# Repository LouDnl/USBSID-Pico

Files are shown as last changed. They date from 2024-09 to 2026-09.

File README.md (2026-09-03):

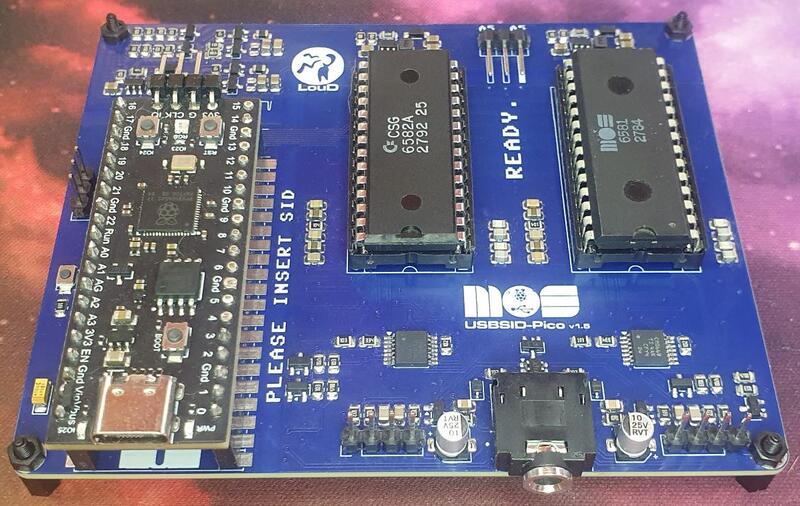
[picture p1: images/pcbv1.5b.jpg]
<br>
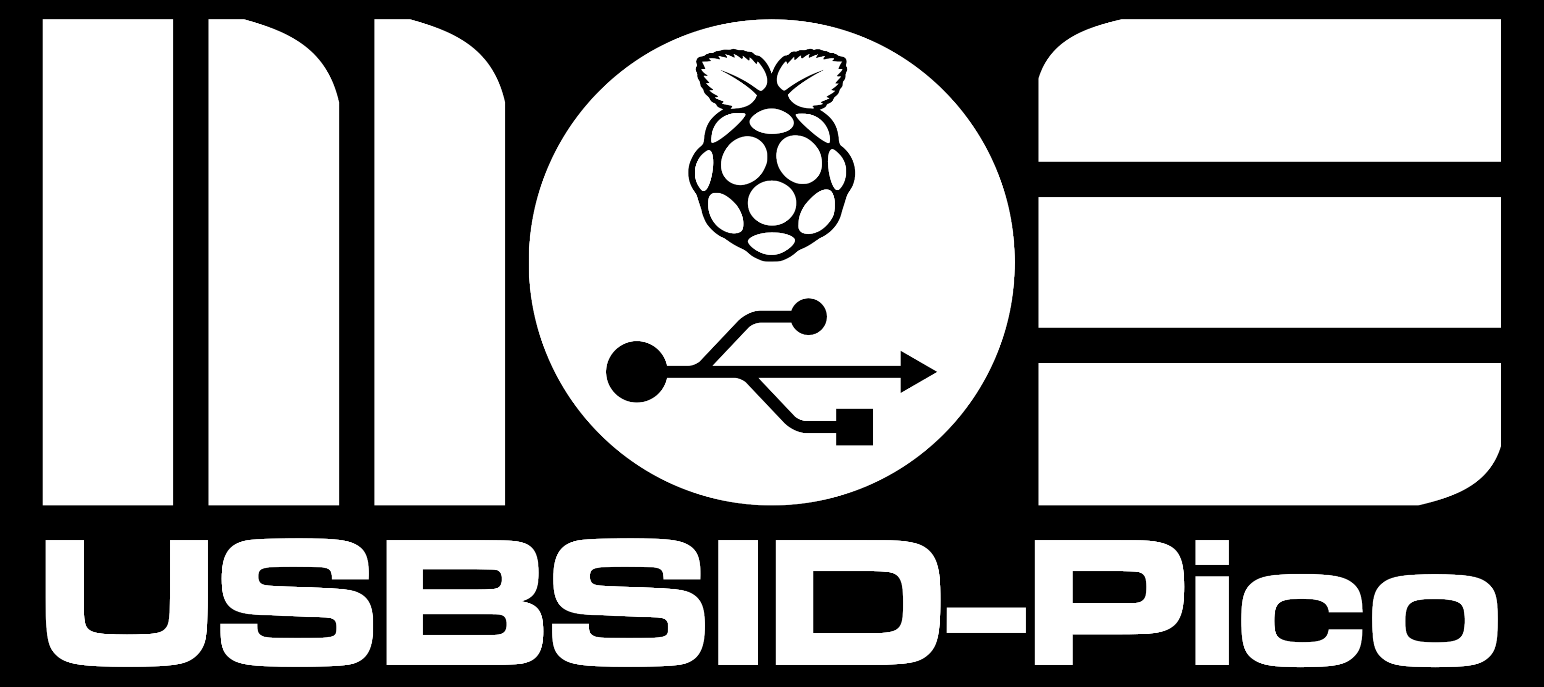
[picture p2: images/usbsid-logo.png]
# [](images/usbsid-logo.png)LouD
USBSID-Pico is a RaspberryPi Pico/PicoW (RP2040) & Pico2/Pico2W (RP2350) based board for interfacing one or two MOS SID chips and/or hardware SID emulators over (WEB)USB with your computer, phone, ASID supporting player or USB midi controller.  

# This is USBSID-Pico! :)
| **“Raster Bar” (8-bit)** | **Van Halen's Jump<br>dual SID in Stereo!** | **Next Level** | **Outerversal<br>dual SID in Stereo!** |
|:-:|:-:|:-:|:-:|
| [](https://www.youtube.com/watch?v=nh0SxO1y6I0)<br><small><sub>by LukHash</sub></small> | [](https://www.youtube.com/watch?v=lzvkWlDq2TM)<br><small><sub>by Nordischsound</sub></small> | [](https://www.youtube.com/watch?v=ER8v2g7TlwA)<br><small><sub>by Performers</sub> | [](https://www.youtube.com/watch?v=h2ThT3TWZEw)<br><small><sub>by Abyxus</sub></small> |

| **Wonderland XI** | **Wonderland XII** | **Wonderland XIII** | **Wonderland XIV** |
|:-:|:-:|:-:|:-:|
| [](https://www.youtube.com/watch?v=7hiAkLAqsiI)<br><small><sub>by Censor Design</sub></small> | [](https://www.youtube.com/watch?v=4gckiwzOW9U)<br><small><sub>by Censor Design</sub></small> | [](https://www.youtube.com/watch?v=q4Fg7V2DYCI)<br><small><sub>by Censor Design</sub> | [](https://www.youtube.com/watch?v=RTtmsbH4jC0)<br><small><sub>by Censor Design</sub></small> |

# USBSID-Pro (Soon™)
In development is a modular USBSID-Pro featuring 4 SID sockets with 4 mono out ports, switchable audio channels into a single stereo out jack , Midi port, an onboard rp2350b and more. No release date has been planned yet!

# Index
* [This is USBSID-Pico! :)](#this-is-usbsid-pico-)
* [Swag!](#swag)
* [Software support & Features](#software-support-and-features)
  * [USBSID-Configtool](#usbsid-configtool)
  * [Software manual](doc/USBSID-Pico-software-manual.adoc) [PDF](doc/USBSID-Pico-software-manual.pdf)
  * [SID files](#sid-files)
    - [Webbased SID players](#webbased-sid-players)
    - [SID players](#sid-players)
    - [Amiga SID players](#amiga-sid-players)
  * [Commodore 64 emulators](#commodore-64-emulators)
  * [Chiptune trackers using SID's](#chiptune-trackers-using-sids)
  * [Driver code](#driver-code)
  * [Midi](#midi)
  * [Cynthcart VST](#cynthcart-vst)
* [Questions & Support](#questions-and-support)
* [Known issues](#known-issues)
* [Project status](#project-status)
  * [Code status](#code-status)
  * [Supported platforms](#supported-platforms)
  * [Linux Udev rules](#linux-udev-rules)
  * [Windows driver](#windows-driver)
* [Firmware](#firmware)
  * [Configuring your board's firmware](#configuring-your-boards-firmware)
    * [Testing your board](#testing-your-board)
  * [Firmware features](#firmware-features)
    * [Embedded Cynthcart](doc/USBSID-Pico-Cynthcart-manual.adoc) [(PDF)](doc/USBSID-Pico-Cynthcart-manual.pdf)
    * [Embedded USBSID-Player](doc/USBSID-Player-manual.adoc) [(PDF)](doc/USBSID-Player-manual.pdf)
  * [Firmware types and naming](doc/USBSID-Pico-firmware-manual.adoc) [(PDF)](doc/USBSID-Pico-firmware-manual.pdf)
  * [How to flash new firmware](doc/USBSID-Pico-firmware-manual.adoc) [(PDF)](doc/USBSID-Pico-firmware-manual.pdf)
  * [How to configure your board](doc/USBSID-Pico-firmware-manual.adoc) [(PDF)](doc/USBSID-Pico-firmware-manual.pdf)
  * [Building](#building)
* [Hardware](#hardware)
  * [Volume board](#volume-board)
  * [Where to buy](#where-to-buy)
  * [PCB usage information](#pcb-usage-information)
    * [PCB revision v1.0 manual](#pcb-revision-v10-manual)
    * [PCB revision v1.3 manual](#pcb-revision-v13-manual)
  * [Cases](#cases)
  * [PCB Features](#pcb-features)
  * [Open source design files, schematic and BOM](#open-source-design-files-schematic-and-bom)
  * [PCB Development](#pcb-development)
* [Examples](#examples)
* [Acknowledgements](#acknowledgements)
* [Disclaimer](#disclaimer)
* [License](#license)
* [Certification](#certification)

# Swag!
Do you like swag!? I sure do!! [greyandslate](https://bsky.app/profile/greyandslate.bsky.social) created these great t-shirt designs which are available for purchase in his [Smallrun shop](https://smallrun.net/shop/grey-and-slate-haberdashers), link below.  
**Use coupon code USBSID15 for a 15% discount!**  
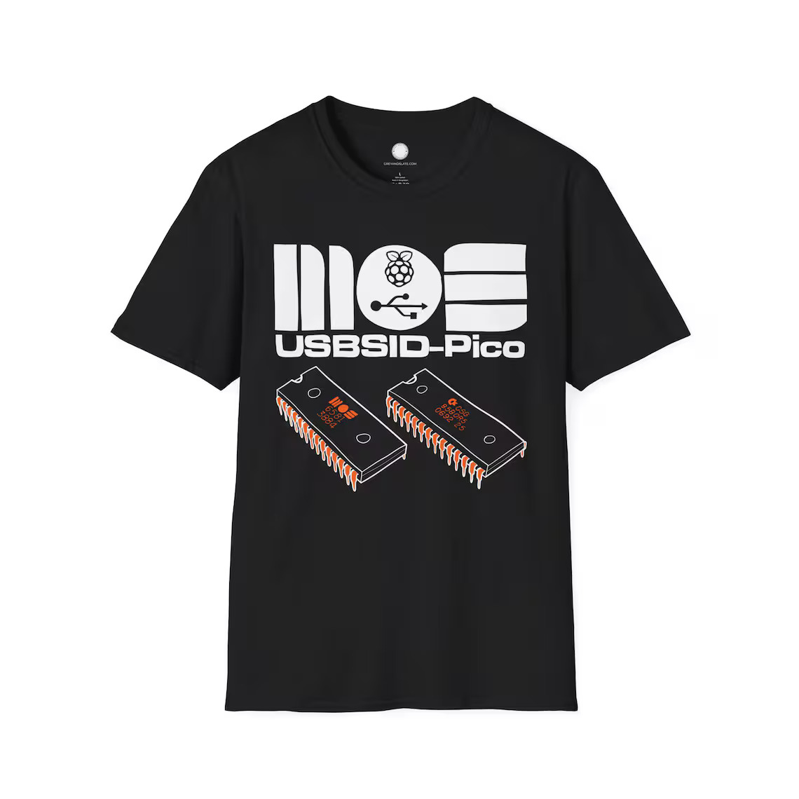
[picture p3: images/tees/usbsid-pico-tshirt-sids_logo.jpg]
  
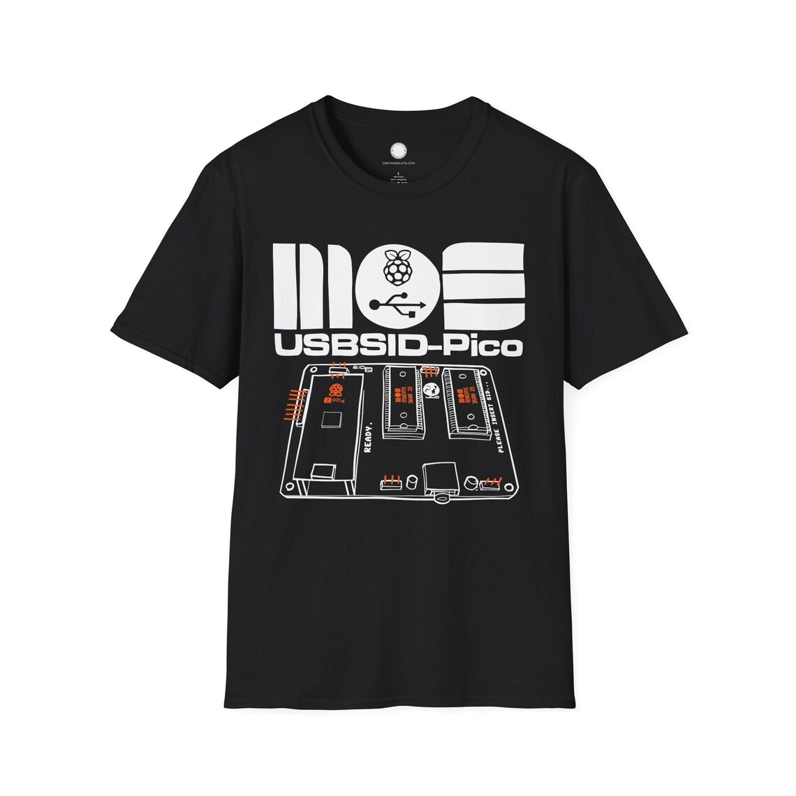
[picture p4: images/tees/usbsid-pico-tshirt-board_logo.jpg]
  
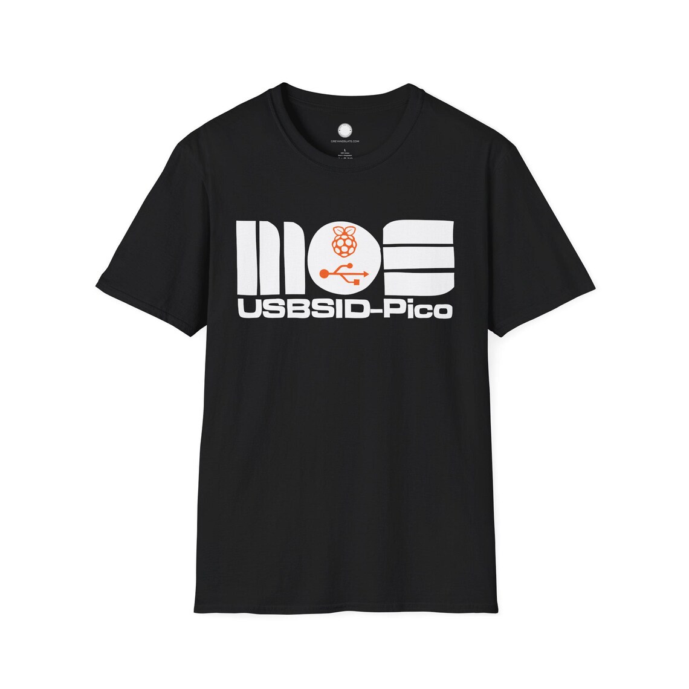
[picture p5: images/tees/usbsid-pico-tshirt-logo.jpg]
  
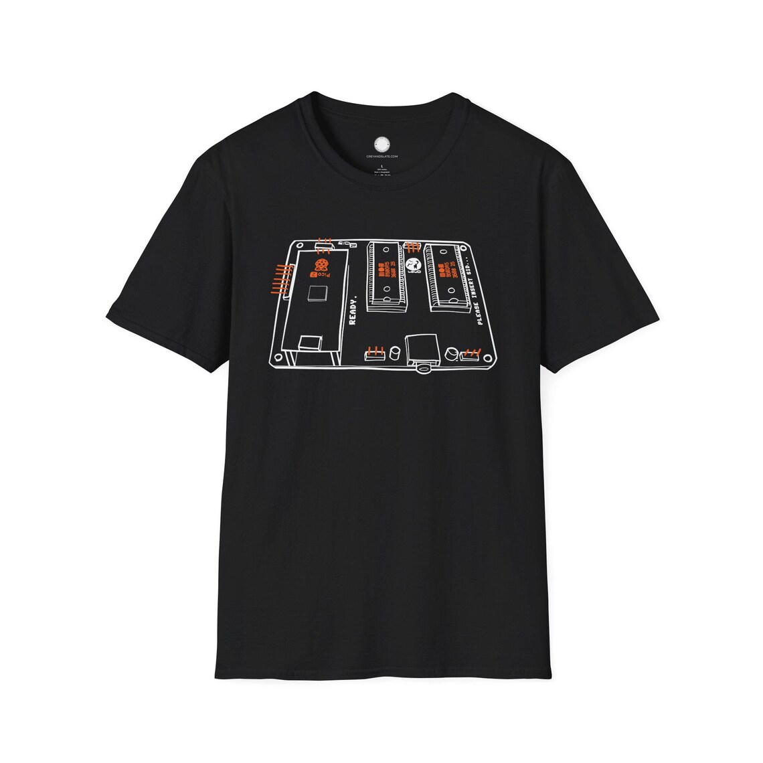
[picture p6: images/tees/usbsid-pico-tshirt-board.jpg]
  

# Software support and features
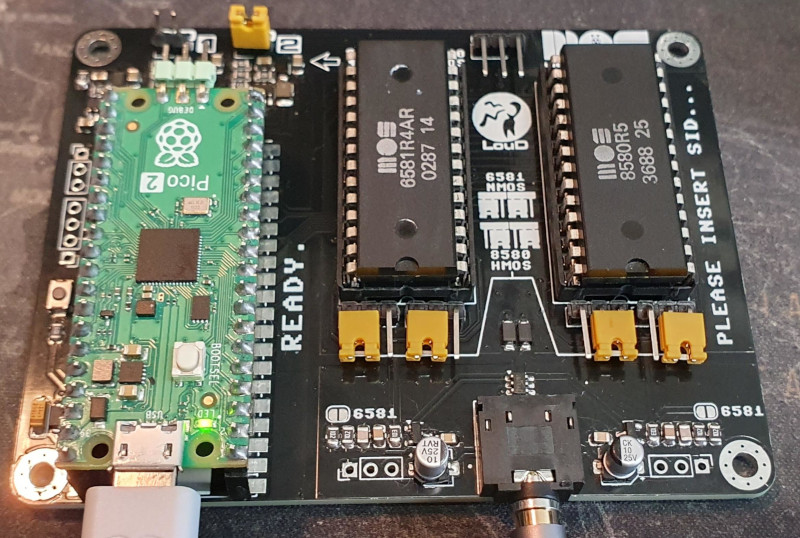
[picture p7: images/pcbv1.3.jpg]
  
See the [Software manual](doc/USBSID-Pico-software-manual.adoc) for more information on how to use supported software!  

## USBSID-Configtool
The [USBSID-Configtool](https://github.com/LouDnl/USBSID-Configtool) is a _must have_ tool to configure your board!  
Checkout the [Configtool manual](doc/USBSID-Configtool-manual.adoc) or [PDF](doc/USBSID-Configtool-manual.pdf)  
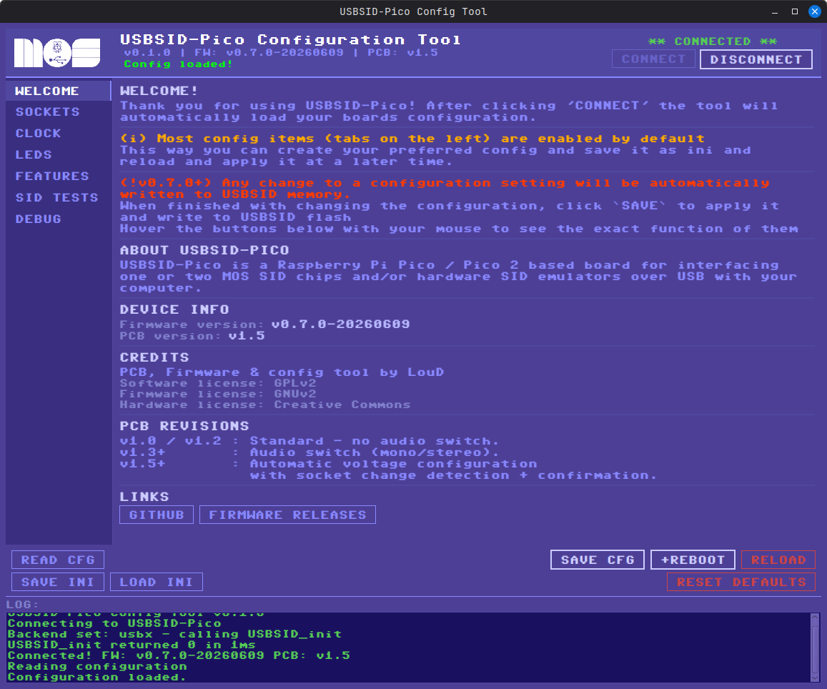
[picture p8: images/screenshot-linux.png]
[](https://github.com/LouDnl/USBSID-Configtool)  

## SID files
USBSID-Pico supports various ways of playing SID files.

#### Webbased SID players 
_Chrome webbrowser only_  
- Out-of-the box playing is supported by using [Deepsid by Chordian](https://deepsid.chordian.net)  
  by selecting `WebUSB (Hermit)` as player in the pulldown menu or  
  by selecting `ASID (MIDI)` as player in the pulldown menu.
- Out-of-the box playing is also supported by using [C64jukebox by Kenchis](https://haendel.ddns.net:8443/static/c64jukebox.vue), note that this is still in BETA.  

#### SID players
| Acid64 Pro | VSID(Vice) | (lib)sidplayfp | Phosphor |  
|:-:|:-:|:-:|:-:|
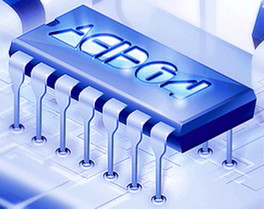
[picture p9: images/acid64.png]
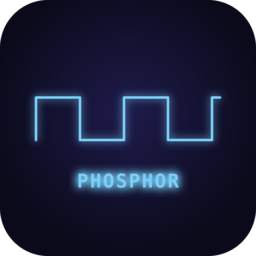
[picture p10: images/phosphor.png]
| [](https://acid64.com/) | [](https://sourceforge.net/projects/vice-emu/) | [](https://github.com/libsidplayfp/) | [](https://github.com/sandlbn/Phosphor) |  
| version [4.4.0](https://acid64.com/download)<br>(Windows only) | version [3.10.0](https://github.com/VICE-Team/svn-mirror/releases/tag/3.10.0) | player [2.16](https://github.com/libsidplayfp/libsidplayfp/releases/tag/v2.16.0rc)<br>lib [2.16](https://github.com/libsidplayfp/sidplayfp/releases/tag/v2.16.0rc) | [any version](https://github.com/sandlbn/Phosphor/releases) |  
| up to 3 SIDs | up to 3 SIDs | up to 3 SIDs | up to 4 SIDs |  

Other:
- [SidBerry](https://github.com/LouDnl/SidBerry) is a command line SID file player for Linux & Windows with up to 4 SIDs supported (Windows version is buggy).
- [TrueSID](https://csdb.dk/release/?id=259243) TrueSID is a Python based graphical SID player which utilizes JSIDPlay2 and / or SidplayFp to play SID tunes  

#### Amiga SID players
Real SID's on the Amiga? Why yes!
- [erique](https://github.com/erique) and [koobo](https://github.com/koobo) have added support to [playsid](https://github.com/erique/playsid.library)  

## Commodore 64 emulators
Official support has been added to:  
| Vice | JSIDPlay2 | Denise |
|:-:|:-:|:-:|
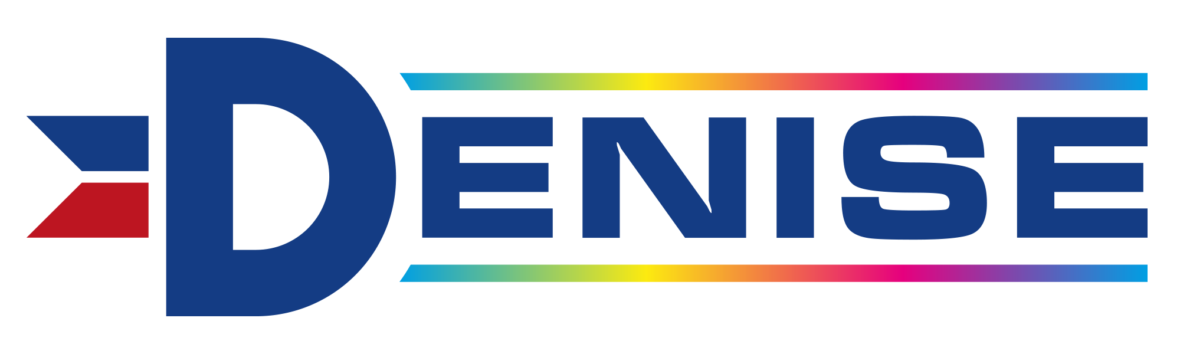
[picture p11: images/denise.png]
| [](https://sourceforge.net/projects/vice-emu/) | [](https://haendel.ddns.net/~ken/#_latest_beta_versions) | [](https://sourceforge.net/projects/deniseemu/) |  
| version [3.10.0](https://github.com/VICE-Team/svn-mirror/releases/tag/3.10.0) | version [4.13](https://sourceforge.net/projects/jsidplay2/files/jsidplay2/4.13/) | version [2.7](https://sourceforge.net/projects/deniseemu/) |  
| up to 4 SIDs in x64sc | up to 4 SIDs | up to 4 SIDs |  

Others:
- Unofficial support is added to a fork of [RetroDebugger](https://github.com/LouDnl/RetroDebugger), up to 4 SIDs are supported.

## Chiptune trackers using SID's
Into creating chiptunes? USBSID-Pico is your board!
- You should be able to use the ASID fork of [sidfactory2](https://github.com/Chordian/sidfactory2/tree/asid-support) without issues.  
- When using Vice or RetroDebugger you can freely use applications like [SID-Wizard](https://sourceforge.net/projects/sid-wizard/) for music creation.  
- There is also work being done in my forks of [GTUltra](https://github.com/LouDnl/GTUltra-USBSID) and [Goattracker2](https://github.com/LouDnl/goattracker2).  
  Ask on Discord for latest binaries :)

## Driver code
Want to create your own implementation? You can by using the driver code examples below
- [USBSID-Pico driver](https://github.com/LouDnl/USBSID-Pico-driver) repo is available @ https://github.com/LouDnl/USBSID-Pico-driver and contains `C++`, `Java` and `Javascript` implementation examples
  - [@sandlbn](https://github.com/sandlbn) has created a driver in `Rust` which is available here [USBSID-Pico-Rust-driver](https://github.com/sandlbn/USBSID-Pico-Rust-driver)
- [HardSID USB / SidBlaster USB](examples/hardsid-sidblaster) emulation driver example

## Midi
USBSID-Pico acts as Midi device and supports basic Midi in ~ note that Midi is still in development and in Beta phase.  
This means that no support is available here at this time, please visit the Discord for more information.

## Cynthcart VST
Raros has made a custom VST (Windows only) to use with the Cynthcart embedded firmware version.  
Checkout the [README.md](examples/Cynthcart-Ninja_VST/README.md) he made for more information!

# Questions and Support
Any questions about or support with USBSID-Pico can be asked 
* [Discord](https://discord.gg/zG2rxXuT2g)
* [Github discussions](https://github.com/LouDnl/USBSID-Pico/discussions)
* [USBSID manuals](doc/)

# Known issues
**PCB/Audio/etc**
* Possible audible low/high alternating hum when using a Pico1 or Pico2 board that has an RGB LED onboard.  
  - __Cause:__ Ground loop, when two or more interconnected pieces of audio equipment are plugged into different power outlets (with or without ground pins), creating multiple paths to the electrical ground.  
  - __Example:__ When powering the board from your computer and routing the audio out back into your computer.  
  - __Example:__ When powering the board from your computer and routing the audio out into speakers but both connected to different outlets.  
  - __Fix:__ Route the audio out through a ground loop isolator.  
  - __Fix:__ Connect audio out to headphones.  
  - __Note:__ Its more present on v1.0 and v1.3 board, but still there on v1.5 boards. To fix this on the board would require significant layout and pcb changes.  

**Firmware/Software**
* Switching on readmode and then switching it off again without restarting the PCB and Vice _will_ result in distorted audio  
* Highly demanding, cycle-exact SID tunes (dense per-cycle register writes, e.g. some digi/sample tunes) may not play at full speed on Pico1 or Pico1_w (RP2040) boards, due to the board's hardware limitations. Pico2 or Pico2_w (RP2350) is recommended for these tunes.  

# Project status
Visit the [Project Page](https://github.com/users/LouDnl/projects/1) for an up-to-date list of things being worked on.
While in development any mentioned features, options, etc. are subject to change.  

### Code status
| | Master | Dev |
| ---  | :----- | :----- |
| Release  | [][A] | [][B] |
| Build | [][C] | [][C] |
| Commit | [][D]  | [][E] |
| | **Other** |
| Latest | [][F] | [][G] |
| Open | [][H]  | [][I] |
| Info | [][J] | [][K] |

[1]: https://img.shields.io/github/v/release/LouDnl/USBSID-Pico
[2]: https://img.shields.io/github/v/tag/LouDnl/USBSID-Pico
[3]: https://img.shields.io/github/actions/workflow/status/LouDnl/USBSID-Pico/build.yml?branch=master
[4]: https://img.shields.io/github/actions/workflow/status/LouDnl/USBSID-Pico/build.yml?branch=dev
[5]: https://shields.io/github/last-commit/LouDnl/USBSID-Pico/master
[6]: https://shields.io/github/last-commit/LouDnl/USBSID-Pico/dev
[7]: https://shields.io/github/v/tag/LouDnl/USBSID-Pico?sort=semver
[8]: https://shields.io/github/v/release/LouDnl/USBSID-Pico
[9]: https://shields.io/github/issues/LouDnl/USBSID-Pico
[10]: https://shields.io/github/discussions/LouDnl/USBSID-Pico
[11]: https://shields.io/github/license/LouDnl/USBSID-Pico
[12]: https://shields.io/github/languages/top/LouDnl/USBSID-Pico
[A]: https://github.com/LouDnl/USBSID-Pico/actions/workflows/release.yml
[B]: https://github.com/LouDnl/USBSID-Pico/actions/workflows/tagged_build.yml
[C]: https://github.com/LouDnl/USBSID-Pico/actions/workflows/build.yml
[D]: https://github.com/LouDnl/USBSID-Pico/commits/master/
[E]: https://github.com/LouDnl/USBSID-Pico/commits/dev/
[F]: https://github.com/LouDnl/USBSID-Pico/tags
[G]: https://github.com/LouDnl/USBSID-Pico/releases
[H]: https://github.com/LouDnl/USBSID-Pico/issues
[I]: https://github.com/LouDnl/USBSID-Pico/discussions
[J]: https://github.com/LouDnl/USBSID-Pico/blob/master/LICENSE
[K]: https://github.com/LouDnl/USBSID-Pico

### Supported platforms
See the [Software manual](doc/USBSID-Pico-software-manual.adoc) for driver installation and supported software information!  
_In development_  
Linux: Vice, JSidplay2, Denise, SidplayFp, RetroDebugger, SidBerry, USB Midi, WebUSB & ASID (in webbrowser) SID Play  
Windows: Vice, JSidplay2, Denise, SidBerry, USB Midi, WebUSB & ASID (in webbrowser) SID Play  
Android: USB Midi, WebUSB & ASID (in webbrowser) SID Play
Amiga: PlaySID library

#### Linux Udev rules
See the [Software manual](doc/USBSID-Pico-software-manual.adoc) for udev rule installation information!  
An example rule file can be found [here](examples/udev-rules/69-usbsid-permissions.rules).

#### Windows driver
See the [Software manual](doc/USBSID-Pico-software-manual.adoc) for driver installation information!

# Firmware
See the [releases page](https://github.com/LouDnl/USBSID-Pico/releases) for more information on what's changed and previous releases.  

**WARNING!** Whenever the embedded USBSID-Player or Cynthcart is used, the Pico MCU is overclocked to 250MHz, regardless of Pico type (rp2040 or rp2350). Passive cooling _might/could_ be needed.  

### Configuring your board's firmware
Use the new official [USBSID-Configtool](https://github.com/LouDnl/USBSID-Configtool) to configure your board.  
Downloads are available in the [releases](https://github.com/LouDnl/USBSID-Configtool/releases) section of the tools githubpage.  
Make sure you read the [Firmware manual](doc/USBSID-Pico-firmware-manual.adoc) for more information on how to set up your board!  

#### Testing your board
You can test your board with WebUSB and ASID here on the same site as the web configuration tool here: [USBSID web configuration tool](https://usbsid.loudai.nl/?player=webusb) (requires a Chrome based browser).  

### Firmware features
The firmware is still in development so features might change, be added or removed.
- By default both sockets are enabled and the configuration is set to 2 SID's.
- Custom CDC protocol for playing SID files or usage with emulators
- WebUSB support using the same CDC protocol for WebUSB supporting players
  - Play SID files in your browser via [Deepsid](https://deepsid.chordian.net/) by Chordian
  - Play SID files in your browser via [C64jukebox](https://haendel.ddns.net:8443/static/c64jukebox.vue) by Kenchis
- Midi (in) ASID support (heavily inspired by multiple sources)
  - Play SID files in your (midi supporting) browser via [Deepsid](https://deepsid.chordian.net/) by Chordian
  - Play SID files in your (midi supporting) browser via [IneSID](https://inesid.fazibear.me/) by Fazibear
- Midi device support over USB
  - Use your USBSID-Pico as Synth with your Midi controller
- Cynthcart embedded (special firmwares only)
  - Starting with firmware version v0.6.0-BETA and up some firmwares have Cynthcart as midi input  
    See the [USBSID-Pico Cynthcart manual](doc/USBSID-Pico-Cynthcart-manual.pdf) for more information!
- Embedded USBSID-Player for playing PSID, RSID, PRG or P00 files without a computer operated emulator!
  - Starting with firmware version v0.6.0-BETA and up some firmwares have USBSID-Player embedded  
    See the [USBSID-Player manual](doc/USBSID-Player-manual.pdf) for more information!
- Two SID sockets with up to 4 SID's (e.g. SKPico) supported
  - Socket one address range $00 ~ $7F (default $00 ~ $1F) auto based on configuration settings
  - Socket two address range $00 ~ $7F (default $40 ~ $7F) auto based on configuration settings
  - Configurable via [config-tool](examples/config-tool) for Linux and Windows
- Onboard LED acts as VU meter calculated by the voices of SID1 (Pico & Pico2 only)
- Onboard RGB LED acts as second VU meter calculated by the voices of SID1 (default)
  - Requires Black Pico clone board with RGB LED onboard!
  - SID voices to use for calculation can be changed in config
- Uses the [TinyUSB](https://github.com/hathach/tinyusb) stack
#### v1.3+ PCB
- Audio switch Stereo/Mono control
#### v1.5+ PCB
- Socket voltage control

### Building
You can build the firmware using the Pico SDK 2.1.1 and the included TinyUSB. Be sure to clone the SDK with `--recurse-submodules`.  
After download run `cd pico-sdk/lib/tinyusb` and then `python3 tools/get_deps.py PICO_PLATFORM` where PICO_PLATFORM is either rp2040 or rp2350 depending on the board you are using.

# Hardware

## Where to buy
#### My SmallRun store
You can purchase/pre-order (semi) assembled boards with or without Pico via my [SmallRun store](https://smallrun.net/shop/loud)!  
[](https://smallrun.net/shop/loud)  
<!-- Sponsored by [<img src="images/pcbway.png" width="150em">](images/pcbway.png) -->
#### PCBWay
At a minimum of 5 bare or assembled boards it is also possible to purchase PCB's at PCBWay  
No account yet at [PCBWay](https://pcbway.com/g/2458i7)? Please use [my referral link](https://pcbway.com/g/2458i7) to register, thanks!  
[Volume daughterboard](https://www.pcbway.com/project/shareproject/USBSID_Pico_Volume_daughterboard_5b782004.html)  
[PCB revision v1.5 (soon!)](#)  
[PCB revision v1.3](https://www.pcbway.com/project/shareproject/USBSID_Pico_v1_3_05f2b88e.html)  
[PCB revision v1.0](https://www.pcbway.com/project/shareproject/USBSID_Pico_c99c9748.html)  
#### Known and approved resellers
[Run Stop Re-Store](https://www.runstoprestore.nl) at [Retro8BITshop](https://www.retro8bitshop.com) is the first reseller to sell licensed USBSID-Pico boards.  
PCB revision v1.3 [product page](https://www.retro8bitshop.com/product/usbsid-pico-by-loud/)

## PCB usage information
Your USBSID-Pico PCB has several hardware features like jumpers and pins that require your attention. Click on the viewing method
### PCB revision v1.5 manual
- [Open online PCB v1.5 manual](doc/USBSID-Pico-PCBv1.5-manual.adoc)
- [Download PCB v1.5 PDF manual](doc/USBSID-Pico-PCBv1.5-manual.pdf)
### PCB revision v1.3 manual
- [Open online PCB v1.3 manual](doc/USBSID-Pico-PCBv1.3-manual.adoc)
- [Download PCB v1.3 PDF manual](doc/USBSID-Pico-PCBv1.3-manual.pdf)
### PCB revision v1.0 manual
- [Open online PCB v1.0 manual](doc/USBSID-Pico-PCBv1.0-manual.adoc)
- [Download PCB v1.0 PDF manual](doc/USBSID-Pico-PCBv1.0-manual.pdf)
### Volume board
An optional volume board to control left and right audio independently.  
- Plug and play compatible with v1.5+ boards.  
- Compatibale with v1.3 boards with a small modification to provide voltage.  
Checkout the [manual](doc/USBSID-Volume-daughterboard.adoc) or [PDF](doc/USBSID-Volume-daughterboard.pdf)  
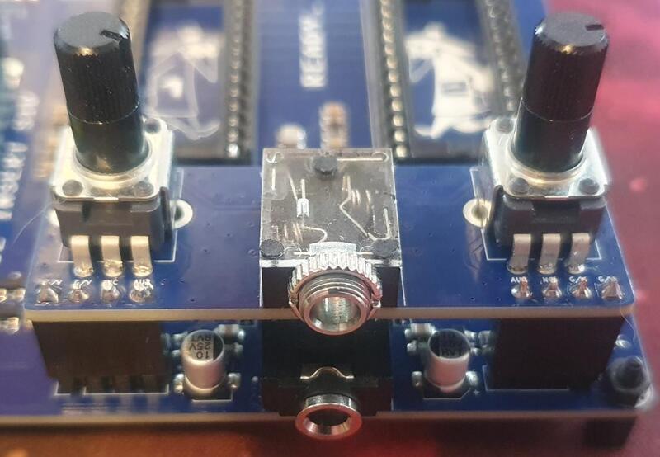
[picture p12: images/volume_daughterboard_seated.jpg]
  
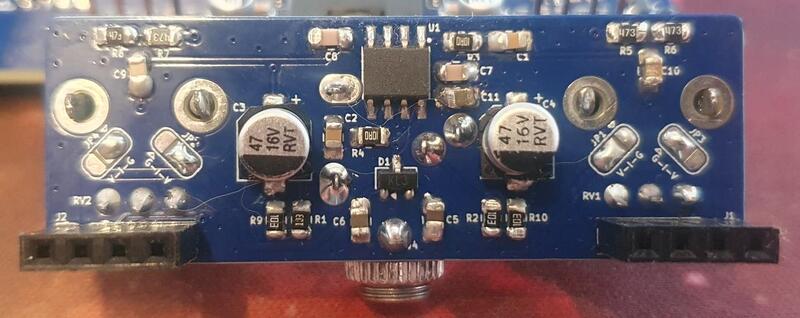
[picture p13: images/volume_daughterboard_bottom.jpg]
  
_Yes! I have cats ;-)_  

## Cases
All USBSID-Pico community created cases are available in the [cases](cases/) directory, direct links below.  
_Cases for PCB revision v1.0:_
* [Cartridge case](cases/v1.0/spotUP) by [@spotUP](https://github.com/spotUP/)
* [boxy case](cases/v1.0/schorsch3000) by [@schorsch3000](https://github.com/schorsch3000/)

_Cases for PCB revision v1.3:_
* [spotUP Cartridge case revisited](cases/v1.3/spotUP-revisited) by [@LouD](https://github.com/LouDnl/)
* [Dual USBSID-Pico Commodore 64 Case](cases/v1.3/Dual_USBSID-Pico_Commodore_64_Case) by [@OlefinMakes](https://github.com/OlefinMakes/)

_Cases for PCB revision v1.5:_  
* [spotUp Cartridge case, LouD v1.5 remix](cases/v1.5/spotUp-LouD_remix) by [@LouD](https://github.com/LouDnl/)

## PCB Features
### volume board
- Control the volume of the left and right audio channel independently
### revision v1.5
- Improved voltage and audio filtering
  - Input voltage filtering with π LC filter
  - ESD protection diode on audio port for (minimal) backwards/reverse voltage protection
  - Extra filter capacitors on SID 5v and hv (9v/12v) voltage input
  - Softpull to gnd when headphone jack is empty (should help against clicks on jack insert)
- Jumperless design
  - Automatic 9v/12v selection based on detected Chip/SID
    - sockets are independently configuratble for 9v or 12
    - 5v and hv (9v/12v) on/off is for both sockets (sorry not enough gpios!)
  - Automatic per socket SID filter capacitor selection based on detected Chip/SID
  - Automatic per socket 6581 shunt resistor on/off based on detected Chip/SID
  - Automatic per socket 8580 digiboost based on detected Chip/SID
- Updated audio expansion pins
  - Plug and play ready for the new "Volume daughterboard"
  - Ext IN always connected 
    - Be carefull when connecting anything to this pin!
  - Now includes SID voltage pin
- Includes all other features from v1.3
### revision v1.3
- Supports all MOS SID chips e.g. MOS6581, MOS6582 & MOS8580
- Supports SID chip replacements e.g. [SIDKick-Pico](https://github.com/frntc/SIDKick-pico), [ARMSID](https://www.nobomi.cz/8bit/armsid/index_en.php) & [FPGASID](https://www.fpgasid.de), [SwinSID](https://github.com/dmantione/swinsid).
- USBSID-Pico will by default generate a 1 MHz square wave using pio
  - other clock speeds are configurable
- IO controlled Stereo/Mono switch, can be set in config or toggled during play with supported players
  - SID1 audio left
  - SID2 audio right
- Powered via USB
  - Three separate voltage regulators for filtered voltages to the SIDS
  - 1x fixed 5 volts and 2x 9 volts or 12 volts
  - 5v stepup for clean 5v VCC to both SID chips
  - Supports mixed voltage! e.g. you can use one MOS6581 (12v) together with one MOS6582 (9v) or MOS8580 (9v)
  - 12v/9v jumper for each SID socket, defautls to 12v ~ inspired by SIDBlaster-Nano design
- Audio out filter as in the C64 schematics
  - With optional 6581 resistor, solder the 6581 jumper pad in each audio circuit for this.
- Optional EXT-IN pulldown resistor as filter bypass to reduce filter noise for Digiplay on 8580 SID's
- SID socket placement is more spread out for:
  - easier filter capacitor access
  - optional ZIF sockets
- Better IO port layout
  - Unused GPIO pins for optional future expansion boards
  - IO5 pins for quad SID configuration
  - Uart pins
  - SID Ext in pins (requires closing the solder jumper on the bottom)
  - Ground pin
- New soldermask art ;)
### revision v1.0
- Supports all MOS SID chips e.g. MOS6581, MOS6582 & MOS8580
- Supports SID chip replacements e.g. [SIDKick-Pico](https://github.com/frntc/SIDKick-pico), [SwinSID](https://github.com/dmantione/swinsid), ARMSID (untested), FPGASID (untested)
- 1 MHz oscillator (external optional, enabled via jumper pad)
  - if no external clock is detected USBSID-Pico will generate a 1 MHz square wave using pio
    - clock speed is configurable
  - if an external clock is detected will read the external clock signal
- Power via USB
  - 5v stepup for clean 5v VCC to both SID chips
  - 12v or 9v stepup for clean VDD to both SID chips
    - 12v/9v jumper, defautls to 12v ~ inspired by [SIDBlaster-Nano](https://codeberg.org/CBMretro/SIDBlaster-USB_Nano) design
- Audio out filter as in the [C64 schematics](https://www.zimmers.net/anonftp/pub/cbm/schematics/computers/c64/250469-rev.A-right.gif)
  - With optional 6581 resistor, solder the 6581 (mislabeled 8580!) jumper pad in each audio circuit for this.
- Audio jumper
  - SID1 audio left & right
  - SID1 audio left & SID2 audio right
- Optional EXT-IN pulldown resistor as filter bypass to reduce filter noise for Digiplay on 8580 SID's

## Open source design files, schematic and BOM
If you want and are up to it you can solder your own PCB or create your own development board using  
the open source KiCad design files and gerbers documents below.
#### revision v1.0
- [USBSID-Pico v1.0 schematic](hardware/v1.0-schematic.pdf)
- [USBSID-Pico v1.0 interactive BOM](https://htmlpreview.github.io/?https://github.com/LouDnl/USBSID-Pico/blob/master/hardware/v1.0-ibom.html)
- [USBSID-Pico v1.0 KiCad project & gerber files](hardware/USBSID-Pico-v1.0/README.md)
#### revision v1.3
- [USBSID-Pico v1.3 schematic](hardware/v1.3-schematic.pdf)
- [USBSID-Pico v1.3 interactive BOM](https://htmlpreview.github.io/?https://github.com/LouDnl/USBSID-Pico/blob/master/hardware/v1.3-ibom.html)
- [USBSID-Pico v1.3 KiCad project & gerber files](hardware/USBSID-Pico-v1.3/README.md) 
#### revision v1.5c
- [USBSID-Pico v1.5 schematic](hardware/v1.5c-schematic.pdf)
- [USBSID-Pico v1.5 interactive BOM](https://htmlpreview.github.io/?https://github.com/LouDnl/USBSID-Pico/blob/master/hardware/v1.5c-ibom.html)
#### volume-daughterboard v1.0
- [USBSID-Volume-daughterboard schematic](hardware/volume-daughterboard-schematic.pdf)
- [USBSID-Volume-daughterboard interactive BOM](https://htmlpreview.github.io/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)
- [USBSID-Volume-daughterboard KiCad project & gerber files](hardware/Volume-daughterboard/README.md) 
#### Datasheets of parts used
[Datasheets](resources/)

## PCB Development
* v1.5c **release** board<br>
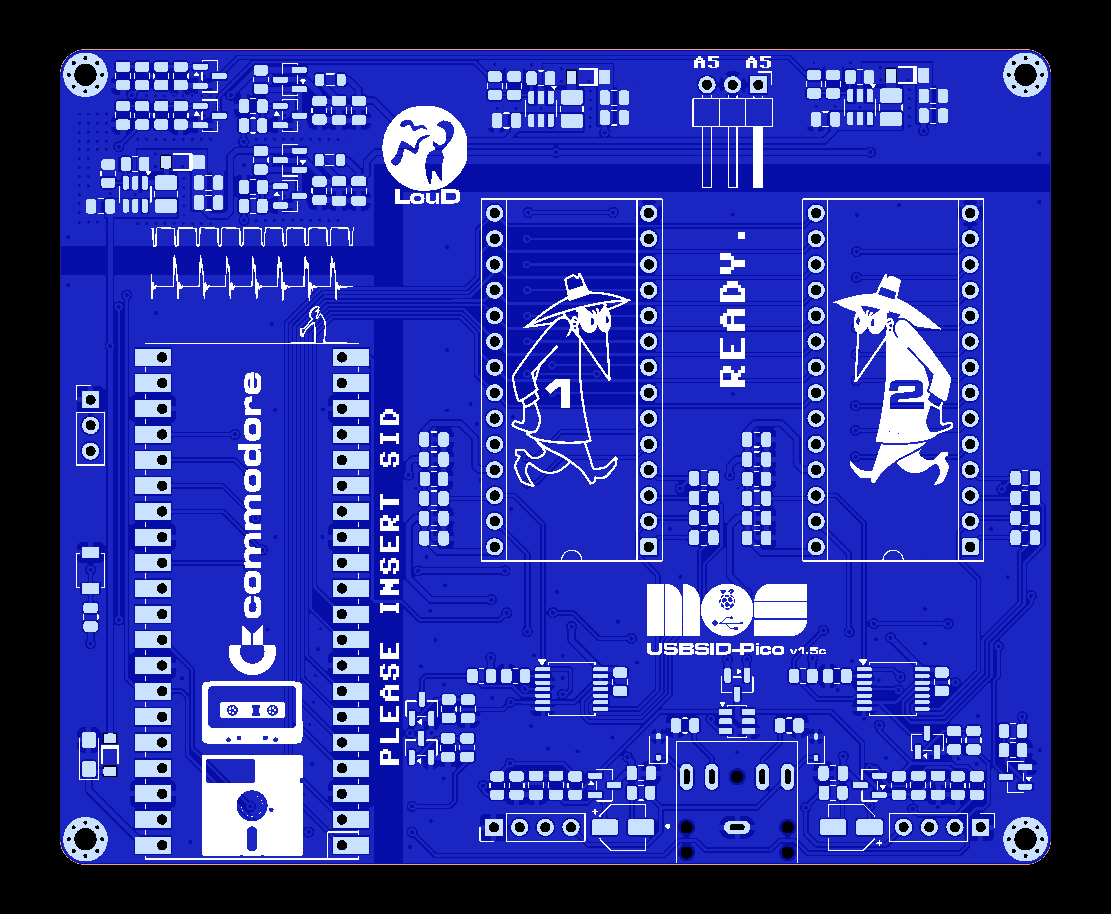
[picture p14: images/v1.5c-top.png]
  [](images/v1.5c-top.png)  
* v1.5b _unreleased_ board<br>
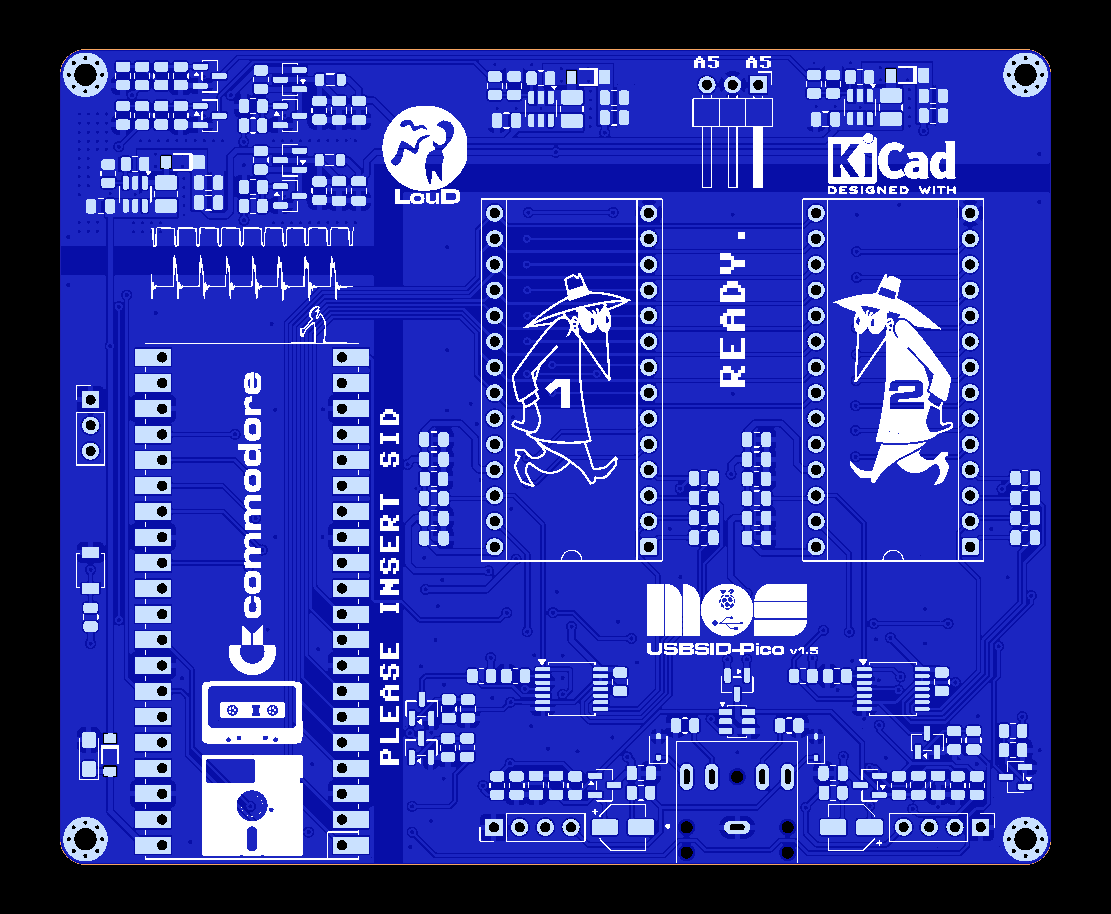
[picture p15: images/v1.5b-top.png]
  [](images/v1.5b-top.png)  
* v1.5 _unreleased_ board<br>
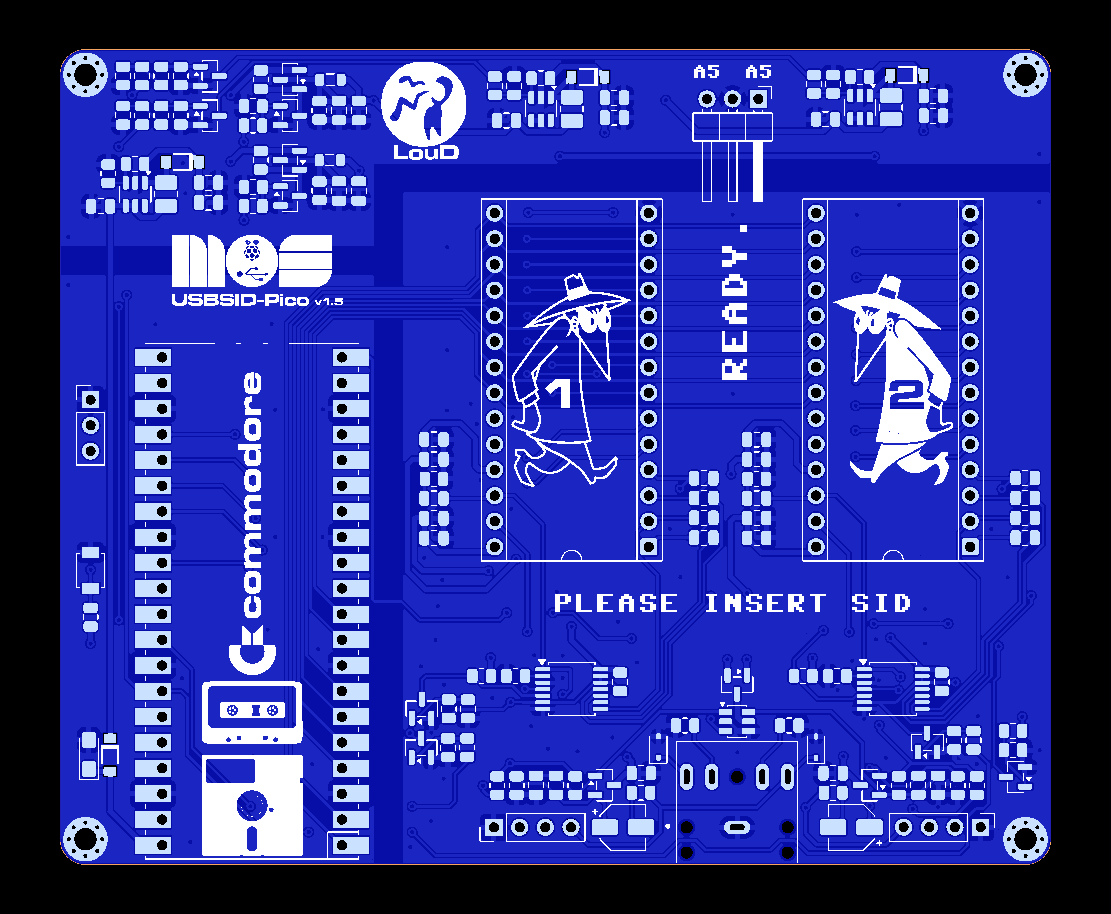
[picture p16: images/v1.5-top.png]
  [](images/v1.5-top.png)  
* v1.4d _unreleased_ board<br>
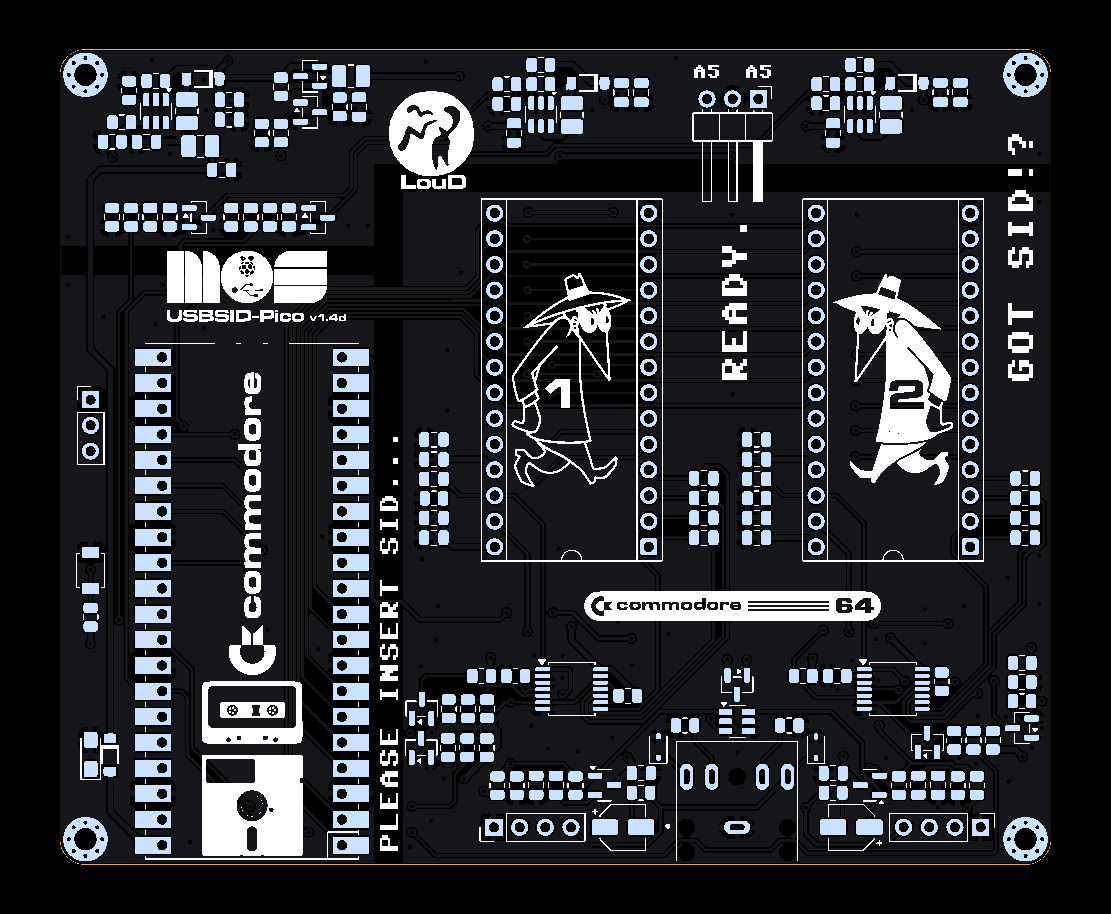
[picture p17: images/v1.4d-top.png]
  [](images/v1.4d-top.png)  
* v1.4 _unreleased_ board<br>
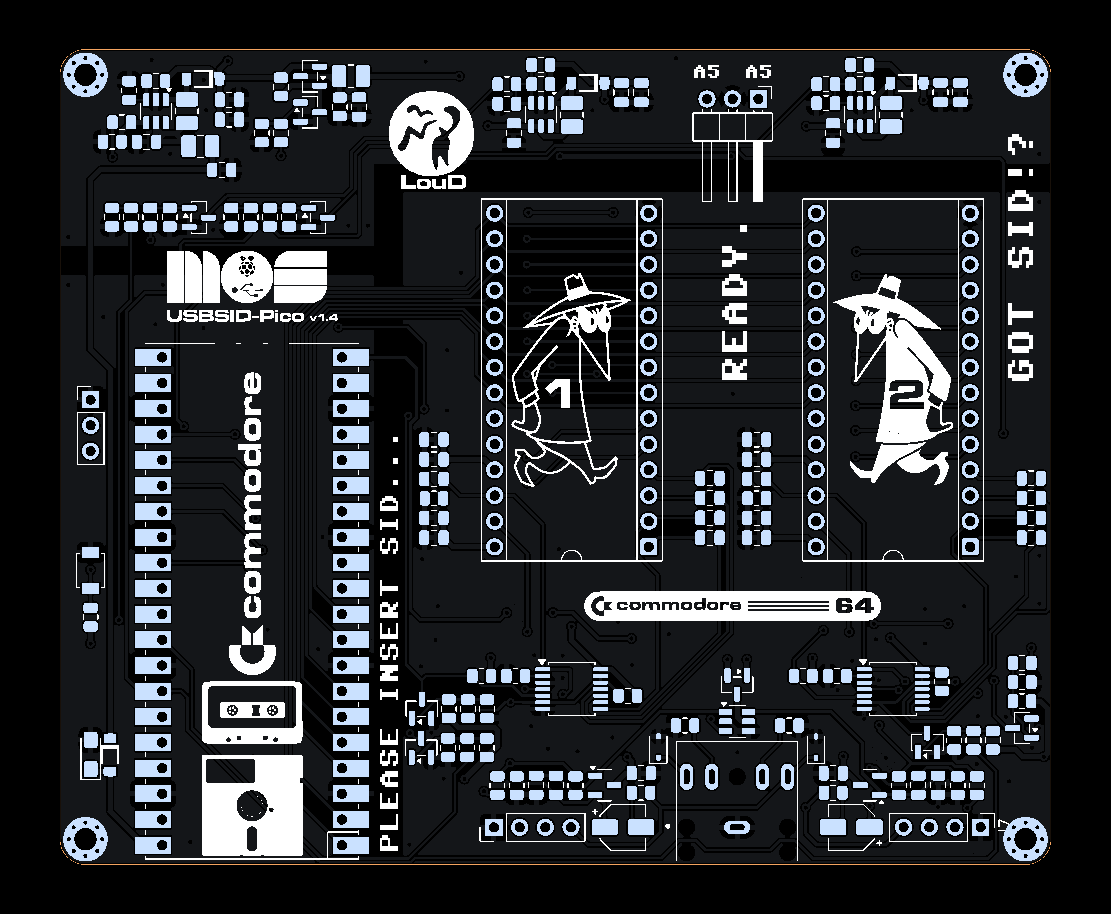
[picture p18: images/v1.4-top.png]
  [](images/v1.4-top.png)  
* v1.3c _unreleased_ board<br>
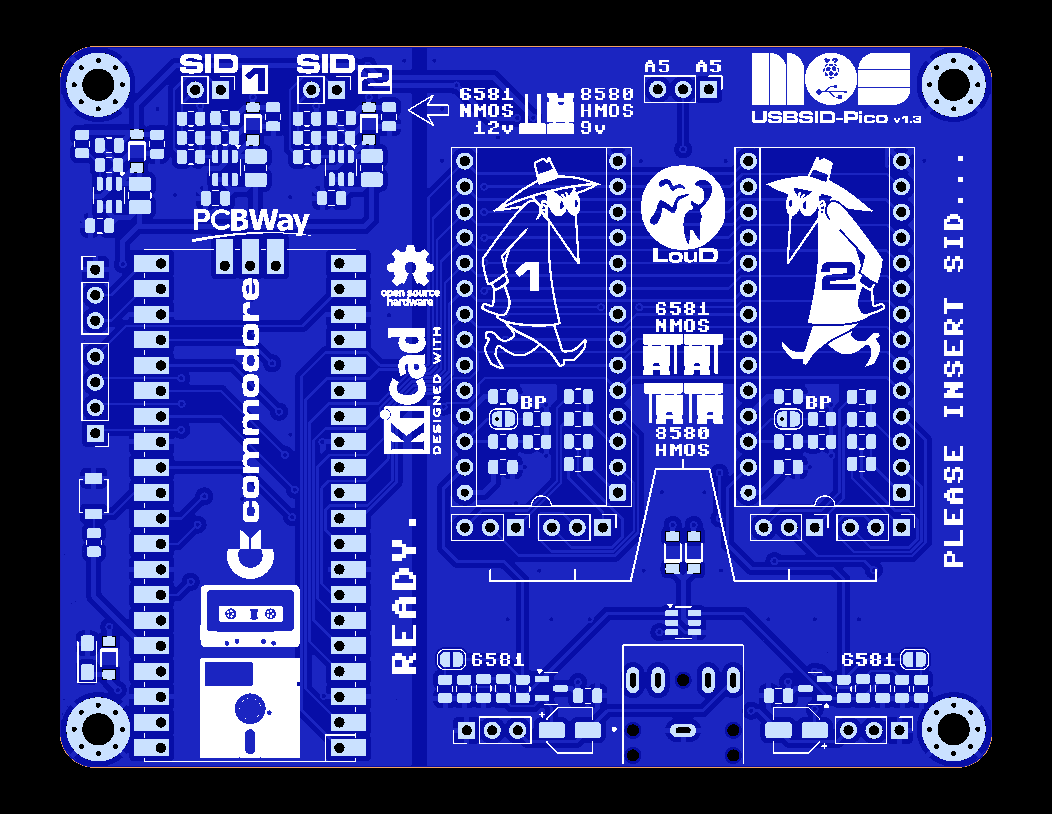
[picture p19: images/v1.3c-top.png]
  [](images/v1.3c-top.png)  
* v1.3b **release** board<br>
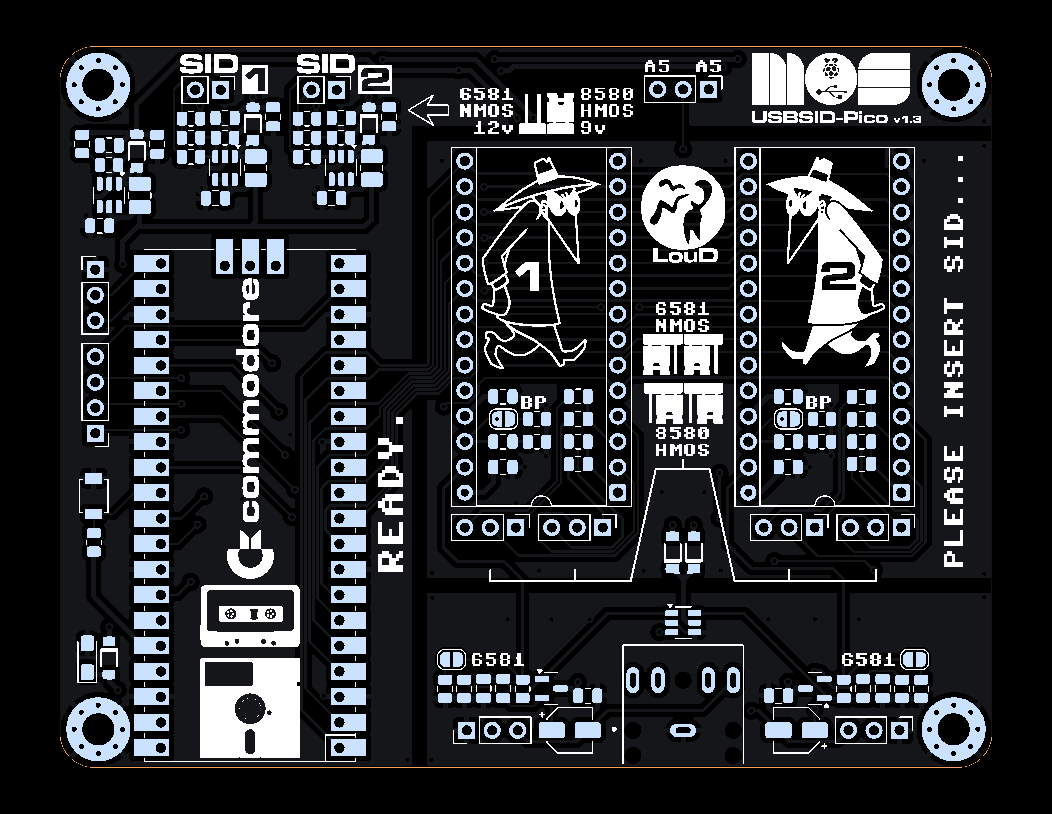
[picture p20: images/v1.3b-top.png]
  [](images/v1.3b-top.png)  
* v1.2 _unreleased_ board<br>
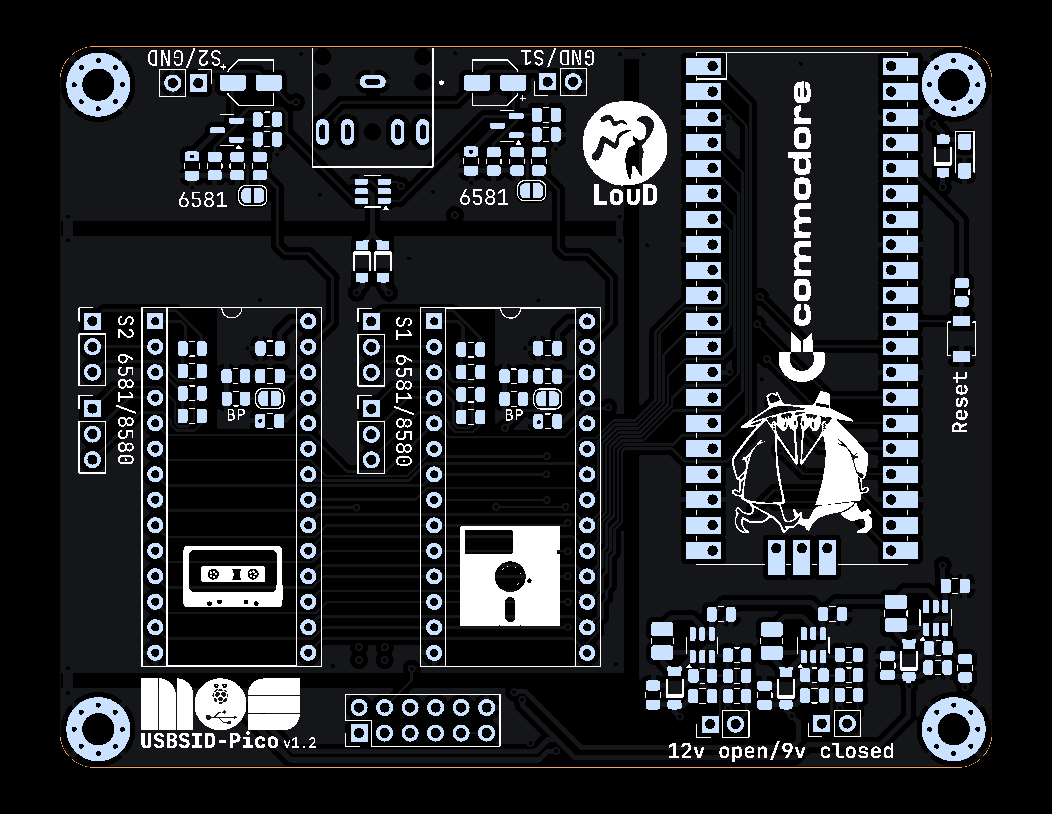
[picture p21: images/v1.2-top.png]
  [](images/v1.2-top.png)  
* v1.1 _unreleased_, unfinished and skipped
* v1.0 **release** board<br>
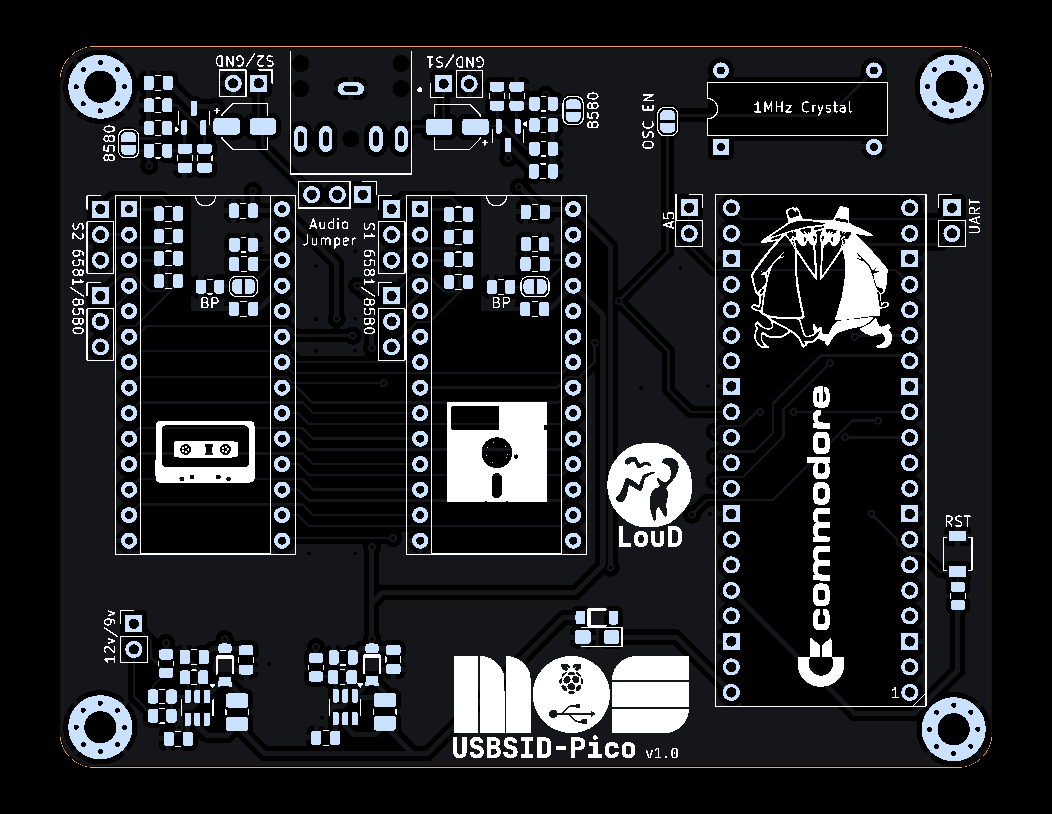
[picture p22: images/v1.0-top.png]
  [](images/v1.0-top.png)  
* v0.2 _unreleased_ testboard<br>
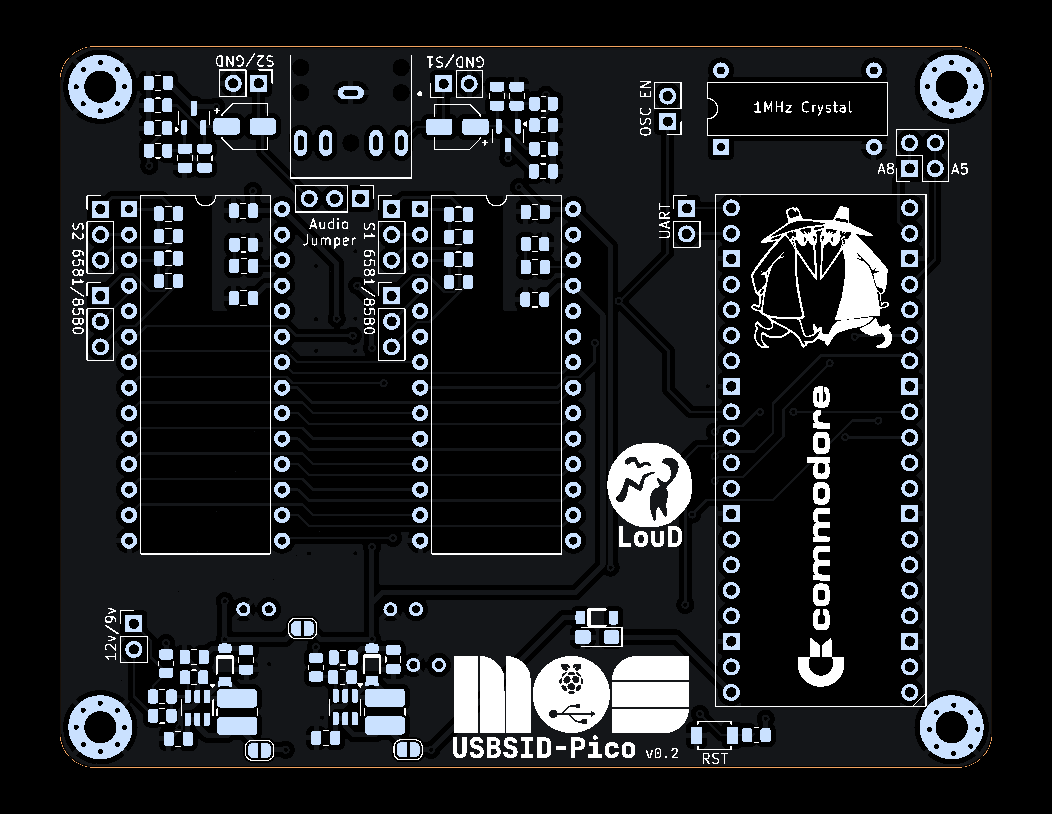
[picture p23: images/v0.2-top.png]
  [](images/v0.2-top.png)  
* v0.1 _unreleased_ testboard<br>
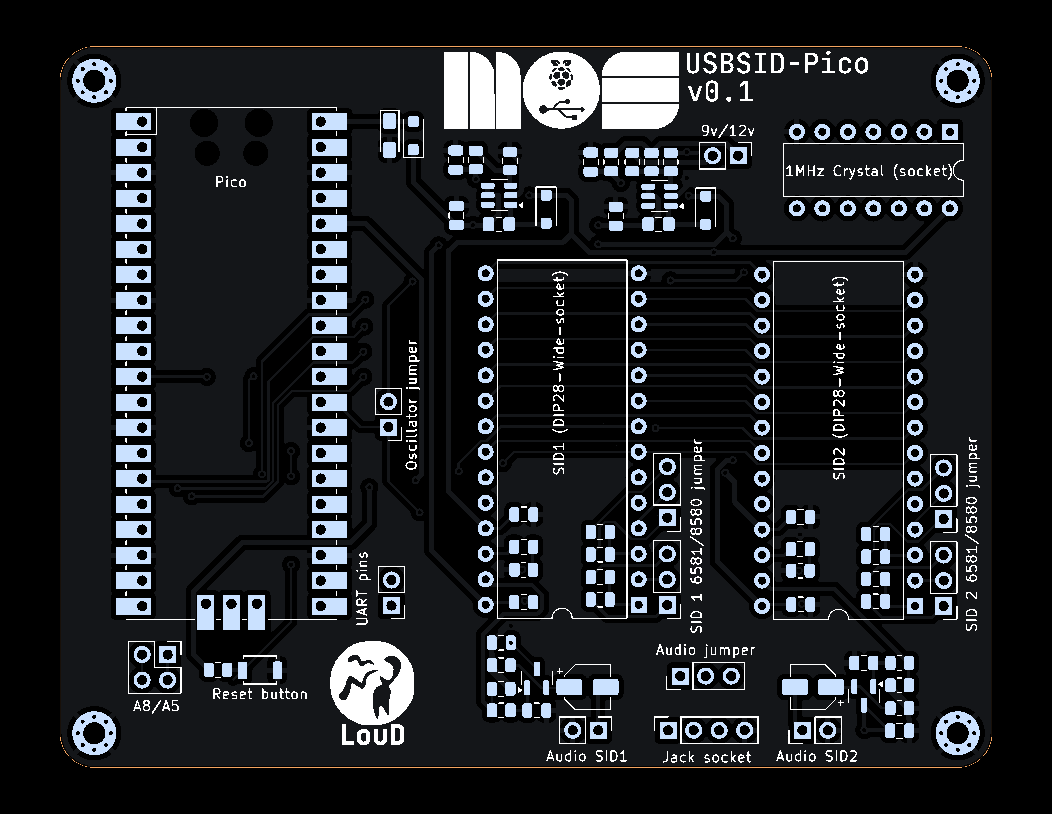
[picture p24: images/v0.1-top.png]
  [](images/v0.1-top.png)  

# Examples
Visit my [Youtube channel](https://www.youtube.com/channel/UCOu1hPBTsEbG7ZFnk9-29KQ), [other socials](https://github.com/LouDnl) or the [SHOWCASE](SHOWCASE.md) page to see more examples of the board in action.

# Acknowledgements
Special thanks goes out to [@tobozo](https://github.com/tobozo/) for making the USBSID-Pico logo and for his (mental🤣) support since starting this project.  
Thanks to [@erique](https://github.com/erique) and [@koobo](https://github.com/koobo) for creating and implementing Amiga support!  
Thanks to [@Chordian](https://github.com/Chordian) for implementing my crappy webusb solution into deepsid.  
Thanks to [@kenchis](https://sourceforge.net/u/kenchis/profile/) for adding webusb support to jsidplay2's c64jukebox.  
Thanks to [PiCiJi](https://bitbucket.org/piciji/workspace/overview) for adding support to Denise.  

Some portions of this code and board are heavily inspired on projects by other great people.
Some of those projects are - in no particular order:
* [SIDKICK-pico by Frenetic](https://github.com/frntc/SIDKick-pico)
* [SIDBlaster USB Nano by CBMretro](https://codeberg.org/CBMretro/SIDBlaster-USB_Nano)
* [TherapSID by Twisted Electrons](https://github.com/twistedelectrons/TherapSID)
* [TeensyROM by Sensorium Embedded](https://github.com/SensoriumEmbedded/TeensyROM)
* [SID Factory II by Chordian](https://github.com/Chordian/sidfactory2)
* [Cynthcart by PaulSlocum](https://github.com/PaulSlocum/cynthcart)

# Disclaimer
I do this stuff in my free time for my enjoyment. Since I like to share my joy in creating this with everyone I try my best to provide a working PCB and Firmware. I am in no way an electronics engineer and can give __no guarantees__ that this stuff does not break or damage your hardware, computer, phone, or whatever you try to hook it up to. Be sure to take great care when inserting any real MOS SID chips into the board. While everything has been tested with real chips, this is in no way a guarantee that nothing could go wrong. Use of this board and firmware at your own risk! I am in no way responsible for your damaged hardware. That being said, have fun!

# License
### Software License ~ GNUv2
All code written by me in this repository is licensed under the terms of the GNU General Public License as published by the Free Software Foundation, version 2.
Any code in this repository that is not written by me automatically falls under the licensing conditions by the authors of said code as mentioned in the source code header.
For for more information about this license please read the LICENSE document in the root of the USBSID-Pico repository.

### USBSID-Pico v1.5 PCB Hardware License ~ CC BY-NC-ND 4.0
USBSID-Pico v1.5 PCB © 2026 by <a href="https://github.com/LouDnl">LouD</a> is licensed under <a href="https://creativecommons.org/licenses/by-nc-nd/4.0/">Creative Commons Attribution-NonCommercial-NoDerivatives 4.0 International</a>

### USBSID-Pico v1.3 PCB Hardware License ~ CC BY-SA 4.0
<a href="https://github.com/LouDnl/USBSID-Pico/tree/master/hardware/USBSID-Pico-v1.3">USBSID-Pico v1.3 PCB</a> © 2025-2026 by <a href="https://github.com/LouDnl">LouD</a> is licensed under <a href="https://creativecommons.org/licenses/by-sa/4.0/">Creative Commons Attribution-ShareAlike 4.0 International</a>  

### USBSID-Pico v1.0 PCB Hardware License ~ CC BY-SA 4.0
<a href="https://github.com/LouDnl/USBSID-Pico/tree/master/hardware/USBSID-Pico-v1.0">USBSID-Pico v1.0 PCB</a> © 2024-2026 by <a href="https://github.com/LouDnl">LouD</a> is licensed under <a href="https://creativecommons.org/licenses/by-sa/4.0/">Creative Commons Attribution-ShareAlike 4.0 International</a>  

### USBSID-Volume-daughterboard PCB Hardware License ~ CC BY-SA 4.0
Volume-daughterboard v1.0 PCB © 2026 by <a href="https://github.com/LouDnl">LouD</a> is licensed under <a href="https://creativecommons.org/licenses/by-sa/4.0/">Creative Commons Attribution-ShareAlike 4.0 International</a>  

# Certification
### USBSID-Pico v1.3 PCB OSHWA certification
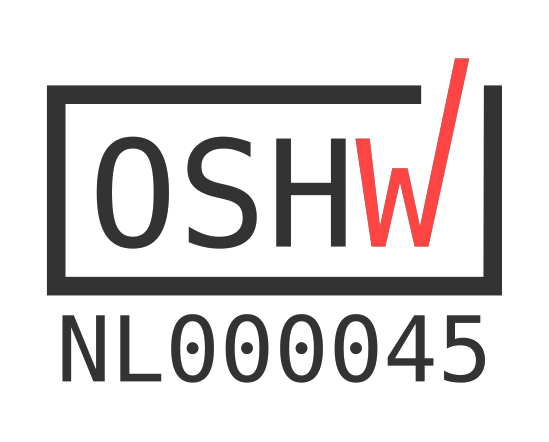
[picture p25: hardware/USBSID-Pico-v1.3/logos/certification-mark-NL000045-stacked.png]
[](https://certification.oshwa.org/nl000045.html)  
[OSHW] NL000045 | Certified open source hardware | [oshwa.org/cert](https://certification.oshwa.org/nl000045.html)

### USBSID-Pico v1.0 PCB OSHWA certification
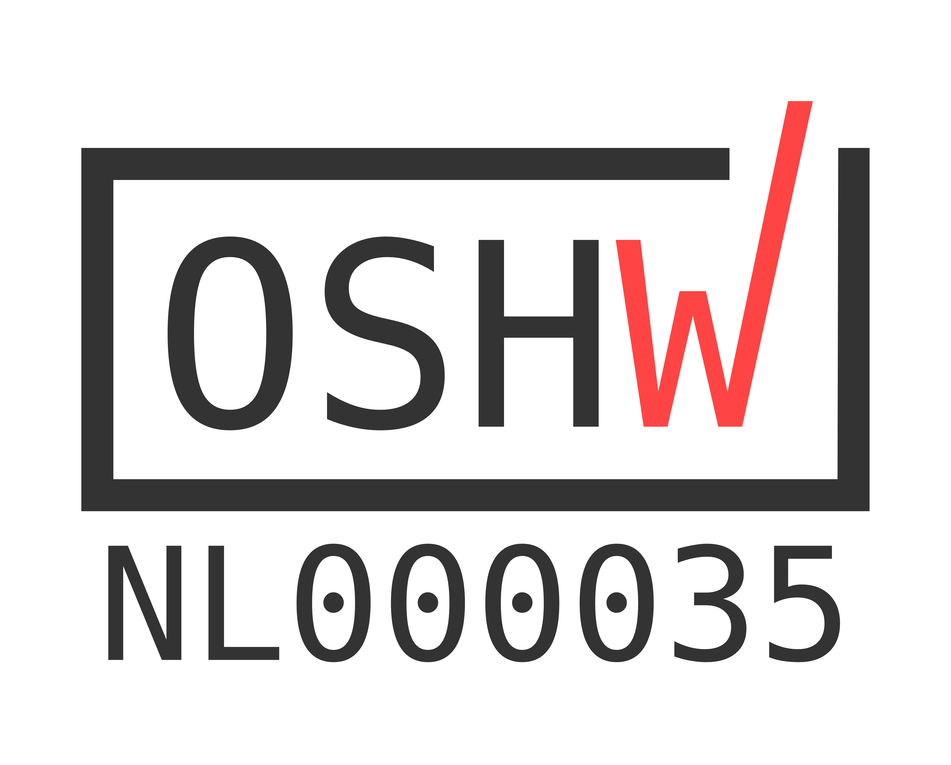
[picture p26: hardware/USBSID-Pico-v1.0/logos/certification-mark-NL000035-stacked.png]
[](https://certification.oshwa.org/nl000035.html)  
[OSHW] NL000035 | Certified open source hardware | [oshwa.org/cert](https://certification.oshwa.org/nl000035.html)

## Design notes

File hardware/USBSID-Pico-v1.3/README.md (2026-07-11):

# USBSID-Pico v1.3 PCB design files
This directory contains the open source KiCad design files for v1.3 of the USBSID-Pico pcb.  

# Gerbers
The gerber files are in the [gerbers](gerbers/) directory.

# OSHWA certification
[](https://certification.oshwa.org/nl000045.html)  
[OSHW] NL000045 | Certified open source hardware | [oshwa.org/cert](https://certification.oshwa.org/nl000045.html)

# Disclaimer
I do this stuff in my free time for my enjoyment. Since I like to share my joy in creating this with everyone I try my best to provide a working PCB and Firmware. I am in no way an electronics engineer and can give __no guarantees__ that this stuff does not break or damage your hardware, computer, phone, or whatever you try to hook it up to. Be sure to take great care when inserting any real MOS SID chips into the board. While everything has been tested with real chips, this is in no way a guarantee that nothing could go wrong. Use of this board and firmware at your own risk! I am in no way responsible for your damaged hardware. That being said, have fun!

# License
### Software License ~ GNUv2
All code written by me in this repository is licensed under the terms of the GNU General Public License as published by the Free Software Foundation, version 2.
Any code in this repository that is not written by me automatically falls under the licensing conditions by the authors of said code as mentioned in the source code header.
For for more information about this license please read the LICENSE document in the root of the USBSID-Pico repository.
### USBSID-Pico v1.3 PCB Hardware License ~ CC BY-SA 4.0
<a href="https://github.com/LouDnl/USBSID-Pico/tree/master/hardware/USBSID-Pico-v1.3">USBSID-Pico v1.3 PCB</a> © 2025-2026 by <a href="https://github.com/LouDnl">LouD</a> is licensed under <a href="https://creativecommons.org/licenses/by-sa/4.0/">Creative Commons Attribution-ShareAlike 4.0 International</a>

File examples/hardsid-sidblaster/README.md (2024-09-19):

# HardSID USB / SidBlaster USB
This folder contains a Linux driver example for software that support HardSID USB / Sidblaster USB.

# Software link
Tested with [JSIDPlay2 v4.2](https://sourceforge.net/projects/jsidplay2/files/jsidplay2/4.2/) by Ken Händel

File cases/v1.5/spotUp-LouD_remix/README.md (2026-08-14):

# Cartridge Case by spotUp, LouD v1.5 remix
- Updated to be v1.5 PCB compatible
- Open top lid  
  The top lid is slightly larger to fit the notches  
  The notch holes in the top lid are also slightly wider
- Wider Pico USB opening to support clone Pico2 RGB capable boards
- Design is opensource  
  Change the case to your liking on [Tinkercad](https://www.tinkercad.com/things/7AoTmtHnQvM-usbsid-pico-v15-case)
- Also included is my PrusaSlicer project file as example

# Examples
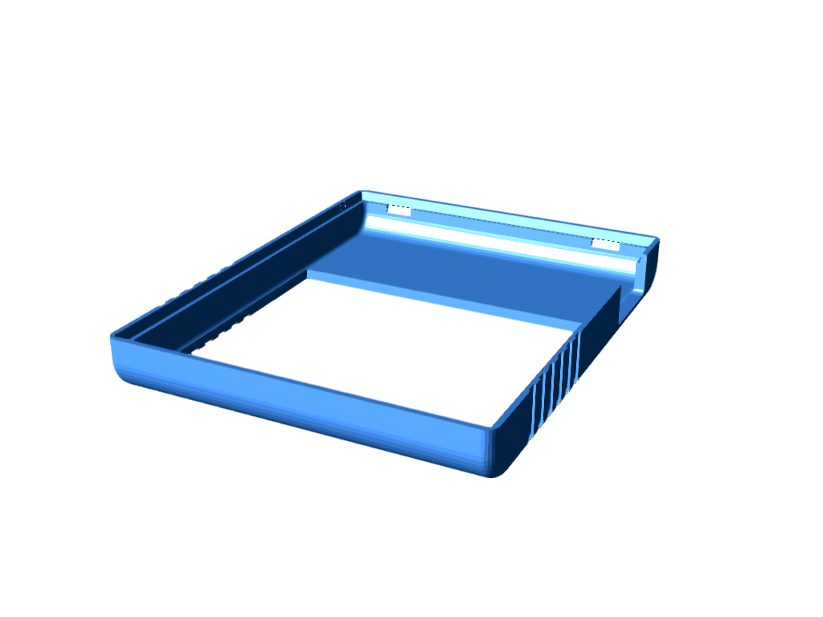
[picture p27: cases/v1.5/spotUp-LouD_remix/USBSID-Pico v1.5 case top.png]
Cartridge Case Open Top
  
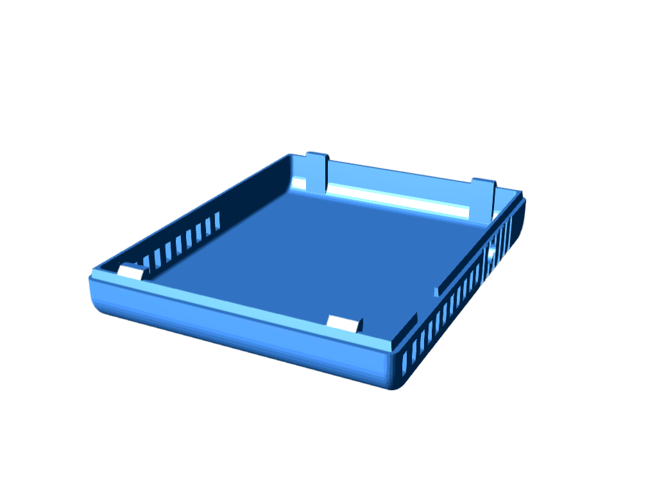
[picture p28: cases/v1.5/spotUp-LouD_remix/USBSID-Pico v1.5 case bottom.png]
bottom case


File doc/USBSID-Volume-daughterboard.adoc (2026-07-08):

= *USBSID-Volume daughterboard*
:author: LouD
:description: This document contains information about the USBSID-Volume daughterboard and how to use it
:url-repo: https://www.github.com/LouDnl/USBSID-Pico
:revdate: {localdate}
:hide-uri-scheme:
:toc:
:toclevels: 4
:toc-placement!:

Author: {author} - generated on {revdate}

toc::[]
[%always]
<<<

== Disclaimer
include::disclaimer.adoc[]

== About
The volume daughterboard is intended as optional addon for USBSID-Pico. +
With This board seated you can independently control the volume of the left and right audio channels. +
The board is Plug and play compatible with v1.5+ boards. +
Compatibility with v1.3 boards is possible with a small modification to provide voltage.

== Usage v1.5
Below is an example of the board seated. +
Follow the instructions under `Solder jumpers` to configure the board for your pcb. +
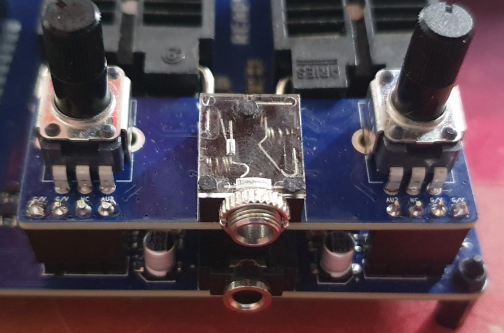
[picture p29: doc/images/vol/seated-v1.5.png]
 +

== Usage v1.3
Take great care when using the board with versions v1.3. +
Below is an example of the board seated and as you can see the right most pins are unconnected. +
Follow the instructions under `Solder jumpers` and `Voltage tap` to configure the board for your pcb. +
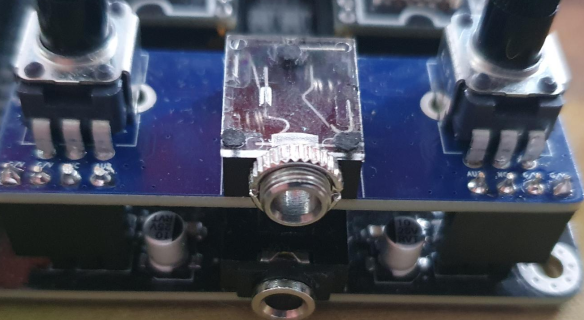
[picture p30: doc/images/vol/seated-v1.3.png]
 +

== Usage v1.0
Same as with v1.3, please take great care when using the board. +
The v1.0 pcb only has 2 pins where the outer pin on each side is Ground. This requires you to make another mod to the board to provide ground to the board. Do this at your own risk, the board is _not_ tested with v1.0 pcb's. +

== Solder jumpers
The board has 4 solder jumpers on the bottom that set the pin functions of 2 two outer most pins for each pinsocket. +
These jumpers are marked with `V-I-G` or `G-I-V`, G for Ground, I for Input and V for Vdd. +
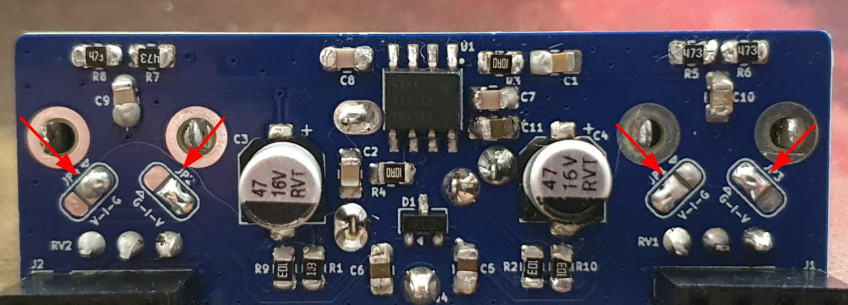
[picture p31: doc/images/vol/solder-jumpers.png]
 +
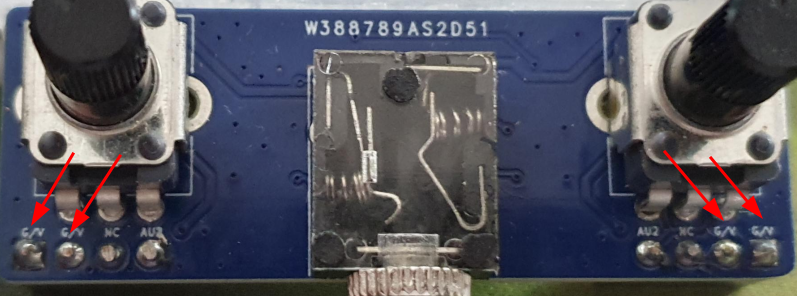
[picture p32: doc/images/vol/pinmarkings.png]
 +
For v1.5 boards you can solder the jumpers exactly as the picture above, from left to right:  +
V-*_I-G_*, G-*_I-V_*, *_V-I_*-G, *_G-I_*-V meaning *_Input+Ground_*, *_Input+VDD_*, *_VDD+Input_*, *_Ground+Input_* +
For v1.3 boards you can solder the jumpers as described below, from left to right:  +
*_V-I_*-G, *_G-I_*-V, V-*_I-G_*, G-*_I-V_* meaning *_VDD+Input_*, *_Ground+Input_*, *_Input+Ground_*, *_Input+VDD_* +

The socket pins _must_ match the order of the markings on the bottom of the USBSID-Pico PCB. +
*v1.5:* +
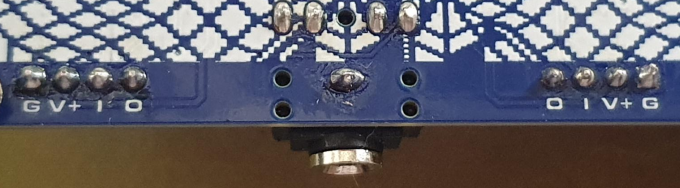
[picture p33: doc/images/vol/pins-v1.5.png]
 +
*v1.3:* +
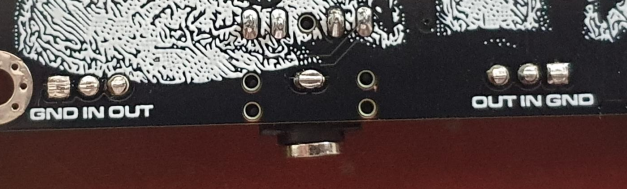
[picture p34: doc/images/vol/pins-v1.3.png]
 +
As you can see the v1.3 boards do not have a voltage pin, this requires you to make a voltage tap wire to any of the fixed points described under `Voltage tap`. +

== Voltage tap
*v1.3* pcbs have multiple points to where you can solder a wire to provide voltage to the volume board. +
These tap points are described below the picture. +
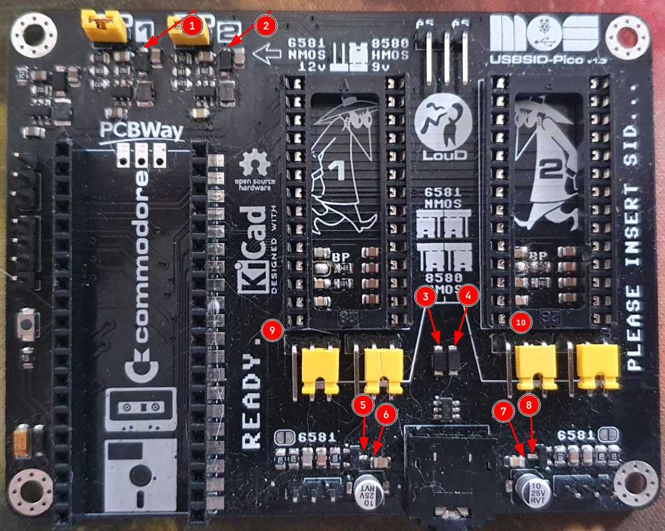
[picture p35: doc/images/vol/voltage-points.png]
 +
*1.* Diode output of SID1 voltage regulator +
*2.* Diode output of SID2 voltage regulator +
*3.* SID1 diode input voltage to audio switch +
*4.* SID2 diode input voltage to audio switch +
*5.* Voltage input to SID1 voltage follower +
*6.* Voltage filter capacitor of SID1 voltage follower +
*7.* Voltage input to SID2 voltage follower +
*8.* Voltage filter capacitor of SID2 voltage follower +
*9.* SID1 VDD in on the bottom of the PCB +
*10.* SID2 VDD in on the bottom of the PCB +

== License
include::license-software.adoc[]

include::license-hardware.adoc[]

Author: {author} - generated on {revdate}

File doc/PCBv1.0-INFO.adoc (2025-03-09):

= *PCB v1.0 Important information*

.Click image for larger view
[#img-v1explained,link=images/v1.0-explained.png]


1. 12 volt or 9 volt selection jumper +
  
  - open = for 6581 SID only!! (12 volts)
  - closed = for 8580 SID (9 volts)
2. Socket 2 6581 / 8580 SID type selection jumpers +
  
  - both closed left = 6581
  - both closed right = 8580
3. Socket 1 6581 / 8580 SID type selection jumpers +
  
  - both closed left = 6581
  - both closed right = 8580
4. Audio channel selection jumper +
  
  - closed on Socket 1 side = left & right channel for socket 1
  - closed on Socket 2 side = left channel for socket 2 & right channel for socket 1
5. Address line A5 for adressess above $1F (SKPico 2nd SID for example) +
  
  - both pins are routed to the same GPIO for using adresses higher then $20
6. Uart debugging output port +
  
  - TX on the right
  - RX on the left
7. Optional 330k pulldown resistor hooked up to EXT-IN for 8580 filter bypass in socket 2 +
    
  - solder closed = enabled
8. Optional 330k pulldown resistor hooked up to EXT-IN for 8580 filter bypass in socket 1 +
  
  - solder pad closed = enabled
9. Optional 1MHz crystal socket (not included in BOM) +
  
  - solder pad closed = enabled (when a crystal is socketed)
  - this disables the internal clock generation on the Pico
10. Optional 1k resistor for 6581 SID in socket 2 +
  - **ATTENTION!**: _This solder pad label is incorrect, it should read 6581!_
  
  - solder pad closed = enabled
11. Optional 1k resistor for 6581 SID in socket 2 +
  - **ATTENTION!**: _This solder pad label is incorrect, it should read 6581!_
  
  - solder pad closed = enabled
12. Socket 2 audio out via dupont connector +
  
  - Ground and S2 as labeled
13. Socket 1 audio out via dupont connector +
  
  - Ground and S1 as labeled
14. Reset button +


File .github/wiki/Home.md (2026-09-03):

# Welcome
Welcome to the USBSID-Pico wiki!  
Dee the sidebar menu for information.

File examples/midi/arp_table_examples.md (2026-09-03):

# ARP Table example presets
To hear one play: "Select on channel" button (sets CC_ARPT + CC_ARPM=Table), then enable CC_ARPE on the LFO/Arpeggiator tab and hold a note.
Slot 2 and 5 are the ones that actually matter for closing out the round-trip test — table 0/1 never exercised a negative offset.

Slot 1 — major triad up (basic, matches slot 0's shape shifted): offsets 0,4,7,4, step_count 4, loop_start 0
f0 50 27 01 00 00 00 04 00 07 00 04 00 00 00 00 00 00 00 00 00 00 00 00 00 00 00 00 00 00 00 00 00 00 00 00 00 00 00 04 f7

Slot 2 — octave bounce (tests a negative offset for the first time): offsets 0,12,0,-12, step_count 4, loop_start 0
f0 50 27 02 00 00 00 0c 00 00 0f 04 00 00 00 00 00 00 00 00 00 00 00 00 00 00 00 00 00 00 00 00 00 00 00 00 00 00 00 04 f7

Slot 3 — intro then loop (tests loop_start > 0): offsets 0,7,12,19,0,3,7,10, step_count 8, loop_start 4 (plays 0,7,12,19 once, then repeats 0,3,7,10 forever)
f0 50 27 03 00 00 00 07 00 0c 01 03 00 00 00 03 00 07 00 0a 00 00 00 00 00 00 00 00 00 00 00 00 00 00 00 00 00 04 00 08 f7

Slot 4 — full 16-step chromatic run (boundary: max step_count = 16): offsets 0..15, step_count 16, loop_start 0
f0 50 27 04 00 00 00 01 00 02 00 03 00 04 00 05 00 06 00 07 00 08 00 09 00 0a 00 0b 00 0c 00 0d 00 0e 00 0f 00 00 01 00 f7

Slot 5 — negative-heavy (stresses the signed-nibble decode path harder than slot 2 alone): offsets -12,-7,-3,0,3,7,12,0, step_count 8, loop_start 0
f0 50 27 05 0f 04 0f 09 0f 0d 00 00 00 03 00 07 00 0c 00 00 00 00 00 00 00 00 00 00 00 00 00 00 00 00 00 00 00 00 00 08 f7

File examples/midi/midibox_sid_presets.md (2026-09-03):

# MIDIbox SID V2 preset conversion (v2: LFO2 + Unison)

Every Lead- and Bassline-engine patch from the four [MIDIbox SID V2](https://github.com/midibox/mios8/tree/master/apps/synthesizers/midibox_sid_v2) preset banks, converted into this firmware's current `midi_patch_t` format (`repo/src/midi_patch.h`/`.c`) with a ready-to-send SysEx line for each one. This is the v2 conversion: same 499 patches as [`midibox_sid_presets.md`](midibox_sid_presets.md), rebuilt against the firmware state that added a second LFO and 3-voice unison to `midi_patch_t` (`sysex.c`'s `PATCH_SYSEX_NIBBLES` went from 36 to 48 nibbles per patch). Every field this firmware already had in v1 (waveform/ADSR/PWM, filter, LFO1, arp, bend range) is carried over byte-for-byte unchanged from that first conversion; only the two new fields below are freshly parsed from the source `.syx` dumps. Parsed directly from the real `.syx` dump files (`bank1__v2_vintage_bank.syx`, `bank2__tk2_soundbank.syx`, `bank3__127_arps.syx`, `bank4__Midibox_SammichSiD_Patches-chiptraxxx.syx`, all four in [`midibox_sid_v2/presets`](https://github.com/midibox/mios8/tree/master/apps/synthesizers/midibox_sid_v2/presets)), not retyped by hand, using the field layout in [`mbsidv2_sysex_implementation.txt`](https://github.com/midibox/mios8/blob/master/apps/synthesizers/midibox_sid_v2/doc/mbsidv2_sysex_implementation.txt).

**Why this can only ever be an approximation.** MIDIbox SID V2 is a far bigger synth engine than this firmware's `midi_patch_t`: 3 detunable oscillators per voice (this firmware doubles OSC1 across up to 3 SIDs for unison instead of true additive multi-osc), 2 envelopes plus an 8-slot modulation matrix that can route any of 6 LFOs to almost any target (this firmware has 2 fixed-destination LFOs as of this v2 conversion, still a long way from MBSID's matrix), a wavetable sequencer, and separate Bassline/Drum/Multi engines with their own structures. What follows is each patch's *closest reachable equivalent* on real SID hardware through this firmware's simpler model, not a byte-exact recreation - MIDIbox's own patch dump is not directly compatible with this firmware's SysEx protocol (different manufacturer ID, different command set, different patch layout) and was never meant to be loaded as-is.

Per-patch conversion choices, applied uniformly across every entry below:

- **Waveform/ADSR/PWM** come straight from the patch's Voice #1 (OSC1) - MIDIbox's own SID register bytes for these are already nibble-packed exactly the way this firmware's `tmpl_attdec`/`tmpl_susrel` are, so no scaling happens here. If OSC2/OSC3 were also active in the source (common on "3OSC detuned" patches), it's noted per patch - only OSC1's timbre survives the conversion; the detuned unison thickness does not (see the new **Unison** bullet below for what does carry over from OSC2/OSC3).
- **Filter cutoff** is rescaled from MIDIbox's 12-bit range to this firmware's 11-bit `CUTOFF_MAX` (divide by 2); **resonance** from 0-255 to 0-15 (its top 4 bits, which is all the real SID resonance register ever reads anyway); **routing** and **filter mode** bits map 1:1, both firmwares mirror the real RESFLT/MODVOL hardware bit layout.
- **LFO1** is the hard part: MIDIbox routes any of 6 LFOs to any target through its modulation matrix, so "LFO1" is frequently not the one doing anything audible. Each patch below was scanned for whichever LFO actually has a live modulation path into OSC1's pitch, PWM or the filter cutoff (matching the largest routed depth, via either the mod matrix's direct-assignment bits or its indexed target fields), and that LFO's own wave/rate was used; if none of the 6 are actually routed anywhere, LFO is reported off even if stale leftover values sit in the source's LFO1 slot. Sine and Positive-Sine waveforms become Triangle - the real SID has no sine oscillator, and neither does this firmware's LFO.
- **LFO2 (new in v2).** This firmware's second LFO is filled from whichever *other* MBSID LFO also has a live routed path into OSC1's pitch, PWM or cutoff, distinct from whatever was picked for LFO1 above - same liveness rule (the source LFO must be enabled and have a nonzero rate; a routed-but-frozen LFO produces no audible modulation and is skipped) and same largest-routed-depth tiebreak. For the Bassline engine, which has its own always-present LFO1/LFO2 pair rather than a 6-LFO matrix, this firmware's LFO2 is simply MBSID's own native LFO2, whichever of its three fixed depths (pitch/PW/cutoff) is largest. Rate is MIDIbox's own 0-255 LFO Rate halved to fit this firmware's range (matching how LFO1's rate is already carried over); depth is the absolute value of the routed depth, capped at 127. If no second live route exists, LFO2 is off. A small handful of Bank 4's more elaborately-patched entries route their modulation through velocity/key-tracking/knob-fed operator chains this scan doesn't unwind - those are left with LFO2 off rather than guessing.
- **Unison (new in v2).** This firmware's 3-voice unison (one detuned copy of the same patch per claimed SID, in `midi_config.h`) is filled straight from MIDIbox's own per-patch Oscillators Detune byte (`mbsidv2_sysex_implementation.txt` addr `0x051`, 0-255) - the same 0-255 range this firmware's `unison_detune` uses (`ch->unison_detune * 256 / 255` in `midi_handler.c` for the actual semitone spread), so no rescale is needed. Unison is reported on whenever the source patch has OSC2 and/or OSC3 actually enabled (not the disabled-oscillator bit), off otherwise, regardless of whether the detune byte happens to be 0 - MIDIbox's own multi-oscillator thickness is still lost in the conversion (this firmware doubles one oscillator's timbre across extra SIDs, not three independently-configured ones), but the *spread amount* the source patch used for it now carries over instead of being discarded.
- **Arpeggiator** mode/rate/octave-range come from the source patch's own arp settings regardless of whether the source patch had its arp switched on - this firmware's patch format has no "arp enabled" bit of its own (that's channel CC_ARPE, sent separately), so an arp pattern is always carried over as data even when it was dormant in the original; each entry notes whether the source had it enabled.
- **Bend range** is copied from the source's own pitch-range field. On percussive/one-shot patches (drum-ish Lead patches, e.g. "Bassdrum") this field is often just leftover/unused data in the source and not a deliberate bend range - don't read anything into a large or odd bend value on those.
- **Drum engine and Multi engine** patches are listed by name only, with no converted values: Drum is a 16-instrument kit triggered by note number, and Multi is up to 6 simultaneous layered instruments - neither has a meaningful single-voice equivalent in this firmware's one-`midi_patch_t`-per-Program-Change model. Worth revisiting by hand if one of those names is wanted.

**FMOPL.** None of the four MIDIbox SID V2 banks reference FM/OPL synthesis anywhere in the SysEx implementation - MBSID is SID-only, it has no OPL/FM chip concept at all (the closest thing, cross-oscillator FM, isn't present here either). So nothing below carries an FMOPL mark. The convention, if a future preset source does need it: mark that entry with **`[FMOPL]`** right after its name, meaning "needs FM/OPL synthesis this firmware doesn't implement yet", and skip generating values/SysEx for it, same as the Drum/Multi entries below.

**SysEx format.** Each line is `SYSEX_MIDI_PATCH_LOAD` (`repo/src/sysex.c`): `F0 50 20 <slot> <48 nibble bytes> F7` - 48 nibbles (24 raw bytes, 2 nibbles per 8-bit field, 4 for the 16-bit `filter_cutoff`), not 36; every field is sent as a value 0x00-0x0F to stay 7-bit MIDI safe, see `pack_patch()`/`unpack_patch()` in `sysex.c`. The first 36 nibbles are exactly [`midibox_sid_presets.md`](midibox_sid_presets.md)'s own line for the same patch, unchanged; the 12 new nibbles appended at the tail are `lfo2_wave`, `lfo2_rate`, `lfo2_depth`, `lfo2_dest`, `unison_enabled`, `unison_detune`, in that order, matching `midi_patch_t`'s own field order. Every line below targets slot **0x10 (16)**, the first user slot - edit that byte (4th, right after `f0 50 20`) to target a different slot, 0x10-0x1f (16-31) for your own patches or 0x00-0x0f (0-15) to overwrite a factory one (`tools/patch_editor.py` will ask for confirmation if you send there). Loading only updates RAM - send `f0 50 10 f7` (`SYSEX_MIDI_SAVE`) afterwards to persist it to flash, or use `tools/patch_editor.py`'s "Save to flash" button. **These 48-nibble lines only work against firmware that already has the LFO2/unison fields in `midi_patch_t`** - sending one to older firmware will be rejected by the `PATCH_SYSEX_MIN_SIZE` check as a malformed (too-long) message; use [`midibox_sid_presets.md`](midibox_sid_presets.md)'s 36-nibble lines against that firmware instead. You can send any of these lines directly with `amidi -p <port> -S "..."`, or by pasting the 48 nibble values into `tools/patch_editor.py`'s fields by hand.

## Contents

- [Bank 1 - Vintage Bank](#bank-1-vintage-bank)
- [Bank 2 - TK2 Soundbank](#bank-2-tk2-soundbank)
- [Bank 3 - 127 Arps](#bank-3-127-arps)
- [Bank 4 - SammichSiD Chiptraxxx](#bank-4-sammichsid-chiptraxxx)

## Bank 1 - Vintage Bank

128 patches converted from MBSID V1's 8580 preset bank, refined by Thorsten Klose for V2. The oldest and broadest bank: leads, basses, pads, drum hits, arps and sequences.

### 001 Lead Patch (Lead engine)

Pulse &middot; A0 D0 S15 R0 &middot; PWM 2048/4095 &middot; Filter off &middot; LFO off &middot; LFO2 off &middot; Arp Up rate=62 range=1oct (needs CC_ARPE on to hear) &middot; Bend range 2 &middot; Unison off

Notes: Arp defined but disabled in the source patch; CC_ARPE off by default; source uses OSC2/OSC3 too (multi-osc); only OSC1's timbre captured here. New in v2: LFO2 off (no second live-routed LFO found in the source); Unison off (source uses only OSC1).

```
f0 50 20 10 04 00 00 00 0f 00 00 00 00 08 00 01 00 00 00 00 00 00 01 00 00 00 00 00 00 00 00 00 00 00 03 0e 00 00 00 02 00 00 00 00 00 00 00 00 00 00 00 00 f7
```

### 002 Techno PWM (Lead engine)

Pulse &middot; A0 D0 S15 R0 &middot; PWM 1312/4095 &middot; Filter off &middot; LFO Triangle -> PWM rate=18 depth=64 &middot; LFO2 off &middot; Arp Up rate=62 range=1oct (needs CC_ARPE on to hear) &middot; Bend range 2 &middot; Unison on detune=7/255

Notes: LFO1 Sine -> Triangle (no sine on real SID); Arp defined but disabled in the source patch; CC_ARPE off by default; source uses OSC2/OSC3 too (multi-osc); only OSC1's timbre captured here. New in v2: LFO2 off (no second live-routed LFO found in the source); Unison on, detune=7/255 (from the source's OSC2/OSC3 detune spread, now usable as 3-voice unison instead of being discarded).

```
f0 50 20 10 04 00 00 00 0f 00 02 00 00 05 00 00 07 00 00 0f 00 00 01 00 00 00 01 02 04 00 00 01 00 00 03 0e 00 00 00 02 00 00 00 00 00 00 00 00 00 01 00 07 f7
```

### 003 Techno Saw (Lead engine)

Sawtooth &middot; A0 D0 S11 R5 &middot; Filter off &middot; LFO Triangle -> Pitch rate=75 depth=64 &middot; LFO2 off &middot; Arp Up rate=62 range=1oct (needs CC_ARPE on to hear) &middot; Bend range 2 &middot; Unison on detune=24/255

Notes: LFO1 Sine -> Triangle (no sine on real SID); Arp defined but disabled in the source patch; CC_ARPE off by default; source uses OSC2/OSC3 too (multi-osc); only OSC1's timbre captured here. New in v2: LFO2 off (no second live-routed LFO found in the source); Unison on, detune=24/255 (from the source's OSC2/OSC3 detune spread, now usable as 3-voice unison instead of being discarded).

```
f0 50 20 10 02 00 00 00 0b 05 00 00 00 08 00 04 00 00 00 00 00 00 01 00 00 00 04 0b 04 00 00 00 00 00 03 0e 00 00 00 02 00 00 00 00 00 00 00 00 00 01 01 08 f7
```

### 004 Techno 5th (Lead engine)

Pulse &middot; A0 D8 S6 R0 &middot; PWM 2048/4095 &middot; Filter off &middot; LFO Triangle -> PWM rate=38 depth=64 &middot; LFO2 off &middot; Arp Up rate=62 range=1oct (needs CC_ARPE on to hear) &middot; Bend range 2 &middot; Unison on detune=4/255

Notes: LFO1 Sine -> Triangle (no sine on real SID); Arp defined but disabled in the source patch; CC_ARPE off by default; source uses OSC2/OSC3 too (multi-osc); only OSC1's timbre captured here. New in v2: LFO2 off (no second live-routed LFO found in the source); Unison on, detune=4/255 (from the source's OSC2/OSC3 detune spread, now usable as 3-voice unison instead of being discarded).

```
f0 50 20 10 04 00 00 08 06 00 00 00 00 08 00 04 00 00 00 00 00 00 01 00 00 00 02 06 04 00 00 01 00 00 03 0e 00 00 00 02 00 00 00 00 00 00 00 00 00 01 00 04 f7
```

### 005 Cool Brass (Lead engine)

Sawtooth &middot; A0 D14 S3 R0 &middot; Filter off &middot; LFO Triangle -> Pitch rate=73 depth=64 &middot; LFO2 off &middot; Arp Up rate=62 range=1oct (needs CC_ARPE on to hear) &middot; Bend range 2 &middot; Unison on detune=16/255

Notes: LFO2 Sine -> Triangle (no sine on real SID); source modulation actually comes from LFO2, not LFO1 (this firmware has only one LFO per channel); Arp defined but disabled in the source patch; CC_ARPE off by default; source uses OSC2/OSC3 too (multi-osc); only OSC1's timbre captured here. New in v2: LFO2 off (no second live-routed LFO found in the source); Unison on, detune=16/255 (from the source's OSC2/OSC3 detune spread, now usable as 3-voice unison instead of being discarded).

```
f0 50 20 10 02 00 00 0e 03 00 00 00 00 0a 00 07 0f 00 00 00 00 00 01 00 00 00 04 09 04 00 00 00 00 00 03 0e 00 00 00 02 00 00 00 00 00 00 00 00 00 01 01 00 f7
```

### 006 Simple Saw (Lead engine)

Sawtooth &middot; A2 D0 S15 R0 &middot; Filter off &middot; LFO off &middot; LFO2 off &middot; Arp Up rate=62 range=1oct (needs CC_ARPE on to hear) &middot; Bend range 2 &middot; Unison off

Notes: Arp defined but disabled in the source patch; CC_ARPE off by default. New in v2: LFO2 off (no second live-routed LFO found in the source); Unison off (source uses only OSC1).

```
f0 50 20 10 02 00 02 00 0f 00 00 00 00 08 00 07 0f 00 00 00 00 00 00 00 00 00 00 00 00 00 00 00 00 00 03 0e 00 00 00 02 00 00 00 00 00 00 00 00 00 00 00 00 f7
```

### 007 Simple Pulse (Lead engine)

Pulse &middot; A0 D0 S15 R0 &middot; PWM 2048/4095 &middot; Filter off &middot; LFO Triangle -> PWM rate=2 depth=43 &middot; LFO2 off &middot; Arp Up rate=62 range=1oct (needs CC_ARPE on to hear) &middot; Bend range 2 &middot; Unison off

Notes: LFO2 Sine -> Triangle (no sine on real SID); source modulation actually comes from LFO2, not LFO1 (this firmware has only one LFO per channel); Arp defined but disabled in the source patch; CC_ARPE off by default; source uses OSC2/OSC3 too (multi-osc); only OSC1's timbre captured here. New in v2: LFO2 off (no second live-routed LFO found in the source); Unison off (source uses only OSC1).

```
f0 50 20 10 04 00 00 00 0f 00 00 00 00 08 00 06 0b 00 00 00 00 00 00 00 00 00 00 02 02 0b 00 01 00 00 03 0e 00 00 00 02 00 00 00 00 00 00 00 00 00 00 00 00 f7
```

### 008 Pulse w/o Body (Lead engine)

Pulse &middot; A0 D4 S7 R8 &middot; PWM 32/4095 &middot; Filter off &middot; LFO off &middot; LFO2 off &middot; Arp Up rate=62 range=1oct (needs CC_ARPE on to hear) &middot; Bend range 2 &middot; Unison on detune=0/255

Notes: Arp defined but disabled in the source patch; CC_ARPE off by default; source uses OSC2/OSC3 too (multi-osc); only OSC1's timbre captured here. New in v2: LFO2 off (no second live-routed LFO found in the source); Unison on, detune=0/255 (from the source's OSC2/OSC3 detune spread, now usable as 3-voice unison instead of being discarded).

```
f0 50 20 10 04 00 00 04 07 08 02 00 00 00 00 02 09 00 00 00 00 00 00 00 00 00 00 00 00 00 00 00 00 00 03 0e 00 00 00 02 00 00 00 00 00 00 00 00 00 01 00 00 f7
```

### 009 Popcorn (Lead engine)

Triangle &middot; A0 D6 S0 R0 &middot; Filter off &middot; LFO off &middot; LFO2 off &middot; Arp Up rate=62 range=1oct (needs CC_ARPE on to hear) &middot; Bend range 2 &middot; Unison off

Notes: Arp defined but disabled in the source patch; CC_ARPE off by default. New in v2: LFO2 off (no second live-routed LFO found in the source); Unison off (source uses only OSC1).

```
f0 50 20 10 01 00 00 06 00 00 00 00 00 08 00 04 00 00 00 00 00 00 01 00 00 00 00 00 00 00 00 00 00 00 03 0e 00 00 00 02 00 00 00 00 00 00 00 00 00 00 00 00 f7
```

### 010 WT Flute (Lead engine)

Triangle &middot; A7 D0 S13 R0 &middot; Filter off &middot; LFO Triangle -> Pitch rate=61 depth=120 &middot; LFO2 off &middot; Arp Up rate=62 range=1oct (needs CC_ARPE on to hear) &middot; Bend range 2 &middot; Unison off

Notes: LFO1 Sine -> Triangle (no sine on real SID); Arp defined but disabled in the source patch; CC_ARPE off by default; source uses OSC2/OSC3 too (multi-osc); only OSC1's timbre captured here. New in v2: LFO2 off (no second live-routed LFO found in the source); Unison off (source uses only OSC1).

```
f0 50 20 10 01 00 07 00 0d 00 00 00 00 08 00 04 00 00 00 00 00 00 01 00 00 00 03 0d 07 08 00 00 00 00 03 0e 00 00 00 02 00 00 00 00 00 00 00 00 00 00 00 00 f7
```

### 011 Synth Plug (Lead engine)

Pulse &middot; A0 D6 S0 R8 &middot; PWM 2048/4095 &middot; Filter LP cutoff=1168/2047 res=7/15 route=v1+v2+v3 &middot; LFO Triangle -> Pitch rate=86 depth=64 &middot; LFO2 Triangle -> PWM rate=58 depth=64 &middot; Arp Up rate=62 range=1oct (needs CC_ARPE on to hear) &middot; Bend range 2 &middot; Unison on detune=28/255

Notes: LFO1 Sine -> Triangle (no sine on real SID); Arp defined but disabled in the source patch; CC_ARPE off by default; source uses OSC2/OSC3 too (multi-osc); only OSC1's timbre captured here. New in v2: LFO2 sourced from a second live-routed MBSID LFO (Triangle, rate=58, depth=64, -> PWM); Unison on, detune=28/255 (from the source's OSC2/OSC3 detune spread, now usable as 3-voice unison instead of being discarded).

```
f0 50 20 10 04 00 00 06 00 08 00 00 00 08 00 04 09 00 00 07 00 07 01 00 00 00 05 06 04 00 00 00 00 00 03 0e 00 00 00 02 00 00 03 0a 04 00 00 01 00 01 01 0c f7
```

### 012 WT Synth (Lead engine)

Pulse &middot; A0 D3 S13 R0 &middot; PWM 2048/4095 &middot; Filter off &middot; LFO off &middot; LFO2 off &middot; Arp Up rate=62 range=1oct (needs CC_ARPE on to hear) &middot; Bend range 2 &middot; Unison on detune=3/255

Notes: Arp defined but disabled in the source patch; CC_ARPE off by default; source uses OSC2/OSC3 too (multi-osc); only OSC1's timbre captured here. New in v2: LFO2 off (no second live-routed LFO found in the source); Unison on, detune=3/255 (from the source's OSC2/OSC3 detune spread, now usable as 3-voice unison instead of being discarded).

```
f0 50 20 10 04 00 00 03 0d 00 00 00 00 08 00 04 01 00 00 0f 00 00 01 00 00 00 00 00 00 00 00 00 00 00 03 0e 00 00 00 02 00 00 00 00 00 00 00 00 00 01 00 03 f7
```

### 013 WT HardcoreSynth (Lead engine)

Pulse [ring] &middot; A0 D0 S11 R5 &middot; PWM 1856/4095 &middot; Filter off &middot; LFO Square -> Pitch rate=108 depth=64 &middot; LFO2 off &middot; Arp Up rate=62 range=1oct (needs CC_ARPE on to hear) &middot; Bend range 2 &middot; Unison on detune=0/255

Notes: Arp defined but disabled in the source patch; CC_ARPE off by default; source uses OSC2/OSC3 too (multi-osc); only OSC1's timbre captured here. New in v2: LFO2 off (no second live-routed LFO found in the source); Unison on, detune=0/255 (from the source's OSC2/OSC3 detune spread, now usable as 3-voice unison instead of being discarded).

```
f0 50 20 10 04 04 00 00 0b 05 04 00 00 07 00 01 00 00 00 0f 00 00 01 00 00 02 06 0c 04 00 00 00 00 00 03 0e 00 00 00 02 00 00 00 00 00 00 00 00 00 01 00 00 f7
```

### 014 Sync Sound (Lead engine)

Triangle [sync] &middot; A0 D0 S15 R0 &middot; Filter off &middot; LFO Triangle -> Pitch rate=9 depth=64 &middot; LFO2 off &middot; Arp Up rate=62 range=1oct (needs CC_ARPE on to hear) &middot; Bend range 106 &middot; Unison on detune=0/255

Notes: LFO1 Sine -> Triangle (no sine on real SID); Arp defined but disabled in the source patch; CC_ARPE off by default; source uses OSC2/OSC3 too (multi-osc); only OSC1's timbre captured here. New in v2: LFO2 off (no second live-routed LFO found in the source); Unison on, detune=0/255 (from the source's OSC2/OSC3 detune spread, now usable as 3-voice unison instead of being discarded).

```
f0 50 20 10 01 02 00 00 0f 00 04 00 00 03 00 07 0f 00 00 00 00 00 00 00 00 00 00 09 04 00 00 00 00 00 03 0e 00 00 06 0a 00 00 00 00 00 00 00 00 00 01 00 00 f7
```

### 015 Sync Pad (Lead engine)

Pulse [sync,ring] &middot; A15 D4 S13 R0 &middot; PWM 1600/4095 &middot; Filter off &middot; LFO Triangle -> Pitch rate=6 depth=64 &middot; LFO2 Triangle -> PWM rate=49 depth=64 &middot; Arp Up rate=62 range=1oct (needs CC_ARPE on to hear) &middot; Bend range 2 &middot; Unison on detune=49/255

Notes: LFO1 Sine -> Triangle (no sine on real SID); Arp defined but disabled in the source patch; CC_ARPE off by default; source uses OSC2/OSC3 too (multi-osc); only OSC1's timbre captured here. New in v2: LFO2 sourced from a second live-routed MBSID LFO (Triangle, rate=49, depth=64, -> PWM); Unison on, detune=49/255 (from the source's OSC2/OSC3 detune spread, now usable as 3-voice unison instead of being discarded).

```
f0 50 20 10 04 06 0f 04 0d 00 04 00 00 06 00 04 00 00 00 00 00 00 01 00 00 00 00 06 04 00 00 00 00 00 03 0e 00 00 00 02 00 00 03 01 04 00 00 01 00 01 03 01 f7
```

### 016 Filtered Poly (Multi engine) - not converted

### 017 Filt. Mono Pad (Lead engine)

Pulse [ring] &middot; A0 D0 S10 R11 &middot; PWM 2048/4095 &middot; Filter BP cutoff=112/2047 res=15/15 route=v1+v2+v3 &middot; LFO Triangle -> PWM rate=53 depth=64 &middot; LFO2 Triangle -> Cutoff rate=17 depth=64 &middot; Arp Up rate=62 range=1oct (needs CC_ARPE on to hear) &middot; Bend range 2 &middot; Unison on detune=24/255

Notes: LFO1 Sine -> Triangle (no sine on real SID); Arp defined but disabled in the source patch; CC_ARPE off by default; source uses OSC2/OSC3 too (multi-osc); only OSC1's timbre captured here. New in v2: LFO2 sourced from a second live-routed MBSID LFO (Triangle, rate=17, depth=64, -> Cutoff); Unison on, detune=24/255 (from the source's OSC2/OSC3 detune spread, now usable as 3-voice unison instead of being discarded).

```
f0 50 20 10 04 04 00 00 0a 0b 00 00 00 08 00 00 07 00 00 0f 00 07 02 00 00 00 03 05 04 00 00 01 00 00 03 0e 00 00 00 02 00 00 01 01 04 00 00 02 00 01 01 08 f7
```

### 018 Arpeggio (Lead engine)

Pulse &middot; A0 D0 S15 R5 &middot; PWM 2048/4095 &middot; Filter off &middot; LFO Triangle -> PWM rate=5 depth=64 &middot; LFO2 off &middot; Arp Up rate=30 range=1oct (needs CC_ARPE on to hear) &middot; Bend range 2 &middot; Unison off

Notes: LFO2 Sine -> Triangle (no sine on real SID); source modulation actually comes from LFO2, not LFO1 (this firmware has only one LFO per channel); source uses OSC2/OSC3 too (multi-osc); only OSC1's timbre captured here. New in v2: LFO2 off (no second live-routed LFO found in the source); Unison off (source uses only OSC1).

```
f0 50 20 10 04 00 00 00 0f 05 00 00 00 08 00 06 0b 00 00 00 00 00 00 00 00 00 00 05 04 00 00 01 00 00 01 0e 00 00 00 02 00 00 00 00 00 00 00 00 00 00 00 00 f7
```

### 019 Arpeggio 2 (Lead engine)

Pulse &middot; A5 D6 S7 R0 &middot; PWM 2048/4095 &middot; Filter off &middot; LFO Triangle -> PWM rate=34 depth=64 &middot; LFO2 off &middot; Arp Up rate=62 range=1oct (needs CC_ARPE on to hear) &middot; Bend range 2 &middot; Unison on detune=0/255

Notes: LFO1 Sine -> Triangle (no sine on real SID); Arp defined but disabled in the source patch; CC_ARPE off by default; source uses OSC2/OSC3 too (multi-osc); only OSC1's timbre captured here. New in v2: LFO2 off (no second live-routed LFO found in the source); Unison on, detune=0/255 (from the source's OSC2/OSC3 detune spread, now usable as 3-voice unison instead of being discarded).

```
f0 50 20 10 04 00 05 06 07 00 00 00 00 08 00 03 05 00 00 00 00 00 01 00 00 00 02 02 04 00 00 01 00 00 03 0e 00 00 00 02 00 00 00 00 00 00 00 00 00 01 00 00 f7
```

### 020 WT Arp Fun (Lead engine)

Pulse &middot; A0 D0 S15 R0 &middot; PWM 2048/4095 &middot; Filter off &middot; LFO Triangle -> PWM rate=85 depth=64 &middot; LFO2 off &middot; Arp Up rate=62 range=1oct (needs CC_ARPE on to hear) &middot; Bend range 2 &middot; Unison off

Notes: LFO1 Sine -> Triangle (no sine on real SID); Arp defined but disabled in the source patch; CC_ARPE off by default; source uses OSC2/OSC3 too (multi-osc); only OSC1's timbre captured here. New in v2: LFO2 off (no second live-routed LFO found in the source); Unison off (source uses only OSC1).

```
f0 50 20 10 04 00 00 00 0f 00 00 00 00 08 00 04 00 00 00 00 00 00 01 00 00 00 05 05 04 00 00 01 00 00 03 0e 00 00 00 02 00 00 00 00 00 00 00 00 00 00 00 00 f7
```

### 021 Ringmodulation (Lead engine)

Triangle [ring] &middot; A0 D0 S15 R5 &middot; Filter off &middot; LFO off &middot; LFO2 off &middot; Arp Up rate=62 range=1oct (needs CC_ARPE on to hear) &middot; Bend range 37 &middot; Unison on detune=2/255

Notes: Arp defined but disabled in the source patch; CC_ARPE off by default; source uses OSC2/OSC3 too (multi-osc); only OSC1's timbre captured here. New in v2: LFO2 off (no second live-routed LFO found in the source); Unison on, detune=2/255 (from the source's OSC2/OSC3 detune spread, now usable as 3-voice unison instead of being discarded).

```
f0 50 20 10 01 04 00 00 0f 05 02 00 00 07 00 06 0b 00 00 00 00 00 00 00 00 00 00 00 00 00 00 00 00 00 03 0e 00 00 02 05 00 00 00 00 00 00 00 00 00 01 00 02 f7
```

### 022 Filtered B. 6581 (Lead engine)

Pulse &middot; A0 D0 S11 R0 &middot; PWM 1312/4095 &middot; Filter LP cutoff=176/2047 res=0/15 route=v1+v2+v3 &middot; LFO Triangle -> PWM rate=18 depth=64 &middot; LFO2 off &middot; Arp Up rate=62 range=1oct (needs CC_ARPE on to hear) &middot; Bend range 2 &middot; Unison on detune=0/255

Notes: LFO3 Sine -> Triangle (no sine on real SID); source modulation actually comes from LFO3, not LFO1 (this firmware has only one LFO per channel); Arp defined but disabled in the source patch; CC_ARPE off by default; source uses OSC2/OSC3 too (multi-osc); only OSC1's timbre captured here. New in v2: LFO2 off (no second live-routed LFO found in the source); Unison on, detune=0/255 (from the source's OSC2/OSC3 detune spread, now usable as 3-voice unison instead of being discarded).

```
f0 50 20 10 04 00 00 00 0b 00 02 00 00 05 00 00 0b 00 00 00 00 07 01 00 00 00 01 02 04 00 00 01 00 00 03 0e 00 00 00 02 00 00 00 00 00 00 00 00 00 01 00 00 f7
```

### 023 Filtered B. 8580 (Lead engine)

Pulse &middot; A0 D0 S11 R0 &middot; PWM 1312/4095 &middot; Filter LP cutoff=0/2047 res=15/15 route=v1+v2+v3 &middot; LFO Triangle -> PWM rate=18 depth=64 &middot; LFO2 off &middot; Arp Up rate=62 range=1oct (needs CC_ARPE on to hear) &middot; Bend range 2 &middot; Unison on detune=0/255

Notes: LFO3 Sine -> Triangle (no sine on real SID); source modulation actually comes from LFO3, not LFO1 (this firmware has only one LFO per channel); Arp defined but disabled in the source patch; CC_ARPE off by default; source uses OSC2/OSC3 too (multi-osc); only OSC1's timbre captured here. New in v2: LFO2 off (no second live-routed LFO found in the source); Unison on, detune=0/255 (from the source's OSC2/OSC3 detune spread, now usable as 3-voice unison instead of being discarded).

```
f0 50 20 10 04 00 00 00 0b 00 02 00 00 05 00 00 00 00 00 0f 00 07 01 00 00 00 01 02 04 00 00 01 00 00 03 0e 00 00 00 02 00 00 00 00 00 00 00 00 00 01 00 00 f7
```

### 024 Filtered Bass 2 (Lead engine)

Pulse &middot; A0 D0 S15 R0 &middot; PWM 2048/4095 &middot; Filter LP cutoff=17/2047 res=15/15 route=v1 &middot; LFO off &middot; LFO2 off &middot; Arp Up rate=62 range=1oct (needs CC_ARPE on to hear) &middot; Bend range 2 &middot; Unison on detune=0/255

Notes: Arp defined but disabled in the source patch; CC_ARPE off by default; source uses OSC2/OSC3 too (multi-osc); only OSC1's timbre captured here. New in v2: LFO2 off (no second live-routed LFO found in the source); Unison on, detune=0/255 (from the source's OSC2/OSC3 detune spread, now usable as 3-voice unison instead of being discarded).

```
f0 50 20 10 04 00 00 00 0f 00 00 00 00 08 00 00 01 01 00 0f 00 01 01 00 00 00 00 00 00 00 00 00 00 00 03 0e 00 00 00 02 00 00 00 00 00 00 00 00 00 01 00 00 f7
```

### 025 C64 Bass (Lead engine)

Pulse &middot; A0 D0 S15 R0 &middot; PWM 2112/4095 &middot; Filter LP cutoff=507/2047 res=15/15 route=v1 &middot; LFO Triangle -> PWM rate=26 depth=64 &middot; LFO2 off &middot; Arp Up rate=62 range=1oct (needs CC_ARPE on to hear) &middot; Bend range 2 &middot; Unison off

Notes: LFO1 Sine -> Triangle (no sine on real SID); Arp defined but disabled in the source patch; CC_ARPE off by default; source uses OSC2/OSC3 too (multi-osc); only OSC1's timbre captured here. New in v2: LFO2 off (no second live-routed LFO found in the source); Unison off (source uses only OSC1).

```
f0 50 20 10 04 00 00 00 0f 00 04 00 00 08 00 01 0f 0b 00 0f 00 01 01 00 00 00 01 0a 04 00 00 01 00 00 03 0e 00 00 00 02 00 00 00 00 00 00 00 00 00 00 00 00 f7
```

### 026 Autobahn (Lead engine)

Sawtooth &middot; A0 D0 S11 R7 &middot; Filter LP cutoff=142/2047 res=5/15 route=v1+v2 &middot; LFO off &middot; LFO2 off &middot; Arp Up rate=62 range=1oct (needs CC_ARPE on to hear) &middot; Bend range 2 &middot; Unison off

Notes: Arp defined but disabled in the source patch; CC_ARPE off by default; source uses OSC2/OSC3 too (multi-osc); only OSC1's timbre captured here. New in v2: LFO2 off (no second live-routed LFO found in the source); Unison off (source uses only OSC1).

```
f0 50 20 10 02 00 00 00 0b 07 00 00 00 08 00 00 08 0e 00 05 00 03 01 00 00 00 00 00 00 00 00 00 00 00 03 0e 00 00 00 02 00 00 00 00 00 00 00 00 00 00 00 00 f7
```

### 027 Bassdrum (Lead engine)

Triangle &middot; A0 D10 S0 R5 &middot; Filter LP cutoff=16/2047 res=0/15 route=v2 &middot; LFO off &middot; LFO2 off &middot; Arp Up rate=62 range=1oct (needs CC_ARPE on to hear) &middot; Bend range 55 &middot; Unison on detune=0/255

Notes: Arp defined but disabled in the source patch; CC_ARPE off by default; source uses OSC2/OSC3 too (multi-osc); only OSC1's timbre captured here. New in v2: LFO2 off (no second live-routed LFO found in the source); Unison on, detune=0/255 (from the source's OSC2/OSC3 detune spread, now usable as 3-voice unison instead of being discarded).

```
f0 50 20 10 01 00 00 0a 00 05 02 00 00 07 00 00 01 00 00 00 00 02 01 00 00 00 00 00 00 00 00 00 00 00 03 0e 00 00 03 07 00 00 00 00 00 00 00 00 00 01 00 00 f7
```

### 028 Bassdrum2 (Lead engine)

Triangle &middot; A0 D0 S15 R0 &middot; Filter off &middot; LFO Triangle -> PWM rate=20 depth=64 &middot; LFO2 off &middot; Arp Up rate=62 range=1oct (needs CC_ARPE on to hear) &middot; Bend range 45 &middot; Unison on detune=0/255

Notes: LFO2 Sine -> Triangle (no sine on real SID); source modulation actually comes from LFO2, not LFO1 (this firmware has only one LFO per channel); Arp defined but disabled in the source patch; CC_ARPE off by default; source uses OSC2/OSC3 too (multi-osc); only OSC1's timbre captured here. New in v2: LFO2 off (no second live-routed LFO found in the source); Unison on, detune=0/255 (from the source's OSC2/OSC3 detune spread, now usable as 3-voice unison instead of being discarded).

```
f0 50 20 10 01 00 00 00 0f 00 04 00 00 08 00 07 0f 00 00 00 00 00 01 00 00 00 01 04 04 00 00 01 00 00 03 0e 00 00 02 0d 00 00 00 00 00 00 00 00 00 01 00 00 f7
```

### 029 Cymbal (Lead engine)

Noise &middot; A0 D9 S0 R9 &middot; Filter off &middot; LFO Triangle -> Pitch rate=87 depth=64 &middot; LFO2 off &middot; Arp Up rate=62 range=1oct (needs CC_ARPE on to hear) &middot; Bend range 37 &middot; Unison on detune=0/255

Notes: LFO1 Sine -> Triangle (no sine on real SID); Arp defined but disabled in the source patch; CC_ARPE off by default. New in v2: LFO2 off (no second live-routed LFO found in the source); Unison on, detune=0/255 (from the source's OSC2/OSC3 detune spread, now usable as 3-voice unison instead of being discarded).

```
f0 50 20 10 08 00 00 09 00 09 04 00 00 08 00 07 0f 00 00 00 00 00 01 00 00 00 05 07 04 00 00 00 00 00 03 0e 00 00 02 05 00 00 00 00 00 00 00 00 00 01 00 00 f7
```

### 030 Klick (Lead engine)

Noise &middot; A0 D2 S0 R0 &middot; Filter off &middot; LFO off &middot; LFO2 off &middot; Arp Up rate=62 range=1oct (needs CC_ARPE on to hear) &middot; Bend range 37 &middot; Unison on detune=0/255

Notes: Arp defined but disabled in the source patch; CC_ARPE off by default; source uses OSC2/OSC3 too (multi-osc); only OSC1's timbre captured here. New in v2: LFO2 off (no second live-routed LFO found in the source); Unison on, detune=0/255 (from the source's OSC2/OSC3 detune spread, now usable as 3-voice unison instead of being discarded).

```
f0 50 20 10 08 00 00 02 00 00 04 00 00 08 00 07 0f 00 00 00 00 00 01 00 00 00 00 00 00 00 00 00 00 00 03 0e 00 00 02 05 00 00 00 00 00 00 00 00 00 01 00 00 f7
```

### 031 Metal (Lead engine)

Triangle [ring] &middot; A0 D7 S0 R0 &middot; Filter off &middot; LFO off &middot; LFO2 off &middot; Arp Up rate=62 range=1oct (needs CC_ARPE on to hear) &middot; Bend range 37 &middot; Unison on detune=0/255

Notes: Arp defined but disabled in the source patch; CC_ARPE off by default; source uses OSC2/OSC3 too (multi-osc); only OSC1's timbre captured here. New in v2: LFO2 off (no second live-routed LFO found in the source); Unison on, detune=0/255 (from the source's OSC2/OSC3 detune spread, now usable as 3-voice unison instead of being discarded).

```
f0 50 20 10 01 04 00 07 00 00 04 00 00 08 00 07 0f 00 00 00 00 00 01 00 00 00 00 00 00 00 00 00 00 00 03 0e 00 00 02 05 00 00 00 00 00 00 00 00 00 01 00 00 f7
```

### 032 Deep Bass 9 (Lead engine)

Sawtooth &middot; A0 D0 S15 R10 &middot; Filter LP cutoff=65/2047 res=14/15 route=v1+v2+v3 &middot; LFO Triangle -> Pitch rate=84 depth=111 &middot; LFO2 Triangle -> PWM rate=58 depth=64 &middot; Arp Up rate=30 range=2oct (needs CC_ARPE on to hear) &middot; Bend range 2 &middot; Unison on detune=19/255

Notes: LFO2 Sine -> Triangle (no sine on real SID); source modulation actually comes from LFO2, not LFO1 (this firmware has only one LFO per channel); Arp defined but disabled in the source patch; CC_ARPE off by default; source uses OSC2/OSC3 too (multi-osc); only OSC1's timbre captured here. New in v2: LFO2 sourced from a second live-routed MBSID LFO (Triangle, rate=58, depth=64, -> PWM); Unison on, detune=19/255 (from the source's OSC2/OSC3 detune spread, now usable as 3-voice unison instead of being discarded).

```
f0 50 20 10 02 00 00 00 0f 0a 08 04 00 03 00 00 04 01 00 0e 00 07 01 00 00 00 05 04 06 0f 00 00 00 00 01 0e 00 01 00 02 00 00 03 0a 04 00 00 01 00 01 01 03 f7
```

### 033 Drum Kit 1 (Drum engine) - not converted

### 034 Drum Kit 2 (Drum engine) - not converted

### 035 Drum Kit 3 (Drum engine) - not converted

### 036 Drum Kit 4 (Drum engine) - not converted

### 037 Some Triggs (Lead engine)

Triangle [ring] &middot; A0 D3 S0 R10 &middot; Filter LP cutoff=675/2047 res=15/15 route=v1+v2+v3 &middot; LFO Sawtooth -> Cutoff rate=10 depth=64 &middot; LFO2 off &middot; Arp Up rate=62 range=1oct (needs CC_ARPE on to hear) &middot; Bend range 2 &middot; Unison on detune=0/255

Notes: source modulation actually comes from LFO4, not LFO1 (this firmware has only one LFO per channel); Arp defined but disabled in the source patch; CC_ARPE off by default; source uses OSC2/OSC3 too (multi-osc); only OSC1's timbre captured here. New in v2: LFO2 off (no second live-routed LFO found in the source); Unison on, detune=0/255 (from the source's OSC2/OSC3 detune spread, now usable as 3-voice unison instead of being discarded).

```
f0 50 20 10 01 04 00 03 00 0a 07 0a 00 04 00 02 0a 03 00 0f 00 07 01 00 00 01 00 0a 04 00 00 02 00 00 03 0e 00 00 00 02 00 00 00 00 00 00 00 00 00 01 00 00 f7
```

### 038 More Triggs (Lead engine)

Sawtooth [sync] &middot; A0 D5 S0 R11 &middot; Filter HP cutoff=1151/2047 res=15/15 route=v1+v2+v3 &middot; LFO Triangle -> Cutoff rate=0 depth=64 &middot; LFO2 off &middot; Arp Up rate=62 range=1oct (needs CC_ARPE on to hear) &middot; Bend range 2 &middot; Unison on detune=0/255

Notes: LFO4 Sine -> Triangle (no sine on real SID); source modulation actually comes from LFO4, not LFO1 (this firmware has only one LFO per channel); Arp defined but disabled in the source patch; CC_ARPE off by default; source uses OSC2/OSC3 too (multi-osc); only OSC1's timbre captured here. New in v2: LFO2 off (no second live-routed LFO found in the source); Unison on, detune=0/255 (from the source's OSC2/OSC3 detune spread, now usable as 3-voice unison instead of being discarded).

```
f0 50 20 10 02 02 00 05 00 0b 00 00 00 08 00 04 07 0f 00 0f 00 07 04 00 00 00 00 00 04 00 00 02 00 00 03 0e 00 00 00 02 00 00 00 00 00 00 00 00 00 01 00 00 f7
```

### 039 RingModMod (Lead engine)

Triangle [ring] &middot; A0 D0 S15 R0 &middot; Filter off &middot; LFO Triangle -> PWM rate=12 depth=64 &middot; LFO2 Triangle -> Pitch rate=4 depth=17 &middot; Arp Random rate=62 range=3oct (needs CC_ARPE on to hear) &middot; Bend range 2 &middot; Unison on detune=0/255

Notes: LFO1 Sine -> Triangle (no sine on real SID); source uses OSC2/OSC3 too (multi-osc); only OSC1's timbre captured here. New in v2: LFO2 sourced from a second live-routed MBSID LFO (Triangle, rate=4, depth=17, -> Pitch); Unison on, detune=0/255 (from the source's OSC2/OSC3 detune spread, now usable as 3-voice unison instead of being discarded).

```
f0 50 20 10 01 04 00 00 0f 00 00 00 00 08 00 00 00 00 00 0f 00 00 01 00 00 00 00 0c 04 00 00 01 00 03 03 0e 00 02 00 02 00 00 00 04 01 01 00 00 00 01 00 00 f7
```

### 040 RampUp (Lead engine)

Pulse &middot; A0 D0 S15 R0 &middot; PWM 1433/4095 &middot; Filter off &middot; LFO Triangle -> PWM rate=16 depth=64 &middot; LFO2 Sawtooth -> Pitch rate=19 depth=1 &middot; Arp Up rate=62 range=1oct (needs CC_ARPE on to hear) &middot; Bend range 2 &middot; Unison on detune=12/255

Notes: LFO1 Sine -> Triangle (no sine on real SID); Arp defined but disabled in the source patch; CC_ARPE off by default; source uses OSC2/OSC3 too (multi-osc); only OSC1's timbre captured here. New in v2: LFO2 sourced from a second live-routed MBSID LFO (Sawtooth, rate=19, depth=1, -> Pitch); Unison on, detune=12/255 (from the source's OSC2/OSC3 detune spread, now usable as 3-voice unison instead of being discarded).

```
f0 50 20 10 04 00 00 00 0f 00 09 09 00 05 00 01 00 00 00 00 00 00 01 00 00 00 01 00 04 00 00 01 00 00 03 0e 00 00 00 02 00 01 01 03 00 01 00 00 00 01 00 0c f7
```

### 041 Math Game (Lead engine)

Sawtooth [sync] &middot; A0 D0 S15 R0 &middot; Filter LP cutoff=148/2047 res=15/15 route=v1+v2+v3 &middot; LFO Triangle -> Pitch rate=55 depth=124 &middot; LFO2 Triangle -> Cutoff rate=21 depth=105 &middot; Arp Up rate=62 range=1oct (needs CC_ARPE on to hear) &middot; Bend range 2 &middot; Unison on detune=33/255

Notes: LFO4 Sine -> Triangle (no sine on real SID); source modulation actually comes from LFO4, not LFO1 (this firmware has only one LFO per channel); Arp defined but disabled in the source patch; CC_ARPE off by default; source uses OSC2/OSC3 too (multi-osc); only OSC1's timbre captured here. New in v2: LFO2 sourced from a second live-routed MBSID LFO (Triangle, rate=21, depth=105, -> Cutoff); Unison on, detune=33/255 (from the source's OSC2/OSC3 detune spread, now usable as 3-voice unison instead of being discarded).

```
f0 50 20 10 02 02 00 00 0f 00 00 00 00 08 00 00 09 04 00 0f 00 07 01 00 00 00 03 07 07 0c 00 00 00 00 03 0e 00 00 00 02 00 00 01 05 06 09 00 02 00 01 02 01 f7
```

### 042 WT Runner (Lead engine)

Pulse &middot; A0 D0 S15 R0 &middot; PWM 2048/4095 &middot; Filter LP cutoff=455/2047 res=15/15 route=v1+v2+v3 &middot; LFO Sample&Hold -> PWM rate=126 depth=64 &middot; LFO2 off &middot; Arp Up rate=62 range=1oct (needs CC_ARPE on to hear) &middot; Bend range 2 &middot; Unison on detune=7/255

Notes: Arp defined but disabled in the source patch; CC_ARPE off by default; source uses OSC2/OSC3 too (multi-osc); only OSC1's timbre captured here. New in v2: LFO2 off (no second live-routed LFO found in the source); Unison on, detune=7/255 (from the source's OSC2/OSC3 detune spread, now usable as 3-voice unison instead of being discarded).

```
f0 50 20 10 04 00 00 00 0f 00 00 00 00 08 00 01 0c 07 00 0f 00 07 01 00 00 03 07 0e 04 00 00 01 00 00 03 0e 00 00 00 02 00 00 00 00 00 00 00 00 00 01 00 07 f7
```

### 043 WT Stereo Echo (Lead engine)

Triangle &middot; A0 D7 S15 R6 &middot; Filter off &middot; LFO Sample&Hold -> PWM rate=126 depth=64 &middot; LFO2 off &middot; Arp Up rate=62 range=1oct (needs CC_ARPE on to hear) &middot; Bend range 2 &middot; Unison on detune=7/255

Notes: Arp defined but disabled in the source patch; CC_ARPE off by default; source uses OSC2/OSC3 too (multi-osc); only OSC1's timbre captured here. New in v2: LFO2 off (no second live-routed LFO found in the source); Unison on, detune=7/255 (from the source's OSC2/OSC3 detune spread, now usable as 3-voice unison instead of being discarded).

```
f0 50 20 10 01 00 00 07 0f 06 00 00 00 08 00 01 0c 07 00 0f 00 00 01 00 00 03 07 0e 04 00 00 01 00 00 03 0e 00 00 00 02 00 00 00 00 00 00 00 00 00 01 00 07 f7
```

### 044 Turntable (Lead engine)

Pulse &middot; A0 D0 S15 R0 &middot; PWM 668/4095 &middot; Filter LP cutoff=273/2047 res=15/15 route=v1+v2+v3 &middot; LFO Sawtooth -> PWM rate=73 depth=64 &middot; LFO2 off &middot; Arp Up rate=62 range=1oct (needs CC_ARPE on to hear) &middot; Bend range 2 &middot; Unison on detune=28/255

Notes: Arp defined but disabled in the source patch; CC_ARPE off by default; source uses OSC2/OSC3 too (multi-osc); only OSC1's timbre captured here. New in v2: LFO2 off (no second live-routed LFO found in the source); Unison on, detune=28/255 (from the source's OSC2/OSC3 detune spread, now usable as 3-voice unison instead of being discarded).

```
f0 50 20 10 04 00 00 00 0f 00 09 0c 00 02 00 01 01 01 00 0f 00 07 01 00 00 01 04 09 04 00 00 01 00 00 03 0e 00 00 00 02 00 00 00 00 00 00 00 00 00 01 01 0c f7
```

### 045 Driving a Car (Lead engine)

Triangle+Pulse &middot; A0 D0 S13 R9 &middot; PWM 2048/4095 &middot; Filter off &middot; LFO Triangle -> Pitch rate=4 depth=64 &middot; LFO2 off &middot; Arp Up rate=62 range=1oct (needs CC_ARPE on to hear) &middot; Bend range 40 &middot; Unison on detune=8/255

Notes: LFO1 Sine -> Triangle (no sine on real SID); Arp defined but disabled in the source patch; CC_ARPE off by default; source uses OSC2/OSC3 too (multi-osc); only OSC1's timbre captured here. New in v2: LFO2 off (no second live-routed LFO found in the source); Unison on, detune=8/255 (from the source's OSC2/OSC3 detune spread, now usable as 3-voice unison instead of being discarded).

```
f0 50 20 10 05 00 00 00 0d 09 00 00 00 08 00 04 00 00 00 00 00 00 01 00 00 00 00 04 04 00 00 00 00 00 03 0e 00 00 02 08 00 00 00 00 00 00 00 00 00 01 00 08 f7
```

### 046 Ufo Reverse (Lead engine)

Triangle [ring] &middot; A13 D0 S0 R0 &middot; Filter off &middot; LFO off &middot; LFO2 off &middot; Arp Up rate=62 range=1oct (needs CC_ARPE on to hear) &middot; Bend range 25 &middot; Unison on detune=40/255

Notes: Arp defined but disabled in the source patch; CC_ARPE off by default; source uses OSC2/OSC3 too (multi-osc); only OSC1's timbre captured here. New in v2: LFO2 off (no second live-routed LFO found in the source); Unison on, detune=40/255 (from the source's OSC2/OSC3 detune spread, now usable as 3-voice unison instead of being discarded).

```
f0 50 20 10 01 04 0d 00 00 00 00 00 00 08 00 04 00 00 00 00 00 00 01 00 00 00 00 00 00 00 00 00 00 00 03 0e 00 00 01 09 00 00 00 00 00 00 00 00 00 01 02 08 f7
```

### 047 WT Falling (Lead engine)

Pulse &middot; A0 D0 S13 R11 &middot; PWM 2080/4095 &middot; Filter off &middot; LFO off &middot; LFO2 off &middot; Arp Up rate=62 range=1oct (needs CC_ARPE on to hear) &middot; Bend range 2 &middot; Unison off

Notes: Arp defined but disabled in the source patch; CC_ARPE off by default. New in v2: LFO2 off (no second live-routed LFO found in the source); Unison off (source uses only OSC1).

```
f0 50 20 10 04 00 00 00 0d 0b 02 00 00 08 00 04 00 00 00 00 00 00 01 00 00 00 00 00 00 00 00 00 00 00 03 0e 00 00 00 02 00 00 00 00 00 00 00 00 00 00 00 00 f7
```

### 048 WT Helicopter (Lead engine)

Pulse [sync] &middot; A0 D0 S15 R0 &middot; PWM 1856/4095 &middot; Filter LP cutoff=448/2047 res=15/15 route=v1+v2+v3 &middot; LFO Triangle -> PWM rate=9 depth=64 &middot; LFO2 Triangle -> Cutoff rate=7 depth=64 &middot; Arp Up rate=62 range=1oct (needs CC_ARPE on to hear) &middot; Bend range 2 &middot; Unison off

Notes: LFO1 Sine -> Triangle (no sine on real SID); Arp defined but disabled in the source patch; CC_ARPE off by default. New in v2: LFO2 sourced from a second live-routed MBSID LFO (Triangle, rate=7, depth=64, -> Cutoff); Unison off (source uses only OSC1).

```
f0 50 20 10 04 02 00 00 0f 00 04 00 00 07 00 01 0c 00 00 0f 00 07 01 00 00 00 00 09 04 00 00 01 00 00 03 0e 00 00 00 02 00 00 00 07 04 00 00 02 00 00 00 00 f7
```

### 049 WT Neutron (Lead engine)

Pulse &middot; A0 D2 S0 R10 &middot; PWM 2080/4095 &middot; Filter off &middot; LFO Triangle -> Pitch rate=4 depth=64 &middot; LFO2 Triangle -> Pitch rate=16 depth=64 &middot; Arp Up rate=62 range=1oct (needs CC_ARPE on to hear) &middot; Bend range 8 &middot; Unison off

Notes: LFO1 Sine -> Triangle (no sine on real SID); Arp defined but disabled in the source patch; CC_ARPE off by default; source uses OSC2/OSC3 too (multi-osc); only OSC1's timbre captured here. New in v2: LFO2 sourced from a second live-routed MBSID LFO (Triangle, rate=16, depth=64, -> Pitch); Unison off (source uses only OSC1).

```
f0 50 20 10 04 00 00 02 00 0a 02 00 00 08 00 04 00 00 00 00 00 00 01 00 00 00 00 04 04 00 00 00 00 00 03 0e 00 00 00 08 00 00 01 00 04 00 00 00 00 00 00 00 f7
```

### 050 WT Filtered Seq. (Lead engine)

Pulse &middot; A0 D0 S15 R8 &middot; PWM 2112/4095 &middot; Filter BP cutoff=157/2047 res=15/15 route=v1+v2+v3 &middot; LFO Triangle -> PWM rate=43 depth=64 &middot; LFO2 Triangle -> Cutoff rate=5 depth=64 &middot; Arp Up rate=62 range=1oct (needs CC_ARPE on to hear) &middot; Bend range 2 &middot; Unison on detune=32/255

Notes: LFO1 Sine -> Triangle (no sine on real SID); Arp defined but disabled in the source patch; CC_ARPE off by default; source uses OSC2/OSC3 too (multi-osc); only OSC1's timbre captured here. New in v2: LFO2 sourced from a second live-routed MBSID LFO (Triangle, rate=5, depth=64, -> Cutoff); Unison on, detune=32/255 (from the source's OSC2/OSC3 detune spread, now usable as 3-voice unison instead of being discarded).

```
f0 50 20 10 04 00 00 00 0f 08 04 00 00 08 00 00 09 0d 00 0f 00 07 02 00 00 00 02 0b 04 00 00 01 00 00 03 0e 00 00 00 02 00 00 00 05 04 00 00 02 00 01 02 00 f7
```

### 051 Alien Groove (Lead engine)

Pulse &middot; A0 D0 S12 R10 &middot; PWM 1632/4095 &middot; Filter off &middot; LFO Triangle -> PWM rate=22 depth=64 &middot; LFO2 off &middot; Arp Up rate=62 range=1oct (needs CC_ARPE on to hear) &middot; Bend range 2 &middot; Unison on detune=21/255

Notes: LFO1 Sine -> Triangle (no sine on real SID); Arp defined but disabled in the source patch; CC_ARPE off by default; source uses OSC2/OSC3 too (multi-osc); only OSC1's timbre captured here. New in v2: LFO2 off (no second live-routed LFO found in the source); Unison on, detune=21/255 (from the source's OSC2/OSC3 detune spread, now usable as 3-voice unison instead of being discarded).

```
f0 50 20 10 04 00 00 00 0c 0a 06 00 00 06 00 05 00 00 00 00 00 00 00 00 00 00 01 06 04 00 00 01 00 00 03 0e 00 00 00 02 00 00 00 00 00 00 00 00 00 01 01 05 f7
```

### 052 Nice Lead (Lead engine)

Pulse &middot; A0 D3 S12 R9 &middot; PWM 1037/4095 &middot; Filter LP cutoff=1170/2047 res=0/15 route=v1 &middot; LFO Triangle -> Pitch rate=61 depth=125 &middot; LFO2 Triangle -> Pitch rate=57 depth=125 &middot; Arp Up rate=62 range=1oct (needs CC_ARPE on to hear) &middot; Bend range 2 &middot; Unison on detune=14/255

Notes: LFO2 Sine -> Triangle (no sine on real SID); source modulation actually comes from LFO2, not LFO1 (this firmware has only one LFO per channel); Arp defined but disabled in the source patch; CC_ARPE off by default; source uses OSC2/OSC3 too (multi-osc); only OSC1's timbre captured here. New in v2: LFO2 sourced from a second live-routed MBSID LFO (Triangle, rate=57, depth=125, -> Pitch); Unison on, detune=14/255 (from the source's OSC2/OSC3 detune spread, now usable as 3-voice unison instead of being discarded).

```
f0 50 20 10 04 00 00 03 0c 09 00 0d 00 04 00 04 09 02 00 00 00 01 01 00 00 00 03 0d 07 0d 00 00 00 00 03 0e 00 00 00 02 00 00 03 09 07 0d 00 00 00 01 00 0e f7
```

### 053 NT Bass (Lead engine)

Pulse &middot; A0 D0 S15 R0 &middot; PWM 2848/4095 &middot; Filter LP cutoff=213/2047 res=15/15 route=v1+v2+v3 &middot; LFO off &middot; LFO2 off &middot; Arp Up rate=62 range=1oct (needs CC_ARPE on to hear) &middot; Bend range 2 &middot; Unison on detune=5/255

Notes: Arp defined but disabled in the source patch; CC_ARPE off by default; source uses OSC2/OSC3 too (multi-osc); only OSC1's timbre captured here. New in v2: LFO2 off (no second live-routed LFO found in the source); Unison on, detune=5/255 (from the source's OSC2/OSC3 detune spread, now usable as 3-voice unison instead of being discarded).

```
f0 50 20 10 04 00 00 00 0f 00 02 00 00 0b 00 00 0d 05 00 0f 00 07 01 00 00 00 00 00 00 00 00 00 00 00 03 0e 00 00 00 02 00 00 00 00 00 00 00 00 00 01 00 05 f7
```

### 054 RingKabinett (Lead engine)

Pulse [ring] &middot; A0 D0 S15 R0 &middot; PWM 1344/4095 &middot; Filter off &middot; LFO off &middot; LFO2 off &middot; Arp Up rate=62 range=1oct (needs CC_ARPE on to hear) &middot; Bend range 2 &middot; Unison on detune=33/255

Notes: Arp defined but disabled in the source patch; CC_ARPE off by default; OSC1 'Disable Oscillator' flag was set in source; kept waveform bits anyway; source uses OSC2/OSC3 too (multi-osc); only OSC1's timbre captured here. New in v2: LFO2 off (no second live-routed LFO found in the source); Unison on, detune=33/255 (from the source's OSC2/OSC3 detune spread, now usable as 3-voice unison instead of being discarded).

```
f0 50 20 10 04 04 00 00 0f 00 04 00 00 05 00 04 00 00 00 00 00 00 00 00 00 00 00 00 00 00 00 00 00 00 03 0e 00 00 00 02 00 00 00 00 00 00 00 00 00 01 02 01 f7
```

### 055 Random Fun (Lead engine)

Pulse &middot; A0 D0 S15 R0 &middot; PWM 2048/4095 &middot; Filter off &middot; LFO Sample&Hold -> Pitch rate=15 depth=64 &middot; LFO2 off &middot; Arp Up rate=62 range=1oct (needs CC_ARPE on to hear) &middot; Bend range 2 &middot; Unison on detune=16/255

Notes: Arp defined but disabled in the source patch; CC_ARPE off by default; source uses OSC2/OSC3 too (multi-osc); only OSC1's timbre captured here. New in v2: LFO2 off (no second live-routed LFO found in the source); Unison on, detune=16/255 (from the source's OSC2/OSC3 detune spread, now usable as 3-voice unison instead of being discarded).

```
f0 50 20 10 04 00 00 00 0f 00 00 00 00 08 00 04 00 00 00 00 00 00 01 00 00 03 00 0f 04 00 00 00 00 00 03 0e 00 00 00 02 00 00 00 00 00 00 00 00 00 01 01 00 f7
```

### 056 Don't cry baby! (Lead engine)

Triangle [ring] &middot; A7 D3 S10 R0 &middot; Filter off &middot; LFO Triangle -> Pitch rate=26 depth=99 &middot; LFO2 Triangle -> Pitch rate=13 depth=76 &middot; Arp Up rate=62 range=1oct (needs CC_ARPE on to hear) &middot; Bend range 2 &middot; Unison off

Notes: LFO2 Sine -> Triangle (no sine on real SID); source modulation actually comes from LFO2, not LFO1 (this firmware has only one LFO per channel); Arp defined but disabled in the source patch; CC_ARPE off by default; source uses OSC2/OSC3 too (multi-osc); only OSC1's timbre captured here. New in v2: LFO2 sourced from a second live-routed MBSID LFO (Triangle, rate=13, depth=76, -> Pitch); Unison off (source uses only OSC1).

```
f0 50 20 10 01 04 07 03 0a 00 00 00 00 08 00 00 00 00 00 0f 00 00 02 00 00 00 01 0a 06 03 00 00 00 00 03 0e 00 00 00 02 00 00 00 0d 04 0c 00 00 00 00 00 00 f7
```

### 057 Tweak the LFOs (Lead engine)

Triangle [ring] &middot; A7 D3 S10 R6 &middot; Filter LP cutoff=0/2047 res=15/15 route=v1+v2+v3 &middot; LFO Square -> Pitch rate=24 depth=64 &middot; LFO2 Triangle -> Pitch rate=32 depth=64 &middot; Arp Up rate=62 range=1oct (needs CC_ARPE on to hear) &middot; Bend range 2 &middot; Unison on detune=0/255

Notes: Arp defined but disabled in the source patch; CC_ARPE off by default; source uses OSC2/OSC3 too (multi-osc); only OSC1's timbre captured here. New in v2: LFO2 sourced from a second live-routed MBSID LFO (Triangle, rate=32, depth=64, -> Pitch); Unison on, detune=0/255 (from the source's OSC2/OSC3 detune spread, now usable as 3-voice unison instead of being discarded).

```
f0 50 20 10 01 04 07 03 0a 06 00 00 00 08 00 00 00 00 00 0f 00 07 01 00 00 02 01 08 04 00 00 00 00 00 03 0e 00 00 00 02 00 00 02 00 04 00 00 00 00 01 00 00 f7
```

### 058 Random Sync (Lead engine)

Triangle [ring] &middot; A7 D3 S10 R0 &middot; Filter off &middot; LFO Sample&Hold -> Pitch rate=11 depth=27 &middot; LFO2 off &middot; Arp Up rate=62 range=1oct (needs CC_ARPE on to hear) &middot; Bend range 2 &middot; Unison on detune=0/255

Notes: Arp defined but disabled in the source patch; CC_ARPE off by default; source uses OSC2/OSC3 too (multi-osc); only OSC1's timbre captured here. New in v2: LFO2 off (no second live-routed LFO found in the source); Unison on, detune=0/255 (from the source's OSC2/OSC3 detune spread, now usable as 3-voice unison instead of being discarded).

```
f0 50 20 10 01 04 07 03 0a 00 0f 08 00 07 00 03 05 00 00 0f 00 00 02 00 00 03 00 0b 01 0b 00 00 00 00 03 0e 00 00 00 02 00 00 00 00 00 00 00 00 00 01 00 00 f7
```

### 059 A stormy Day (Lead engine)

Noise [sync] &middot; A0 D0 S15 R10 &middot; Filter LP cutoff=64/2047 res=15/15 route=v1+v2+v3 &middot; LFO Sample&Hold -> Pitch rate=5 depth=64 &middot; LFO2 S&H -> Pitch rate=97 depth=64 &middot; Arp Up rate=62 range=1oct (needs CC_ARPE on to hear) &middot; Bend range 2 &middot; Unison on detune=60/255

Notes: Arp defined but disabled in the source patch; CC_ARPE off by default. New in v2: LFO2 sourced from a second live-routed MBSID LFO (S&H, rate=97, depth=64, -> Pitch); Unison on, detune=60/255 (from the source's OSC2/OSC3 detune spread, now usable as 3-voice unison instead of being discarded).

```
f0 50 20 10 08 02 00 00 0f 0a 00 00 00 08 00 00 04 00 00 0f 00 07 01 00 00 03 00 05 04 00 00 00 00 00 03 0e 00 00 00 02 00 03 06 01 04 00 00 00 00 01 03 0c f7
```

### 060 6 Octave Plug (Lead engine)

Pulse &middot; A0 D10 S0 R8 &middot; PWM 2048/4095 &middot; Filter LP+BP cutoff=0/2047 res=15/15 route=v1+v2+v3 &middot; LFO Triangle -> Pitch rate=70 depth=64 &middot; LFO2 off &middot; Arp Up rate=62 range=1oct (needs CC_ARPE on to hear) &middot; Bend range 2 &middot; Unison on detune=0/255

Notes: LFO1 Sine -> Triangle (no sine on real SID); Arp defined but disabled in the source patch; CC_ARPE off by default; source uses OSC2/OSC3 too (multi-osc); only OSC1's timbre captured here. New in v2: LFO2 off (no second live-routed LFO found in the source); Unison on, detune=0/255 (from the source's OSC2/OSC3 detune spread, now usable as 3-voice unison instead of being discarded).

```
f0 50 20 10 04 00 00 0a 00 08 00 00 00 08 00 00 00 00 00 0f 00 07 03 00 00 00 04 06 04 00 00 00 00 00 03 0e 00 00 00 02 00 00 00 00 00 00 00 00 00 01 00 00 f7
```

### 061 Poly Saw (Multi engine) - not converted

### 062 Step by Step (Lead engine)

Pulse &middot; A7 D7 S10 R4 &middot; PWM 2080/4095 &middot; Filter off &middot; LFO Triangle -> PWM rate=11 depth=64 &middot; LFO2 Triangle -> Pitch rate=70 depth=64 &middot; Arp Up rate=62 range=1oct (needs CC_ARPE on to hear) &middot; Bend range 2 &middot; Unison on detune=0/255

Notes: LFO1 Sine -> Triangle (no sine on real SID); Arp defined but disabled in the source patch; CC_ARPE off by default; source uses OSC2/OSC3 too (multi-osc); only OSC1's timbre captured here. New in v2: LFO2 sourced from a second live-routed MBSID LFO (Triangle, rate=70, depth=64, -> Pitch); Unison on, detune=0/255 (from the source's OSC2/OSC3 detune spread, now usable as 3-voice unison instead of being discarded).

```
f0 50 20 10 04 00 07 07 0a 04 02 00 00 08 00 04 00 00 00 00 00 00 00 00 00 00 00 0b 04 00 00 01 00 00 03 0e 00 00 00 02 00 00 04 06 04 00 00 00 00 01 00 00 f7
```

### 063 Slow Intro (Lead engine)

Pulse &middot; A0 D0 S12 R12 &middot; PWM 0/4095 &middot; Filter off &middot; LFO off &middot; LFO2 off &middot; Arp Up rate=62 range=1oct (needs CC_ARPE on to hear) &middot; Bend range 2 &middot; Unison on detune=14/255

Notes: Arp defined but disabled in the source patch; CC_ARPE off by default; source uses OSC2/OSC3 too (multi-osc); only OSC1's timbre captured here. New in v2: LFO2 off (no second live-routed LFO found in the source); Unison on, detune=14/255 (from the source's OSC2/OSC3 detune spread, now usable as 3-voice unison instead of being discarded).

```
f0 50 20 10 04 00 00 00 0c 0c 00 00 00 00 00 04 00 00 00 00 00 00 01 00 00 00 00 00 00 00 00 00 00 00 03 0e 00 00 00 02 00 00 00 00 00 00 00 00 00 01 00 0e f7
```

### 064 ARPSEQ One A (Lead engine)

Pulse &middot; A0 D0 S15 R0 &middot; PWM 1856/4095 &middot; Filter BP cutoff=514/2047 res=15/15 route=v1 &middot; LFO Triangle -> PWM rate=61 depth=64 &middot; LFO2 Triangle -> Cutoff rate=6 depth=64 &middot; Arp Up rate=62 range=1oct (needs CC_ARPE on to hear) &middot; Bend range 2 &middot; Unison on detune=10/255

Notes: LFO2 Sine -> Triangle (no sine on real SID); source modulation actually comes from LFO2, not LFO1 (this firmware has only one LFO per channel); Arp defined but disabled in the source patch; CC_ARPE off by default; source uses OSC2/OSC3 too (multi-osc); only OSC1's timbre captured here. New in v2: LFO2 sourced from a second live-routed MBSID LFO (Triangle, rate=6, depth=64, -> Cutoff); Unison on, detune=10/255 (from the source's OSC2/OSC3 detune spread, now usable as 3-voice unison instead of being discarded).

```
f0 50 20 10 04 00 00 00 0f 00 04 00 00 07 00 02 00 02 00 0f 00 01 02 00 00 00 03 0d 04 00 00 01 00 00 03 0e 00 00 00 02 00 00 00 06 04 00 00 02 00 01 00 0a f7
```

### 065 ARPSEQ One B (Lead engine)

Pulse &middot; A0 D0 S15 R0 &middot; PWM 1856/4095 &middot; Filter BP cutoff=515/2047 res=15/15 route=v1 &middot; LFO Triangle -> PWM rate=61 depth=64 &middot; LFO2 Triangle -> Cutoff rate=6 depth=64 &middot; Arp Up rate=62 range=1oct (needs CC_ARPE on to hear) &middot; Bend range 2 &middot; Unison on detune=10/255

Notes: LFO2 Sine -> Triangle (no sine on real SID); source modulation actually comes from LFO2, not LFO1 (this firmware has only one LFO per channel); Arp defined but disabled in the source patch; CC_ARPE off by default; source uses OSC2/OSC3 too (multi-osc); only OSC1's timbre captured here. New in v2: LFO2 sourced from a second live-routed MBSID LFO (Triangle, rate=6, depth=64, -> Cutoff); Unison on, detune=10/255 (from the source's OSC2/OSC3 detune spread, now usable as 3-voice unison instead of being discarded).

```
f0 50 20 10 04 00 00 00 0f 00 04 00 00 07 00 02 00 03 00 0f 00 01 02 00 00 00 03 0d 04 00 00 01 00 00 03 0e 00 00 00 02 00 00 00 06 04 00 00 02 00 01 00 0a f7
```

### 066 ARPSEQ One C (Lead engine)

Pulse &middot; A0 D0 S15 R0 &middot; PWM 1856/4095 &middot; Filter BP cutoff=467/2047 res=15/15 route=v1 &middot; LFO Triangle -> PWM rate=61 depth=64 &middot; LFO2 Triangle -> Cutoff rate=6 depth=64 &middot; Arp Up rate=62 range=1oct (needs CC_ARPE on to hear) &middot; Bend range 2 &middot; Unison on detune=10/255

Notes: LFO2 Sine -> Triangle (no sine on real SID); source modulation actually comes from LFO2, not LFO1 (this firmware has only one LFO per channel); Arp defined but disabled in the source patch; CC_ARPE off by default; source uses OSC2/OSC3 too (multi-osc); only OSC1's timbre captured here. New in v2: LFO2 sourced from a second live-routed MBSID LFO (Triangle, rate=6, depth=64, -> Cutoff); Unison on, detune=10/255 (from the source's OSC2/OSC3 detune spread, now usable as 3-voice unison instead of being discarded).

```
f0 50 20 10 04 00 00 00 0f 00 04 00 00 07 00 01 0d 03 00 0f 00 01 02 00 00 00 03 0d 04 00 00 01 00 00 03 0e 00 00 00 02 00 00 00 06 04 00 00 02 00 01 00 0a f7
```

### 067 SEQ TranceBass (Lead engine)

Pulse &middot; A0 D0 S15 R10 &middot; PWM 2080/4095 &middot; Filter LP+BP cutoff=91/2047 res=15/15 route=v1+v2 &middot; LFO off &middot; LFO2 off &middot; Arp Up rate=62 range=1oct (needs CC_ARPE on to hear) &middot; Bend range 2 &middot; Unison off

Notes: Arp defined but disabled in the source patch; CC_ARPE off by default; source uses OSC2/OSC3 too (multi-osc); only OSC1's timbre captured here. New in v2: LFO2 off (no second live-routed LFO found in the source); Unison off (source uses only OSC1).

```
f0 50 20 10 04 00 00 00 0f 0a 02 00 00 08 00 00 05 0b 00 0f 00 03 03 00 00 00 00 00 00 00 00 00 00 00 03 0e 00 00 00 02 00 00 00 00 00 00 00 00 00 00 00 00 f7
```

### 068 SEQ Vintage A (Lead engine)

Sawtooth &middot; A0 D1 S13 R11 &middot; Filter off &middot; LFO off &middot; LFO2 off &middot; Arp Up rate=62 range=1oct (needs CC_ARPE on to hear) &middot; Bend range 2 &middot; Unison off

Notes: Arp defined but disabled in the source patch; CC_ARPE off by default; source uses OSC2/OSC3 too (multi-osc); only OSC1's timbre captured here. New in v2: LFO2 off (no second live-routed LFO found in the source); Unison off (source uses only OSC1).

```
f0 50 20 10 02 00 00 01 0d 0b 00 00 00 08 00 00 07 00 00 0f 00 00 01 00 00 00 00 00 00 00 00 00 00 00 03 0e 00 00 00 02 00 00 00 00 00 00 00 00 00 00 00 00 f7
```

### 069 SEQ Vintage B (Lead engine)

Sawtooth &middot; A0 D2 S13 R11 &middot; Filter off &middot; LFO off &middot; LFO2 off &middot; Arp Up rate=62 range=1oct (needs CC_ARPE on to hear) &middot; Bend range 2 &middot; Unison on detune=10/255

Notes: Arp defined but disabled in the source patch; CC_ARPE off by default; source uses OSC2/OSC3 too (multi-osc); only OSC1's timbre captured here. New in v2: LFO2 off (no second live-routed LFO found in the source); Unison on, detune=10/255 (from the source's OSC2/OSC3 detune spread, now usable as 3-voice unison instead of being discarded).

```
f0 50 20 10 02 00 00 02 0d 0b 00 00 00 08 00 00 07 00 00 0f 00 00 01 00 00 00 00 00 00 00 00 00 00 00 03 0e 00 00 00 02 00 00 00 00 00 00 00 00 00 01 00 0a f7
```

### 070 SEQ Vintage C (Lead engine)

Sawtooth &middot; A0 D2 S12 R11 &middot; Filter BP+HP cutoff=720/2047 res=15/15 route=v2+v3 &middot; LFO Triangle -> Cutoff rate=3 depth=64 &middot; LFO2 off &middot; Arp Up rate=62 range=1oct (needs CC_ARPE on to hear) &middot; Bend range 2 &middot; Unison on detune=10/255

Notes: LFO2 Sine -> Triangle (no sine on real SID); source modulation actually comes from LFO2, not LFO1 (this firmware has only one LFO per channel); Arp defined but disabled in the source patch; CC_ARPE off by default; source uses OSC2/OSC3 too (multi-osc); only OSC1's timbre captured here. New in v2: LFO2 off (no second live-routed LFO found in the source); Unison on, detune=10/255 (from the source's OSC2/OSC3 detune spread, now usable as 3-voice unison instead of being discarded).

```
f0 50 20 10 02 00 00 02 0c 0b 00 00 00 08 00 02 0d 00 00 0f 00 06 06 00 00 00 00 03 04 00 00 02 00 00 03 0e 00 00 00 02 00 00 00 00 00 00 00 00 00 01 00 0a f7
```

### 071 ARPSEQ Two A (Lead engine)

Pulse &middot; A0 D0 S15 R0 &middot; PWM 1344/4095 &middot; Filter LP cutoff=80/2047 res=15/15 route=v1 &middot; LFO Triangle -> PWM rate=38 depth=64 &middot; LFO2 Triangle -> Cutoff rate=39 depth=64 &middot; Arp Up rate=62 range=1oct (needs CC_ARPE on to hear) &middot; Bend range 2 &middot; Unison on detune=0/255

Notes: LFO1 Sine -> Triangle (no sine on real SID); Arp defined but disabled in the source patch; CC_ARPE off by default; source uses OSC2/OSC3 too (multi-osc); only OSC1's timbre captured here. New in v2: LFO2 sourced from a second live-routed MBSID LFO (Triangle, rate=39, depth=64, -> Cutoff); Unison on, detune=0/255 (from the source's OSC2/OSC3 detune spread, now usable as 3-voice unison instead of being discarded).

```
f0 50 20 10 04 00 00 00 0f 00 04 00 00 05 00 00 05 00 00 0f 00 01 01 00 00 00 02 06 04 00 00 01 00 00 03 0e 00 00 00 02 00 00 02 07 04 00 00 02 00 01 00 00 f7
```

### 072 ARPSEQ Two B (Lead engine)

Pulse &middot; A0 D0 S15 R0 &middot; PWM 1344/4095 &middot; Filter LP cutoff=80/2047 res=15/15 route=v1 &middot; LFO Triangle -> PWM rate=38 depth=64 &middot; LFO2 Triangle -> Cutoff rate=39 depth=64 &middot; Arp Up rate=62 range=1oct (needs CC_ARPE on to hear) &middot; Bend range 2 &middot; Unison on detune=0/255

Notes: LFO1 Sine -> Triangle (no sine on real SID); Arp defined but disabled in the source patch; CC_ARPE off by default; source uses OSC2/OSC3 too (multi-osc); only OSC1's timbre captured here. New in v2: LFO2 sourced from a second live-routed MBSID LFO (Triangle, rate=39, depth=64, -> Cutoff); Unison on, detune=0/255 (from the source's OSC2/OSC3 detune spread, now usable as 3-voice unison instead of being discarded).

```
f0 50 20 10 04 00 00 00 0f 00 04 00 00 05 00 00 05 00 00 0f 00 01 01 00 00 00 02 06 04 00 00 01 00 00 03 0e 00 00 00 02 00 00 02 07 04 00 00 02 00 01 00 00 f7
```

### 073 ARPSEQ Two C (Lead engine)

Pulse &middot; A0 D0 S15 R0 &middot; PWM 1344/4095 &middot; Filter LP cutoff=80/2047 res=15/15 route=v1 &middot; LFO Triangle -> PWM rate=38 depth=64 &middot; LFO2 Triangle -> Cutoff rate=39 depth=64 &middot; Arp Up rate=62 range=1oct (needs CC_ARPE on to hear) &middot; Bend range 2 &middot; Unison on detune=0/255

Notes: LFO1 Sine -> Triangle (no sine on real SID); Arp defined but disabled in the source patch; CC_ARPE off by default; source uses OSC2/OSC3 too (multi-osc); only OSC1's timbre captured here. New in v2: LFO2 sourced from a second live-routed MBSID LFO (Triangle, rate=39, depth=64, -> Cutoff); Unison on, detune=0/255 (from the source's OSC2/OSC3 detune spread, now usable as 3-voice unison instead of being discarded).

```
f0 50 20 10 04 00 00 00 0f 00 04 00 00 05 00 00 05 00 00 0f 00 01 01 00 00 00 02 06 04 00 00 01 00 00 03 0e 00 00 00 02 00 00 02 07 04 00 00 02 00 01 00 00 f7
```

### 074 ARPSEQ Three (Lead engine)

Pulse &middot; A0 D0 S15 R2 &middot; PWM 1344/4095 &middot; Filter off &middot; LFO Triangle -> PWM rate=38 depth=64 &middot; LFO2 off &middot; Arp Up rate=62 range=1oct (needs CC_ARPE on to hear) &middot; Bend range 2 &middot; Unison on detune=18/255

Notes: LFO1 Sine -> Triangle (no sine on real SID); Arp defined but disabled in the source patch; CC_ARPE off by default; source uses OSC2/OSC3 too (multi-osc); only OSC1's timbre captured here. New in v2: LFO2 off (no second live-routed LFO found in the source); Unison on, detune=18/255 (from the source's OSC2/OSC3 detune spread, now usable as 3-voice unison instead of being discarded).

```
f0 50 20 10 04 00 00 00 0f 02 04 00 00 05 00 01 06 00 00 0f 00 00 00 00 00 00 02 06 04 00 00 01 00 00 03 0e 00 00 00 02 00 00 00 00 00 00 00 00 00 01 01 02 f7
```

### 075 ARPSEQ Four (Lead engine)

Sawtooth &middot; A0 D8 S9 R4 &middot; Filter LP+BP+HP cutoff=488/2047 res=15/15 route=v1+v2+v3 &middot; LFO Triangle -> Cutoff rate=124 depth=64 &middot; LFO2 off &middot; Arp Up rate=62 range=1oct (needs CC_ARPE on to hear) &middot; Bend range 2 &middot; Unison on detune=2/255

Notes: LFO1 Sine -> Triangle (no sine on real SID); Arp defined but disabled in the source patch; CC_ARPE off by default; source uses OSC2/OSC3 too (multi-osc); only OSC1's timbre captured here. New in v2: LFO2 off (no second live-routed LFO found in the source); Unison on, detune=2/255 (from the source's OSC2/OSC3 detune spread, now usable as 3-voice unison instead of being discarded).

```
f0 50 20 10 02 00 00 08 09 04 00 00 00 08 00 01 0e 08 00 0f 00 07 07 00 00 00 07 0c 04 00 00 02 00 00 03 0e 00 00 00 02 00 00 00 00 00 00 00 00 00 01 00 02 f7
```

### 076 SEQ Mighty Bass (Lead engine)

Sawtooth &middot; A0 D2 S12 R11 &middot; Filter LP+BP cutoff=234/2047 res=15/15 route=v1+v2+v3 &middot; LFO off &middot; LFO2 off &middot; Arp Up rate=62 range=1oct (needs CC_ARPE on to hear) &middot; Bend range 2 &middot; Unison on detune=0/255

Notes: Arp defined but disabled in the source patch; CC_ARPE off by default; source uses OSC2/OSC3 too (multi-osc); only OSC1's timbre captured here. New in v2: LFO2 off (no second live-routed LFO found in the source); Unison on, detune=0/255 (from the source's OSC2/OSC3 detune spread, now usable as 3-voice unison instead of being discarded).

```
f0 50 20 10 02 00 00 02 0c 0b 04 00 00 07 00 00 0e 0a 00 0f 00 07 03 00 00 00 00 00 00 00 00 00 00 00 03 0e 00 00 00 02 00 00 00 00 00 00 00 00 00 01 00 00 f7
```

### 077 Analog Dream1 (Lead engine)

(no waveform) &middot; A1 D0 S15 R0 &middot; Filter off &middot; LFO off &middot; LFO2 off &middot; Arp Up rate=62 range=1oct (needs CC_ARPE on to hear) &middot; Bend range 2 &middot; Unison on detune=5/255

Notes: Arp defined but disabled in the source patch; CC_ARPE off by default; OSC1 'Disable Oscillator' flag was set in source; kept waveform bits anyway; source uses OSC2/OSC3 too (multi-osc); only OSC1's timbre captured here. New in v2: LFO2 off (no second live-routed LFO found in the source); Unison on, detune=5/255 (from the source's OSC2/OSC3 detune spread, now usable as 3-voice unison instead of being discarded).

```
f0 50 20 10 00 00 01 00 0f 00 02 00 00 02 00 00 00 00 00 0f 00 00 01 00 00 00 00 00 00 00 00 00 00 00 03 0e 00 00 00 02 00 00 00 00 00 00 00 00 00 01 00 05 f7
```

### 078 Analog Dream2 (Lead engine)

Pulse &middot; A0 D0 S15 R8 &middot; PWM 1312/4095 &middot; Filter off &middot; LFO off &middot; LFO2 off &middot; Arp Up rate=62 range=1oct (needs CC_ARPE on to hear) &middot; Bend range 2 &middot; Unison on detune=2/255

Notes: Arp defined but disabled in the source patch; CC_ARPE off by default; source uses OSC2/OSC3 too (multi-osc); only OSC1's timbre captured here. New in v2: LFO2 off (no second live-routed LFO found in the source); Unison on, detune=2/255 (from the source's OSC2/OSC3 detune spread, now usable as 3-voice unison instead of being discarded).

```
f0 50 20 10 04 00 00 00 0f 08 02 00 00 05 00 07 0f 00 00 00 00 00 00 00 00 00 00 00 00 00 00 00 00 00 03 0e 00 00 00 02 00 00 00 00 00 00 00 00 00 01 00 02 f7
```

### 079 Analog Dream3 (Lead engine)

Pulse &middot; A2 D15 S4 R6 &middot; PWM 800/4095 &middot; Filter LP cutoff=1184/2047 res=0/15 route=v1+v2+v3 &middot; LFO Triangle -> PWM rate=52 depth=64 &middot; LFO2 off &middot; Arp Up rate=62 range=1oct (needs CC_ARPE on to hear) &middot; Bend range 2 &middot; Unison off

Notes: LFO1 Sine -> Triangle (no sine on real SID); Arp defined but disabled in the source patch; CC_ARPE off by default. New in v2: LFO2 off (no second live-routed LFO found in the source); Unison off (source uses only OSC1).

```
f0 50 20 10 04 00 02 0f 04 06 02 00 00 03 00 04 0a 00 00 00 00 07 01 00 00 00 03 04 04 00 00 01 00 00 03 0e 00 00 00 02 00 00 00 00 00 00 00 00 00 00 00 00 f7
```

### 080 Analog Dream4 (Lead engine)

Pulse [ring] &middot; A0 D0 S15 R9 &middot; PWM 32/4095 &middot; Filter LP cutoff=992/2047 res=7/15 route=v1+v2+v3 &middot; LFO Triangle -> Cutoff rate=5 depth=64 &middot; LFO2 Triangle -> Cutoff rate=11 depth=64 &middot; Arp Up rate=30 range=1oct (needs CC_ARPE on to hear) &middot; Bend range 2 &middot; Unison on detune=0/255

Notes: LFO1 Sine -> Triangle (no sine on real SID); source uses OSC2/OSC3 too (multi-osc); only OSC1's timbre captured here. New in v2: LFO2 sourced from a second live-routed MBSID LFO (Triangle, rate=11, depth=64, -> Cutoff); Unison on, detune=0/255 (from the source's OSC2/OSC3 detune spread, now usable as 3-voice unison instead of being discarded).

```
f0 50 20 10 04 04 00 00 0f 09 02 00 00 00 00 03 0e 00 00 07 00 07 01 00 00 00 00 05 04 00 00 02 00 00 01 0e 00 00 00 02 00 00 00 0b 04 00 00 02 00 01 00 00 f7
```

### 081 Analog Dream5 (Lead engine)

Pulse &middot; A2 D15 S7 R6 &middot; PWM 800/4095 &middot; Filter LP cutoff=1421/2047 res=6/15 route=v1+v2+v3 &middot; LFO Triangle -> PWM rate=52 depth=64 &middot; LFO2 off &middot; Arp Up rate=62 range=1oct (needs CC_ARPE on to hear) &middot; Bend range 2 &middot; Unison off

Notes: LFO1 Sine -> Triangle (no sine on real SID); Arp defined but disabled in the source patch; CC_ARPE off by default. New in v2: LFO2 off (no second live-routed LFO found in the source); Unison off (source uses only OSC1).

```
f0 50 20 10 04 00 02 0f 07 06 02 00 00 03 00 05 08 0d 00 06 00 07 01 00 00 00 03 04 04 00 00 01 00 00 03 0e 00 00 00 02 00 00 00 00 00 00 00 00 00 00 00 00 f7
```

### 082 PWM Bass1 (Lead engine)

Pulse &middot; A0 D0 S15 R0 &middot; PWM 2048/4095 &middot; Filter off &middot; LFO Triangle -> PWM rate=36 depth=64 &middot; LFO2 Triangle -> PWM rate=22 depth=64 &middot; Arp Up rate=62 range=1oct (needs CC_ARPE on to hear) &middot; Bend range 2 &middot; Unison on detune=16/255

Notes: LFO1 Sine -> Triangle (no sine on real SID); Arp defined but disabled in the source patch; CC_ARPE off by default; source uses OSC2/OSC3 too (multi-osc); only OSC1's timbre captured here. New in v2: LFO2 sourced from a second live-routed MBSID LFO (Triangle, rate=22, depth=64, -> PWM); Unison on, detune=16/255 (from the source's OSC2/OSC3 detune spread, now usable as 3-voice unison instead of being discarded).

```
f0 50 20 10 04 00 00 00 0f 00 00 00 00 08 00 00 01 00 00 0f 00 00 00 00 00 00 02 04 04 00 00 01 00 00 03 0e 00 00 00 02 00 00 01 06 04 00 00 01 00 01 01 00 f7
```

### 083 PWM Bass2 (Lead engine)

Sawtooth &middot; A0 D11 S4 R11 &middot; Filter off &middot; LFO off &middot; LFO2 off &middot; Arp Up rate=62 range=1oct (needs CC_ARPE on to hear) &middot; Bend range 2 &middot; Unison on detune=11/255

Notes: Arp defined but disabled in the source patch; CC_ARPE off by default; source uses OSC2/OSC3 too (multi-osc); only OSC1's timbre captured here. New in v2: LFO2 off (no second live-routed LFO found in the source); Unison on, detune=11/255 (from the source's OSC2/OSC3 detune spread, now usable as 3-voice unison instead of being discarded).

```
f0 50 20 10 02 00 00 0b 04 0b 02 00 00 05 00 00 00 00 00 00 00 00 04 00 00 00 00 00 00 00 00 00 00 00 03 0e 00 00 00 02 00 00 00 00 00 00 00 00 00 01 00 0b f7
```

### 084 PWM Bass3 (Lead engine)

Pulse &middot; A0 D11 S5 R0 &middot; PWM 2048/4095 &middot; Filter LP cutoff=176/2047 res=2/15 route=v1+v2+v3 &middot; LFO Triangle -> PWM rate=35 depth=64 &middot; LFO2 off &middot; Arp Up rate=62 range=1oct (needs CC_ARPE on to hear) &middot; Bend range 2 &middot; Unison off

Notes: LFO1 Sine -> Triangle (no sine on real SID); Arp defined but disabled in the source patch; CC_ARPE off by default. New in v2: LFO2 off (no second live-routed LFO found in the source); Unison off (source uses only OSC1).

```
f0 50 20 10 04 00 00 0b 05 00 00 00 00 08 00 00 0b 00 00 02 00 07 01 00 00 00 02 03 04 00 00 01 00 00 03 0e 00 00 00 02 00 00 00 00 00 00 00 00 00 00 00 00 f7
```

### 085 PWM Bass4 (Lead engine)

Pulse &middot; A0 D0 S15 R0 &middot; PWM 1312/4095 &middot; Filter LP cutoff=1331/2047 res=15/15 route=v1+v2+v3 &middot; LFO Triangle -> Cutoff rate=4 depth=64 &middot; LFO2 off &middot; Arp Up rate=62 range=1oct (needs CC_ARPE on to hear) &middot; Bend range 2 &middot; Unison on detune=15/255

Notes: LFO1 Sine -> Triangle (no sine on real SID); Arp defined but disabled in the source patch; CC_ARPE off by default; source uses OSC2/OSC3 too (multi-osc); only OSC1's timbre captured here. New in v2: LFO2 off (no second live-routed LFO found in the source); Unison on, detune=15/255 (from the source's OSC2/OSC3 detune spread, now usable as 3-voice unison instead of being discarded).

```
f0 50 20 10 04 00 00 00 0f 00 02 00 00 05 00 05 03 03 00 0f 00 07 01 00 00 00 00 04 04 00 00 02 00 00 03 0e 00 00 00 02 00 00 00 00 00 00 00 00 00 01 00 0f f7
```

### 086 Seq Bass1 (Lead engine)

Sawtooth &middot; A1 D0 S15 R0 &middot; Filter LP cutoff=124/2047 res=6/15 route=v1+v2+v3 &middot; LFO Triangle -> Pitch rate=71 depth=64 &middot; LFO2 off &middot; Arp Up rate=62 range=1oct (needs CC_ARPE on to hear) &middot; Bend range 2 &middot; Unison on detune=0/255

Notes: LFO2 Sine -> Triangle (no sine on real SID); source modulation actually comes from LFO2, not LFO1 (this firmware has only one LFO per channel); Arp defined but disabled in the source patch; CC_ARPE off by default; source uses OSC2/OSC3 too (multi-osc); only OSC1's timbre captured here. New in v2: LFO2 off (no second live-routed LFO found in the source); Unison on, detune=0/255 (from the source's OSC2/OSC3 detune spread, now usable as 3-voice unison instead of being discarded).

```
f0 50 20 10 02 00 01 00 0f 00 02 00 00 02 00 00 07 0c 00 06 00 07 01 00 00 00 04 07 04 00 00 00 00 00 03 0e 00 00 00 02 00 00 00 00 00 00 00 00 00 01 00 00 f7
```

### 087 Seq Bass2 (Lead engine)

Pulse &middot; A0 D11 S5 R0 &middot; PWM 2048/4095 &middot; Filter LP cutoff=0/2047 res=2/15 route=v1+v2+v3 &middot; LFO Triangle -> PWM rate=20 depth=127 &middot; LFO2 off &middot; Arp Up rate=62 range=1oct (needs CC_ARPE on to hear) &middot; Bend range 2 &middot; Unison on detune=0/255

Notes: LFO1 Sine -> Triangle (no sine on real SID); Arp defined but disabled in the source patch; CC_ARPE off by default; source uses OSC2/OSC3 too (multi-osc); only OSC1's timbre captured here. New in v2: LFO2 off (no second live-routed LFO found in the source); Unison on, detune=0/255 (from the source's OSC2/OSC3 detune spread, now usable as 3-voice unison instead of being discarded).

```
f0 50 20 10 04 00 00 0b 05 00 00 00 00 08 00 00 00 00 00 02 00 07 01 00 00 00 01 04 07 0f 00 01 00 00 03 0e 00 00 00 02 00 00 00 00 00 00 00 00 00 01 00 00 f7
```

### 088 Seq Bass3 (Lead engine)

Sawtooth &middot; A0 D12 S4 R11 &middot; Filter LP cutoff=992/2047 res=15/15 route=v1 &middot; LFO off &middot; LFO2 off &middot; Arp Up rate=62 range=1oct (needs CC_ARPE on to hear) &middot; Bend range 2 &middot; Unison off

Notes: Arp defined but disabled in the source patch; CC_ARPE off by default. New in v2: LFO2 off (no second live-routed LFO found in the source); Unison off (source uses only OSC1).

```
f0 50 20 10 02 00 00 0c 04 0b 06 00 00 05 00 03 0e 00 00 0f 00 01 01 00 00 00 00 00 00 00 00 00 00 00 03 0e 00 00 00 02 00 00 00 00 00 00 00 00 00 00 00 00 f7
```

### 089 Seq Bass4 (Lead engine)

Triangle+Pulse &middot; A0 D0 S10 R0 &middot; PWM 2048/4095 &middot; Filter LP+BP cutoff=0/2047 res=15/15 route=v1+v2+v3 &middot; LFO off &middot; LFO2 off &middot; Arp Up rate=62 range=1oct (needs CC_ARPE on to hear) &middot; Bend range 2 &middot; Unison on detune=0/255

Notes: Arp defined but disabled in the source patch; CC_ARPE off by default; source uses OSC2/OSC3 too (multi-osc); only OSC1's timbre captured here. New in v2: LFO2 off (no second live-routed LFO found in the source); Unison on, detune=0/255 (from the source's OSC2/OSC3 detune spread, now usable as 3-voice unison instead of being discarded).

```
f0 50 20 10 05 00 00 00 0a 00 00 00 00 08 00 00 00 00 00 0f 00 07 03 00 00 00 00 00 00 00 00 00 00 00 03 0e 00 00 00 02 00 00 00 00 00 00 00 00 00 01 00 00 f7
```

### 090 Seq Bass5 (Lead engine)

Triangle+Pulse &middot; A0 D0 S10 R0 &middot; PWM 2048/4095 &middot; Filter LP+BP cutoff=0/2047 res=15/15 route=v1+v2+v3 &middot; LFO off &middot; LFO2 off &middot; Arp Up rate=62 range=1oct (needs CC_ARPE on to hear) &middot; Bend range 2 &middot; Unison on detune=9/255

Notes: Arp defined but disabled in the source patch; CC_ARPE off by default; source uses OSC2/OSC3 too (multi-osc); only OSC1's timbre captured here. New in v2: LFO2 off (no second live-routed LFO found in the source); Unison on, detune=9/255 (from the source's OSC2/OSC3 detune spread, now usable as 3-voice unison instead of being discarded).

```
f0 50 20 10 05 00 00 00 0a 00 00 00 00 08 00 00 00 00 00 0f 00 07 03 00 00 00 00 00 00 00 00 00 00 00 03 0e 00 00 00 02 00 00 00 00 00 00 00 00 00 01 00 09 f7
```

### 091 Seq Bass6 (Lead engine)

Triangle+Pulse &middot; A0 D0 S10 R0 &middot; PWM 2048/4095 &middot; Filter LP+BP cutoff=0/2047 res=15/15 route=v1+v2+v3 &middot; LFO off &middot; LFO2 off &middot; Arp Up rate=62 range=1oct (needs CC_ARPE on to hear) &middot; Bend range 2 &middot; Unison on detune=0/255

Notes: Arp defined but disabled in the source patch; CC_ARPE off by default; source uses OSC2/OSC3 too (multi-osc); only OSC1's timbre captured here. New in v2: LFO2 off (no second live-routed LFO found in the source); Unison on, detune=0/255 (from the source's OSC2/OSC3 detune spread, now usable as 3-voice unison instead of being discarded).

```
f0 50 20 10 05 00 00 00 0a 00 00 00 00 08 00 00 00 00 00 0f 00 07 03 00 00 00 00 00 00 00 00 00 00 00 03 0e 00 00 00 02 00 00 00 00 00 00 00 00 00 01 00 00 f7
```

### 092 Monty Bass1 (Lead engine)

Sawtooth &middot; A0 D0 S15 R0 &middot; Filter off &middot; LFO off &middot; LFO2 off &middot; Arp Up rate=62 range=1oct (needs CC_ARPE on to hear) &middot; Bend range 2 &middot; Unison off

Notes: Arp defined but disabled in the source patch; CC_ARPE off by default; source uses OSC2/OSC3 too (multi-osc); only OSC1's timbre captured here. New in v2: LFO2 off (no second live-routed LFO found in the source); Unison off (source uses only OSC1).

```
f0 50 20 10 02 00 00 00 0f 00 00 00 00 08 00 04 00 00 00 00 00 00 01 00 00 00 00 00 00 00 00 00 00 00 03 0e 00 00 00 02 00 00 00 00 00 00 00 00 00 00 00 00 f7
```

### 093 Monty Bass2 (Lead engine)

Pulse &middot; A0 D0 S15 R0 &middot; PWM 2400/4095 &middot; Filter LP cutoff=400/2047 res=10/15 route=v1+v2+v3 &middot; LFO Triangle -> PWM rate=33 depth=64 &middot; LFO2 off &middot; Arp Up rate=62 range=1oct (needs CC_ARPE on to hear) &middot; Bend range 2 &middot; Unison on detune=5/255

Notes: LFO1 Sine -> Triangle (no sine on real SID); Arp defined but disabled in the source patch; CC_ARPE off by default; source uses OSC2/OSC3 too (multi-osc); only OSC1's timbre captured here. New in v2: LFO2 off (no second live-routed LFO found in the source); Unison on, detune=5/255 (from the source's OSC2/OSC3 detune spread, now usable as 3-voice unison instead of being discarded).

```
f0 50 20 10 04 00 00 00 0f 00 06 00 00 09 00 01 09 00 00 0a 00 07 01 00 00 00 02 01 04 00 00 01 00 00 03 0e 00 00 00 02 00 00 00 00 00 00 00 00 00 01 00 05 f7
```

### 094 Monty Bass3 (Lead engine)

Pulse &middot; A0 D0 S15 R0 &middot; PWM 1344/4095 &middot; Filter LP cutoff=336/2047 res=15/15 route=v1+v2+v3 &middot; LFO Triangle -> PWM rate=68 depth=64 &middot; LFO2 Triangle -> Cutoff rate=2 depth=64 &middot; Arp Up rate=62 range=1oct (needs CC_ARPE on to hear) &middot; Bend range 2 &middot; Unison on detune=3/255

Notes: LFO1 Sine -> Triangle (no sine on real SID); Arp defined but disabled in the source patch; CC_ARPE off by default; source uses OSC2/OSC3 too (multi-osc); only OSC1's timbre captured here. New in v2: LFO2 sourced from a second live-routed MBSID LFO (Triangle, rate=2, depth=64, -> Cutoff); Unison on, detune=3/255 (from the source's OSC2/OSC3 detune spread, now usable as 3-voice unison instead of being discarded).

```
f0 50 20 10 04 00 00 00 0f 00 04 00 00 05 00 01 05 00 00 0f 00 07 01 00 00 00 04 04 04 00 00 01 00 00 03 0e 00 00 00 02 00 00 00 02 04 00 00 02 00 01 00 03 f7
```

### 095 Monty Lead1 (Lead engine)

Pulse &middot; A2 D15 S4 R6 &middot; PWM 256/4095 &middot; Filter off &middot; LFO Triangle -> PWM rate=52 depth=64 &middot; LFO2 off &middot; Arp Up rate=62 range=1oct (needs CC_ARPE on to hear) &middot; Bend range 2 &middot; Unison off

Notes: LFO1 Sine -> Triangle (no sine on real SID); Arp defined but disabled in the source patch; CC_ARPE off by default. New in v2: LFO2 off (no second live-routed LFO found in the source); Unison off (source uses only OSC1).

```
f0 50 20 10 04 00 02 0f 04 06 00 00 00 01 00 01 0a 00 00 0f 00 00 00 00 00 00 03 04 04 00 00 01 00 00 03 0e 00 00 00 02 00 00 00 00 00 00 00 00 00 00 00 00 f7
```

### 096 Monty Lead2 (Lead engine)

Pulse &middot; A2 D15 S4 R6 &middot; PWM 256/4095 &middot; Filter off &middot; LFO Triangle -> PWM rate=74 depth=64 &middot; LFO2 Triangle -> Pitch rate=78 depth=64 &middot; Arp Up rate=62 range=1oct (needs CC_ARPE on to hear) &middot; Bend range 2 &middot; Unison on detune=3/255

Notes: LFO1 Sine -> Triangle (no sine on real SID); Arp defined but disabled in the source patch; CC_ARPE off by default; source uses OSC2/OSC3 too (multi-osc); only OSC1's timbre captured here. New in v2: LFO2 sourced from a second live-routed MBSID LFO (Triangle, rate=78, depth=64, -> Pitch); Unison on, detune=3/255 (from the source's OSC2/OSC3 detune spread, now usable as 3-voice unison instead of being discarded).

```
f0 50 20 10 04 00 02 0f 04 06 00 00 00 01 00 01 0a 00 00 0f 00 00 00 00 00 00 04 0a 04 00 00 01 00 00 03 0e 00 00 00 02 00 00 04 0e 04 00 00 00 00 01 00 03 f7
```

### 097 Monty Lead3 (Lead engine)

Pulse [sync] &middot; A2 D15 S4 R6 &middot; PWM 512/4095 &middot; Filter off &middot; LFO Triangle -> Pitch rate=47 depth=100 &middot; LFO2 off &middot; Arp Up rate=62 range=1oct (needs CC_ARPE on to hear) &middot; Bend range 2 &middot; Unison on detune=0/255

Notes: LFO1 Sine -> Triangle (no sine on real SID); Arp defined but disabled in the source patch; CC_ARPE off by default; source uses OSC2/OSC3 too (multi-osc); only OSC1's timbre captured here. New in v2: LFO2 off (no second live-routed LFO found in the source); Unison on, detune=0/255 (from the source's OSC2/OSC3 detune spread, now usable as 3-voice unison instead of being discarded).

```
f0 50 20 10 04 02 02 0f 04 06 00 00 00 02 00 01 0a 00 00 0f 00 00 00 00 00 00 02 0f 06 04 00 00 00 00 03 0e 00 00 00 02 00 00 00 00 00 00 00 00 00 01 00 00 f7
```

### 098 Monty Lead4 (Lead engine)

Pulse &middot; A2 D15 S4 R6 &middot; PWM 1568/4095 &middot; Filter off &middot; LFO Triangle -> Pitch rate=78 depth=97 &middot; LFO2 Triangle -> PWM rate=74 depth=64 &middot; Arp Up rate=62 range=1oct (needs CC_ARPE on to hear) &middot; Bend range 2 &middot; Unison on detune=9/255

Notes: LFO2 Sine -> Triangle (no sine on real SID); source modulation actually comes from LFO2, not LFO1 (this firmware has only one LFO per channel); Arp defined but disabled in the source patch; CC_ARPE off by default; source uses OSC2/OSC3 too (multi-osc); only OSC1's timbre captured here. New in v2: LFO2 sourced from a second live-routed MBSID LFO (Triangle, rate=74, depth=64, -> PWM); Unison on, detune=9/255 (from the source's OSC2/OSC3 detune spread, now usable as 3-voice unison instead of being discarded).

```
f0 50 20 10 04 00 02 0f 04 06 02 00 00 06 00 01 0a 00 00 0f 00 00 00 00 00 00 04 0e 06 01 00 00 00 00 03 0e 00 00 00 02 00 00 04 0a 04 00 00 01 00 01 00 09 f7
```

### 099 Bassline Demo1 (Bassline engine)

Pulse &middot; A0 D2 S0 R1 &middot; PWM 2304/4095 &middot; Filter LP cutoff=192/2047 res=15/15 route=v1+v2+v3 &middot; LFO Triangle -> Pitch rate=54 depth=127 &middot; LFO2 Triangle -> Pitch rate=26 depth=127 &middot; Arp Up rate=62 range=1oct (needs CC_ARPE on to hear) &middot; Bend range 2 &middot; Unison off

Notes: Sine -> Triangle (no sine on real SID); Arp defined but disabled in the source patch; CC_ARPE off by default; Bassline engine's envelope is separate from OSC1's voice ADSR; using the engine envelope (scaled 8bit->4bit), not v1's own ADSR bytes. New in v2: LFO2 sourced from a second live-routed MBSID LFO (Triangle, rate=26, depth=127, -> Pitch); Unison off (source uses only OSC1).

```
f0 50 20 10 04 00 00 02 00 01 00 00 00 09 00 00 0c 00 00 0f 00 07 01 00 00 00 03 06 07 0f 00 00 00 00 03 0e 00 00 00 02 00 00 01 0a 07 0f 00 00 00 00 00 00 f7
```

### 100 Bassline Demo2 (Bassline engine)

Pulse &middot; A0 D3 S0 R1 &middot; PWM 2546/4095 &middot; Filter LP+BP cutoff=8/2047 res=15/15 route=v1+v2+v3 &middot; LFO Triangle -> Pitch rate=55 depth=127 &middot; LFO2 Triangle -> Pitch rate=11 depth=127 &middot; Arp Up rate=62 range=1oct (needs CC_ARPE on to hear) &middot; Bend range 12 &middot; Unison off

Notes: Sine -> Triangle (no sine on real SID); Arp defined but disabled in the source patch; CC_ARPE off by default; Bassline engine's envelope is separate from OSC1's voice ADSR; using the engine envelope (scaled 8bit->4bit), not v1's own ADSR bytes. New in v2: LFO2 sourced from a second live-routed MBSID LFO (Triangle, rate=11, depth=127, -> Pitch); Unison off (source uses only OSC1).

```
f0 50 20 10 04 00 00 03 00 01 0f 02 00 09 00 00 00 08 00 0f 00 07 03 00 00 00 03 07 07 0f 00 00 00 00 03 0e 00 00 00 0c 00 00 00 0b 07 0f 00 00 00 00 00 00 f7
```

### 101 Vib Synth (Lead engine)

Sawtooth &middot; A0 D0 S15 R8 &middot; Filter LP cutoff=1296/2047 res=15/15 route=v1 &middot; LFO Triangle -> Pitch rate=64 depth=118 &middot; LFO2 off &middot; Arp Up rate=62 range=1oct (needs CC_ARPE on to hear) &middot; Bend range 2 &middot; Unison off

Notes: LFO2 Sine -> Triangle (no sine on real SID); source modulation actually comes from LFO2, not LFO1 (this firmware has only one LFO per channel); Arp defined but disabled in the source patch; CC_ARPE off by default. New in v2: LFO2 off (no second live-routed LFO found in the source); Unison off (source uses only OSC1).

```
f0 50 20 10 02 00 00 00 0f 08 06 00 00 02 00 05 01 00 00 0f 00 01 01 00 00 00 04 00 07 06 00 00 00 00 03 0e 00 00 00 02 00 00 00 00 00 00 00 00 00 00 00 00 f7
```

### 102 Whats That? (Lead engine)

Triangle [ring] &middot; A0 D0 S15 R0 &middot; Filter LP cutoff=736/2047 res=15/15 route=v1+v2+v3 &middot; LFO Triangle -> Cutoff rate=25 depth=64 &middot; LFO2 off &middot; Arp Up rate=62 range=1oct (needs CC_ARPE on to hear) &middot; Bend range 2 &middot; Unison on detune=11/255

Notes: LFO1 Sine -> Triangle (no sine on real SID); Arp defined but disabled in the source patch; CC_ARPE off by default; source uses OSC2/OSC3 too (multi-osc); only OSC1's timbre captured here. New in v2: LFO2 off (no second live-routed LFO found in the source); Unison on, detune=11/255 (from the source's OSC2/OSC3 detune spread, now usable as 3-voice unison instead of being discarded).

```
f0 50 20 10 01 04 00 00 0f 00 00 00 00 08 00 02 0e 00 00 0f 00 07 01 00 00 00 01 09 04 00 00 02 00 00 03 0e 00 00 00 02 00 00 00 00 00 00 00 00 00 01 00 0b f7
```
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

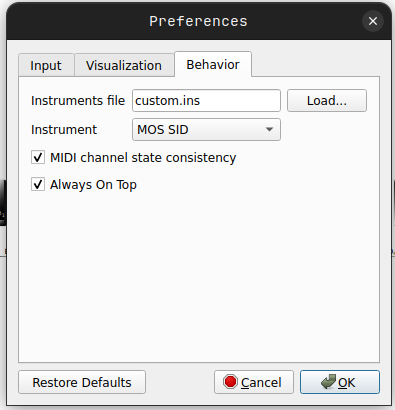
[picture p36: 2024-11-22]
.github/wiki/assets/vmpk-instruments-file.png

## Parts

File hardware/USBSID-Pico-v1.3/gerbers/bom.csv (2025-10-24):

Designator | Quantity | Value | Footprint | Package | MPN | DNP | Mount_Type | Description | Manufacturer | Mfg Part # | Mfg Part Desc | Mfg Qty | Sim.Device | Sim.Pins | Optional Part | Optional datasheet | Optional Part #
C1 | 1 | 10uF | CP_EIA-3216-10_Kemet-I_Pad1.58x1.35mm_HandSolder |  |  |  | smt | T491A106(1)004A(2) | KEMET | T491A106K016AT | 10uF 16V 3Ω@100kHz ±10% CASE-A-3216-18(mm) Tantalum Capacitors | 1
C10, C11 | 2 | 1000pF | C_0805_2012Metric |  |  |  | smt |  | Samsung | CL21B102KBANNNC | 50V 1nF X7R ±10% 0805 Multilayer Ceramic Capacitors MLCC - SMD/SMT ROHS | 1
C12, C13, C2, C4, C6, C8 | 6 | 470pF | C_0805_2012Metric |  |  |  | smt |  | Guangdong Fenghua Advanced Tech | 0805B471K500NT | 50V 470pF X7R ±10% 0805 Multilayer Ceramic Capacitors MLCC - SMD/SMT ROHS | 1
C14, C15, C27, C28, C29, C30, C31, C32 | 8 | 100nF | C_0805_2012Metric |  |  |  | smt |  | Samsung | CL21B104KBCNNNC | 50V 100nF X7R ±10% 0805 Multilayer Ceramic Capacitors MLCC - SMD/SMT ROHS | 1
C16, C17 | 2 | 10uF | CP_Elec_4x5.3 |  |  |  | smt | 10UF 25V 4x5.4mm | Honor Elec | RVT1E100M0405 | 10uF 25V ±20% SMD,D4xL5.4mm Aluminum Electrolytic Capacitors - SMD ROHS | 1
C18, C19, C20, C21, C22, C23, C24, C25, C26 | 9 | 22uF | C_0805_2012Metric |  |  |  | smt |  | Samsung | CL21A226MAQNNNE | 25V 22uF X5R ±20% 0805 Multilayer Ceramic Capacitors MLCC - SMD/SMT ROHS | 1
C3, C5, C7, C9 | 4 | 22nF | C_0805_2012Metric |  |  |  | smt |  | Samsung | CL21B223KBANNNC | 50V 22nF X7R ±10% 0805 Multilayer Ceramic Capacitors MLCC - SMD/SMT ROHS | 1
D1, D2, D3, D4, D5, D6 | 6 | MBR120 | SOD-123FL_diode |  |  |  | smt | Schottky diode, small symbol | onsemi | MBR120VLSFT1G | 20V 300mV@1A 1A SOD-123FL Schottky Diodes ROHS | 1 | D | 1=K 2=A
J1 | 1 | SID1 (DIP28-Wide-socket) | DIP-28_W15.24mm_Socket_enlargedholes |  |  |  | tht | DIP-28_W15.24mm_Socket | CONNFLY Elec | DS1009-28AT1WX-0A2 | 28P DIP Tin 15.24mm 2.54mm DIP-28 IC / Transistor Socket ROHS | 1 |  |  | DIP-28 IC / Transistor Socket ROHS | https://www.lcsc.com/datasheet/lcsc_datasheet_2410121342_HanElectricity-H2541FV-C1524-2x14P_C22387113.pdf | H2541FV-C1524-2x14P
J10 | 1 | S2 6581/8580 J2 | PinHeader_1x03_P2.54mm_Vertical |  |  |  | tht | PinHeader_1x03_P2.54mm_Vertical | XUNPU | PH2.54-01-03PZD | Direct Insert Policy 2.5mm 6mm 3P -40℃~+105℃ 3mm 2.54mm Black Brass Single Row 1x3P Plugin,P=2.54mm Pin Headers ROHS | 1
J17 | 1 | A5 | PinHeader_1x03_P2.54mm_Vertical |  |  | Yes | tht | Generic connector, single row, 01x03, script generated (kicad-library-utils/schlib/autogen/connector/) | XUNPU | PH2.54-01-02PZD | Direct Insert Policy 2.5mm 6mm 2P -40℃~+105℃ 3mm 2.54mm Black Brass Single Row 1x2P Plugin,P=2.54mm Pin Headers ROHS | 1
J18 | 1 | UART | PinHeader_1x03_P2.54mm_Vertical |  |  | Yes | tht | Generic connector, single row, 01x03, script generated (kicad-library-utils/schlib/autogen/connector/) | XUNPU | PH2.54-01-02PZD | Direct Insert Policy 2.5mm 6mm 2P -40℃~+105℃ 3mm 2.54mm Black Brass Single Row 1x2P Plugin,P=2.54mm Pin Headers ROHS | 1
J2 | 1 | SID2 (DIP28-Wide-socket) | DIP-28_W15.24mm_Socket_enlargedholes |  |  |  | tht | DIP-28_W15.24mm_Socket | CONNFLY Elec | DS1009-28AT1WX-0A2 | 28P DIP Tin 15.24mm 2.54mm DIP-28 IC / Transistor Socket ROHS | 1 |  |  | DIP-28 IC / Transistor Socket ROHS | https://www.lcsc.com/datasheet/lcsc_datasheet_2410121342_HanElectricity-H2541FV-C1524-2x14P_C22387113.pdf | H2541FV-C1524-2x14P
J20 | 1 | SID1 12v/9v | PinHeader_1x02_P2.54mm_Vertical |  |  |  | tht | Generic connector, single row, 01x02, script generated (kicad-library-utils/schlib/autogen/connector/) | XUNPU | PH2.54-01-02PZD | Direct Insert Policy 2.5mm 6mm 2P -40℃~+105℃ 3mm 2.54mm Black Brass Single Row 1x2P Plugin,P=2.54mm Pin Headers ROHS | 1
J21 | 1 | SID2 12v/9v | PinHeader_1x02_P2.54mm_Vertical |  |  |  | tht | Generic connector, single row, 01x02, script generated (kicad-library-utils/schlib/autogen/connector/) | XUNPU | PH2.54-01-02PZD | Direct Insert Policy 2.5mm 6mm 2P -40℃~+105℃ 3mm 2.54mm Black Brass Single Row 1x2P Plugin,P=2.54mm Pin Headers ROHS | 1
J24 | 1 | OPT | PinHeader_1x04_P2.54mm_Vertical |  |  | Yes | tht | Generic connector, single row, 01x04, script generated (kicad-library-utils/schlib/autogen/connector/) | XUNPU | PH2.54-01-02PZD | Direct Insert Policy 2.5mm 6mm 2P -40℃~+105℃ 3mm 2.54mm Black Brass Single Row 1x2P Plugin,P=2.54mm Pin Headers ROHS | 1
J3 | 1 | S1 6581/8580 J1 | PinHeader_1x03_P2.54mm_Vertical |  |  |  | tht | PinHeader_1x03_P2.54mm_Vertical | XUNPU | PH2.54-01-03PZD | Direct Insert Policy 2.5mm 6mm 3P -40℃~+105℃ 3mm 2.54mm Black Brass Single Row 1x3P Plugin,P=2.54mm Pin Headers ROHS | 1
J4 | 1 | S2 6581/8580 J1 | PinHeader_1x03_P2.54mm_Vertical |  |  |  | tht | PinHeader_1x03_P2.54mm_Vertical | XUNPU | PH2.54-01-03PZD | Direct Insert Policy 2.5mm 6mm 3P -40℃~+105℃ 3mm 2.54mm Black Brass Single Row 1x3P Plugin,P=2.54mm Pin Headers ROHS | 1
J6 | 1 | GND/S1 | PinHeader_1x03_P2.54mm_Vertical |  |  | Yes | tht | Generic connector, single row, 01x03, script generated (kicad-library-utils/schlib/autogen/connector/) | XUNPU | PH2.54-01-02PZD | Direct Insert Policy 2.5mm 6mm 2P -40℃~+105℃ 3mm 2.54mm Black Brass Single Row 1x2P Plugin,P=2.54mm Pin Headers ROHS | 1
J7 | 1 | S2/GND | PinHeader_1x03_P2.54mm_Vertical |  |  | Yes | tht | Generic connector, single row, 01x03, script generated (kicad-library-utils/schlib/autogen/connector/) | XUNPU | PH2.54-01-02PZD | Direct Insert Policy 2.5mm 6mm 2P -40℃~+105℃ 3mm 2.54mm Black Brass Single Row 1x2P Plugin,P=2.54mm Pin Headers ROHS | 1
J8 | 1 | SJ1-3525N | 3.5MM_SWITCHCRAFT_35RAPC4BHN2 |  |  |  | tht | Audio Jack, 2 Poles (Mono / TS), Grounded Sleeve, Switched Pole (Normalling) | CuiDevices | SJ1-3525N | Audio Jack with tip and ring switch | 1 |  |  |  | https://www.lcsc.com/datasheet/lcsc_datasheet_2409272203_SHOU-HAN-PJ3F07-5P_C668604.pdf | PJ3F07-5P
J9 | 1 | S1 6581/8580 J2 | PinHeader_1x03_P2.54mm_Vertical |  |  |  | tht | PinHeader_1x03_P2.54mm_Vertical | XUNPU | PH2.54-01-03PZD | Direct Insert Policy 2.5mm 6mm 3P -40℃~+105℃ 3mm 2.54mm Black Brass Single Row 1x3P Plugin,P=2.54mm Pin Headers ROHS | 1
L1, L2, L3 | 3 | 4,7uH 1000mA | L_1008_2520Metric_Pad1.43x2.20mm_HandSolder |  |  |  | smt | 4,7uH 1000mA | SunLord | SPH252012H4R7MT | 1.25A 4.7uH ±20% 1.2A 1008 Power Inductors ROHS | 1
Q1, Q2 | 2 | MMBT2222A | SOT-23 |  |  |  | smt | 15A Ic, 60V Vce, Power NPN Transistor, TO-3 | onsemi | MMBT2222ALT1G | 40V 225mW 100@150mA,10V 600mA NPN SOT-23 Bipolar (BJT) ROHS | 1
R1, R2, R4 | 3 | 10k | R_0805_2012Metric |  |  |  | smt | Resistor, small symbol | UNI-ROYAL | 0805W8F1002T5E | 125mW Thick Film Resistors 150V ±100ppm/℃ ±1% 10kΩ 0805 Chip Resistor - Surface Mount ROHS | 1
R10, R16, R17, R3, R5, R6, R7, R8, R9 | 9 | 1k | R_0805_2012Metric |  |  |  | smt |  | [R8,R9]UNI-ROYAL; [R5,R6,R7]UNI-ROYAL | 0805W8F1001T5E | [R8,R9]125mW Thick Film Resistors 150V ±100ppm/℃ ±1% 1kΩ 0805 Chip Resistor - Surface Mount ROHS ; [R3,R5,R6,R7]125mW Thick Film Resistors 150V ±100ppm/℃ ±1% 1kΩ 0805 Chip Resistor - Surface Mount ROHS | 1
R11 | 1 | 7,5k | R_0805_2012Metric |  |  |  | smt |  | UNI-ROYAL | 0805W8F7501T5E | 125mW Thick Film Resistors 150V ±100ppm/℃ ±1% 7.5kΩ 0805 Chip Resistor - Surface Mount ROHS | 1
R12, R14 | 2 | 18k | R_0805_2012Metric |  |  |  | smt |  | UNI-ROYAL | 0805W8F1802T5E | 125mW Thick Film Resistors 150V ±100ppm/℃ ±1% 18kΩ 0805 Chip Resistor - Surface Mount ROHS | 1
R13, R15 | 2 | 47k | R_0805_2012Metric |  |  |  | smt |  | UNI-ROYAL | 0805W8F4702T5E | 125mW Thick Film Resistors 150V ±100ppm/℃ ±1% 47kΩ 0805 Chip Resistor - Surface Mount ROHS | 1
R18, R19 | 2 | 330k | R_0805_2012Metric |  |  |  | smt |  | UNI-ROYAL | 0805W8F3303T5E | 125mW Thick Film Resistors 150V ±100ppm/℃ ±1% 330kΩ 0805 Chip Resistor - Surface Mount ROHS | 1
R20, R21 | 2 | 100k | R_0805_2012Metric |  |  |  | smt |  | UNI-ROYAL | 0805W8F1003T5E | 125mW Thick Film Resistors 150V ±100ppm/℃ ±1% 100kΩ 0805 Chip Resistor - Surface Mount ROHS | 1
SW1 | 1 | RST | SW_SPST_B3U-1000P_larger_pads |  |  |  | smt | Push button switch, generic, two pins | Omron Electronics | B3U-1000P | 2.5mm 1.6mm Round Button 50mA Standing paste 3mm SPST 153gf 12V SMD,2.5x3mm Tactile Switches ROHS | 1
U2, U3, U4 | 3 | MT3608 | SOT-23-6 |  |  |  | smt |  | AeroSemi | MT3608 | High Efficiency 1.2MHz 2A Step Up Converter | 1
U5 | 1 | DG467 | SOT-23-6 |  |  |  | smt | Low Power, High Voltage SPST Analog Switches, 6-Pin TSOP | Vishay | DG467DV-T1-E3 | Low Power, High Voltage SPST Analog Switches | 1

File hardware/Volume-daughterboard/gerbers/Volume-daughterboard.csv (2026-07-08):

Reference | Qty | Value | Footprint | Manufacturer | Mfg Part # | Mfg Part Desc
C1,C2 | 2 | 0.1uF | Capacitor_SMD:C_0805_2012Metric_Pad1.18x1.45mm_HandSolder | FOJAN | FCC0805B104K500DT | CAP CER 100nF 50V X7R 0805
C5,C6,C11 | 3 | 10uF | Capacitor_SMD:C_0805_2012Metric_Pad1.18x1.45mm_HandSolder | FOJAN | FCC0805X106K500FT | CAP CER 10uF 50V X5R 0805
C7,C8 | 2 | 100pF | Capacitor_SMD:C_0805_2012Metric_Pad1.18x1.45mm_HandSolder | FOJAN | FCC0805N101J500BT | CAP CER 100pF 50V C0G 0805
C9,C10 | 2 | 1uF | Capacitor_SMD:C_0805_2012Metric_Pad1.18x1.45mm_HandSolder | FOJAN | FCC0805B105K500FT | CAP CER 1uF 50V X7R 0805
C3,C4 | 2 | 47uF 16v | Capacitor_SMD:CP_Elec_5x5.4 | FOSAN | FVH016ADA470M0554 | CAP ALUM 47uF ±20% 16V SMD
J1 | 1 | GND/S1 | Connector_PinSocket_2.54mm:PinSocket_1x04_P2.54mm_Vertical | XUNPU | PH2.54-01-04PZD | PH2.54-01-04PZD
J2 | 1 | S2/GND | Connector_PinSocket_2.54mm:PinSocket_1x04_P2.54mm_Vertical | XUNPU | PH2.54-01-04PZD | PH2.54-01-04PZD
J4 | 1 | 1503 17 | LouD:Lumberg 1503 17 | Lumberg | 134382 1503-17 / SJ1-3525N | Through Hole Audio Connectors RoHS
RV1 | 1 | Left Volume | LouD:PotentioMeter | ALPSALPINE | RK09K1130AAU | POT 10kΩ Through Hole
RV2 | 1 | Right Volume | LouD:PotentioMeter | ALPSALPINE | RK09K1130AAU | POT 10kΩ Through Hole
U1 | 1 | OPA1688IDR | LouD:SOIC127P599X175-8N | Texas Instruments | OPA1688IDR | 36-V, Single-Supply, 10-MHz, Rail-to-Rail Output Operational Amplifiers
D1 | 1 | BAT54C | Package_TO_SOT_SMD:SOT-23 | Diodes Incorporated | BAT54C-7-F | DIODE ARR SCHOTTKY 30V SOT-23
R1,R2,R9,R10 | 4 | 10k | Resistor_SMD:R_0805_2012Metric | UNI-ROYAL | 0805W8F1002T5E | RES 10kΩ ±1% 125mW 0805
R3,R4 | 2 | 10r | Resistor_SMD:R_0805_2012Metric |  | 0805W8F100JT5E | RES 10Ω ±1% 125mW 0805
R5,R6,R7,R8 | 4 | 47k | Resistor_SMD:R_0805_2012Metric |  | 0805W8F4702T5E | RES 47kΩ ±1% 125mW 0805

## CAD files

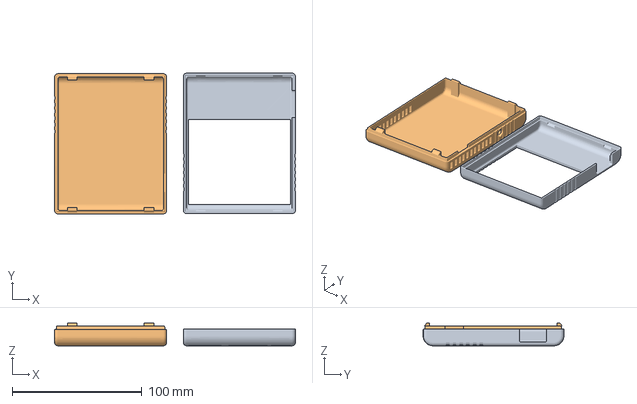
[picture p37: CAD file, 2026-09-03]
cases/v1.5/spotUp-LouD_remix/USBSID-Pico v1.5 case.3mf
185.8 x 108.5 x 17.4 mm
USBSID-Pico v1.5 case top.stl
USBSID-Pico v1.5 bottom.stl

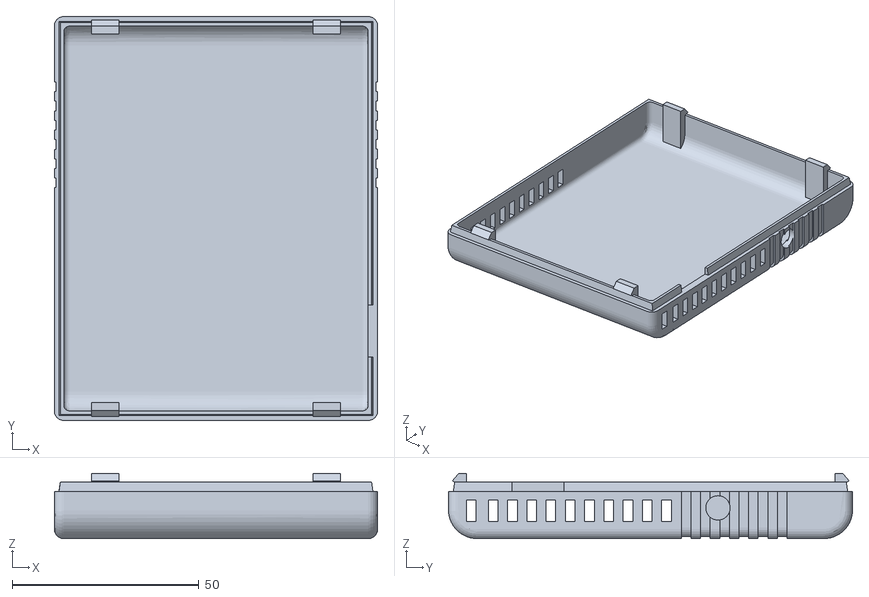
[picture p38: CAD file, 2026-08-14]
cases/v1.5/spotUp-LouD_remix/USBSID-Pico v1.5 case bottom.stl
86.5 x 108.0 x 17.4

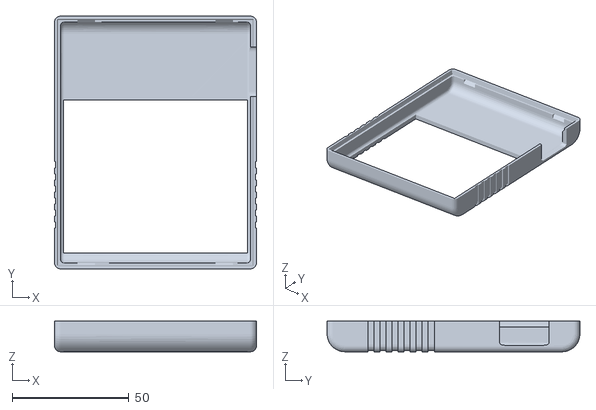
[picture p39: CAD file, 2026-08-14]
cases/v1.5/spotUp-LouD_remix/USBSID-Pico v1.5 case top.stl
86.5 x 108.2 x 13.1

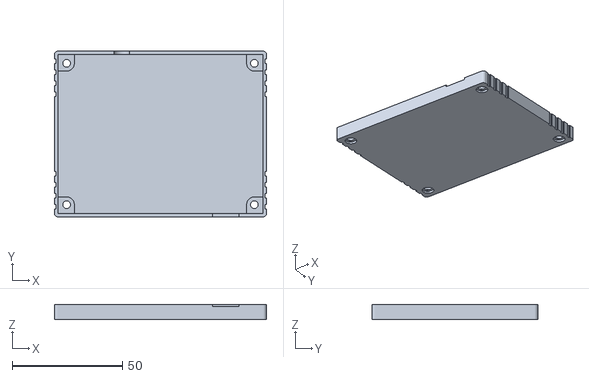
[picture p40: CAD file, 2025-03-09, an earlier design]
cases/v1.0/schorsch3000/case-bottom.stl
96.0 x 75.0 x 7.00

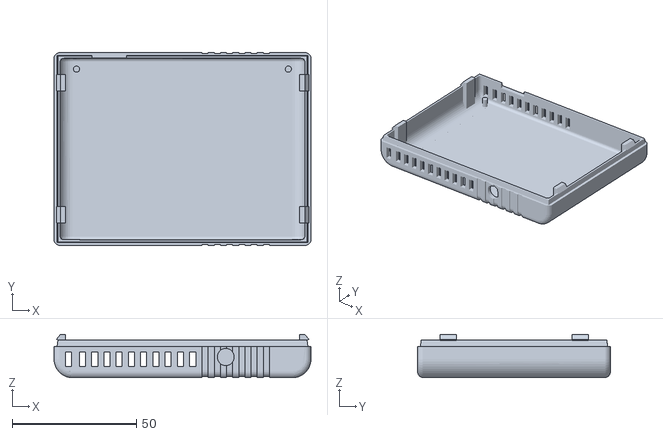
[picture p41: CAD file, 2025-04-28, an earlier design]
cases/v1.0/spotUP/USBSID-Pico v1.0 case bottom notched.stl
103.3 x 77.5 x 17.4

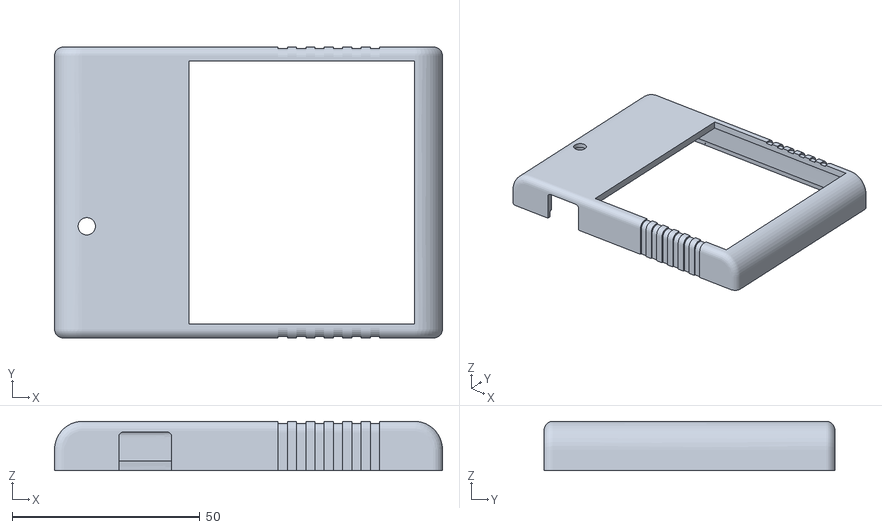
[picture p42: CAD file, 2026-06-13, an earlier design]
cases/v1.3/spotUP-revisited/USBSID-Pico v1.3 top case open with reset narrow hole.stl
103.3 x 77.5 x 13.1

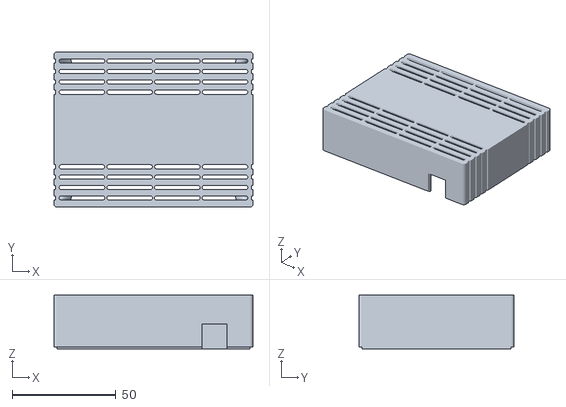
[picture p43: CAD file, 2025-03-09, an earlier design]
cases/v1.0/schorsch3000/case-top.stl
96.0 x 75.0 x 26.0

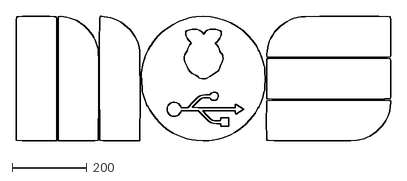
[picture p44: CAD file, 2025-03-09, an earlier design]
cases/v1.0/schorsch3000/usbsid-white.dxf
1002.8 x 333.0

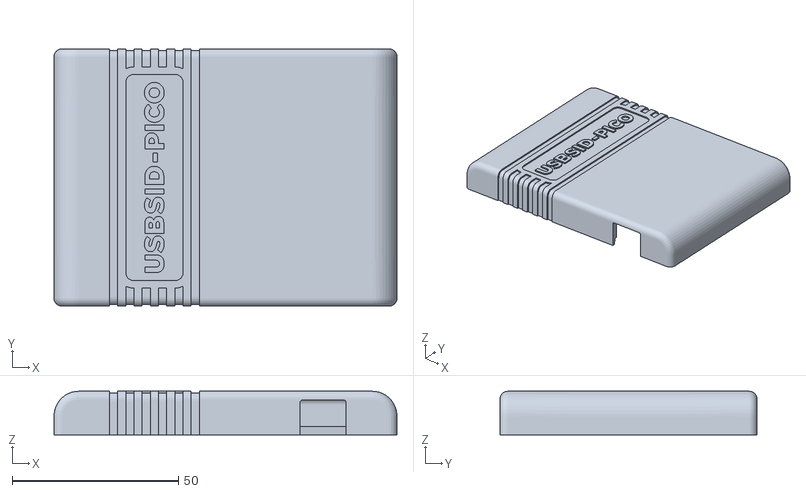
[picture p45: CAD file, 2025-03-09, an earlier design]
cases/v1.0/spotUP/USBSID-Case-Top.stl
103.3 x 77.5 x 13.1

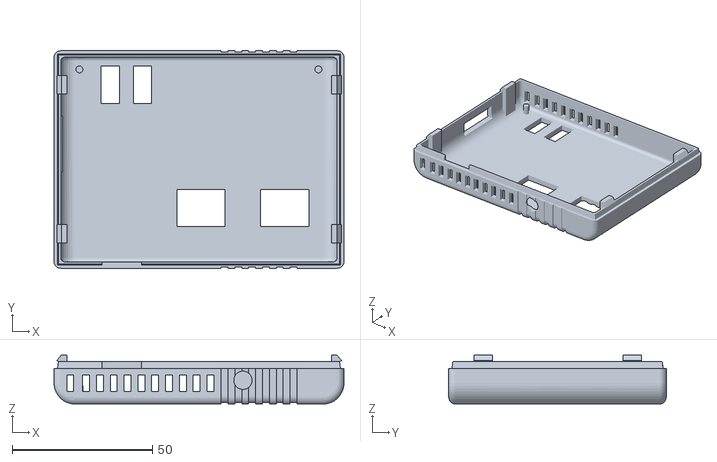
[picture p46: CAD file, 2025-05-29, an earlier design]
cases/v1.3/spotUP-revisited/USBSID-Pico v1.3 bottom case jumper gpio openings.stl
103.3 x 77.5 x 17.4

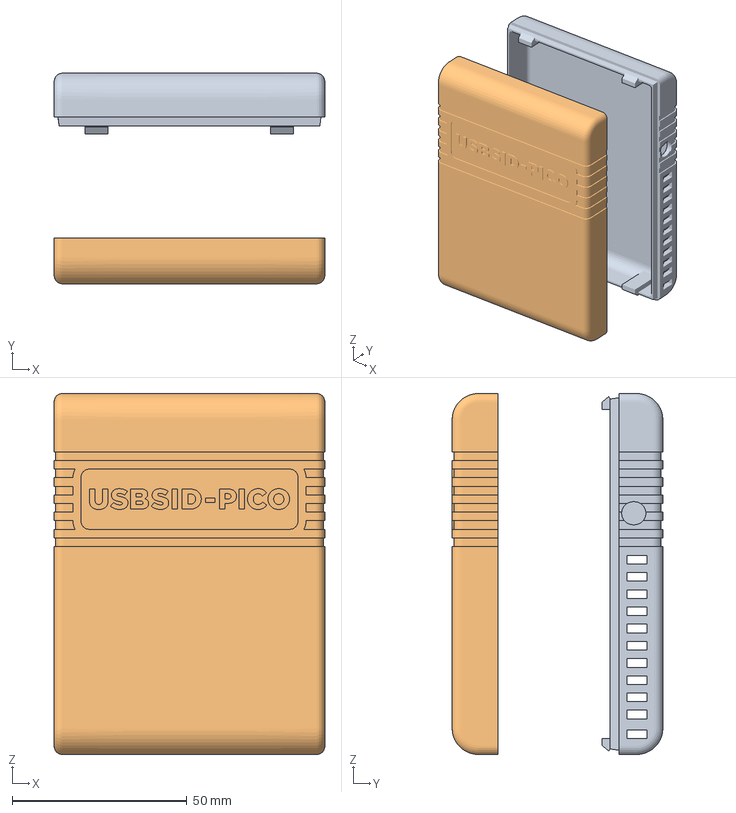
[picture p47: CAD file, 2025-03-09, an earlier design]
cases/v1.0/spotUP/USBSID-Pico_Case.3mf
77.5 x 60.3 x 103.3 mm
usbsid-pico22-bottom.stl
usbsid-pico22-top.stl

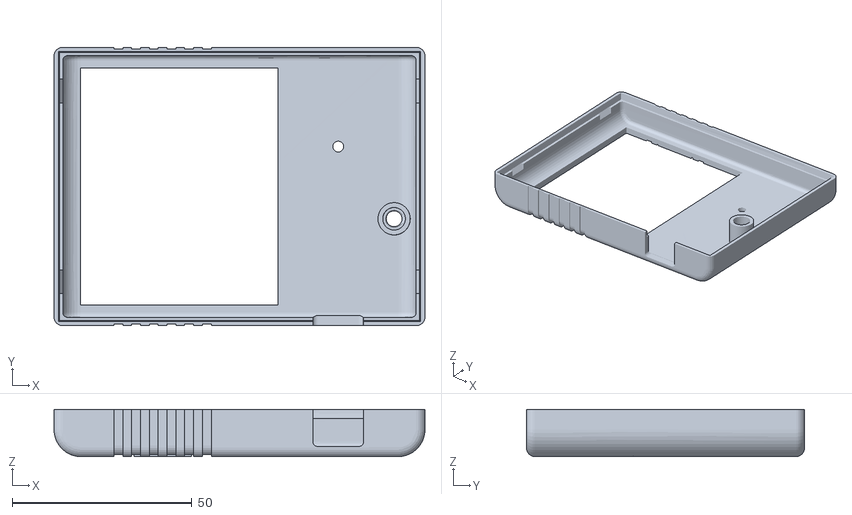
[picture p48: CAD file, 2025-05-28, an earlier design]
cases/v1.3/spotUP-revisited/USBSID-Pico v1.3 top case open with reset and rgb led opening.stl
103.3 x 77.5 x 13.1

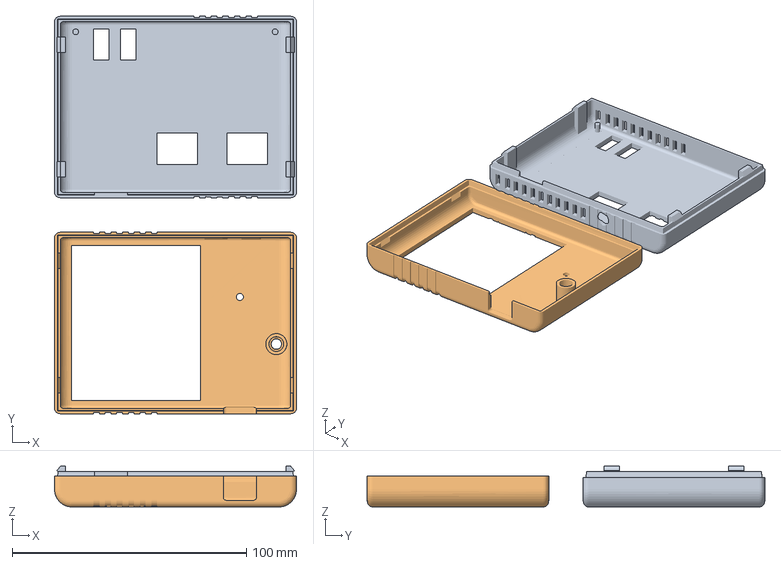
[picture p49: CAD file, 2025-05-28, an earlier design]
cases/v1.3/spotUP-revisited/USBSID-Pico v1.3 prusaslicer.3mf
103.3 x 169.7 x 17.4 mm
USBSID-Pico v1.3 bottom case jumper openings.stl
USBSID-Pico v1.3 top case open with reset and rgb led opening.stl

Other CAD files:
cases/v1.0/spotUP/USBSID-Pico v1.0 case top open.stl
cases/v1.3/spotUP-revisited/USBSID-Pico v1.3 top case open with reset wide hole.stl
cases/v1.0/spotUP/USBSID-Pico_Case_Bottom.stl
cases/v1.3/spotUP-revisited/USBSID-Pico v1.3 bottom case jumper openings.stl
cases/v1.3/spotUP-revisited/USBSID-Pico v1.3 top case open with reset.stl
cases/v1.0/schorsch3000/case.scad
cases/v1.3/spotUP-revisited/USBSID-Pico v1.3 bottom case notched.stl
cases/v1.3/spotUP-revisited/USBSID-Pico v1.3 bottom case.stl
cases/v1.3/spotUP-revisited/USBSID-Pico v1.3 resetpin.stl
cases/v1.3/spotUP-revisited/USBSID-Pico v1.3 top case with reset.stl
cases/v1.3/spotUP-revisited/USBSID-Pico v1.3 top case.stl

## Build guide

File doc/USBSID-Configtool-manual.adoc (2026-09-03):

= *USBSID-Configtool manual*
:author: LouD
:description: This document contains information about the USBSID-Configtool and how to use it
:url-repo: https://www.github.com/LouDnl/USBSID-Configtool
:revdate: {localdate}
:hide-uri-scheme:
:toc:
:toclevels: 4
:toc-placement!:

Author: {author} - generated on {revdate}

toc::[]
[%always]
<<<

== Disclaimer
include::disclaimer.adoc[]

== About
What is there to say, you can configure your board with this tool and it is self explanatory. +
Prefer the command line? A CLI config tool (`cfg_usbsid`) is also available - see the `USBSID-Pico-firmware-manual` file for its usage.

== Screens

=== Welcome screen
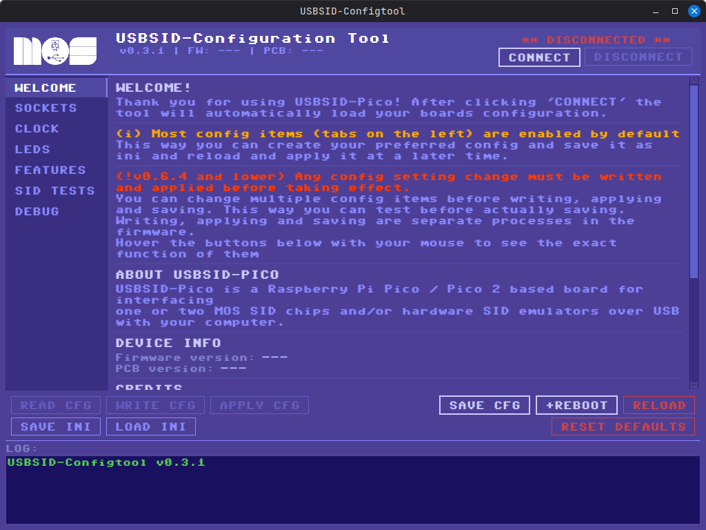
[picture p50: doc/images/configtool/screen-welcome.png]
 +
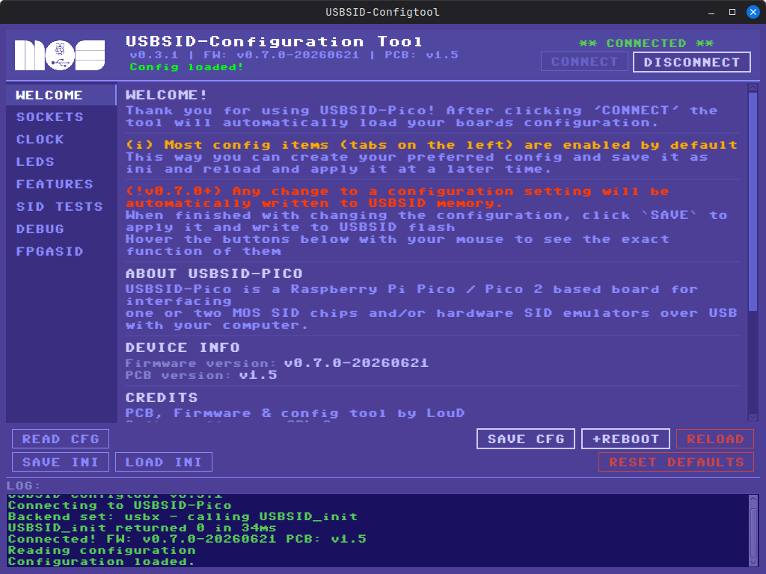
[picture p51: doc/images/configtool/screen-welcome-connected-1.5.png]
 +
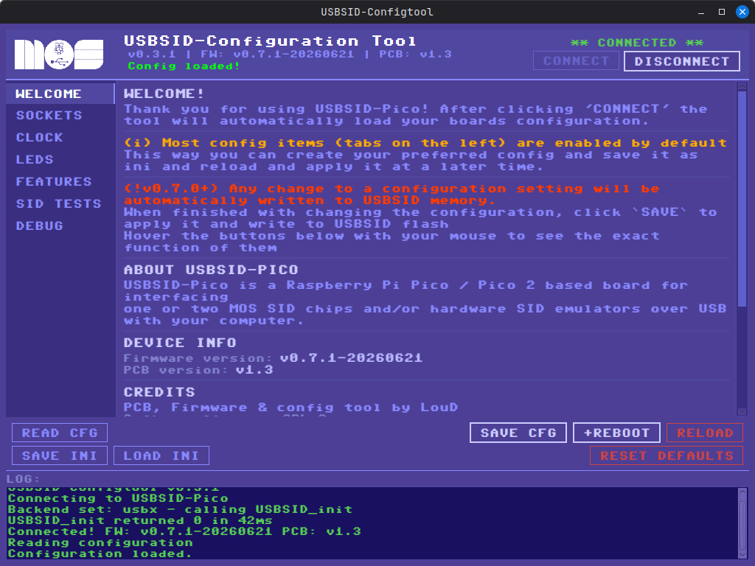
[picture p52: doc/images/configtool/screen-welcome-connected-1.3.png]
 +

=== v1.5 Sockets confirmation message
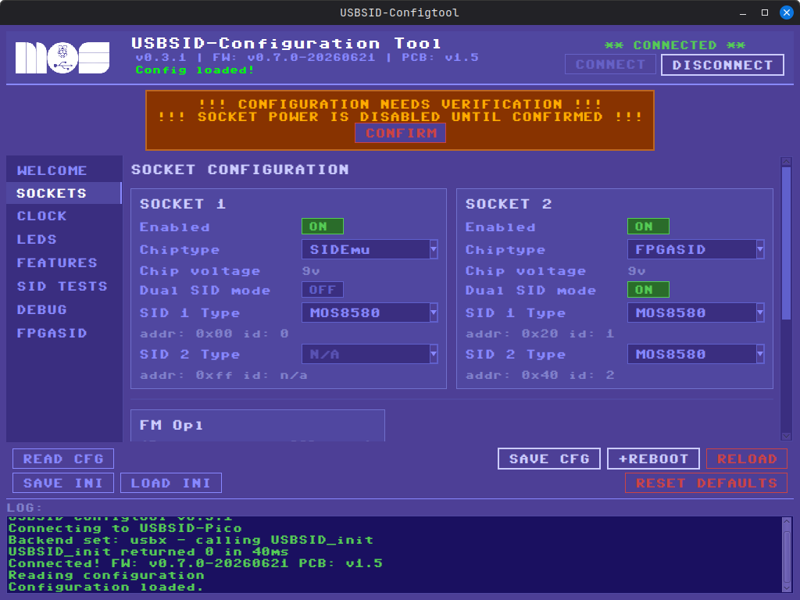
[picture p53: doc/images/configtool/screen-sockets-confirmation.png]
 +

=== Sockets screen
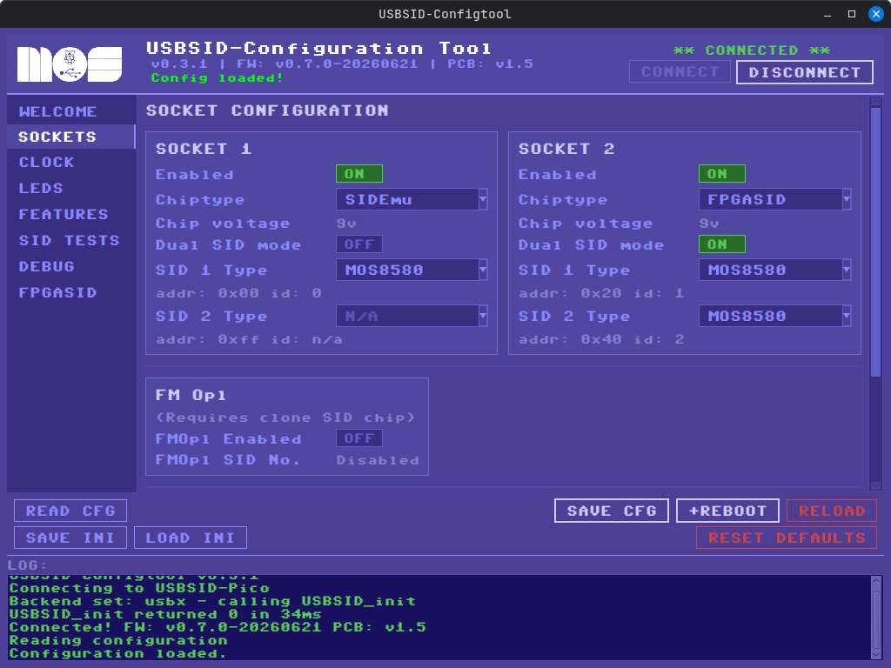
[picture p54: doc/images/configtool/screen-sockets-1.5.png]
 +
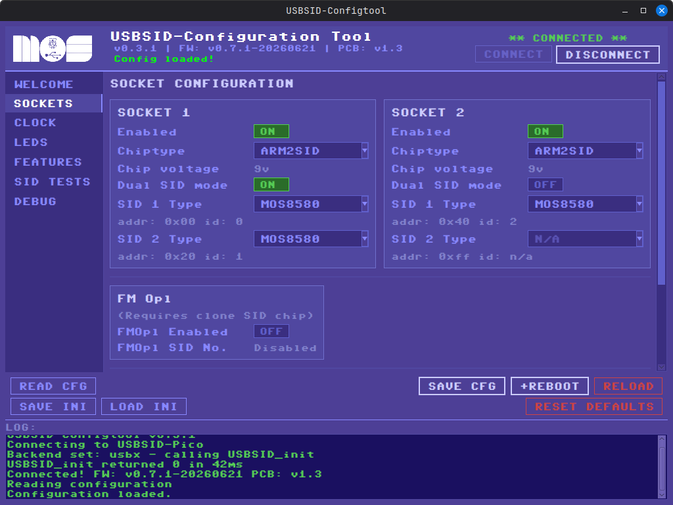
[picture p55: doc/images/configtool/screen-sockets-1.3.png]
 +

=== Clock screen
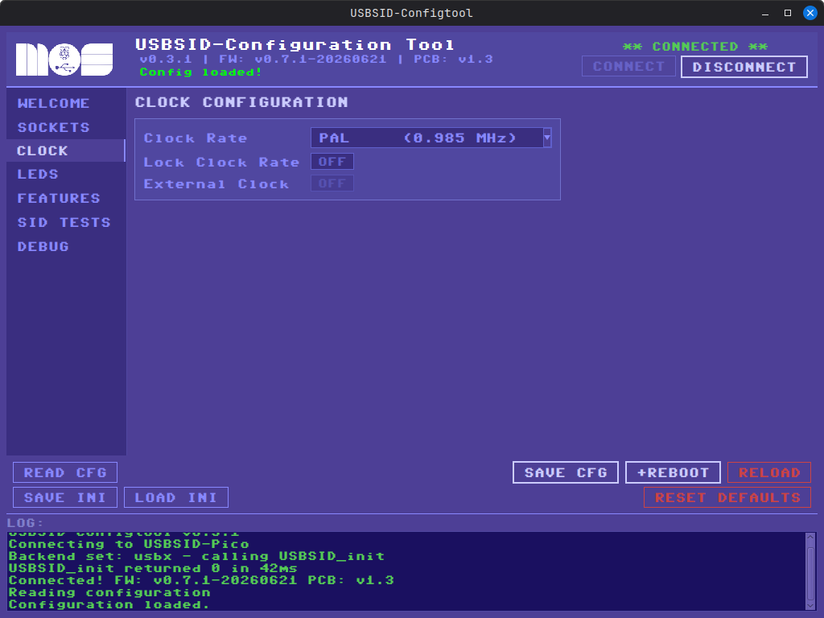
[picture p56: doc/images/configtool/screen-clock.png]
 +

=== LEDS screen
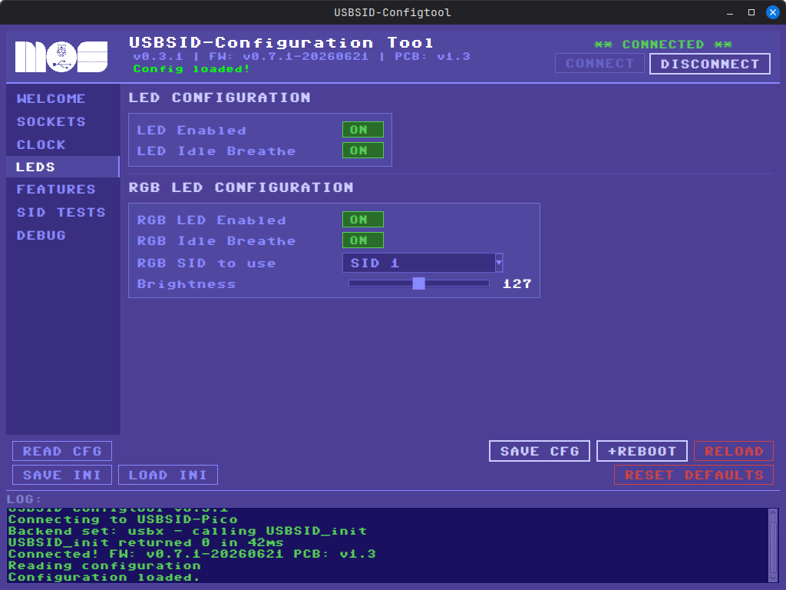
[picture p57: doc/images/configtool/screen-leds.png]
 +

=== Features screen
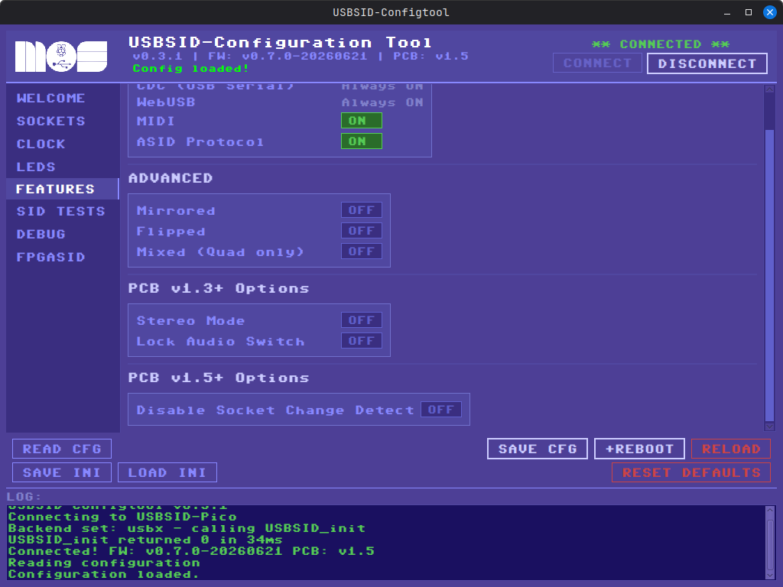
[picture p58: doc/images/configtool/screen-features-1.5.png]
 +
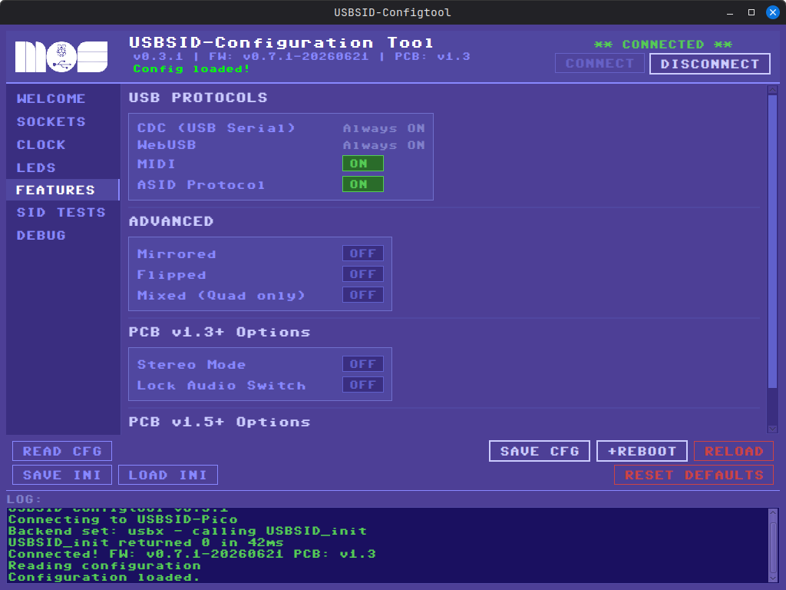
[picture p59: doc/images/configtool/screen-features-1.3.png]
 +

=== SID tests screen
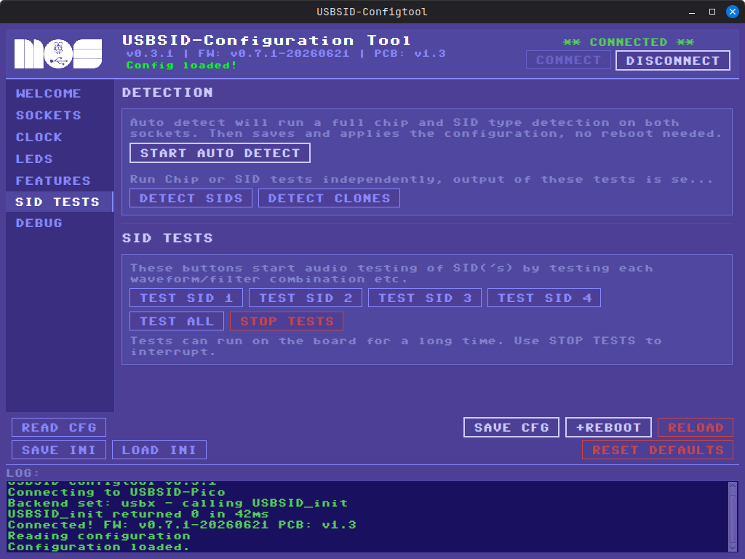
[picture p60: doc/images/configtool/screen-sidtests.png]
 +

=== Debug screen
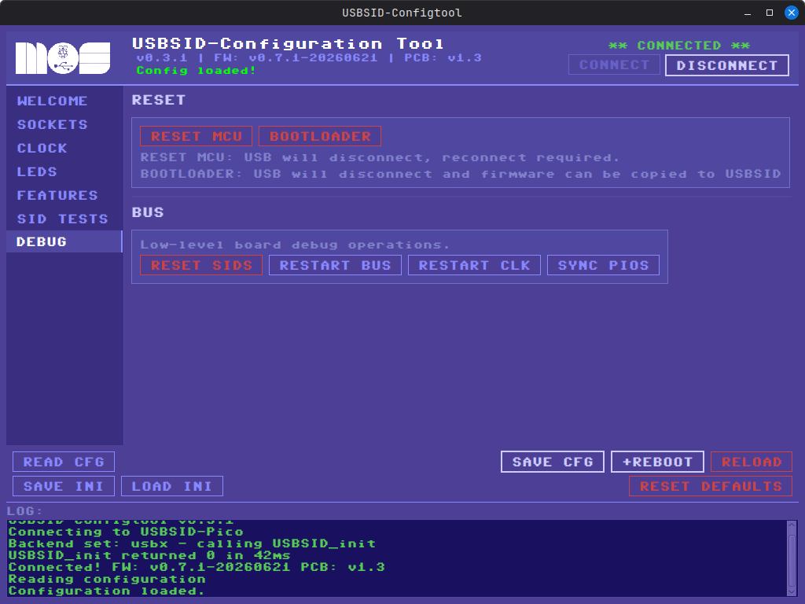
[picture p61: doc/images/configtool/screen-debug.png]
 +

== Development
More information about USBSID-Configtool is available on the https://github.com/LouDnl/USBSID-Configtool[github repo]

== License
include::license-software.adoc[]

include::license-hardware.adoc[]

Author: {author} - generated on {revdate}

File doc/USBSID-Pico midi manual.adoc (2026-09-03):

= *USBSID-Pico Midi manual*
:author: LouD
:description: This document contains information on how to use midi with USBSID-Pico
:url-repo: https://www.github.com/LouDnl/USBSID-Pico
:revdate: {localdate}
:hide-uri-scheme:
:toc:
:toclevels: 4
:toc-placement!:

Author: {author} - generated on {revdate}

toc::[]
[%always]
<<<

== Disclaimer
include::disclaimer.adoc[]

== Quick start
USBSID-Pico shows up as a class-compliant USB-MIDI device - no driver install needed on any
platform. Point any MIDI application, DAW, or live-coding environment (Strudel, VMPK, a hardware
keyboard through a MIDI interface, ...) at it and start playing.

Out of the box, without touching any configuration:

- *Channel 1* uses every voice on every configured SID, fully polyphonic (up to 12 voices on a
  4-SID board). Plug in a keyboard and play.
- *Channels 2-5* each get one SID chip exclusively (channel 2 -> SID 1, channel 3 -> SID 2, and so
  on), 3-voice polyphonic within that chip. This gives a sane multi-timbral split (one instrument
  per channel, one channel per chip) without touching a config tool.
- *Channels 6-16* are disabled (no voice mask) until you assign them yourself.
- Every channel defaults to a plain triangle wave with full sustain, so a note is immediately
  audible - no need to send a waveform or envelope CC first to hear anything.

If your board has an FMOpl-capable chip installed, see <<FMOpl>> below - it is a separate
instrument with its own note path and its own smaller set of controls, not just another SID.

== Notes, velocity and aftertouch
Standard MIDI Note On / Note Off (`0x90`/`0x80`) trigger and release voices. A Note On with
velocity 0 is treated as a Note Off, matching how most keyboards send note releases under running
status.

Velocity does nothing to the sound by default - this is deliberate, so a controller's velocity
curve cannot accidentally stomp on the channel volume CC. Turn `CC_VELM` on (see the table below)
to make velocity scale the decay stage instead (higher velocity = punchier, shorter decay).

Channel Aftertouch (`0xD0`) and Polyphonic Key Pressure (`0xA0`, applied channel-wide rather than
per note) both drive whichever target `at_target` currently selects for that channel - filter
cutoff by default, or channel volume, or LFO depth (a ready-made vibrato-on-pressure setup) if a
loaded patch sets it differently.

Pitch Bend (`0xE0`) bends every voice currently held on the channel, live, using that channel's
bend range in semitones (2 by default, or whatever the currently-loaded patch set it to - there is
no separate CC for bend range).

== Channel routing
Every MIDI channel (1-16) has its own independent routing, entirely separate from which patch is
loaded on it:

- *Voice mask* - which of the pool's voice slots (up to 12 on a 4-SID board, 3 per chip) this
  channel is allowed to use. Set up sensibly out of the box (see <<Quick start>>); reconfigured
  through the USBSID-Pico config tool, not through MIDI CCs.
- *SID / voice overrides* - `CC_SID1`-`CC_SID4` and `CC_VCE1`-`CC_VCE3` temporarily narrow a
  channel's own voice mask to one specific chip or one specific voice position, without changing
  the configured mask itself. Send the CC with any nonzero value to select, `0` to clear the
  override and go back to the full configured mask. Handy for quickly confining a part to one
  voice while leaving the channel's normal setup untouched for the next patch.
- *Polyphony* - `CC_MONO`/`CC_POLY` switch a channel between monophonic and fully polyphonic
  (within whatever it's currently allowed to use), silencing that channel's held notes on the
  switch. `CC_SPLY` is a lighter version of the same idea that does not cut off notes already
  playing.
- *Steal behaviour* - when a channel is out of free voices, the oldest-held note is stolen by
  default. Not exposed as a CC; this is a config-tool setting.

== Control Change reference
All CC numbers below are this firmware's *compiled-in defaults*
(`repo/src/midi_defs.h`, `MIDI_DEFAULT_CCVALUES_INIT`). The whole map is itself reconfigurable
(persisted alongside everything else in the MIDI flash blob, see <<Saving your settings>>), so if
your board's CC map has been changed, these numbers will not match - check your own configuration
first if a CC below doesn't seem to do anything.

=== Voice waveform and envelope
Each channel keeps one live "template" (waveform, envelope, pulse width) that gets stamped onto
every new note and pushed live to every note the channel is currently holding - so a waveform or
envelope CC change is heard immediately on a held chord, not just on the next note.

[cols="1,1,3"]
|===
|CC |Name |What it does

|20 |`CC_NOIS` |Toggle the noise waveform bit
|21 |`CC_PULS` |Toggle the pulse waveform bit
|22 |`CC_SAWT` |Toggle the sawtooth waveform bit
|23 |`CC_TRIA` |Toggle the triangle waveform bit
|24 |`CC_TEST` |Toggle the test bit
|25 |`CC_RMOD` |Toggle ring modulation
|26 |`CC_SYNC` |Toggle hard sync
|27 |`CC_GATE` |Manual gate open/close on every voice this channel currently holds - separate from the automatic gate a note-on/note-off already drives, for holding a drone open by hand
|17 |`CC_ATT` |Attack
|18 |`CC_DEC` |Decay
|19 |`CC_SUS` |Sustain
|29 |`CC_REL` |Release
|1  |`CC_PWM` |Pulse width (the modulation wheel on most controllers) - only audible when the pulse waveform is active
|28 |`CC_NOTE`|One-shot manual pitch entry for whatever this channel is currently holding
|===

Waveform bits are combinable exactly like real SID hardware - turning on more than one at once
gives the same thick, slightly metallic combined-waveform sound a real chip produces, not an error.

=== Filter and volume
Filter and volume are chip-wide registers, not per-voice - a CC here affects every SID chip
currently in the channel's mask at once, immediately, regardless of how many notes are held.

[cols="1,1,3"]
|===
|CC |Name |What it does

|32 |`CC_FFC`  |Filter cutoff frequency
|33 |`CC_RES`  |Filter resonance
|34 |`CC_FLT1` |Route voice 1 through the filter
|35 |`CC_FLT2` |Route voice 2 through the filter
|36 |`CC_FLT3` |Route voice 3 through the filter
|37 |`CC_FLTE` |Route the external input through the filter
|48 |`CC_3OFF` |Disconnect voice 3 from the output entirely
|49 |`CC_HPF`  |Enable the high-pass filter mode
|50 |`CC_BPF`  |Enable the band-pass filter mode
|51 |`CC_LPF`  |Enable the low-pass filter mode
|7  |`CC_VOL`  |Channel volume
|===

[IMPORTANT]
====
On real SID hardware, a voice routed into the filter (`CC_FLT1`-`3`/`CC_FLTE`) produces *no
output at all* unless a filter mode (`CC_HPF`/`CC_BPF`/`CC_LPF`) is also enabled. This is not a
bug to work around - it is how the chip actually behaves. If a sound goes silent the moment you
route it through the filter, turn on a filter mode too.
====

=== SID / voice selection and channel mode
[cols="1,1,3"]
|===
|CC |Name |What it does

|104 |`CC_SID1` |Narrow this channel to SID 1 only (any nonzero value selects, 0 clears)
|105 |`CC_SID2` |Narrow this channel to SID 2 only
|106 |`CC_SID3` |Narrow this channel to SID 3 only
|107 |`CC_SID4` |Narrow this channel to SID 4 only
|108 |`CC_VCE1` |Narrow this channel to voice position 1 on every chip it can use
|109 |`CC_VCE2` |Narrow this channel to voice position 2
|110 |`CC_VCE3` |Narrow this channel to voice position 3
|111 |`CC_SPLY` |Toggle full polyphony for this channel without silencing held notes
|119 |`CC_GTEN` |Toggle automatic gate (gate follows note-on/note-off) - on by default
|72  |`CC_VELM` |Toggle velocity mode (velocity scales decay) - off by default
|126 |`CC_MONO` |Force this channel monophonic, silencing what it currently holds
|127 |`CC_POLY` |Force this channel fully polyphonic, silencing what it currently holds
|===

=== Modulation and timing
One LFO, one arpeggiator and one portamento (glide) engine per channel, all driven by a shared 1kHz
tick. These are also the same fields a loaded patch sets (see <<Patches>>) - a live CC change here
overwrites whatever the current patch set, and the next Program Change overwrites it back.

[cols="1,1,3"]
|===
|CC |Name |What it does

|0 |`CC_LFOW` |LFO waveform: triangle, sawtooth, square, or sample & hold
|2 |`CC_LFOR` |LFO rate
|3 |`CC_LFOD` |LFO depth - `0` turns the LFO off entirely; this is also the tick's cue to skip the channel, so an idle LFO costs nothing
|4 |`CC_LFOT` |LFO destination: pitch, pulse width, or filter cutoff
|5 |`CC_PORT` |Portamento (glide) time - `0` is off; a freshly triggered note glides in from the previous note this channel played
|6 |`CC_ARPM` |Arpeggiator pattern: up, down, up/down, random, as-played, or table (see <<Arp-tables,Arp tables>>)
|10 |`CC_ARPR` |Arpeggiator rate - free-running unless a MIDI clock is present, in which case it is read as a clock division instead
|11 |`CC_ARPO` |Arpeggiator octave range (repeats the held pattern up to 3 extra octaves) - ignored in table mode, see <<Arp-tables,Arp tables>>
|12 |`CC_ARPE` |Arpeggiator on/off for this channel - held notes feed the arpeggiator's input pattern instead of sounding directly while this is on
|30 |`CC_ARPT` |Arp table select (0-15) - which table slot `CC_ARPM`'s "table" pattern reads; only matters once the mode is switched to table, see <<Arp-tables,Arp tables>>
|===

If your board has PAL/PWM LFO pitch modulation set as the aftertouch target (`AT_VIBRATO`), channel
pressure becomes a natural vibrato-on-pressure controller without touching `CC_LFOD` at all.

=== Second LFO
A fully independent second oscillator, same shape as the first, stacked on top of it rather than
replacing it. If both LFOs are pointed at the same destination their outputs simply add before the
one register write - two LFOs both targeting pitch, for example, sum into a single combined vibrato
rather than one overwriting the other.

[cols="1,1,3"]
|===
|CC |Name |What it does

|13 |`CC_LFO2W` |LFO 2 waveform: triangle, sawtooth, square, or sample & hold
|14 |`CC_LFO2R` |LFO 2 rate
|15 |`CC_LFO2D` |LFO 2 depth - `0` turns LFO 2 off entirely, independent of LFO 1's own depth
|16 |`CC_LFO2T` |LFO 2 destination: pitch, pulse width, or filter cutoff
|===

Everything that applies to LFO 1 above - the depth-0-costs-nothing behaviour, the patch-vs-live-CC
interaction, `AT_VIBRATO` - applies identically and independently to LFO 2.

=== Unison
Stacks 3 real oscillators onto one note instead of one - a thicker, detuned unison sound, MBSID
Lead-engine style. This is a genuine tradeoff, not a free thickening: a SID chip only has 3 physical
oscillators, so turning unison on for a channel means every note it plays costs all 3 of one chip's
voices at once, dropping that chip from 3-voice polyphony down to monophonic for as long as unison
stays on. If no SID in the channel's mask has all 3 voices free when a note arrives, the note is
simply refused rather than stealing from something else already sounding.

[cols="1,1,3"]
|===
|CC |Name |What it does

|41 |`CC_UNIS` |Unison mode on/off for this channel (`>= 64` = on, `< 64` = off) - only affects the *next* note-on, does not retroactively thicken anything already sounding
|42 |`CC_UDET` |Detune spread (0-127 range but takes the full 0-255 byte) - `0` is no detune at all (3 oscillators in unison), higher values spread the outer two oscillators further apart, up to roughly a semitone at full spread
|===

The center oscillator plays exactly the struck pitch; the other two are detuned up and down by the
spread amount around it. Every waveform/envelope/pulse-width CC and patch field still applies to all
3 oscillators together, same as any other multi-voice note - there is currently no way to give the
3 oscillators independently different waveforms or envelopes.

=== Panic and reset
[cols="1,1,3"]
|===
|CC |Name |What it does

|120 |`CC_ASOF` |All Sound Off - silences every held voice, on every channel, immediately
|121 |`CC_RACT` |Reset All Controllers - same effect as `CC_ASOF`
|123 |`CC_ANOF` |All Notes Off - same effect as `CC_ASOF`
|===

These three are not channel-scoped - sending any one of them on any channel silences the whole
device, SID voices and an FMOpl chip alike. Send this first when starting a new session or a new
song, in case a note was left stuck by earlier testing.

=== Cynthcart
Only relevant on a firmware built with `ONBOARD_CYNTHCART=1` (Cynthcart running through
USBSID-Player's own C64 core, see `USBSID-Pico-Cynthcart-manual`). These three are fixed CC
numbers, not remapped by the general CC map:

[cols="1,1,3"]
|===
|CC |Name |What it does

|85 |`CC_CEN` |Enable Cynthcart
|86 |`CC_CDI` |Disable Cynthcart
|87 |`CC_CRE` |Reset Cynthcart
|===

While Cynthcart is active it intercepts and reinterprets a number of the same CC numbers used
elsewhere in this document for its own controls (filter, envelope, tremolo, waveform selection,
...) - see the Cynthcart manual for that separate CC list, not this one.

=== Deprecated
The old "copy/link voice or SID" family (`CC_CVCE`/8, `CC_CSID`/9, `CC_LVCE`/40, `CC_LSID`/56) from
before this firmware's per-channel voice templates existed has been removed entirely, not just
disabled - there is no field for them left in the CC map at all. CC numbers 8, 9, 40 and 56 are
simply unassigned now, the same as any other CC this firmware has no handler for: silently ignored,
nothing logged.

=== Not wired
`CC_BMSB`/`CC_BLSB` (Bank Select MSB/LSB) and `CC_MOD`/`CC_MODL` (a second, separate Modulation
Wheel MSB/LSB pair distinct from `CC_PWM`) exist as fields in the CC map but have no compiled-in
default number (`0xFF`/255, outside the valid 0-127 CC range) and no handler bound to them. Bank
Select has nothing to select - with only 32 patches, Program Change alone already reaches every one
of them. These four are listed here only for completeness against the full CC map, not because
there is anything to send.

== Patches
A patch is a saved timbre: waveform, envelope, pulse width, filter settings, LFO, arpeggiator and
pitch bend range, all in one shot. Selecting one is a single MIDI Program Change (`0xC0`) -
programs 0-31 map to the 32 available patch slots, 32-127 do nothing (there is no Bank Select; with
only 32 patches, the program number alone already reaches all of them).

Loading a patch changes the channel's *current* template and pushes it live to every voice already
held on that channel - the same thing a live CC change to those same fields would do. It does not
touch that channel's routing (voice mask, polyphony, overrides) - a patch is a sound, not a wiring
change.

=== Factory patches
Patch 0 mirrors the compiled-in channel default (plain triangle, full sustain) - selecting it is a
safe, silent-to-change no-op. Patches 1-15 are a curated factory set so a fresh board has something
to play immediately:

[cols="1,3"]
|===
|Program |Instrument

|1  |Sawtooth lead
|2  |Pulse lead
|3  |Bass
|4  |Pluck
|5  |Organ
|6  |Filtered lead
|7  |Slow pad
|8  |Noise hit
|9  |Reed
|10 |Sync lead
|11 |Ring mod lead
|12 |Vibrato lead
|13 |Wah pad
|14 |Wide bass
|15 |Bright pluck
|===

Patches 16-31 are reserved for your own patches - zeroed (silent) until you save something into
them.

=== Authoring your own patches over SysEx
Patches can be written, read back, saved and reset entirely over MIDI - no config tool required.
Every command below is manufacturer ID `0x50`: `F0 50 <command> ... F7`.

[cols="1,1,3"]
|===
|Byte |Command |What it does

|`0x20` |`SYSEX_MIDI_PATCH_LOAD` |`F0 50 20 <slot> <48 nibbles> F7` - writes one patch's data into RAM. `<slot>` is 0-31.
|`0x21` |`SYSEX_MIDI_PATCH_DUMP` |`F0 50 21 <slot> F7` - asks the device to send that patch's current data back out over MIDI (as a `0x22` message)
|`0x22` |`SYSEX_MIDI_PATCH_DATA` |Device -> host response to a `0x21` request, and the same 48-nibble shape `0x20` expects as input
|`0x2A` |`SYSEX_MIDI_PATCH_SAVE` |`F0 50 2A <channel> <slot> F7` - the inverse of LOAD: captures the given channel's current live state into a patch slot, RAM only
|`0x10` |`SYSEX_MIDI_SAVE` |`F0 50 10 F7` - persists every patch and every channel's current routing to flash
|`0x11` |`SYSEX_MIDI_LOAD` |`F0 50 11 F7` - reloads whatever was last saved (also runs automatically at boot and on a MIDI System Reset)
|`0x12` |`SYSEX_MIDI_RESET` |`F0 50 12 F7` - erases every saved slot and resets every patch and channel back to compiled defaults
|===

Every field of a patch is sent as two 7-bit-safe nibble bytes (values `0x00`-`0x0F` each), 48
nibbles per patch in total, in this exact order: waveform+envelope+pulse-width template (5 fields),
filter cutoff (a 16-bit field, sent as 4 nibbles), resonance, filter routing, filter mode, LFO 1
waveform/rate/depth/destination (4 fields), arpeggiator mode/rate/octaves (3 fields), pitch bend
range, LFO 2 waveform/rate/depth/destination (4 fields), and unison on/off + detune spread (2
fields) - 23 fields, 48 nibbles. The last 6 fields (LFO 2 and unison) were appended after this
firmware's first release of patch authoring - an old 36-nibble dump sent to a firmware built with
these fields is refused (logged, not misread) rather than silently interpreted wrong; re-export it
from an up to date `patch_editor.py` to pick up the new fields.

`SYSEX_MIDI_PATCH_LOAD` only changes RAM - send `SYSEX_MIDI_SAVE` afterwards if you want it to
survive a reboot. Loading a patch into slot 0-15 quietly overwrites one of the factory instruments
above in RAM until the next `SYSEX_MIDI_LOAD`/reboot/`SYSEX_MIDI_RESET`; nothing stops you doing
this, it just means slots 0-15 are not truly "read-only," only pre-populated.

The easiest way to actually build patches by hand rather than hand-crafting SysEx bytes is
`patch-editor/patch_editor.py` in this repository - a small graphical tool with a knob/slider/switch
for every field above, Send/Read buttons that speak this exact protocol, and an importer for real
`.s3i`/`.op2`/`.wopl` instrument files (see that tool's own help text for FMOpl banks). It also has
a raw-hex box for pasting a SysEx line copied from anywhere else, including
`patch-editor/midibox_sid_presets.md` - roughly 500 MIDIbox SID V2 presets already converted into
this firmware's patch format, ready to paste and try.

[[Arp-tables]]
== Arp tables
A GoatTracker/SidWizard-style arp/chord table: instead of picking one of the arpeggiator's 5 fixed
shapes (up, down, up/down, random, as-played), a table is a small authored sequence of relative
semitone offsets from the arpeggiator's held root note (the first key you pressed) - your own custom
arpeggio shape, not just an algorithmic one. Everything about how the arpeggiator itself runs -
free-running or MIDI-clock-synced timing, `CC_ARPR`'s rate/division, `CC_ARPE` turning it on and off
- works identically whether it is stepping one of the 5 fixed shapes or a table; only *which offset
comes next* is different.

There are 16 table slots, each holding up to 16 steps. Table 0 is a repeating major triad
(`0, +4, +7` semitones) as a safe, non-silent default; tables 1-15 start empty (0 steps, meaning an
arpeggiator switched to table mode with an empty table plays nothing) until you author one.

=== Using a table
Three separate things have to line up for a table to actually play:

. `CC_ARPT` picks *which* table slot (0-15) to read.
. `CC_ARPM` set to "table" (the value at the very top of its range, e.g. `127`) picks table mode
  *as the pattern shape* - selecting a table with `CC_ARPT` alone does not switch a channel into
  table mode by itself.
. `CC_ARPE` turns the arpeggiator on for the channel, same as any other arp mode.

`CC_ARPO` (octave range) is ignored in table mode - a table's steps are already fully authored by
you; layering an automatic octave repeat on top would just be a second, conflicting way of
extending the same pattern.

=== Authoring tables over SysEx
Same manufacturer ID and LOAD/DUMP/DATA shape as patches and FMOpl patches, its own commands:

[cols="1,1,3"]
|===
|Byte |Command |What it does

|`0x27` |`SYSEX_MIDI_ARPTABLE_LOAD` |`F0 50 27 <slot> <36 nibbles> F7` - writes one table into RAM. `<slot>` is 0-15.
|`0x28` |`SYSEX_MIDI_ARPTABLE_DUMP` |`F0 50 28 <slot> F7` - requests that table's current data back
|`0x29` |`SYSEX_MIDI_ARPTABLE_DATA` |Device -> host response to a `0x28` request, and what `0x27` expects as input
|===

18 fields per table, each sent as two nibbles same as everything else in this document: 16 step
offsets (signed, `-128` to `+127` semitones, sent as the raw byte's two nibbles) followed by loop
start and step count - 36 nibbles total. `step_count` of `0` means the table is empty/unauthored and
the arpeggiator produces silence if switched to it; `loop_start` is which step the pattern jumps back
to once it reaches the end, so a table can have a distinct intro before settling into a repeating
tail (e.g. steps 0-2 play once, then it loops steps 1-2 forever with `loop_start = 1`,
`step_count = 3`).

`patch-editor/patch_editor.py`'s "Arp Table" tab covers authoring these visually - a spinbox per
step, loop-start/step-count sliders, and Send/Read buttons, plus a one-click "Select on channel"
action that sends `CC_ARPT` and switches `CC_ARPM` to table mode for you (still send `CC_ARPE`
separately to actually turn the arpeggiator on).

Tables are saved/loaded/reset by the same `SYSEX_MIDI_SAVE`/`LOAD`/`RESET` that covers patches and
channel routing - see <<Saving your settings>>.

== Saving your settings
`SYSEX_MIDI_SAVE`/`SYSEX_MIDI_LOAD`/`SYSEX_MIDI_RESET` (see above) persist every channel's routing,
every patch, every arp table, and the CC map itself, all together, to a dedicated flash region
separate from the board's own general configuration. A same-layout firmware reflash does not wipe this; a firmware
upgrade that changes the size of the saved data (a new field added to a future version) falls back
to compiled defaults safely rather than loading garbage.

A MIDI System Reset (`0xFF`, a real-time status byte, not a SysEx message) reloads whatever was
last saved - the expected behaviour for a synth's "reset," restoring your last saved sound rather
than blanking to bare factory defaults. `SYSEX_MIDI_RESET` is the separate, deliberate factory-reset
command if that is what you actually want.

Channel volume (`CC_VOL`) is the one exception: it is never saved or restored by any of the three
commands above, on purpose - there is no single "correct" volume to persist, and a client (a MIDI
player, ASID, your own sequencer) is expected to set it explicitly rather than inherit whatever a
previous session happened to leave it at. Expect a System Reset or a fresh boot to come back at a
flat, audible default volume regardless of what you last saved, even though every patch, routing and
arp table setting comes back exactly as saved.

[[FMOpl]]
== FMOpl
Some USBSID-Pico configurations have an FMOpl-capable chip installed in place of (or alongside) a
SID - either real OPL2 silicon, or a clone chip's software emulation of one (for example
SIDKick-pico's onboard FMOpl emulation). Where it exists, it is one specific chip slot on your
board, entirely separate from the SID voice pool: 2-operator FM synthesis, 9 simultaneous notes,
its own small set of MIDI controls. Everything in this section only applies if your board actually
has one configured - check with your board's config tool if you are not sure.

=== Targeting a channel at FMOpl
By default every MIDI channel targets a SID. A channel opts in to FMOpl explicitly, with `CC_FMEN`
(CC 88): send `127` to target that channel at the FMOpl chip instead, `0` to send it back to
targeting a SID. This is independent of the channel's own SID voice mask/routing - it does not
matter what SID(s) a channel is otherwise configured for, `CC_FMEN` overrides that entirely for as
long as it is on.

*A channel must have `CC_FMEN` enabled before Program Change or notes on it reach the FMOpl chip at
all.* Sending notes to an FMOpl-targeted channel without ever setting `CC_FMEN` first does nothing;
sending notes to a channel that used to target FMOpl but was reset back to SID with `CC_FMEN 0`
plays through the SID pool as normal, not the OPL chip.

`CC_FMEN` is sticky, per-channel, firmware state - it does not reset itself between sessions or
songs. If you use both SID and FMOpl channels across different pieces, explicitly reset each
channel to whichever it should be at the start of every song rather than assuming the board's
current state; see `patch-editor/strudel-demos/` for worked examples of exactly this.

=== FMOpl patches
Program Change on an FMOpl-targeted channel selects one of 32 FMOpl patch slots, the same
Program-Change-selects-a-slot idea as the SID side, but a completely different, much smaller patch
shape: 2 FM operators (a modulator and a carrier), each with its own multiplier, key-scale
level/total-level, attack/decay, sustain/release and waveform, plus a shared feedback/algorithm
setting (classic FM/series, or additive/parallel).

Slots 0-5 are compiled-in factory instruments:

[cols="1,2"]
|===
|Program |Instrument

|0 |Organ
|1 |Electric piano
|2 |Bass
|3 |Brass
|4 |Bell
|5 |Pad
|===

These were hand-designed from FM synthesis theory rather than copied from any particular commercial
sound bank - a reasonable starting point, not a claim of authenticity to any specific ROM. Slots
6-31 start silent, open for your own patches.

Authoring works the same way as the SID side, mirrored one-for-one, still manufacturer `0x50`:

[cols="1,1,3"]
|===
|Byte |Command |What it does

|`0x23` |`SYSEX_FMOPL_PATCH_LOAD` |`F0 50 23 <slot> <22 nibbles> F7` - writes one FMOpl patch into RAM
|`0x24` |`SYSEX_FMOPL_PATCH_DUMP` |`F0 50 24 <slot> F7` - requests that patch's data back
|`0x25` |`SYSEX_FMOPL_PATCH_DATA` |Device -> host response to a `0x24` request, and what `0x23` expects as input
|`0x2B` |`SYSEX_FMOPL_PATCH_SAVE` |`F0 50 2B <channel> <slot> F7` - captures the given channel's current live FMOpl state into a patch slot, RAM only
|===

11 raw bytes per patch (2 operators x 5 fields, plus one shared feedback/algorithm byte), 22
nibbles total. These patches are not yet included in the general `SYSEX_MIDI_SAVE`/`LOAD`/`RESET`
flash persistence - they live in RAM only for now and reset to the factory 6 on every reboot.
`patch-editor/patch_editor.py`'s FMOpl tab covers authoring these the same way it covers the SID
side, including an importer for real `.s3i` (Scream Tracker 3), `.op2` (DMX GENMIDI, the format
Doom/Heretic/Hexen use) and `.wopl` (OPL3BankEditor/libADLMIDI) instrument files.

=== Live control
Three controls reach an FMOpl-targeted channel live, on top of notes and Program Change:

[cols="1,1,3"]
|===
|CC |Name |What it does

|7 |`CC_VOL` |Channel volume - live, rewrites every currently held note's loudness immediately
|1 |`CC_PWM` |Modulation wheel - OPL2 has no pulse width to control, so this drives a live *modulator-only* brightness/FM-intensity boost instead: raising it makes the modulator louder relative to the carrier for a brighter, more overtone-rich tone, without touching overall volume
|- |Pitch Bend (`0xE0`) |Live, same semantics as the SID side - bends every held note on the channel using that channel's bend range
|===

Every other CC that has meaning on a SID-targeted channel (waveform bits, ADSR, filter, LFO,
arpeggiator, ...) currently does nothing on an FMOpl-targeted channel - there is no OPL equivalent
wired up for those yet.

=== Known limitations
- No LFO, no arpeggiator, no portamento on an FMOpl-targeted channel yet - notes, Program Change,
  volume, mod wheel and pitch bend only.
- Velocity is accepted but not yet used.
- A Program Change while a note is still held never retroactively changes that note's own timbre -
  matches how the SID side already behaves.
- FMOpl patches are RAM-only for now, not yet part of flash save/load/reset.

=== A note on tuning
The clock rate used to convert a MIDI note into the chip's own pitch registers has, so far, proven
harder to pin down than expected - it depends on the exact chip/emulation your board's FMOpl slot
actually uses, and the compiled-in default has not been confirmed correct on every configuration
tested. If notes sound obviously out of tune, `patch-editor/patch_editor.py`'s FMOpl tab has a
live, no-reflash-needed clock override with a held test note, specifically for dialing this in by
ear - see that tool's own help text. Under the hood this is `SYSEX_FMOPL_SET_CLOCK` (`0x26`):
`F0 50 26 <6 nibbles> F7`, a 3-byte (24-bit) big-endian clock value; an all-zero payload resets to
the compiled-in default.

== Development
More information about USBSID-Pico is available on the https://github.com/LouDnl/USBSID-Pico[github repo]

== License
include::license-software.adoc[]

include::license-hardware.adoc[]

Author: {author} - generated on {revdate}

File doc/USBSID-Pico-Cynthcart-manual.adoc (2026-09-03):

= *USBSID-Pico Cynthcart manual*
:author: LouD
:description: This document contains information about the embedded emulator running Cynthart and how to use it
:url-repo: https://www.github.com/LouDnl/USBSID-Pico
:revdate: {localdate}
:hide-uri-scheme:
:toc:
:toclevels: 4
:toc-placement!:

Author: {author} - generated on {revdate}

toc::[]
[%always]
<<<

== Disclaimer
include::disclaimer.adoc[]

== Thank you
First off thanks go out to Paul Slocum for creating Cynthcart and Mario Ballano for creating emudore. +

== Firmwares with Cynthcart embedded
Starting with firmware version v0.8.0 firmwares ending with `_cc` can run Cynthcart. +
For example `usbsidpico-v1.0_sp_cc.uf2` or `usbsidpico2-rgb-v1.3_sp_cc.uf2` +
Cynthcart runs through the embedded USBSID-Player, so all Cynthcart firmwares _also_ come with the onboard USBSID-Player included. See the `USBSID-Player-manual` file for more information.

**WARNING!** Because Cynthcart runs through the embedded USBSID-Player, the Pico MCU is overclocked to 250MHz, regardless of Pico type (rp2040 or rp2350). Passive cooling _might/could_ be needed.

== Usage
To start the emulator and Cynthcart you will need an USB-midi connection to USBSID=Pico.

=== CC messages
85 (0x55) ~ Enable Cynthcart +
86 (0x56) ~ Disable Cynthcart +
87 (0x57) ~ Reset Cynthcart (**not implemented yet**, currently a no-op)

=== Cynthcart control
For all other midi CC messages to control Cynthcart please refer to the Cynthcart manual. +
Page two in https://github.com/PaulSlocum/cynthcart/blob/master/manual/cynthcart2.0.1.pdf [cynthcart2.0.1.pdf] or https://github.com/PaulSlocum/cynthcart/blob/master/manual/cynthcart2.0.1_5x7.pdf[cynthcart2.0.1_5x7.pdf] +
On the right side of https://github.com/PaulSlocum/cynthcart/blob/master/manual/keyboardReferenceCharts/cynthcartCommandChart1.pdf[cynthcartCommandChart1.pdf] +
Or on the bottom of https://github.com/PaulSlocum/cynthcart/blob/master/manual/keyboardReferenceCharts/cynthcartCommandChart2.pdf[cynthcartCommandChart2.pdf]

== Development
More information about adorable (emudore-embedded) is available on the https://github.com/LouDnl/emudore-embedded[github repo]

== License
include::license-software.adoc[]

include::license-hardware.adoc[]

Author: {author} - generated on {revdate}

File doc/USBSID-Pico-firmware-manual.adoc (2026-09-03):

= *USBSID-Pico PCB firmware manual*
:author: LouD
:description: This document contains important information about the USBSID-Pico firmware & configuration
:url-repo: https://www.github.com/LouDnl/USBSID-Pico
:revdate: {localdate}
:hide-uri-scheme:
:toc:
:toclevels: 4
:toc-placement!:

Author: {author} - generated on {revdate}

toc::[]
[%always]
<<<

== Disclaimer
include::disclaimer.adoc[]

== Firmware types


 +
Each PCB revision is the firmware designator, please check your PCB revision, this is under the MOS logo and next to *USBSID-Pico* on your PCB. +
Firmware filenames contain the PCB revision number e.g. `usbsidpico-rgb-v1.X.uf2` is for PCB revision `v1.0` and for use with a black clone Pico containing an RGB LED.

== Firmware naming
Below are the filenames used for each Pico and board type, take great care in selecting the correct file for you Pico! +
**WARNING!** Do _NOT_ use the **RGB** firmware for any of the (non black) rp2040 or (non black) rp2350 Pico boards that do not contain an RGB LED, this can break your Pico! +

=== Board revision
The 1.X in each filename equals for the PCB revision as mentioned under firmware types. Don't worry if you flash a firmware for the incorrect PCB revision, this causes no harm. +

=== Firmware naming
`usbsidA-BC.uf2` examples: `usbsidpico-v1.0-rgb.uf2`, `usbsidpico2_w-v1.3.uf2` or `usbsidpico2-v1.5-rgb_sp`. +
A: The pico board type e.g. `pico`, `pico2`, `pico_2` or `pico2_w` +
B: The PCB version e.g. `v1.0`, `v1.3` or `v1.5` +
C: A combination of optional features e.g. `-rgb`, `_sp` or `_sp_cc`

=== Firmware naming per Pico type
Firmwares suitable for rp2040 Pico1 boards start with `usbsidpico-`
Firmwares suitable for rp2040 Pico1_w boards start with `usbsidpico_w-` +
Firmwares suitable for rp2350 Pico2 boards start with `usbsidpico2-` +
Firmwares suitable for rp2350 Pico2_w boards start with `usbsidpico2_w-` +

=== Naming examples for the rp2040 Pico1
Firmware naming suited for the pico 1 always start with `usbsidpico-` +
`usbsidpico-v1.X.uf2` for regular green rp2040 Pico boards. +
`usbsidpico-rgb-v1.X.uf2` for black clone rp2040 Pico boards with RGB LED onboard. +
`usbsidpico_w-v1.X.uf2` for regular green rp2040 PicoW boards.

**NOTE!** Due to the hardware limitations of the RP2040, highly demanding, cycle-exact SID tunes (dense per-cycle register writes, e.g. some digi/sample tunes) may not play at full speed on Pico1 or Pico1_w boards. Use a Pico2 or Pico2_w (rp2350) board for these tunes. +

=== Naming examples for the rp2350 Pico2
Firmware naming suited for the pico 2 always start with `usbsidpico2-` +
`usbsidpico2-v1.X.uf2` for regular green rp2350 Pico2 boards. +
`usbsidpico2-rgb-v1.X.uf2` for black clone rp2350 Pico2 boards with RGB LED onboard. +
`usbsidpico2_w-v1.X.uf2` for regular green rp2350 Pico2W boards.

=== Firmwares with embedded USBSID-Player
Starting with firmware version v0.6.0-BETA firmwares ending with `_sp` have an embedded emulator that can play PSID and RSID tunes and PSID64 PRG/P00 files. +
For example `usbsidpico2-v1.0_sp.uf2`, `usbsidpico2-v1.3-rgb_sp.uf2` or `usbsidpico2-v1.5_sp.uf2` +
This USBSID-Player is still in active development and some tunes might not work or play at all. +
The embedded USBSID-Player requires more then 256KB RAM and an overclocked CPU which makes this firmware only available for rp2350 Pico2 boards. +
**WARNING!** Whenever the USBSID-Player is used the Pico MCU is overclocked to 250MHz, regardless of Pico type. Passive cooling _might/could_ be needed. +
See the `USBSID-Player-manual` file for more information.

=== Firmwares with Cynthcart embedded
Starting with firmware version v0.8.0 firmwares ending with `_cc` can start Cynthcart with CC commands. +
For example `usbsidpico-v1.0_sp_cc.uf2`, `usbsidpico2-rgb-v1.3_sp_cc.uf2` or `usbsidpico2-v1.5_sp_cc.uf2` +
**WARNING!** Cynthcart runs through the embedded USBSID-Player, so the same 250MHz overclock (regardless of Pico type) and possible need for passive cooling applies here too. +
See the `USBSID-Pico-Cynthcart-manual` file for more information.

== How to flash your Pico
**NOTE**: +
[.underline]#When flashing a new firmware version, all previously configured settings will be reset to default. Use the commandline configtool to save your current settings to a `ini` file if you want to save them!# +
A Raspberry Pi Pico board is incredibly easy to flash, as it comes with a built in bootloader for flashing new firmwares in the `uf2` format. +
In order to flash a new firmware to your USBSID-Pico you will need to put the Pico into bootloader mode. +
This can be done in multiple ways:

With the cable already plugged into your computer and Pico and seated on the board (using buttons):

- Press and hold the `BOOTSEL` button on the Pico.
- Press and release the `RST` button on the USBSID-Pico board.
- Now release the `BOOTSEL` button.
- A new drive should appear on your computer called `RPI-RP2` or `RP2350` depending on your Pico type.
- Copy the correct `uf2` firmware file to this directory.
- After copying the Pico will reboot and your Pico is flashed.

With the cable not plugged in to your computer and Pico and also not seated on the board (using buttons):

- Plug in the USB cable to your Pico and not into your computer.
- While holding the `BOOTSEL` button on the Pico plugin the other end of the USB cable into your computer.
- Now release the `BOOTSEL` button.
- A new drive should appear on your computer called `RPI-RP2` or `RP2350` depending on your Pico type.
- Copy the correct `uf2` firmware file to this directory.
- After copying the Pico will reboot and your Pico is flashed.

With the cable already plugged into your computer and Pico and seated on the board (using software):

- With the GUI config tool
- Go to the `DEBUG` tab and click on `BOOTLOADER`
- A new drive should appear on your computer called `RPI-RP2` or `RP2350` depending on your Pico type.
- Copy the correct `uf2` firmware file to this directory.
- After copying the Pico will reboot and your Pico is flashed.

or

- Go to the config webpage (https://usbsid.loudai.nl/index.html?player=webusb&debug=usbsidpico):
- Connect to the board using `WebUSB (Hermit)` as emulator
- Click on `CONFIG` to open the configuration tab
- Scroll to the bottom of the page and click on `BOOTLOADER` in the box named `DEBUG`
- A new drive should appear on your computer called `RPI-RP2` or `RP2350` depending on your Pico type.
- Copy the correct `uf2` firmware file to this directory.
- After copying the Pico will reboot and your Pico is flashed.

or

- With the CLI config tool command in your `PATH` variable
- Type `cfg_usbsid -boot` to send the reboot to bootloader command
- A new drive should appear on your computer called `RPI-RP2` or `RP2350` depending on your Pico type.
- Copy the correct `uf2` firmware file to this directory.
- After copying the Pico will reboot and your Pico is flashed.

== Firmware configuration
USBSID-Pico has an extensive set of configuration options that expands with each firmware release. +

=== USBSID-Configtool
You can configurate your board by using the official USBSID-Configtool +
The tool is available here https://github.com/LouDnl/USBSID-Configtool[USBSID-Configtool] in the releases section

=== Commandline configuration tool
You can configurate your board with:
  - the commandline config-tool
  - the commandline config-tool with the Python Configuration GUI by ISL/Samar if you prefer a GUI.

==== Python Configuration GUI downloads
https://github.com/LouDnl/USBSID-Pico/blob/master/examples/config-tool/cfg_usbsid_GUI.py[Download script] +
Python3 -> https://www.python.org/downloads/[Download] +
TkInter -> https://tkdocs.com/tutorial/install.html[Installation guide] +
And either one of the Linux or Windows CLI downloads below

==== Linux / Windows downloads
The latest version of the CLI config tool is available in a zip file called `tools.zip` from release v0.6.0-BETA and up

==== Windows downloads
If the DLL's are missing from the zip file you can always download them from here: +
https://github.com/LouDnl/USBSID-Pico/blob/master/examples/config-tool/libusb-1.0.dll[Download DLL 1] +
https://github.com/LouDnl/USBSID-Pico/blob/master/examples/config-tool/libwinpthread-1.dll[Download DLL 2]

=== Configuration web page (for Chrome/Edge based browsers using webusb)
https://usbsid.loudai.nl/?player=webusb[USBSID web configuration tool] (requires a Chrome based browser). +
If needed you can change your USBSID configuration after selecting WebUSB and clicking on `Open config`. +
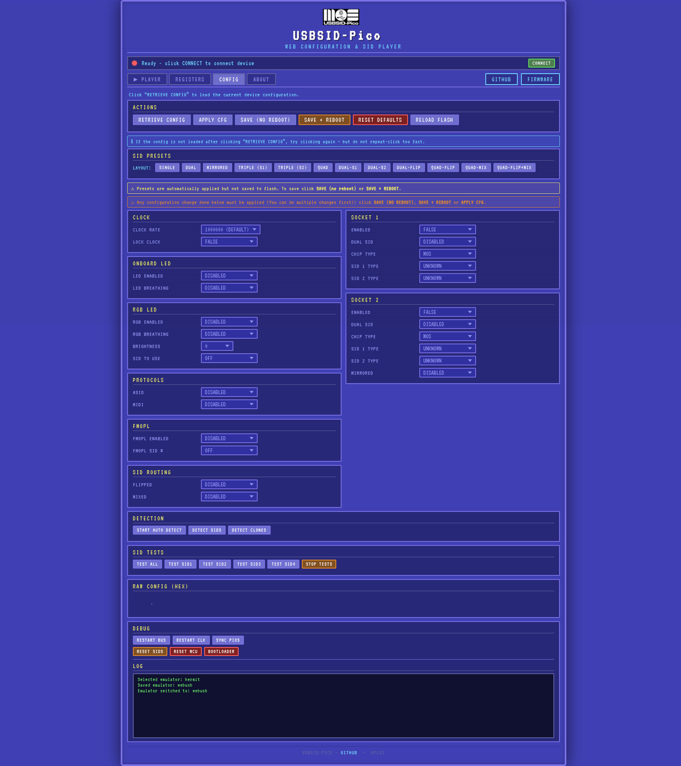
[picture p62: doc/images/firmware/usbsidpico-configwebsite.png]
 +
_The player is set up with borrowed code from Deepsid using Hermit's JsSID implementation._

=== Default configuration (depends on the board version)
The default configuration differs slightly between Pico1 (rp2040) and Pico2 (rp2350) boards. +
An explanation for these settings can be found further on in this document. +
Board clock rate: `1000000Hz (DEFAULT)` for rp2040, `985248Hz (PAL)` for rp2350 +
Clock rate locked: `False` +
Audio mode: `Mono` +
Preset silent auto detection: `False` (`True` for PCB revision v1.5+) +
Socket One Enabled: `True` +
Socket One Dualsid enabled: `False` +
Socket One Chiptype: `Unknown` +
Socket One SID 1 type: `Unknown` +
Socket One SID 2 type: `N/A` +
Socket Two Enabled: `True` +
Socket Two Dualsid enabled: `False` +
Socket Two Chiptype: `Unknown` +
Socket Two SID 1 type: `Unknown` +
Socket Two SID 2 type: `N/A` +
Socket Two Act as One: `False` +
Flip Socket One and Socket Two: `False` +
Mix socket addresses (Quad SID): `False` +
LED Enabled: `True` +
LED Idle breathe enabled: `True` +
RGBLED Enabled: `False` (`True` for RGB Pico's) +
RGBLED Idle breathe enabled: `False`  (`True` for RGB Pico's) +
RGBLED Brightness: `0` (`127` for RGB Pico's) +
RGBLED SID to use: `-1` (`1` for RGB Pico's) +
CDC Enabled: `True` +
WebUSB Enabled: `True` +
Asid Enabled: `True` +
Midi Enabled: `True` +
FMOpl Enabled: `False` +
FMOpl SID no: `0`

=== Board clock rate
The Commodore64 has different clockrates depending on where you live, USBSID-Pico supports these different clock rates as configuration setting. +
Supported SID players will automatically send a new clock rate request to the board to switch to. +
Available options are: +
`DEFAULT 1000000Hz`, `PAL 985248Hz`, `NTSC 1022727`, `DREAN 1023440`, `NTSC2 1022730`

=== Clock rate locked
Some players start sending data directly after the clockrate is changed. While in most cases this is no issue, some SID clones need some time to start up. This causes issues when the clock rate is changed on the fly. +
Also changing the clock rate multiple times after another can cause data corruption to the SID which causes garbled sound. +
To overcome this it is possible to lock the clockrate to the current setting it is set to. This blocks the ability for on the fly change requests. +
Available options are: +
`False`, `True`

=== Audio mode
_PCB revision v1.3 only_ +
Sets the audio mode for the headphone jack and audio out pins. +
When set to `Mono` the audio of both SID sockets will be combined to mono. +
When set to `Stereo` the audio of both SID sockets will be separated into left for `SID1` and right for `SID2` +
Available options are: +
`Mono`, `Stereo`

=== Lock audio switch
_PCB revision v1.3 only_ +
Locks the audio switch into its current state (`Mono` or `Stereo`) and prevents it from being changed. +
Available options are: +
`False`, `True`

=== SID Voltage & Configuration confirmation
_PCB revision v1.5 only_ +
The board boots with 5v and 9v enabled to automatically detect any changes in the socket / chip configuration, it does this by running a chip and SID detection. +
When a change is detected the boards turns off the 9v and 5v and the onboard (RGB)LED starts flashing, making the board unusable until the configuration is validated and confirmed. +
_Please verify the configuration with care before confirming, failure to do so might damage/kill your SID chips, and we don't want that!_ +
There are multiple ways to validate and confirm the configuration: +
**GUI Configtool** +
On opening the configtool and connecting to the board there will be a text stating the configuration needs to be confirmed. Verify the config on the `SOCKETS` tab and when done click `CONFIRM` +
 +
**Web Configtool** +
On opening the config website and connecting to the board there will be a text stating the configuration needs to be confirmed. Verify the config on the `CONFIG` tab by clicking `RETRIEVE CONFIG` first and when done validating click `CONFIRM CONFIG`. Both buttons will glow when a click is needed +
 +
**CLI Configtool** +
First read the configuration with `cfg_usbsid -r`, the printed configuration will have a line that states the config needs confirmation. You can do this with `cfg_usbsid -ack`.

=== Disable socket change detection
_PCB revision v1.5 only_ +
When you have a fixed socket setup, e.g. you do not plan on changing the chips anytime soon, it is possible to disable the change detection on boot. This will make the board start up with 5v and 9v and then - if 12v is required - switch to the required voltage setting during the boot process by switching the voltage back off, setting the correct hv voltage and then switching it back on. +
When the socket detection _is_ on, the board will _always_ try to detect any changes in the configuration _before_ the required voltage is applied. +
By setting the `Disable socket detection on boot` option you can control the above behaviour: +
**GUI Configtool** +
 +
**Web Configtool** +
 +
**CLI Configtool** +
Change the behaviour with `cfg_usbsid -sad N` where N can be 0 (disabled) or 1 (enabled)

=== Socket settings
Each socket comes with its own set of configurable options.

==== Socket One/Two Enabled
Enable or disable the use of this socket. +
Available options are: +
`False`, `True`

==== Socket One/Two Dualsid enabled
Enable or disable dualsid for this socket. +
This requires the `Chiptype` for this socket to be set to any clone chip (not `MOS`) and ofcourse a dual SID supporting SID clone with support of connecting the A5 address line. +
Available options are: +
`False`, `True`

==== Socket One/Two Chiptype
Set the type of SID chip for this socket. +
Available options are: +
`MOS` (real SID), `Unknown`, `SKPico`, `ARMSID`, `ARM2SID`, `FPGASID`, `RedipSID`, `PDSID`, `BackSID`, `SIDEmu`

==== Socket One/Two SID 1 type
Available options are: +
`Unknown`, `N/A`, `8580`, `6581`, `FMOpl`

==== Socket One/Two SID 2 type
Available options are: +
`Unknown`, `N/A`, `8580`, `6581`, `FMOpl`

==== Socket Two Act as One
When enabled, this will disable other Socket Two settings and this socket will receive all writes from Socket One as it were mirrored. +
Available options are: +
`False`, `True`

==== Flip Socket One and Socket Two
When enabled, Socket One and Socket Two are swapped so Socket One's physical position responds as Socket Two and vice versa. +
Available options are: +
`False`, `True`

==== Mix socket addresses (Quad SID only)
When enabled, addresses for a 4-SID setup are mixed between sockets instead of being assigned sequentially per socket. Combine with `Flip` for the remaining address orderings. +
Available options are: +
`False`, `True`

==== Preset silent auto detection
When enabled, the board silently re-runs chip/SID auto detection before applying a preset. +
Default is `False` on PCB revision v1.0~v1.3 and `True` on PCB revision v1.5+. +
Available options are: +
`False`, `True`

=== LED Enabled
Disable or enable the use of the onboard LED. +
When enabled this automatically enables the LED as Vu meter for the voices of `SID1`. +
Available options are: +
`False`, `True`

=== LED Idle breathe enabled
Disable or enable the idle breathing effect for the onboard LED. +
Available options are: +
`False`, `True`

=== RGBLED Enabled
_Only for black Pico clones with onboard RGB LED_ +
Disable or enable the use of the onboard RGBLED. +
When enabled this automatically enables the RGBLED as Vu meter. +
Available options are: +
`False`, `True`

=== RGBLED Idle breathe enabled
_Only for black Pico clones with onboard RGB LED_ +
Disable or enable the idle breathing effect for the onboard RGBLED. +
Available options are: +
`False`, `True`

=== RGBLED Brightness
_Only for black Pico clones with onboard RGB LED_ +
Set the maximum brightness of the onboard RGBLED. +
Available range is: +
`0 to 255`

=== RGBLED SID to use
_Only for black Pico clones with onboard RGB LED_ +
Set the SID of which to use the voices for the Vu meter. +
Available options are (depending on your SID configuration): +
`-1` off, `0` off, `1` SID1, `2` SID2, `3` SID3, `4` SID4

=== FMOpl Enabled
Requires a SID clone with FMOpl capabilities, the socket `Chip type` set to `Clone` and `SID type` set to `FMOpl` before activation! +
Available options are: +
`False`, `True`

=== FMOpl SID number
_This setting cannot be changed manually_
This setting will automatically be set to the correct SID number when all requirements are met as described under `FMOpl Enabled`

=== CDC Enabled
_This config setting is intended for future use_
Available options are: +
`False`, `True`

=== WebUSB Enabled
_This config setting is intended for future use_
Available options are: +
`False`, `True`

=== Asid Enabled
Disable or enable ASID protocol handling (SysEx-based SID playback over MIDI). +
Available options are: +
`False`, `True`

=== Midi Enabled
Disable or enable MIDI input handling (note/CC/voice control of the SID(s)). +
Available options are: +
`False`, `True`

== License
include::license-software.adoc[]

include::license-hardware.adoc[]

Author: {author} - generated on {revdate}

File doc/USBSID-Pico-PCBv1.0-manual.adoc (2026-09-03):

= *USBSID-Pico PCB revision v1.0 manual*
:author: LouD
:description: This document contains important information about USBSID-Pico PCB revision v1.0
:url-repo: https://www.github.com/LouDnl/USBSID-Pico
:revdate: {localdate}
:toc:
:toc-placement!:

Author: {author} - generated on {revdate}

toc::[]
[%always]
<<<

== Disclaimer
include::disclaimer.adoc[]

== PCB top overview
.Click image for larger view
[#img-v13top,link=images/v1.0/v1.0-explained.png]
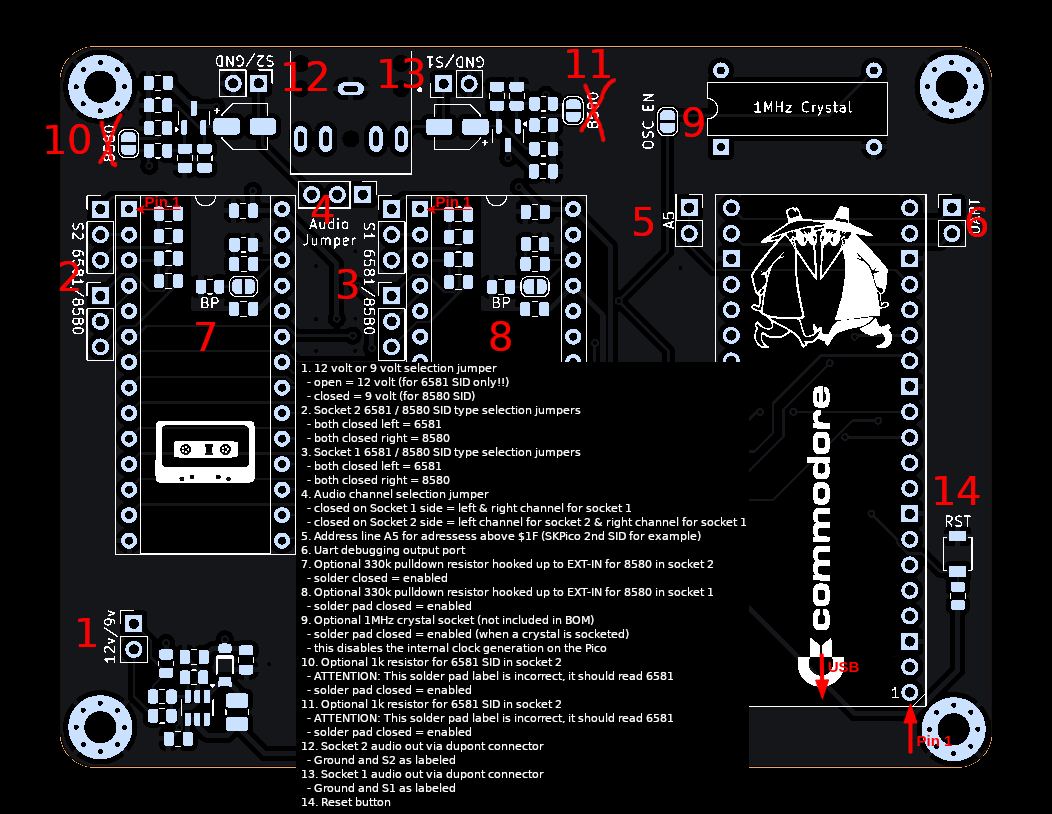
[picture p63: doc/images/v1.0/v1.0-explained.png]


[%always]
<<<

== RaspberryPi Pico placement orientation
In the placement overview image above there are 2 markings that designate toward what direction the Pico boards needs to be placed. +
The `USB` marking and arrow point in the direction towards where the Pico USB port needs to be. +
The `Pin 1` marking and arrow points towards where pin 1 of the Pico board needs to be.

== SID placement orientation
In the PCB overview image at the top of this document each SID socket has `Pin 1` marked with text and an arrow. +
Please use your full attention when placing your SID chips on the board so they in the correct orientation. +
_Incorrect placement orientation will result in frying your precious SID chip unicorn and creating a nice keychain!_
*_I am not responsible for your broken SID chips!_*

== 1. 12 volt or 9 volt selection jumper
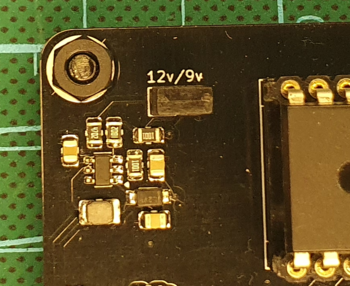
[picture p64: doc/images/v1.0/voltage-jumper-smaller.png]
 +

- open = for 6581 SID only!! (12 volts)
- closed = for 8580 SID (9 volts)

== 2. Socket 2 6581 / 8580 SID type selection jumpers
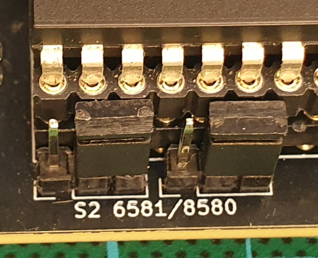
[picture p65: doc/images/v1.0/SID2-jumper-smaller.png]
 +

- both closed left = 6581
- both closed right = 8580

== 3. Socket 1 6581 / 8580 SID type selection jumpers
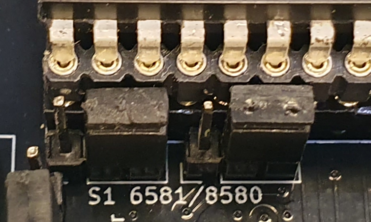
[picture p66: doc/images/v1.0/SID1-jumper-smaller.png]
 +

- both closed left = 6581
- both closed right = 8580

== 4. Audio channel selection jumper
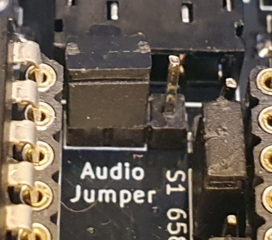
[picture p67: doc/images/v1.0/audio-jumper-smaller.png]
 +

- closed on Socket 1 side = left & right channel for socket 1
- closed on Socket 2 side = left channel for socket 2 & right channel for socket 1

Optionally you could use a 3-way jumper cap for mono audio with both SID chips at the same time.

== 5. Address line A5
For adressess above $1F (SKPico 2nd SID for example) +
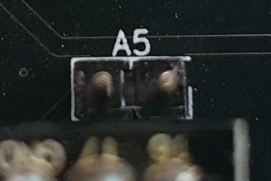
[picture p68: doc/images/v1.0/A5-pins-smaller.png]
 +
Both pins are routed to the same GPIO for using adresses higher then $20

== 6. Uart debugging output port
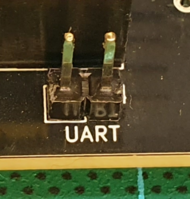
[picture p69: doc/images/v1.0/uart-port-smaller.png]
 +

- TX on the right
- RX on the left

== 7. Optional 330k pulldown resistor hooked up to EXT-IN for 8580 filter bypass in socket 2
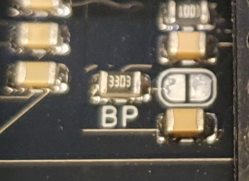
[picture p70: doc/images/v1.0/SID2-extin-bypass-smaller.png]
 +
Solder pad closed = enabled

== 8. Optional 330k pulldown resistor hooked up to EXT-IN for 8580 filter bypass in socket 1
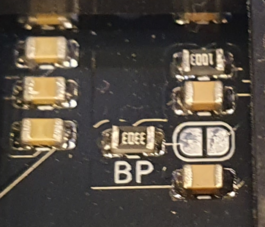
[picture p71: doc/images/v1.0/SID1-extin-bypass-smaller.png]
 +
Solder pad closed = enabled

== 9. Optional 1MHz crystal socket (not included in BOM)
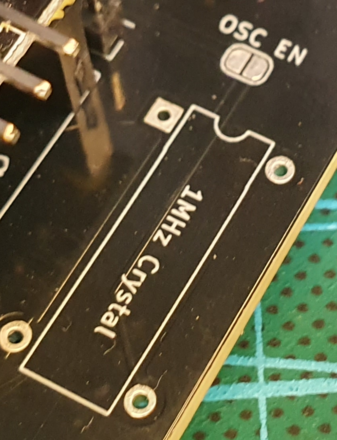
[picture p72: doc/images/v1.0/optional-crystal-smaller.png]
 +
Solder pad closed = enabled (when a crystal is socketed). +
This disables the internal clock generation on the Pico

== 10. Optional 1k resistor for 6581 SID in socket 2
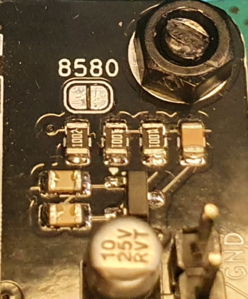
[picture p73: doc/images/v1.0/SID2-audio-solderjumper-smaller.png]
 +
**ATTENTION!**: _On older v1.0 PCB's this solder pad is incorrectly labelled, it should read 6581!_ +
Solder pad closed = enabled

== 11. Optional 1k resistor for 6581 SID in socket 2
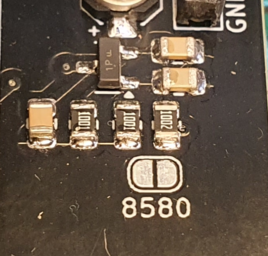
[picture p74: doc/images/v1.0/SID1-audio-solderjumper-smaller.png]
 +
**ATTENTION!**: _On older v1.0 PCB's this solder pad is incorrectly labelled, it should read 6581!_ +
Solder pad closed = enabled

== 12. Socket 2 audio out via dupont connector
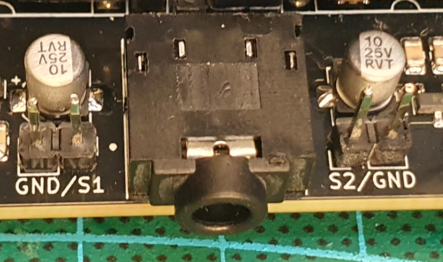
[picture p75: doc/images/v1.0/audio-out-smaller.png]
 +
Socket 2 output to the right of the headphone jack +
Ground and S2 as labeled

== 13. Socket 1 audio out via dupont connector
 +
Socket 1 output to the left of the headphone jack +
Ground and S1 as labeled

== 14. Reset button
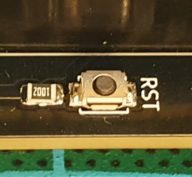
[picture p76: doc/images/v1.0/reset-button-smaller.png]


== Volume daughterboard
An optional Volume daughterboard is available for independent left/right channel volume control. It is _not_ tested with v1.0 PCB's and requires an extra ground mod - see the `USBSID-Volume-daughterboard` manual for details.

== License
include::license-software.adoc[]

include::license-hardware.adoc[]

Author: {author} - generated on {revdate}

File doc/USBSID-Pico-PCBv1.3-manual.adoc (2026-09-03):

= *USBSID-Pico PCB revision v1.3 manual*
:author: LouD
:description: This document contains important information about USBSID-Pico PCB revision v1.3
:url-repo: https://www.github.com/LouDnl/USBSID-Pico
:revdate: {localdate}
:toc:
:toc-placement!:

Author: {author} - generated on {revdate}

toc::[]
[%always]
<<<

== Disclaimer
include::disclaimer.adoc[]

== PCB top overview
.Click image for larger view
[#img-v13top,link=images/v1.3/v1.3b-top-marked.png]
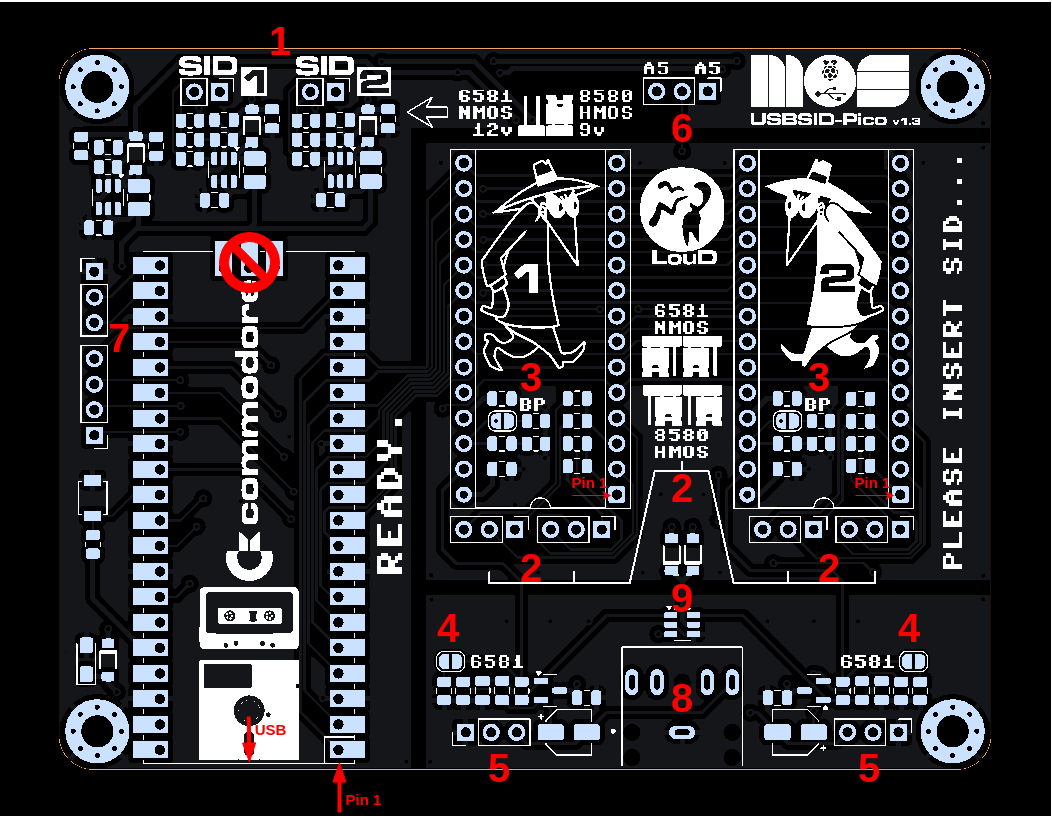
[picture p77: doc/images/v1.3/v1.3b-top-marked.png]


[%always]
<<<

== RaspberryPi Pico placement orientation
In the PCB overview image at the top of this document there are 2 markings that designate toward what direction the Pico boards needs to be placed. +
The `USB` marking and arrow point in the direction towards where the Pico USB port needs to be. +
The `Pin 1` marking and arrow points towards where pin 1 of the Pico board needs to be.

== Optional Pico placements
The USBSID-Pico v1.3 PCB has the option for you to solder your Pico directly to the PCB using the Pico's castelated edges. +
This creates more space and can be useful if you want to use a SID clone like FPGASID in socket 1.
[.float-group]
--
[.left]

The Pico debug pins are not connected and not used, you do not have to solder these pins.
--

== Optional header placement
If you would like to use a (semi)closed case like the spotUP case but want to keep access to the filter and power jumpers, +
it's possible to solder the jumper headers on the bottom side of the PCB for easy access. +
There is a bottom case STL available that has special openings for this like in the photo below. +
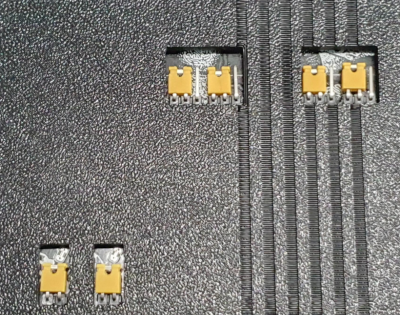
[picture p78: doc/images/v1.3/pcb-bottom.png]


== SID placement orientation
In the PCB overview image at the top of this document each SID socket has `Pin 1` marked with text and an arrow. +
Please use your full attention when placing your SID chips on the board so they are in the correct orientation. +
_Incorrect placement orientation will result in frying your precious SID chip unicorn and creating a nice keychain!_
*_I am not responsible for your broken SID chips!_*

== 1. Socket SID type / voltage selection jumper
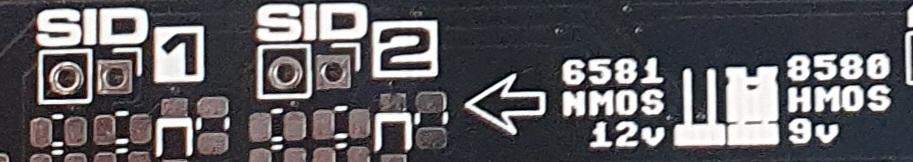
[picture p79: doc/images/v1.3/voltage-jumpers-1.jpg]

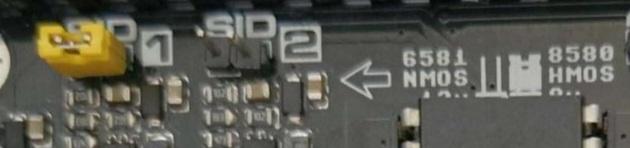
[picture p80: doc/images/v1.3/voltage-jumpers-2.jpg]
 +
Voltage control per SID/socket.

.`SID1` is for socket 1 (left) and `SID2` is for socket 2 (right)
* No jumper cap (open) = for `6581` SID only!! (`12 volts`)
* Jumper cap (closed) = for `8580` SID (`9 volts`)
//-

_Please be careful and choose the correct voltage setting!_ +
 +
_Note:_ +
_Most clone SID chips do not use the higher voltage pin. Please check with the SID clone manufacturer (manual) if you are not sure!_

== 2. SID filter selection jumpers
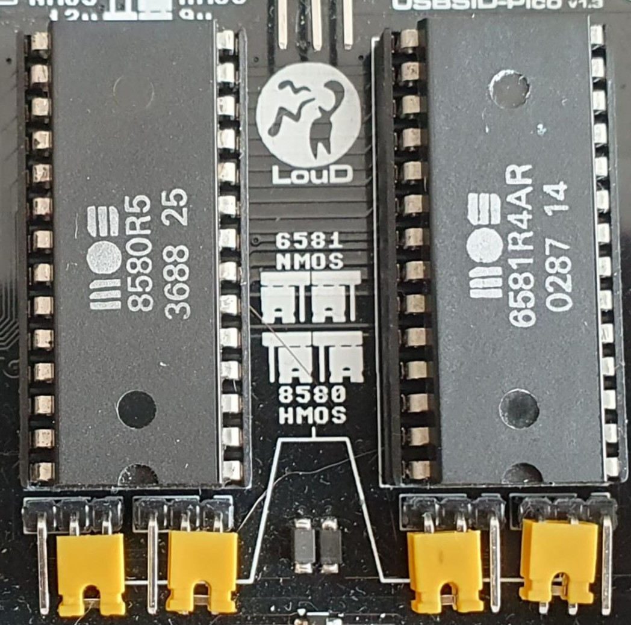
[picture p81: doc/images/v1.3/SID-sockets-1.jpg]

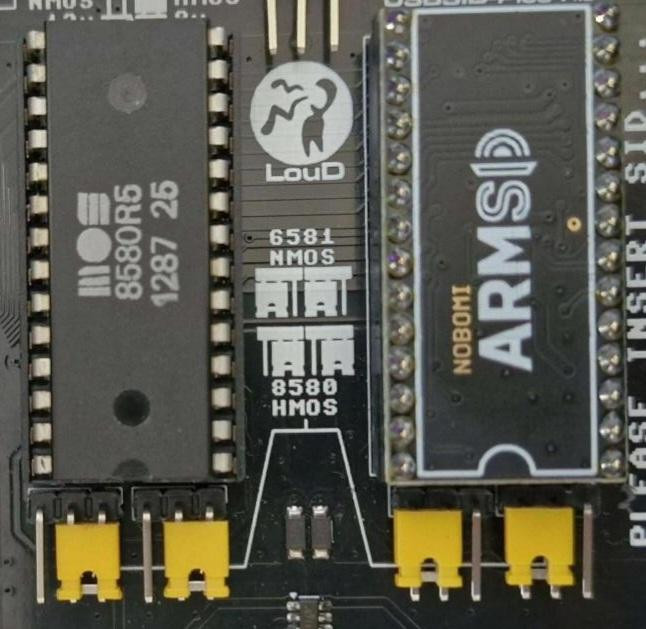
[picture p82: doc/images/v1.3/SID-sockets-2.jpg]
 +

[.float-group]
--
[.left]
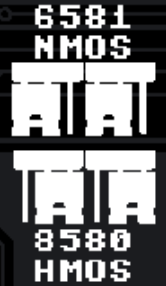
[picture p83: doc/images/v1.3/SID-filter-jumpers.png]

Each socket has 2 jumpers that need to be in the same position. +
These 2 jumpers control which filter capacitors are active for that socket. +
The 2 left jumpers are for `SID1/socket1` and the 2 right jumpers are for `SID2/socket2`
--

* 2 jumpers left (closed) = `MOS6581` filters (`470pF`)
* 2 jumpers right (closed) = `MOS8580` filters (`22nF`)
//-

*Accidentally mixing these jumpers should not do any harm but might make audio sound worse.* +
_Note:_ +
_Most clone SID chips do not use the filter capacitors. Please check with the SID clone manufacturer (manual) if you are not sure!_ +
_Each set of jumpers respectively controls the capacitance for `CAPA` and `CAPB` for that SID._ +

== 3. Digiboost
[.float-group]
--
[.left]

Inside each SID socket there is a solderpad marked `BP`. This provides an optional bypass by directly pulling SID Pin 26 `EXT IN` to `GND` with a 330k resistor.
--
This bypass is also known as `digi-boost` for `8580` SID chips. +
_Note:_ +
_The digiboost resistor value is fixed._

== 4. `6581` pulldown resistor
[.float-group]
--
[.left]

For each audio circuit there is a solder pad marked `6581`.
--
This is an extra pull down resisitor required when using a `MOS6581` SID as per Commodore64 schematic. +
_Note:_ +
_Your `6581` SID will work without this solderpad but audio quality may vary._

== 5. Audio pins
[.float-group]
--
[.left]

Each socket has an optional header with 3 pins. +
The pinout is from left to right `GND,IN,OUT` +
_(markings are on the bottom of the PCB)_
--

[.float-group]
--
[.left]

Each socket has a solder pad marked `EXT IN` on the bottom of the PCB. +
Close this to connect the `IN` pin of the audio header to the SID chip `EXT IN` pin.
--

*IMPORTANT:* +
*There is no audio filter circuit connected to the EXT IN pin, you have to provide the audio in filter yourself!* +
*_I take no responsibility if you break your SID chip by using this pin!_*

== 6. Address line & audio switch pins
[.float-group]
--
[.left]

Optional header for connecting the `A5` address line to Clone SID chips. +
There are 2 `A5` pins, one for each socket that are both connected to the same GPIO pin. +
The pinout is from left to right `A5,SW,A5` +
_(markings are on the bottom of the PCB)_
--
The `SW` pin is an optional pin for adding a switch to control the mono / audio switch manually.

== 7. GPIO pins
Optional header for UART pins and unused GPIO for future use. +
_(markings are on the bottom of the PCB)_

== 8. Audio circuit
[.float-group]
--
[.left]
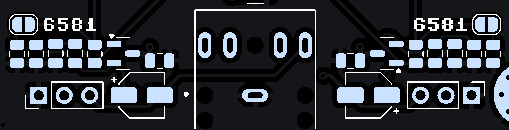
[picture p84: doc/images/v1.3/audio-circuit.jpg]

Each socket has it's own audio circuit with a voltage follower audio filter. +
This is also used in the Commodore64 and on the SID Blaster.
--

== 9. Audio switch
Last but not least, the digital audio switch IC. Switching from mono (both SID chips play over left and right) to Stereo (SID1 over the left channel and SID2 over the right channel) and back is handled by the firmware through settings or automatically by supported players.

[%always]
<<<

== Volume daughterboard
An optional Volume daughterboard is available for independent left/right channel volume control. It is compatible with v1.3 boards with a small modification to provide voltage - see the `USBSID-Volume-daughterboard` manual for details.

== PCB bottom overview
.Click image for larger view
[#img-v13bottom,link=images/v1.3/v1.3b-bottom.png]
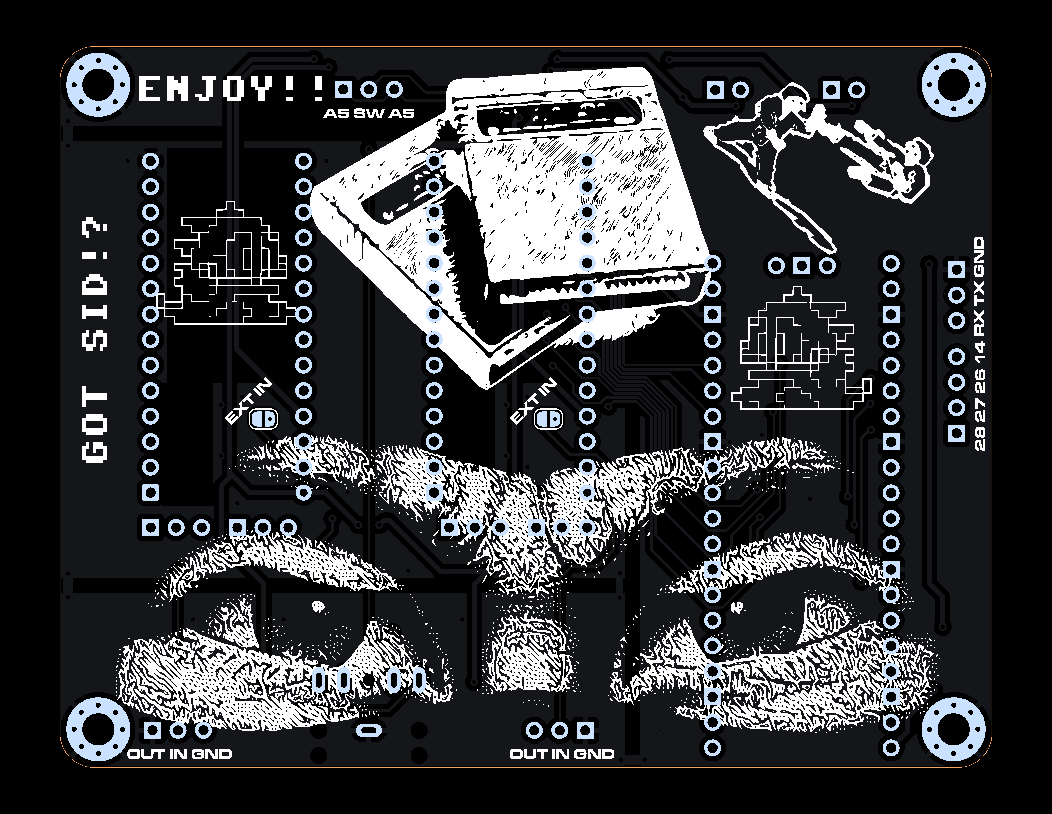
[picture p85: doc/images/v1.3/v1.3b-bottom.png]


== License
include::license-software.adoc[]

include::license-hardware.adoc[]

Author: {author} - generated on {revdate}

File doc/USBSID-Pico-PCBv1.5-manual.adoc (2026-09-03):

= *USBSID-Pico PCB revision v1.5 manual*
:author: LouD
:description: This document contains important information about USBSID-Pico PCB revision v1.5
:url-repo: https://www.github.com/LouDnl/USBSID-Pico
:revdate: {localdate}
:toc:
:toc-placement!:

Author: {author} - generated on {revdate}

toc::[]
[%always]
<<<

== Disclaimer
include::disclaimer.adoc[]

== PCB top overview
.Click image for larger view
[#img-v15top,link=images/v1.5/v1.5c-top.png]


[%always]
<<<

== Extra protection
The audio out jack and pins are now protected with ESD protection diodes. +
And the left and right channel in the audio jack will be pulled to ground with a 10k softpull resistor when no jack is inserted by using the jack switches.

== Jumperless design
The v1.5 board is a jumperless design. This means that settings that were previously controlled with jumpers are now configured with settings in the firmware. The settings can be configured with the USBSID-Configtool. +

== Automatic settings
In line with the jumperless design some settings are set automatically. +

SID type controls the voltage: +
- The firmware will do a chip detect on startup to figure out if there is a clone chip or a real SID and what real SID is seated. +
- This detection routine detects any change on startup and will lock the board with a blinking LED indicating you need to verify the socket configuration in the configtool. +
- 8580 means 9 volts +
- 6581 means 12 volts +
- All clone SID chips will be automatically powered with 9 volts. +
- It is possible to turn off this detection routine at startup and override the voltage setting. +

SID type also controls the filter capacitor setting, the 8580 digiboost resistor and 6581 shunt resistor: +
- 8580 means automatic digiboost and 22nF filter capacitors +
- 6581 means no digiboost, shunt resistor enabled and 470pF filter capacitors +

Socket voltage control on v1.5+ is more than just the automatic 9v/12v selection above - power to both SID sockets can also be fully switched off and back on again, independent of SID type, through the configtool or firmware settings.

== RaspberryPi Pico placement orientation
In the PCB overview image at the top of this document there are 2 ways from which you can get what direction the Pico boards needs to be placed. +
The `diskette` marking is where the Pico USB port needs to be. +
The `Pin 1` marking, the little square around the solder pad at the outer edge of the board is where the Pico USB port needs to be.

== Optional Pico placements
The USBSID-Pico v1.5 PCB has the option for you to solder your Pico directly to the PCB using the Pico's castelated edges. +
This creates more space and can be useful if you want to use a SID clone like FPGASID in socket 1.

== SID placement orientation
In the PCB overview image at the top of this document each SID socket has a little cut out which indicates the SID placement orientation. +
Please use your full attention when placing your SID chips on the board so they are in the correct orientation. +
_Incorrect placement orientation will result in frying your precious SID chip unicorn and creating a nice keychain!_
*_I am not responsible for your broken SID chips!_*

== Address line
The pins at the top of the board marked with A5 are for connecting an optional extra wire for some clone SID chips that support a second SID.

==  Audio pins
Each SID socket has an optional header with 4 pins. +
The pinout for SID1 is from left to right `VDD,GND,IN,OUT` +
And the pinout for SID2 is from left to right `OUT,IN,GND,VDD` +
_(markings are on the bottom of the PCB)_
*IMPORTANT:* +
*There is no audio filter circuit connected to the EXT IN pin, you have to provide the audio in filter yourself!* +
*_I take no responsibility if you break your SID chip by using this pin!_*

== UART pins
Optional header for UART pins. +
_(markings are on the bottom of the PCB)_ +
*NOTE:* The `USE_PIO_UART` firmware build option (PIO UART on GPIO 26/27) is not available on v1.5+ boards, those GPIO pins are used for socket voltage control instead.

== Audio switch
Same digital audio switch IC as on v1.3, carried forward unchanged. Switching from mono (both SID chips play over left and right) to Stereo (SID1 over the left channel and SID2 over the right channel) and back is handled by the firmware through settings or automatically by supported players. +
The jumperless v1.5 design has no physical `SW` pin for manual switching - this is configured entirely through the firmware/configtool.

[%always]
<<<

== Volume daughterboard
An optional Volume daughterboard is available for independent left/right channel volume control. It is plug and play compatible with v1.5+ boards - see the `USBSID-Volume-daughterboard` manual for details.

== PCB bottom overview
.Click image for larger view
[#img-v15bottom,link=images/v1.5/v1.5c-bottom.png]
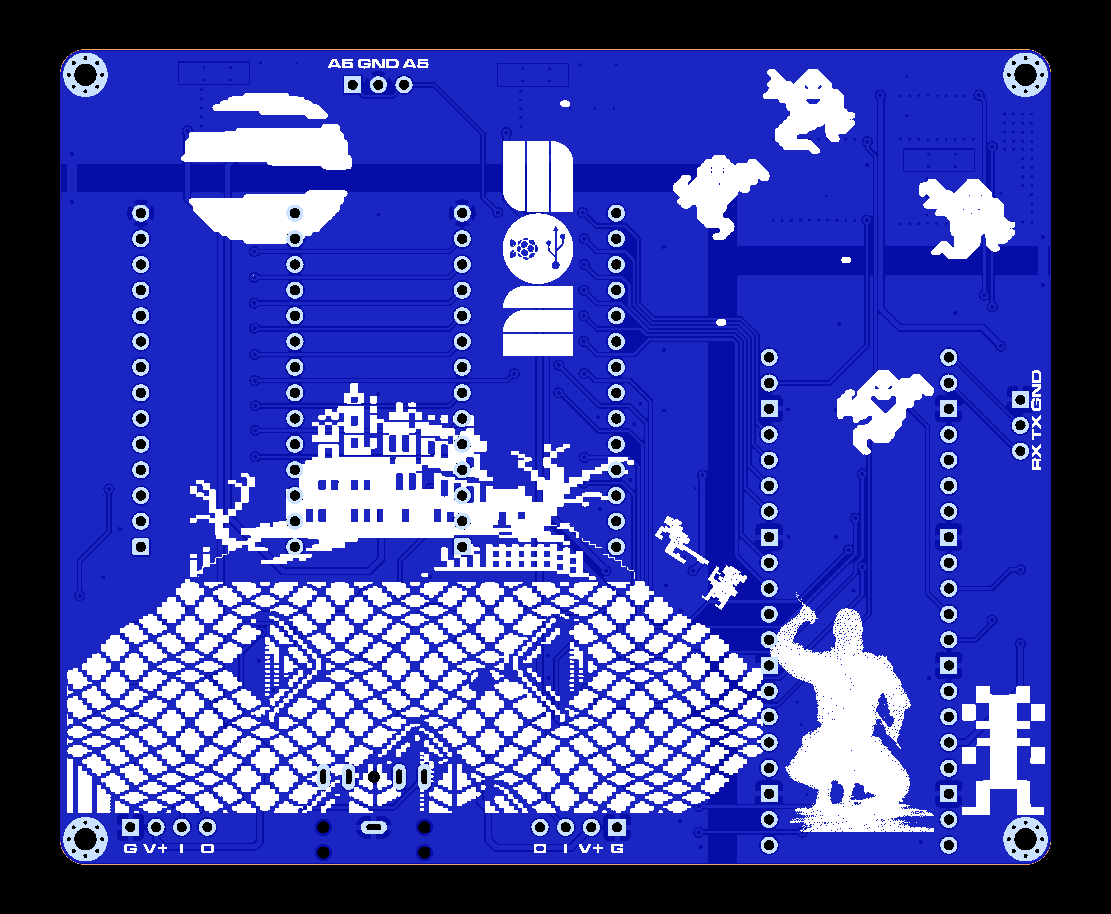
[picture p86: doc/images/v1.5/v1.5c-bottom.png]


== License
include::license-software.adoc[]

include::license-hardware.adoc[]

Author: {author} - generated on {revdate}

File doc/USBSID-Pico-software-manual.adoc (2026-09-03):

= *USBSID-Pico software manual*
:author: LouD
:description: This document contains consice information for some of the software supporting USBSID-Pico
:url-repo: https://www.github.com/LouDnl/USBSID-Pico
:revdate: {localdate}
:hide-uri-scheme:
:toc:
:toclevels: 4
:toc-placement!:

Author: {author} - generated on {revdate}

toc::[]
[%always]
<<<

== Disclaimer
include::disclaimer.adoc[]

== Supported platforms
For configuring your board itself (not the software listed below), see the `USBSID-Configtool-manual` file for the GUI tool, or the `USBSID-Pico-firmware-manual` file for the command line `cfg_usbsid` tool. +
_In active development_ +
*Linux:* Vice, JSidplay2, Denise, SidplayFp, RetroDebugger, SidBerry, USB Midi, WebUSB & ASID (in webbrowser) SID Play +
*Windows:* Vice, JSidplay2, Denise, SidBerry, USB Midi, WebUSB & ASID (in webbrowser) SID Play +
*Android:* USB Midi, WebUSB & ASID (in webbrowser) SID Play +
*Amiga:* PlaySID library

== Drivers

=== Linux Udev rules
In the https://github.com/LouDnl/USBSID-Pico/blob/master/examples/udev-rules/[examples/udev] directory you can find the https://github.com/LouDnl/USBSID-Pico/blob/master/examples/udev-rules/69-usbsid-permissions.rules[udev rules] that I use on Linux. +
This purely an example file that you can use and change to your own needs.
Steps required for this to work
[source,bash]
----
# Check if you are in the plugdev group with the groups command
groups
# If not, add yourself to the plugdev group, then log out and in
sudo usermod -aG plugdev $USER
# Copy the udev ules file to the correct directory
sudo cp 69-usbsid-permissions.rules /etc/udev/rules.d
# Now reload the udev rules
udevadm control --reload-rules && udevadm trigger
# Not working? Try reloading the service
sudo systemctl restart udev
----

=== Windows driver
Use https://zadig.akeo.ie/[Zadig] to install the correct driver. Replace the driver for `USBSID-Pico Data` with WinUSB. +
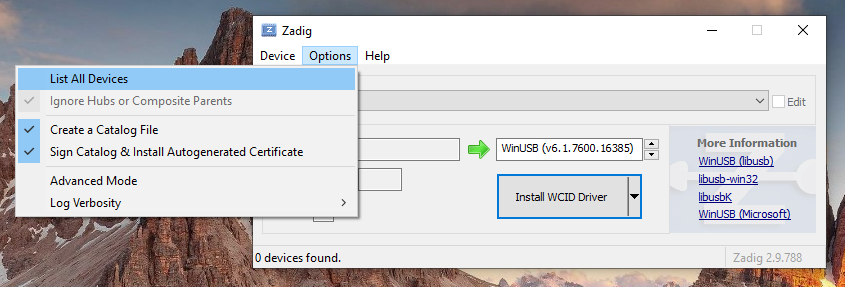
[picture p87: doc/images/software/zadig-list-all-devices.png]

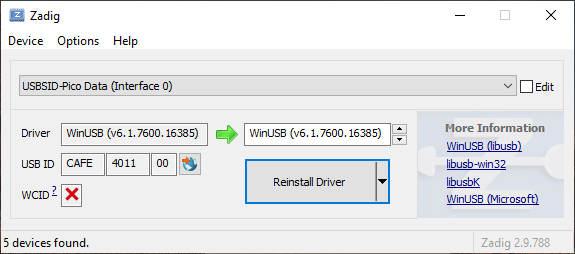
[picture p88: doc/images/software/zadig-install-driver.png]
 +

=== Test and configure
After setting up your linux udev rules or Windows driver check, configure and test your board on the https://usbsid.loudai.nl/?player=webusb[USBSID] config tool website +
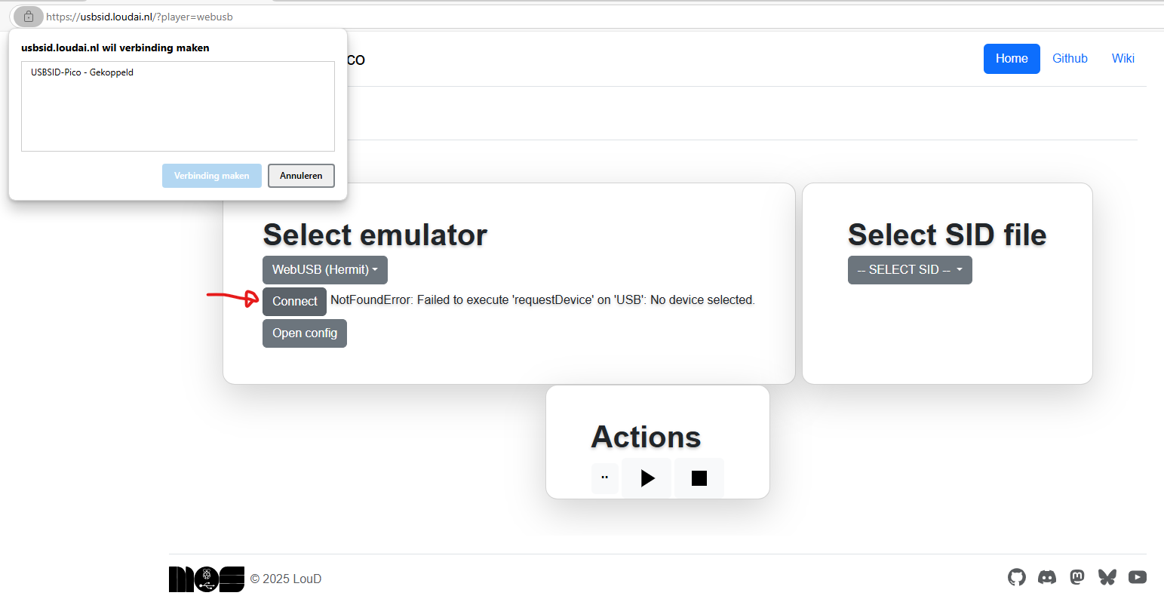
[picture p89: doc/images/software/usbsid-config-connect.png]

 +
_For more information on how to configure your board, please refer to the https://github.com/LouDnl/USBSID-Pico/blob/master/doc/USBSID-Pico-firmware-manual.adoc[Firmware manual]_

[%always]
<<<

== Supported software
Each section covers the basic use of USBSID-Pico with the software under that section. For more in depth information please refer to the repective website and or github repo of the software.

=== Deepsid
On the https://deepsid.chordian.net/[deepsid] website you can select `WebUSB (Hermit)` or `ASID (MIDI)` for playing PSID files using a supported browser. +

*WebUSB*: After selecting `WebUSB (Hermit)` you need to click the `CONNECT` button and select USBSID-Pico in the pop-up window. Due to the autoplay feature of Deepsid, you might have to press `STOP` a couple of times before the `CONNECT` button will work.

*ASID*: After selecting `ASID (MIDI)` you need to select USBSID-Pico in the dropdown box next to the line that says `MIDI port for ASID`. It might require refreshing the page a couple of times for the box to be filled with midi devices. +
Supported browsers: +

- *Firefox* supports ASID.
- *Chrome* supports both WebUSB and ASID.
- *Edge* supports both WebUSB and ASID.

[%always]
<<<

=== SidBerry
https://github.com/LouDnl/SidBerry[SidBerry] supports PSID files only and can play SID files on USBSID-Pico via CDC (default) or on ASID supporting players via command line arguments. +
General Linux usage:
[source,bash]
----
# to play sidfile.sid on USBSID-Pico
usbsidberry path/to/sidfile.sid
# to detect and print available midi devices
usbsidberry -midi
# to play sidfile.sid via ASID on USBSID-Pico where `1` is the respective port of the ASID device
usbsidberry -asid 1 path/to/sidfile.sid
----
Basic Windows usage:
[source,powershell]
----
# to play sidfile.sid on USBSID-Pico
usbsidberry.exe path/to/sidfile.sid
# to detect and print available midi devices
usbsidberry.exe -midi
# to play sidfile.sid via ASID on USBSID-Pico where `1` is the respective port of the ASID device
usbsidberry.exe -asid 1 path/to/sidfile.sid
----

[%always]
<<<

=== Vice
This section covers the use of USBSID-Pico with Vice under Linux, Windows and MacOS for the GTK and SDL2 versions of `vsid` and `x64sc`

WARNING: Switching on readmode and then switching it off again without restarting the PCB and Vice _will_ result in distorted audio

==== Command-line arguments
Command-line arguments override any previously configured items in your `vicerc` config file. +
All three OS support the same command-line arguments for both `vsid` and `x64sc`. +
However, the sound device argument is OS specific and `vsid` supports a maximum of 3 SID chips +
*Note* that if you define extra SID's and their addresses, these addresses need to point to the required address for the SID tune or Software you want to use. The Vice USBSID-Pico driver will automatically convert each write to the in firmware configured SID chip. +
Below is an excerpt from the Vice manual with information about each command-line option
[source,shell]
----
-usreadmode <0 or 1>
    Enable USBSID-Pico read mode. When enabled, this mode allows for reading from SID registers that provides a means to configure an FPGASID that is seated on USBSID-Pico. This mode is not suited for regular audio use as it disables cycle exact writing & digiplay. Default is (SidUSBSIDReadMode=0) for off, (SidUSBSIDReadMode=1) for on. 

-usaudiomode <0 or 1>
    Set USBSID-Pico PCB (v1.3) audio mode to Stereo or Mono. When enabled the audio of SID socket 1 will be output over the left audio channel and the audio of SID socket 2 over the right channel of USBSID-Pico's audio out. Default is (SidUSBSIDAudioMode=0) for Mono, (SidUSBSIDAudioMode=1) for Stereo. 

-usdiffsize <number divisable by 8>
    Specifies the minimal difference in bytes to use between the head and tail of the drivers ringbuffer, this allows for some audio quality tuning on slower systems. In most cases the default value of 64 bytes (also the size of a USB packet) is the right setting for best audio quality. (SidUSBSIDDiffSize=32-256). 

-usbuffsize <number divisable by 8>
    Specifies the size in bytes to use as ringbuffer to store temporary data when sending SID writes to USBSID-Pico, this allows for some audio quality tuning on slower systems. In most cases the default value of 8192 bytes is the right setting for best audio quality. (SidUSBSIDBufferSize=512-16384). 
----

[%always]
<<<

==== x64sc GTK
ALT+O or click Preferences/Settings to open the settings menu. +
*Sound configuration* +
The sound configuration will require tuning for the computer you use it on. +
In the screenshot below you can see that for this system I use the `pulse` audio driver and have the `Buffer size` set to 1 millisecond and `Fragment size` set to very small. +
These 3 settings can make or break the audio quality. +
 +
*SID configuration* +
For any audio to come out of the board you _need_ to select USBSID-Pico as SID engine. +
If you want to use more the one SID then you need to select the amount of `Extra SIDs` and set their I/O addresses. +


[%always]
<<<

==== x64sc SDL2
Press F12 (Linux/Windows) / F10 (MacOs) to open the settings menu. +
*Sound configuration* +
The sound configuration will require tuning for the computer you use it on. +
In the screenshot below you can see that for this system I use the `pulse` audio driver and have the `Buffer size` set to 25 milliseconds and `Fragment size` set to very small. +
These 3 settings can make or break the audio quality. +
 +
To get to these settings follow the following settings path: +
`Sound settings` => `Output driver` => Select the driver you want to use +
`Sound settings` => `Buffer size` => Select the milliseconds you want to use +
`Sound settings` => `Fragment size` => Select the size you want to use +
*SID configuration* +
For any audio to come out of the board you _need_ to select USBSID-Pico as SID engine. +
If you want to use more the one SID then you need to select the amount of `Extra SIDs` and set their I/O addresses. +
 +
To get to these settings follow the following settings path: +
`Machine settings` => `Model settings` => `SID settings` => `SID model` => `USBSID-Pico` +
`Machine settings` => `Model settings` => `SID settings` => `Extra SIDs` => select the amount of extra SID's and set their addresses 

[%always]
<<<

==== vsid GTK
ALT+O or click Preferences/Settings to open the settings menu. +
*Sound configuration* +
The sound configuration will require tuning for the computer you use it on. +
In the screenshot below you can see that for this system I use the `pulse` audio driver and have the `Buffer size` set to 1 millisecond and `Fragment size` set to very small. +
These 3 settings can make or break the audio quality. +
 +
*SID configuration* +
For any audio to come out of the board you _need_ to select USBSID-Pico as SID engine. +
If you want to use more the one SID then you need to select the amount of `Extra SIDs` and set their I/O addresses. +


[%always]
<<<

==== vsid SDL2
Press F12 (Linux/Windows) / F10 (MacOs) to open the settings menu. +
*Sound configuration* +
The sound configuration will require tuning for the computer you use it on. +
In the screenshot below you can see that for this system I use the `pulse` audio driver and have the `Buffer size` set to 10 milliseconds and `Fragment size` set to very small. +
These 3 settings can make or break the audio quality. +
 +
To get to these settings follow the following settings path: +
`Sound settings` => `Output driver` => Select the driver you want to use +
`Sound settings` => `Buffer size` => Select the milliseconds you want to use +
`Sound settings` => `Fragment size` => Select the size you want to use +
*SID configuration* +
For any audio to come out of the board you _need_ to select USBSID-Pico as SID engine. +
If you want to use more the one SID then you need to select the amount of `Extra SIDs` and set their I/O addresses. +

To get to these settings follow the following settings path: +
`SID settings` => `SID model` => `USBSID-Pico` +
`SID settings` => `Extra SIDs` => select the amount of extra SID's and set their addresses +

[%always]
<<<

=== jsidplay2
This section covers the use of USBSID-Pico with `jsidplay2`

==== Settings
After starting JSidplay2 you can choose USBSID-Pico from the dropdown menu that says emulation and set the board to mono or stereo using the settings dropdown




==== c64jukebox
`c64jukebox` website that runs on `jsidplay2` available at https://haendel.ddns.net:8443/static/c64jukebox.vue

To enable USBSID-Pico in a WebUSB supporting browser (like Chrome) click on the `Hardware` tab and then click `Connect` in the USBSID-Pico box. After connecting search for any SID file in the search tab and click the play button.

WARNING: Because this play method is not perfected yet there will be delays when selecting a follow up tune and pressing stop or pause. This can be circumvented enabling `use await for USBSID write` on the Hardware tab, but this will severely impact playing tunes that rely on timing



[%always]
<<<

=== Denise
This section covers the use of USBSID-Pico with the C64 emulator of `Denise`

==== USBSID settings
Open the C64 settings menu and go to the audio tab. Under this tab on the left side you will see an `USBSID-Pico` option +
Here you can enable or disable the use of USBSID-Pico. If you have any audio issue you can try to increase the buffer and diff sizes.


==== SID settings
Open the C64 settings menu and go to the audio tab. Under this tab on the left side you will see a `Chip` option +
Here you can configure the amount of SID's you have on the board. Be sure to try the different settings for better output.


[%always]
<<<

=== Retrodebugger
t.b.d.

=== sidplayfp
t.b.d.

== License
include::license-software.adoc[]

include::license-hardware.adoc[]

Author: {author} - generated on {revdate}

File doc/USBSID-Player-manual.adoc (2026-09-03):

= *USBSID-Player manual*
:author: LouD
:description: This document contains information about the embedded USBSID-Player and how to use it
:url-repo: https://www.github.com/LouDnl/USBSID-Pico
:revdate: {localdate}
:hide-uri-scheme:
:toc:
:toclevels: 4
:toc-placement!:

Author: {author} - generated on {revdate}

toc::[]
[%always]
<<<

== Disclaimer
include::disclaimer.adoc[]

== What!?
Yes you read that right, USBSID-Player is embedded on USBSID-Pico and allows you to play PSID, RSID, PRG or P00 chiptunes without the need of an emulator on your computer!

== Firmwares with embedded USBSID-Player
Starting with firmware version v0.6.0-BETA firmwares ending with `_sp` have an embedded emulator that can play PSID and RSID tunes and PSID64 PRG/P00 files. +
For example `usbsidpico2-v1.0_sp.uf2`, `usbsidpico2-v1.3-rgb_sp.uf2` or `usbsidpico2-v1.5_sp.uf2` +
This USBSID-Player is still in active development and some tunes might not work or play at all. +
The embedded USBSID-Player requires more then 256KB RAM, which is why it is primarily built and tested for rp2350 Pico2 boards, but `_sp` firmwares are also built for rp2040 Pico1 boards. +
**NOTE!** Due to the hardware limitations of the RP2040, highly demanding, cycle-exact SID tunes (dense per-cycle register writes, e.g. some digi/sample tunes) may not play at full speed on Pico1 or Pico1_w boards. Use a Pico2 or Pico2_w (rp2350) board for these tunes. +
**WARNING!** Whenever the USBSID-Player is used the Pico MCU is overclocked to 250MHz, regardless of Pico type. Passive cooling _might/could_ be needed. +
Cynthcart runs through the embedded USBSID-Player - see the `USBSID-Pico-Cynthcart-manual` file for more information. +

== Usage
To play SID tunes and run PRG/P00 PSID64 files _on_ USBSID-Pico you will need the `send_sid` tool that is available in the `tools.zip` starting with firmware release v0.6.0-BETA and up. +
The help menu is self explanatory. +
Multi-subtune PSID/RSID files are supported - you can switch to the next or previous subtune while a tune is playing.

== Future plans
When all bugs are squashed and more tunes are supported a website will be made available where you can 'send' files from to the onboard SID player

== Development
More information about USBSID-Player is available on the https://github.com/LouDnl/USBSID-Player[github repo]

== License
include::license-software.adoc[]

include::license-hardware.adoc[]

Author: {author} - generated on {revdate}

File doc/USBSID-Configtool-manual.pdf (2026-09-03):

# USBSID-Configtool manual

### Author: LouD - generated on 2026-09-03

# Table of Contents

# Disclaimer

I do this stuff in my free time for my enjoyment. Since I like to share my joy in creating this with everyone I try my best to provide a working PCB and Firmware. I am in no way an electronics engineer and can give no guarantees that this stuff does not break or damage your hardware, computer, phone, or whatever you try to hook it up to. Be sure to take great care when inserting any real MOS SID chips into the board. While everything has been tested with real chips, this is in no way a guarantee that nothing could go wrong. Use of this board and firmware at your own risk! I am in no way responsible for your damaged hardware. That being said, have fun!

# About

What is there to say, you can configure your board with this tool and it is self explanatory.
Prefer the command line? A CLI config tool (cfg_usbsid) is also available - see the USBSID-Picofirmware-manual file for its usage.

# Screens

# Welcome screen



# v1.5 Sockets confirmation message

# Sockets screen


# Clock screen


# LEDS screen


# Features screen


# SID tests screen

# Debug screen


# Development

More information about USBSID-Configtool is available on the github repo (https://github.com/LouDnl/USBSID-Configtool)

# License

# Software License ~ GNUv2

All code written by me in this repository is licensed under the terms of the GNU General Public License as published by the Free Software Foundation, version 2. Any code in this repository that is not written by me automatically falls under the licensing conditions by the authors of said code as mentioned in the source code header. For for more information about this license please read the LICENSE document in the root of the USBSID-Pico repository.

# Configtool Software License ~ EPLv2

This program and the accompanying materials are made available under the terms of the Eclipse Public License 2.0 which is available at eclipse.org.
SPDX-License-Identifier: EPL-2.0

# USBSID-Pico v1.5 PCB Hardware License ~ CC BY-NC-

ND 4.0

USBSID-Pico v1.5 PCB © 2026 by LouD (https://github.com/LouDnl) is licensed under
Creative Commons Attribution-NonCommercial-NoDerivatives 4.0 International (https://creativecommons.org/licenses/by-nc-nd/4.0/)

# USBSID-Pico v1.3 PCB Hardware License ~ CC BY-SA 4.0

USBSID-Pico v1.3 PCB (https://github.com/LouDnl/USBSID-Pico/tree/master/hardware/USBSID-Pico-v1.3) © 2025-2026 by LouD (https://github.com/LouDnl) is licensed under
Creative Commons Attribution-ShareAlike 4.0 International (https://creativecommons.org/licenses/by-sa/4.0/)

# USBSID-Pico v1.0 PCB Hardware License ~ CC BY-SA 4.0

USBSID-Pico v1.0 PCB (https://github.com/LouDnl/USBSID-Pico/tree/master/hardware/USBSID-Pico-v1.0) © 2024-2026 by LouD (https://github.com/LouDnl) is licensed under
Creative Commons Attribution-ShareAlike 4.0 International (https://creativecommons.org/licenses/by-sa/4.0/)

# USBSID-Volume-daughterboard v1.0 PCB Hardware License ~ CC BY-SA 4.0

Volume-daughterboard v1.0 PCB © 2026 by LouD (https://github.com/LouDnl) is licensed under
Creative Commons Attribution-ShareAlike 4.0 International (https://creativecommons.org/licenses/by-sa/4.0/)

Author: LouD - generated on 2026-09-03

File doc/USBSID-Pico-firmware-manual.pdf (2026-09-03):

# USBSID-Pico PCB firmware manual

### Author: LouD - generated on 2026-09-03

# Table of Contents

# Disclaimer

I do this stuff in my free time for my enjoyment. Since I like to share my joy in creating this with everyone I try my best to provide a working PCB and Firmware. I am in no way an electronics engineer and can give no guarantees that this stuff does not break or damage your hardware, computer, phone, or whatever you try to hook it up to. Be sure to take great care when inserting any real MOS SID chips into the board. While everything has been tested with real chips, this is in no way a guarantee that nothing could go wrong. Use of this board and firmware at your own risk! I am in no way responsible for your damaged hardware. That being said, have fun!

# Firmware types


Each PCB revision is the firmware designator, please check your PCB revision, this is under the MOS logo and next to USBSID-Pico on your PCB.
Firmware filenames contain the PCB revision number e.g. usbsidpico-rgb-v1.X.uf2 is for PCB revision v1.0 and for use with a black clone Pico containing an RGB LED.

# Firmware naming

Below are the filenames used for each Pico and board type, take great care in selecting the correct file for you Pico!
WARNING! Do NOT use the RGB firmware for any of the (non black) rp2040 or (non black) rp2350 Pico boards that do not contain an RGB LED, this can break your Pico!

# Board revision

The 1.X in each filename equals for the PCB revision as mentioned under firmware types. Don’t worry if you flash a firmware for the incorrect PCB revision, this causes no harm.

# Firmware naming

usbsidA-BC.uf2 examples: usbsidpico-v1.0-rgb.uf2, usbsidpico2_w-v1.3.uf2 or usbsidpico2-v1.5-rgb_sp.
A: The pico board type e.g. pico, pico2, pico_2 or pico2_w

B: The PCB version e.g. v1.0, v1.3 or v1.5
C: A combination of optional features e.g. -rgb, _sp or _sp_cc

# Firmware naming per Pico type

Firmwares suitable for rp2040 Pico1 boards start with usbsidpico- Firmwares suitable for rp2040 Pico1_w boards start with usbsidpico_w-Firmwares suitable for rp2350 Pico2 boards start with usbsidpico2-
Firmwares suitable for rp2350 Pico2_w boards start with usbsidpico2_w-

# Naming examples for the rp2040 Pico1

Firmware naming suited for the pico 1 always start with usbsidpico-usbsidpico-v1.X.uf2 for regular green rp2040 Pico boards.
usbsidpico-rgb-v1.X.uf2 for black clone rp2040 Pico boards with RGB LED onboard. usbsidpico_w-v1.X.uf2 for regular green rp2040 PicoW boards.

NOTE! Due to the hardware limitations of the RP2040, highly demanding, cycle-exact SID tunes (dense per-cycle register writes, e.g. some digi/sample tunes) may not play at full speed on Pico1 or Pico1_w boards. Use a Pico2 or Pico2_w (rp2350) board for these tunes.

# Naming examples for the rp2350 Pico2

Firmware naming suited for the pico 2 always start with usbsidpico2-usbsidpico2-v1.X.uf2 for regular green rp2350 Pico2 boards. usbsidpico2-rgb-v1.X.uf2 for black clone rp2350 Pico2 boards with RGB LED onboard. usbsidpico2_w-v1.X.uf2 for regular green rp2350 Pico2W boards.

# Firmwares with embedded USBSID-Player

Starting with firmware version v0.6.0-BETA firmwares ending with sp have an embedded emulator
that can play PSID and RSID tunes and PSID64 PRG/P00 files.
For example usbsidpico2-v1.0_sp.uf2, usbsidpico2-v1.3-rgb_sp.uf2 or usbsidpico2-v1.5_sp.uf2 This USBSID-Player is still in active development and some tunes might not work or play at all. The embedded USBSID-Player requires more then 256KB RAM and an overclocked CPU which makes this firmware only available for rp2350 Pico2 boards.
WARNING! Whenever the USBSID-Player is used the Pico MCU is overclocked to 250MHz, regardless of Pico type. Passive cooling _might/could be needed.
See the USBSID-Player-manual file for more information.

# Firmwares with Cynthcart embedded

Starting with firmware version v0.8.0 firmwares ending with _cc can start Cynthcart with CC commands.
For example usbsidpico-v1.0_sp_cc.uf2, usbsidpico2-rgb-v1.3_sp_cc.uf2 or usbsidpico2-v1.5_sp_cc.uf2
WARNING! Cynthcart runs through the embedded USBSID-Player, so the same 250MHz overclock

(regardless of Pico type) and possible need for passive cooling applies here too. See the USBSID-Pico-Cynthcart-manual file for more information.

# How to flash your Pico

NOTE:
When flashing a new firmware version, all previously configured settings will be reset to default. Use the commandline configtool to save your current settings to a ini file if you want to save them! A Raspberry Pi Pico board is incredibly easy to flash, as it comes with a built in bootloader for flashing new firmwares in the uf2 format.
In order to flash a new firmware to your USBSID-Pico you will need to put the Pico into bootloader mode.
This can be done in multiple ways:

With the cable already plugged into your computer and Pico and seated on the board (using buttons):

- Press and hold the BOOTSEL button on the Pico.
- Press and release the RST button on the USBSID-Pico board.
- Now release the BOOTSEL button.
- A new drive should appear on your computer called RPI-RP2 or RP2350 depending on your Pico type.
- Copy the correct uf2 firmware file to this directory.
- After copying the Pico will reboot and your Pico is flashed.

With the cable not plugged in to your computer and Pico and also not seated on the board (using buttons):

- Plug in the USB cable to your Pico and not into your computer.
- While holding the BOOTSEL button on the Pico plugin the other end of the USB cable into your computer.
- Now release the BOOTSEL button.
- A new drive should appear on your computer called RPI-RP2 or RP2350 depending on your Pico type.
- Copy the correct uf2 firmware file to this directory.
- After copying the Pico will reboot and your Pico is flashed.

With the cable already plugged into your computer and Pico and seated on the board (using software):

- With the GUI config tool
- Go to the DEBUG tab and click on BOOTLOADER
- A new drive should appear on your computer called RPI-RP2 or RP2350 depending on your Pico type.

- Copy the correct uf2 firmware file to this directory.
- After copying the Pico will reboot and your Pico is flashed.

or

- Go to the config webpage (usbsid.loudai.nl/index.html?player=webusb&debug=usbsidpico):
- Connect to the board using WebUSB (Hermit) as emulator
- Click on CONFIG to open the configuration tab
- Scroll to the bottom of the page and click on BOOTLOADER in the box named DEBUG
- A new drive should appear on your computer called RPI-RP2 or RP2350 depending on your Pico type.
- Copy the correct uf2 firmware file to this directory.
- After copying the Pico will reboot and your Pico is flashed.

or

- With the CLI config tool command in your PATH variable
- Type cfg_usbsid -boot to send the reboot to bootloader command
- A new drive should appear on your computer called RPI-RP2 or RP2350 depending on your Pico type.
- Copy the correct uf2 firmware file to this directory.
- After copying the Pico will reboot and your Pico is flashed.

# Firmware configuration

USBSID-Pico has an extensive set of configuration options that expands with each firmware release.

# USBSID-Configtool

You can configurate your board by using the official USBSID-Configtool The tool is available here USBSID-Configtool (https://github.com/LouDnl/USBSID-Configtool) in the releases section

# Commandline configuration tool

You can configurate your board with: - the commandline config-tool - the commandline config-tool with the Python Configuration GUI by ISL/Samar if you prefer a GUI.

### Python Configuration GUI downloads

Download script (https://github.com/LouDnl/USBSID-Pico/blob/master/examples/config-tool/cfg_usbsid_GUI.py)
Python3 → Download (https://www.python.org/downloads/)
TkInter → Installation guide (https://tkdocs.com/tutorial/install.html)
And either one of the Linux or Windows CLI downloads below

### Linux / Windows downloads

The latest version of the CLI config tool is available in a zip file called tools.zip from release v0.6.0-BETA and up

### Windows downloads

If the DLL’s are missing from the zip file you can always download them from here: Download DLL 1 (https://github.com/LouDnl/USBSID-Pico/blob/master/examples/config-tool/libusb-1.0.dll)
Download DLL 2 (https://github.com/LouDnl/USBSID-Pico/blob/master/examples/config-tool/libwinpthread-1.dll)

# Configuration web page (for Chrome/Edge based browsers using webusb)

USBSID web configuration tool (https://usbsid.loudai.nl/?player=webusb) (requires a Chrome based browser).
If needed you can change your USBSID configuration after selecting WebUSB and clicking on Open
config.


The player is set up with borrowed code from Deepsid using Hermit’s JsSID implementation.

# Default configuration (depends on the board version)

The default configuration differs slightly between Pico1 (rp2040) and Pico2 (rp2350) boards.
An explanation for these settings can be found further on in this document.
Board clock rate: 1000000Hz (DEFAULT) for rp2040, 985248Hz (PAL) for rp2350
Clock rate locked: False
Audio mode: Mono
Preset silent auto detection: False (True for PCB revision v1.5+)
Socket One Enabled: True
Socket One Dualsid enabled: False
Socket One Chiptype: Unknown
Socket One SID 1 type: Unknown Socket One SID 2 type: N/A
Socket Two Enabled: True
Socket Two Dualsid enabled: False Socket Two Chiptype: Unknown Socket Two SID 1 type: Unknown Socket Two SID 2 type: N/A
Socket Two Act as One: False
Flip Socket One and Socket Two: False Mix socket addresses (Quad SID): False
LED Enabled: True
LED Idle breathe enabled: True
RGBLED Enabled: False (True for RGB Pico’s)
RGBLED Idle breathe enabled: False (True for RGB Pico’s) RGBLED Brightness: 0 (127 for RGB Pico’s)
RGBLED SID to use: -1 (1 for RGB Pico’s)
CDC Enabled: True
WebUSB Enabled: True
Asid Enabled: True
Midi Enabled: True
FMOpl Enabled: False
FMOpl SID no: 0

# Board clock rate

The Commodore64 has different clockrates depending on where you live, USBSID-Pico supports these different clock rates as configuration setting.
Supported SID players will automatically send a new clock rate request to the board to switch to. Available options are:
DEFAULT 1000000Hz, PAL 985248Hz, NTSC 1022727, DREAN 1023440, NTSC2 1022730

# Clock rate locked

Some players start sending data directly after the clockrate is changed. While in most cases this is no issue, some SID clones need some time to start up. This causes issues when the clock rate is changed on the fly.

Also changing the clock rate multiple times after another can cause data corruption to the SID which causes garbled sound.
To overcome this it is possible to lock the clockrate to the current setting it is set to. This blocks the ability for on the fly change requests.
Available options are:
False, True

# Audio mode

PCB revision v1.3 only
Sets the audio mode for the headphone jack and audio out pins.
When set to Mono the audio of both SID sockets will be combined to mono.
When set to Stereo the audio of both SID sockets will be separated into left for SID1 and right for
SID2
Available options are:
Mono, Stereo

# Lock audio switch

PCB revision v1.3 only
Locks the audio switch into its current state (Mono or Stereo) and prevents it from being changed. Available options are:
False, True

# SID Voltage & Configuration confirmation

PCB revision v1.5 only
The board boots with 5v and 9v enabled to automatically detect any changes in the socket / chip configuration, it does this by running a chip and SID detection.
When a change is detected the boards turns off the 9v and 5v and the onboard (RGB)LED starts flashing, making the board unusable until the configuration is validated and confirmed.
Please verify the configuration with care before confirming, failure to do so might damage/kill your SID chips, and we don’t want that!
There are multiple ways to validate and confirm the configuration:
GUI Configtool
On opening the configtool and connecting to the board there will be a text stating the configuration needs to be confirmed. Verify the config on the SOCKETS tab and when done click CONFIRM

Web Configtool
On opening the config website and connecting to the board there will be a text stating the configuration needs to be confirmed. Verify the config on the CONFIG tab by clicking RETRIEVE CONFIG first and when done validating click CONFIRM CONFIG. Both buttons will glow when a click is needed


CLI Configtool
First read the configuration with cfg_usbsid -r, the printed configuration will have a line that states the config needs confirmation. You can do this with cfg_usbsid -ack.

# Disable socket change detection

PCB revision v1.5 only
When you have a fixed socket setup, e.g. you do not plan on changing the chips anytime soon, it is possible to disable the change detection on boot. This will make the board start up with 5v and 9v and then - if 12v is required - switch to the required voltage setting during the boot process by switching the voltage back off, setting the correct hv voltage and then switching it back on.
When the socket detection is on, the board will always try to detect any changes in the configuration before the required voltage is applied.
By setting the Disable socket detection on boot option you can control the above behaviour:
GUI Configtool

Web Configtool

CLI Configtool
Change the behaviour with cfg_usbsid -sad N where N can be 0 (disabled) or 1 (enabled)

# Socket settings

Each socket comes with its own set of configurable options.

### Socket One/Two Enabled

Enable or disable the use of this socket.
Available options are:
False, True

### Socket One/Two Dualsid enabled

Enable or disable dualsid for this socket.
This requires the Chiptype for this socket to be set to any clone chip (not MOS) and ofcourse a dual

SID supporting SID clone with support of connecting the A5 address line. Available options are:
False, True

### Socket One/Two Chiptype

Set the type of SID chip for this socket.
Available options are:
MOS (real SID), Unknown, SKPico, ARMSID, ARM2SID, FPGASID, RedipSID, PDSID, BackSID, SIDEmu

### Socket One/Two SID 1 type

Available options are:
Unknown, N/A, 8580, 6581, FMOpl

### Socket One/Two SID 2 type

Available options are:
Unknown, N/A, 8580, 6581, FMOpl

### Socket Two Act as One

When enabled, this will disable other Socket Two settings and this socket will receive all writes from Socket One as it were mirrored.
Available options are:
False, True

### Flip Socket One and Socket Two

When enabled, Socket One and Socket Two are swapped so Socket One’s physical position responds as Socket Two and vice versa.
Available options are:
False, True

### Mix socket addresses (Quad SID only)

When enabled, addresses for a 4-SID setup are mixed between sockets instead of being assigned sequentially per socket. Combine with Flip for the remaining address orderings.
Available options are:
False, True

### Preset silent auto detection

When enabled, the board silently re-runs chip/SID auto detection before applying a preset. Default is False on PCB revision v1.0~v1.3 and True on PCB revision v1.5+.
Available options are:
False, True

# LED Enabled

Disable or enable the use of the onboard LED.
When enabled this automatically enables the LED as Vu meter for the voices of SID1. Available options are:
False, True

# LED Idle breathe enabled

Disable or enable the idle breathing effect for the onboard LED. Available options are:
False, True

# RGBLED Enabled

Only for black Pico clones with onboard RGB LED
Disable or enable the use of the onboard RGBLED.
When enabled this automatically enables the RGBLED as Vu meter. Available options are:
False, True

# RGBLED Idle breathe enabled

Only for black Pico clones with onboard RGB LED
Disable or enable the idle breathing effect for the onboard RGBLED. Available options are:
False, True

# RGBLED Brightness

Only for black Pico clones with onboard RGB LED Set the maximum brightness of the onboard RGBLED. Available range is:
0 to 255

# RGBLED SID to use

Only for black Pico clones with onboard RGB LED
Set the SID of which to use the voices for the Vu meter. Available options are (depending on your SID configuration): -1 off, 0 off, 1 SID1, 2 SID2, 3 SID3, 4 SID4

# FMOpl Enabled

Requires a SID clone with FMOpl capabilities, the socket Chip type set to Clone and SID type set to FMOpl before activation!

Available options are:
False, True

# FMOpl SID number

This setting cannot be changed manually This setting will automatically be set to the correct SID number when all requirements are met as described under FMOpl Enabled

# CDC Enabled

This config setting is intended for future use Available options are:
False, True

# WebUSB Enabled

This config setting is intended for future use Available options are:
False, True

# Asid Enabled

Disable or enable ASID protocol handling (SysEx-based SID playback over MIDI). Available options are:
False, True

# Midi Enabled

Disable or enable MIDI input handling (note/CC/voice control of the SID(s)). Available options are:
False, True

# License

# Software License ~ GNUv2

All code written by me in this repository is licensed under the terms of the GNU General Public License as published by the Free Software Foundation, version 2. Any code in this repository that is not written by me automatically falls under the licensing conditions by the authors of said code as mentioned in the source code header. For for more information about this license please read the LICENSE document in the root of the USBSID-Pico repository.

# Configtool Software License ~ EPLv2

This program and the accompanying materials are made available under the terms of the Eclipse Public License 2.0 which is available at eclipse.org.
SPDX-License-Identifier: EPL-2.0

# USBSID-Pico v1.5 PCB Hardware License ~ CC BY-NC-

ND 4.0


USBSID-Pico v1.5 PCB © 2026 by LouD (https://github.com/LouDnl) is licensed under
Creative Commons Attribution-NonCommercial-NoDerivatives 4.0 International (https://creativecommons.org/licenses/by-nc-nd/4.0/)

USBSID-Pico v1.3 PCB Hardware License ~ CC BY-SA 4.0

USBSID-Pico v1.3 PCB (https://github.com/LouDnl/USBSID-Pico/tree/master/hardware/USBSID-Pico-v1.3) © 2025-2026 by LouD (https://github.com/LouDnl) is licensed under
Creative Commons Attribution-ShareAlike 4.0 International (https://creativecommons.org/licenses/by-sa/4.0/)

USBSID-Pico v1.0 PCB Hardware License ~ CC BY-SA 4.0

USBSID-Pico v1.0 PCB (https://github.com/LouDnl/USBSID-Pico/tree/master/hardware/USBSID-Pico-v1.0) © 2024-2026 by LouD (https://github.com/LouDnl) is licensed under

USBSID-Volume-daughterboard v1.0 PCB Hardware
License ~ CC BY-SA 4.0

Volume-daughterboard v1.0 PCB © 2026 by LouD (https://github.com/LouDnl) is licensed under

Author: LouD - generated on 2026-09-03

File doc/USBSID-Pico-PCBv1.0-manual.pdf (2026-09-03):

# USBSID-Pico PCB revision v1.0 manual

### Author: LouD - generated on 2026-09-03

# Table of Contents

# Disclaimer

I do this stuff in my free time for my enjoyment. Since I like to share my joy in creating this with everyone I try my best to provide a working PCB and Firmware. I am in no way an electronics engineer and can give no guarantees that this stuff does not break or damage your hardware, computer, phone, or whatever you try to hook it up to. Be sure to take great care when inserting any real MOS SID chips into the board. While everything has been tested with real chips, this is in no way a guarantee that nothing could go wrong. Use of this board and firmware at your own risk! I am in no way responsible for your damaged hardware. That being said, have fun!

# PCB top overview


Figure 1. PCB top overview

# RaspberryPi Pico placement orientation

In the placement overview image above there are 2 markings that designate toward what direction the Pico boards needs to be placed.
The USB marking and arrow point in the direction towards where the Pico USB port needs to be. The Pin 1 marking and arrow points towards where pin 1 of the Pico board needs to be.

# SID placement orientation

In the PCB overview image at the top of this document each SID socket has Pin 1 marked with text and an arrow.
Please use your full attention when placing your SID chips on the board so they in the correct orientation.
Incorrect placement orientation will result in frying your precious SID chip unicorn and creating a nice keychain! I am not responsible for your broken SID chips!

# 1. 12 volt or 9 volt selection jumper


- open = for 6581 SID only!! (12 volts)
- closed = for 8580 SID (9 volts)

# 2. Socket 2 6581 / 8580 SID type selection jumpers


- both closed left = 6581
- both closed right = 8580

# 3. Socket 1 6581 / 8580 SID type selection jumpers


- both closed left = 6581
- both closed right = 8580

# 4. Audio channel selection jumper


- closed on Socket 1 side = left & right channel for socket 1
- closed on Socket 2 side = left channel for socket 2 & right channel for socket 1

Optionally you could use a 3-way jumper cap for mono audio with both SID chips at the same time.

# 5. Address line A5

For adressess above $1F (SKPico 2nd SID for example)


Both pins are routed to the same GPIO for using adresses higher then $20

# 6. Uart debugging output port


- TX on the right
- RX on the left

# 7. Optional 330k pulldown resistor hooked up to EXT-IN for 8580 filter bypass in socket

2


Solder pad closed = enabled

# 8. Optional 330k pulldown resistor hooked up to EXT-IN for 8580 filter bypass in socket

1


Solder pad closed = enabled

# 9. Optional 1MHz crystal socket (not included in BOM)


Solder pad closed = enabled (when a crystal is socketed).
This disables the internal clock generation on the Pico

# 10. Optional 1k resistor for 6581 SID in socket 2


ATTENTION!: On older v1.0 PCB’s this solder pad is incorrectly labelled, it should read 6581! Solder pad closed = enabled

# 11. Optional 1k resistor for 6581 SID in socket 2


ATTENTION!: On older v1.0 PCB’s this solder pad is incorrectly labelled, it should read 6581! Solder pad closed = enabled

# 12. Socket 2 audio out via dupont connector


Socket 2 output to the right of the headphone jack
Ground and S2 as labeled

# 13. Socket 1 audio out via dupont connector

Socket 1 output to the left of the headphone jack Ground and S1 as labeled

# 14. Reset button


# Volume daughterboard

An optional Volume daughterboard is available for independent left/right channel volume control. It is not tested with v1.0 PCB’s and requires an extra ground mod - see the USBSID-Volume-daughterboard manual for details.

# License

# Software License ~ GNUv2

All code written by me in this repository is licensed under the terms of the GNU General Public License as published by the Free Software Foundation, version 2. Any code in this repository that is not written by me automatically falls under the licensing conditions by the authors of said code as mentioned in the source code header. For for more information about this license please read the LICENSE document in the root of the USBSID-Pico repository.

# Configtool Software License ~ EPLv2

# USBSID-Pico v1.5 PCB Hardware License ~ CC BY-NC-


This program and the accompanying materials are made available under the terms of the Eclipse
Public License 2.0 which is available at http://eclipse.org.
SPDX-License-Identifier: EPL-2.0

USBSID-Pico v1.5 PCB © 2026 by LouD (https://github.com/LouDnl) is licensed under
Creative Commons Attribution-NonCommercial-NoDerivatives 4.0 International (https://creativecommons.org/licenses/by-nc-nd/4.0/)

USBSID-Pico v1.3 PCB Hardware License ~ CC BY-SA 4.0

USBSID-Pico v1.3 PCB (https://github.com/LouDnl/USBSID-Pico/tree/master/hardware/USBSID-Pico-v1.3) © 2025-2026 by LouD (https://github.com/LouDnl) is licensed under
Creative Commons Attribution-ShareAlike 4.0 International (https://creativecommons.org/licenses/by-sa/4.0/)

USBSID-Pico v1.0 PCB Hardware License ~ CC BY-SA 4.0

USBSID-Pico v1.0 PCB (https://github.com/LouDnl/USBSID-Pico/tree/master/hardware/USBSID-Pico-v1.0) © 2024-2026 by LouD (https://github.com/LouDnl) is licensed under

USBSID-Volume-daughterboard v1.0 PCB Hardware
License ~ CC BY-SA 4.0

Volume-daughterboard v1.0 PCB © 2026 by LouD (https://github.com/LouDnl) is licensed under

Author: LouD - generated on 2026-09-03

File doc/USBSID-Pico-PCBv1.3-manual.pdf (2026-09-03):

# USBSID-Pico PCB revision v1.3 manual

### Author: LouD - generated on 2026-09-03

# Table of Contents

# Disclaimer

I do this stuff in my free time for my enjoyment. Since I like to share my joy in creating this with everyone I try my best to provide a working PCB and Firmware. I am in no way an electronics engineer and can give no guarantees that this stuff does not break or damage your hardware, computer, phone, or whatever you try to hook it up to. Be sure to take great care when inserting any real MOS SID chips into the board. While everything has been tested with real chips, this is in no way a guarantee that nothing could go wrong. Use of this board and firmware at your own risk! I am in no way responsible for your damaged hardware. That being said, have fun!

# PCB top overview


Figure 1. PCB top overview

# RaspberryPi Pico placement orientation

In the PCB overview image at the top of this document there are 2 markings that designate toward what direction the Pico boards needs to be placed.
The USB marking and arrow point in the direction towards where the Pico USB port needs to be. The Pin 1 marking and arrow points towards where pin 1 of the Pico board needs to be.

# Optional Pico placements

The USBSID-Pico v1.3 PCB has the option for you to solder your Pico directly to the PCB using the Pico’s castelated edges.
This creates more space and can be useful if you want to use a SID clone like FPGASID in socket 1.

The Pico debug pins are not connected and not used, you do not have to solder these pins.

# Optional header placement

If you would like to use a (semi)closed case like the spotUP case but want to keep access to the filter and power jumpers,
it’s possible to solder the jumper headers on the bottom side of the PCB for easy access.
There is a bottom case STL available that has special openings for this like in the photo below.


# SID placement orientation

In the PCB overview image at the top of this document each SID socket has Pin 1 marked with text and an arrow.
Please use your full attention when placing your SID chips on the board so they are in the correct orientation.
Incorrect placement orientation will result in frying your precious SID chip unicorn and creating a nice keychain! I am not responsible for your broken SID chips!

# 1. Socket SID type / voltage selection jumper


Voltage control per SID/socket.

SID1 is for socket 1 (left) and SID2 is for socket 2 (right)
- No jumper cap (open) = for 6581 SID only!! (12 volts)
- Jumper cap (closed) = for 8580 SID (9 volts)

Please be careful and choose the correct voltage setting!

Note:
Most clone SID chips do not use the higher voltage pin. Please check with the SID clone manufacturer (manual) if you are not sure!

# 2. SID filter selection jumpers


Each socket has 2 jumpers that need to be in the same position. These 2 jumpers control which filter capacitors are active for that socket.
The 2 left jumpers are for SID1/socket1 and the 2 right jumpers are for SID2/socket2
- 2 jumpers left (closed) = MOS6581 filters (470pF)
- 2 jumpers right (closed) = MOS8580 filters (22nF)

Accidentally mixing these jumpers should not do any harm but might make audio sound worse.
Note:

Most clone SID chips do not use the filter capacitors. Please check with the SID clone manufacturer (manual) if you are not sure!
Each set of jumpers respectively controls the capacitance for CAPA and CAPB for that SID.

# 3. Digiboost

Inside each SID socket there is a solderpad marked BP. This provides an optional bypass by directly pulling SID Pin 26 EXT IN to GND with a 330k resistor.

This bypass is also known as digi-boost for 8580 SID chips. Note:
The digiboost resistor value is fixed.

# 4. 6581 pulldown resistor

For each audio circuit there is a solder pad marked 6581.

This is an extra pull down resisitor required when using a MOS6581 SID as per Commodore64 schematic.
Note:
Your 6581 SID will work without this solderpad but audio quality may vary.

# 5. Audio pins

Each socket has an optional header with 3 pins. The pinout is from left to right GND,IN,OUT (markings are on the bottom of the PCB)

Each socket has a solder pad marked EXT IN on the bottom of the PCB. Close this to connect the IN pin of the audio header to the SID chip EXT IN pin.

IMPORTANT:
There is no audio filter circuit connected to the EXT IN pin, you have to provide the audio in filter yourself!
I take no responsibility if you break your SID chip by using this pin!

# 6. Address line & audio switch pins

Optional header for connecting the A5 address line to Clone SID chips.

There are 2 A5 pins, one for each socket that are both connected to the same GPIO pin.
The pinout is from left to right A5,SW,A5
(markings are on the bottom of the PCB)

The SW pin is an optional pin for adding a switch to control the mono / audio switch manually.

# 7. GPIO pins

Optional header for UART pins and unused GPIO for future use. (markings are on the bottom of the PCB)

# 8. Audio circuit

Each socket has it’s own audio circuit with a


voltage follower audio filter.
This is also used in the Commodore64 and on the SID Blaster.

# 9. Audio switch

Last but not least, the digital audio switch IC. Switching from mono (both SID chips play over left and right) to Stereo (SID1 over the left channel and SID2 over the right channel) and back is handled by the firmware through settings or automatically by supported players.

# Volume daughterboard

An optional Volume daughterboard is available for independent left/right channel volume control. It is compatible with v1.3 boards with a small modification to provide voltage - see the USBSID-
Volume-daughterboard manual for details.

# PCB bottom overview


Figure 2. PCB bottom overview

# License

# Software License ~ GNUv2

All code written by me in this repository is licensed under the terms of the GNU General Public License as published by the Free Software Foundation, version 2. Any code in this repository that is not written by me automatically falls under the licensing conditions by the authors of said code as mentioned in the source code header. For for more information about this license please read the LICENSE document in the root of the USBSID-Pico repository.

# Configtool Software License ~ EPLv2

# USBSID-Pico v1.5 PCB Hardware License ~ CC BY-NC-


This program and the accompanying materials are made available under the terms of the Eclipse
Public License 2.0 which is available at http://eclipse.org.
SPDX-License-Identifier: EPL-2.0

USBSID-Pico v1.5 PCB © 2026 by LouD (https://github.com/LouDnl) is licensed under
Creative Commons Attribution-NonCommercial-NoDerivatives 4.0 International (https://creativecommons.org/licenses/by-nc-nd/4.0/)

USBSID-Pico v1.3 PCB Hardware License ~ CC BY-SA 4.0

USBSID-Pico v1.3 PCB (https://github.com/LouDnl/USBSID-Pico/tree/master/hardware/USBSID-Pico-v1.3) © 2025-2026 by LouD (https://github.com/LouDnl) is licensed under
Creative Commons Attribution-ShareAlike 4.0 International (https://creativecommons.org/licenses/by-sa/4.0/)

USBSID-Pico v1.0 PCB Hardware License ~ CC BY-SA 4.0

USBSID-Pico v1.0 PCB (https://github.com/LouDnl/USBSID-Pico/tree/master/hardware/USBSID-Pico-v1.0) © 2024-2026 by LouD (https://github.com/LouDnl) is licensed under

USBSID-Volume-daughterboard v1.0 PCB Hardware
License ~ CC BY-SA 4.0

Volume-daughterboard v1.0 PCB © 2026 by LouD (https://github.com/LouDnl) is licensed under

Author: LouD - generated on 2026-09-03

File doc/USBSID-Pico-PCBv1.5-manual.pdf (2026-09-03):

# USBSID-Pico PCB revision v1.5 manual

### Author: LouD - generated on 2026-09-03

# Table of Contents

# Disclaimer

I do this stuff in my free time for my enjoyment. Since I like to share my joy in creating this with everyone I try my best to provide a working PCB and Firmware. I am in no way an electronics engineer and can give no guarantees that this stuff does not break or damage your hardware, computer, phone, or whatever you try to hook it up to. Be sure to take great care when inserting any real MOS SID chips into the board. While everything has been tested with real chips, this is in no way a guarantee that nothing could go wrong. Use of this board and firmware at your own risk! I am in no way responsible for your damaged hardware. That being said, have fun!

# PCB top overview


Figure 1. PCB top overview

# Extra protection

The audio out jack and pins are now protected with ESD protection diodes.
And the left and right channel in the audio jack will be pulled to ground with a 10k softpull resistor when no jack is inserted by using the jack switches.

# Jumperless design

The v1.5 board is a jumperless design. This means that settings that were previously controlled with jumpers are now configured with settings in the firmware. The settings can be configured with the USBSID-Configtool.

# Automatic settings

In line with the jumperless design some settings are set automatically.

SID type controls the voltage:
- The firmware will do a chip detect on startup to figure out if there is a clone chip or a real SID and what real SID is seated.
- This detection routine detects any change on startup and will lock the board with a blinking LED indicating you need to verify the socket configuration in the configtool.
- 8580 means 9 volts
- 6581 means 12 volts
- All clone SID chips will be automatically powered with 9 volts.
- It is possible to turn off this detection routine at startup and override the voltage setting.

SID type also controls the filter capacitor setting, the 8580 digiboost resistor and 6581 shunt resistor:
- 8580 means automatic digiboost and 22nF filter capacitors
- 6581 means no digiboost, shunt resistor enabled and 470pF filter capacitors

Socket voltage control on v1.5+ is more than just the automatic 9v/12v selection above - power to both SID sockets can also be fully switched off and back on again, independent of SID type, through the configtool or firmware settings.

# RaspberryPi Pico placement orientation

In the PCB overview image at the top of this document there are 2 ways from which you can get what direction the Pico boards needs to be placed.
The diskette marking is where the Pico USB port needs to be.
The Pin 1 marking, the little square around the solder pad at the outer edge of the board is where the Pico USB port needs to be.

# Optional Pico placements

The USBSID-Pico v1.5 PCB has the option for you to solder your Pico directly to the PCB using the Pico’s castelated edges.
This creates more space and can be useful if you want to use a SID clone like FPGASID in socket 1.

# SID placement orientation

In the PCB overview image at the top of this document each SID socket has a little cut out which indicates the SID placement orientation.
Please use your full attention when placing your SID chips on the board so they are in the correct orientation.
Incorrect placement orientation will result in frying your precious SID chip unicorn and creating a nice keychain! I am not responsible for your broken SID chips!

# Address line

The pins at the top of the board marked with A5 are for connecting an optional extra wire for some clone SID chips that support a second SID.

# Audio pins

Each SID socket has an optional header with 4 pins.
The pinout for SID1 is from left to right VDD,GND,IN,OUT
And the pinout for SID2 is from left to right OUT,IN,GND,VDD
(markings are on the bottom of the PCB) IMPORTANT:
There is no audio filter circuit connected to the EXT IN pin, you have to provide the audio in filter yourself!
I take no responsibility if you break your SID chip by using this pin!

# UART pins

Optional header for UART pins.
(markings are on the bottom of the PCB)
NOTE: The USE_PIO_UART firmware build option (PIO UART on GPIO 26/27) is not available on v1.5+ boards, those GPIO pins are used for socket voltage control instead.

# Audio switch

Same digital audio switch IC as on v1.3, carried forward unchanged. Switching from mono (both SID chips play over left and right) to Stereo (SID1 over the left channel and SID2 over the right channel) and back is handled by the firmware through settings or automatically by supported players.
The jumperless v1.5 design has no physical SW pin for manual switching - this is configured entirely through the firmware/configtool.

# Volume daughterboard

An optional Volume daughterboard is available for independent left/right channel volume control. It is plug and play compatible with v1.5+ boards - see the USBSID-Volume-daughterboard manual for details.

# PCB bottom overview


Figure 2. PCB bottom overview

# License

# Software License ~ GNUv2

All code written by me in this repository is licensed under the terms of the GNU General Public License as published by the Free Software Foundation, version 2. Any code in this repository that is not written by me automatically falls under the licensing conditions by the authors of said code as mentioned in the source code header. For for more information about this license please read the LICENSE document in the root of the USBSID-Pico repository.

# Configtool Software License ~ EPLv2

# USBSID-Pico v1.5 PCB Hardware License ~ CC BY-NC-


This program and the accompanying materials are made available under the terms of the Eclipse
Public License 2.0 which is available at http://eclipse.org.
SPDX-License-Identifier: EPL-2.0

USBSID-Pico v1.5 PCB © 2026 by LouD (https://github.com/LouDnl) is licensed under
Creative Commons Attribution-NonCommercial-NoDerivatives 4.0 International (https://creativecommons.org/licenses/by-nc-nd/4.0/)

USBSID-Pico v1.3 PCB Hardware License ~ CC BY-SA 4.0

USBSID-Pico v1.3 PCB (https://github.com/LouDnl/USBSID-Pico/tree/master/hardware/USBSID-Pico-v1.3) © 2025-2026 by LouD (https://github.com/LouDnl) is licensed under
Creative Commons Attribution-ShareAlike 4.0 International (https://creativecommons.org/licenses/by-sa/4.0/)

USBSID-Pico v1.0 PCB Hardware License ~ CC BY-SA 4.0

USBSID-Pico v1.0 PCB (https://github.com/LouDnl/USBSID-Pico/tree/master/hardware/USBSID-Pico-v1.0) © 2024-2026 by LouD (https://github.com/LouDnl) is licensed under

USBSID-Volume-daughterboard v1.0 PCB Hardware
License ~ CC BY-SA 4.0

Volume-daughterboard v1.0 PCB © 2026 by LouD (https://github.com/LouDnl) is licensed under

Author: LouD - generated on 2026-09-03

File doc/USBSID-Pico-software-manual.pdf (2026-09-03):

# USBSID-Pico software manual

### Author: LouD - generated on 2026-09-03

# Table of Contents

# Disclaimer

I do this stuff in my free time for my enjoyment. Since I like to share my joy in creating this with everyone I try my best to provide a working PCB and Firmware. I am in no way an electronics engineer and can give no guarantees that this stuff does not break or damage your hardware, computer, phone, or whatever you try to hook it up to. Be sure to take great care when inserting any real MOS SID chips into the board. While everything has been tested with real chips, this is in no way a guarantee that nothing could go wrong. Use of this board and firmware at your own risk! I am in no way responsible for your damaged hardware. That being said, have fun!

# Supported platforms

For configuring your board itself (not the software listed below), see the USBSID-Configtool-manual file for the GUI tool, or the USBSID-Pico-firmware-manual file for the command line cfg_usbsid tool. In active development
Linux: Vice, JSidplay2, Denise, SidplayFp, RetroDebugger, SidBerry, USB Midi, WebUSB & ASID (in webbrowser) SID Play
Windows: Vice, JSidplay2, Denise, SidBerry, USB Midi, WebUSB & ASID (in webbrowser) SID Play Android: USB Midi, WebUSB & ASID (in webbrowser) SID Play
Amiga: PlaySID library

# Drivers

# Linux Udev rules

In the examples/udev (https://github.com/LouDnl/USBSID-Pico/blob/master/examples/udev-rules/) directory you can find the udev rules (https://github.com/LouDnl/USBSID-Pico/blob/master/examples/udev-rules/69-usbsid-permissions.rules) that I use on Linux.
This purely an example file that you can use and change to your own needs. Steps required for this to work

# Check if you are in the plugdev group with the groups command groups

# If not, add yourself to the plugdev group, then log out and in sudo usermod -aG plugdev $USER

# Copy the udev ules file to the correct directory

sudo cp 69-usbsid-permissions.rules /etc/udev/rules.d
# Now reload the udev rules

udevadm control --reload-rules && udevadm trigger
# Not working? Try reloading the service

sudo systemctl restart udev

# Windows driver

Use Zadig (https://zadig.akeo.ie/) to install the correct driver. Replace the driver for USBSID-Pico Data with WinUSB.


# Test and configure

After setting up your linux udev rules or Windows driver check, configure and test your board on the USBSID (https://usbsid.loudai.nl/?player=webusb) config tool website

For more information on how to configure your board, please refer to the Firmware manual (https://github.com/LouDnl/USBSID-Pico/blob/master/doc/USBSID-Pico-firmware-manual.adoc)

# Supported software

Each section covers the basic use of USBSID-Pico with the software under that section. For more in depth information please refer to the repective website and or github repo of the software.

# Deepsid

On the deepsid (https://deepsid.chordian.net/) website you can select WebUSB (Hermit) or ASID (MIDI) for playing PSID files using a supported browser.

WebUSB: After selecting WebUSB (Hermit) you need to click the CONNECT button and select USBSID-Pico in the pop-up window. Due to the autoplay feature of Deepsid, you might have to press STOP a couple of times before the CONNECT button will work.

ASID: After selecting ASID (MIDI) you need to select USBSID-Pico in the dropdown box next to the line that says MIDI port for ASID. It might require refreshing the page a couple of times for the box to be filled with midi devices.
Supported browsers:
- Firefox supports ASID.
- Chrome supports both WebUSB and ASID.
- Edge supports both WebUSB and ASID.

# SidBerry

SidBerry (https://github.com/LouDnl/SidBerry) supports PSID files only and can play SID files on USBSID-Pico via CDC (default) or on ASID supporting players via command line arguments.
General Linux usage:

# to play sidfile.sid on USBSID-Pico usbsidberry path/to/sidfile.sid

# to detect and print available midi devices

usbsidberry -midi
# to play sidfile.sid via ASID on USBSID-Pico where `1` is the respective port of the ASID device

usbsidberry -asid 1 path/to/sidfile.sid

Basic Windows usage:

# to play sidfile.sid on USBSID-Pico usbsidberry.exe path/to/sidfile.sid

# to detect and print available midi devices

usbsidberry.exe -midi
# to play sidfile.sid via ASID on USBSID-Pico where `1` is the respective port of the ASID device

usbsidberry.exe -asid 1 path/to/sidfile.sid

# Vice

This section covers the use of USBSID-Pico with Vice under Linux, Windows and MacOS for the GTK and SDL2 versions of vsid and x64sc

WARNING

Switching on readmode and then switching it off again without restarting the PCB and Vice will result in distorted audio

### Command-line arguments

Command-line arguments override any previously configured items in your vicerc config file.
All three OS support the same command-line arguments for both vsid and x64sc.
However, the sound device argument is OS specific and vsid supports a maximum of 3 SID chips Note that if you define extra SID’s and their addresses, these addresses need to point to the required address for the SID tune or Software you want to use. The Vice USBSID-Pico driver will automatically convert each write to the in firmware configured SID chip.
Below is an excerpt from the Vice manual with information about each command-line option

-usreadmode <0 or 1>
Enable USBSID-Pico read mode. When enabled, this mode allows for reading from SID registers that provides a means to configure an FPGASID that is seated on USBSID-Pico. This mode is not suited for regular audio use as it disables cycle exact writing & digiplay. Default is (SidUSBSIDReadMode=0) for off, (SidUSBSIDReadMode=1) for on.

-usaudiomode <0 or 1>
Set USBSID-Pico PCB (v1.3) audio mode to Stereo or Mono. When enabled the audio of SID socket 1 will be output over the left audio channel and the audio of SID socket 2 over the right channel of USBSID-Pico's audio out. Default is (SidUSBSIDAudioMode=0) for Mono, (SidUSBSIDAudioMode=1) for Stereo.

-usdiffsize <number divisable by 8>
Specifies the minimal difference in bytes to use between the head and tail of the drivers ringbuffer, this allows for some audio quality tuning on slower systems. In most cases the default value of 64 bytes (also the size of a USB packet) is the right setting for best audio quality. (SidUSBSIDDiffSize=32-256).

-usbuffsize <number divisable by 8>
Specifies the size in bytes to use as ringbuffer to store temporary data when sending SID writes to USBSID-Pico, this allows for some audio quality tuning on slower systems. In most cases the default value of 8192 bytes is the right setting for best audio quality. (SidUSBSIDBufferSize=512-16384).

### x64sc GTK

ALT+O or click Preferences/Settings to open the settings menu.
Sound configuration
The sound configuration will require tuning for the computer you use it on.
In the screenshot below you can see that for this system I use the pulse audio driver and have the Buffer size set to 1 millisecond and Fragment size set to very small.
These 3 settings can make or break the audio quality.


SID configuration
For any audio to come out of the board you need to select USBSID-Pico as SID engine.
If you want to use more the one SID then you need to select the amount of Extra SIDs and set their I/O addresses.


### x64sc SDL2

Press F12 (Linux/Windows) / F10 (MacOs) to open the settings menu.
Sound configuration
The sound configuration will require tuning for the computer you use it on.
In the screenshot below you can see that for this system I use the pulse audio driver and have the Buffer size set to 25 milliseconds and Fragment size set to very small.
These 3 settings can make or break the audio quality.


To get to these settings follow the following settings path:
Sound settings ⇒ Output driver ⇒ Select the driver you want to use Sound settings ⇒ Buffer size ⇒ Select the milliseconds you want to use
Sound settings ⇒ Fragment size ⇒ Select the size you want to use
SID configuration
For any audio to come out of the board you need to select USBSID-Pico as SID engine.
If you want to use more the one SID then you need to select the amount of Extra SIDs and set their I/O addresses.


To get to these settings follow the following settings path:
Machine settings ⇒ Model settings ⇒ SID settings ⇒ SID model ⇒ USBSID-Pico
Machine settings ⇒ Model settings ⇒ SID settings ⇒ Extra SIDs ⇒ select the amount of extra SID’s
and set their addresses

### vsid GTK

ALT+O or click Preferences/Settings to open the settings menu.
Sound configuration
The sound configuration will require tuning for the computer you use it on.
In the screenshot below you can see that for this system I use the pulse audio driver and have the Buffer size set to 1 millisecond and Fragment size set to very small.
These 3 settings can make or break the audio quality.


SID configuration
For any audio to come out of the board you need to select USBSID-Pico as SID engine.
If you want to use more the one SID then you need to select the amount of Extra SIDs and set their I/O addresses.


### vsid SDL2

Press F12 (Linux/Windows) / F10 (MacOs) to open the settings menu.
Sound configuration
The sound configuration will require tuning for the computer you use it on.
In the screenshot below you can see that for this system I use the pulse audio driver and have the Buffer size set to 10 milliseconds and Fragment size set to very small.
These 3 settings can make or break the audio quality.


To get to these settings follow the following settings path:
Sound settings ⇒ Output driver ⇒ Select the driver you want to use Sound settings ⇒ Buffer size ⇒ Select the milliseconds you want to use
Sound settings ⇒ Fragment size ⇒ Select the size you want to use
SID configuration
For any audio to come out of the board you need to select USBSID-Pico as SID engine.
If you want to use more the one SID then you need to select the amount of Extra SIDs and set their I/O addresses.

To get to


these settings follow the following settings path:
SID settings ⇒ SID model ⇒ USBSID-Pico
SID settings ⇒ Extra SIDs ⇒ select the amount of extra SID’s and set their addresses

# jsidplay2

This section covers the use of USBSID-Pico with jsidplay2

### Settings

After starting JSidplay2 you can choose USBSID-Pico from the dropdown menu that says emulation and set the board to mono or stereo using the settings dropdown



### c64jukebox

c64jukebox website that runs on jsidplay2 available at haendel.ddns.net:8443/static/c64jukebox.vue

To enable USBSID-Pico in a WebUSB supporting browser (like Chrome) click on the Hardware tab and then click Connect in the USBSID-Pico box. After connecting search for any SID file in the search tab and click the play button.

WARNING

Because this play method is not perfected yet there will be delays when selecting a follow up tune and pressing stop or pause. This can be circumvented enabling use await for USBSID write on the Hardware tab, but this will severely impact playing tunes that rely on timing


# Denise

This section covers the use of USBSID-Pico with the C64 emulator of Denise

### USBSID settings

Open the C64 settings menu and go to the audio tab. Under this tab on the left side you will see an
USBSID-Pico option
Here you can enable or disable the use of USBSID-Pico. If you have any audio issue you can try to
increase | the | buffer | and | diff | sizes.


### SID settings

Open the C64 settings menu and go to the audio tab. Under this tab on the left side you will see a Chip option
Here you can configure the amount of SID’s you have on the board. Be sure to try the different
settings | for | better | output.


# Retrodebugger

t.b.d.

# sidplayfp

t.b.d.

# License

# Software License ~ GNUv2

All code written by me in this repository is licensed under the terms of the GNU General Public License as published by the Free Software Foundation, version 2. Any code in this repository that is not written by me automatically falls under the licensing conditions by the authors of said code as mentioned in the source code header. For for more information about this license please read the LICENSE document in the root of the USBSID-Pico repository.

# Configtool Software License ~ EPLv2

This program and the accompanying materials are made available under the terms of the Eclipse Public License 2.0 which is available at eclipse.org.
SPDX-License-Identifier: EPL-2.0

# USBSID-Pico v1.5 PCB Hardware License ~ CC BY-NC-

ND 4.0

USBSID-Pico v1.5 PCB © 2026 by LouD (https://github.com/LouDnl) is licensed under
Creative Commons Attribution-NonCommercial-NoDerivatives 4.0 International (https://creativecommons.org/licenses/by-nc-nd/4.0/)

# USBSID-Pico v1.3 PCB Hardware License ~ CC BY-SA 4.0

USBSID-Pico v1.3 PCB (https://github.com/LouDnl/USBSID-Pico/tree/master/hardware/USBSID-Pico-v1.3) © 2025-2026 by LouD (https://github.com/LouDnl) is licensed under
Creative Commons Attribution-ShareAlike 4.0 International (https://creativecommons.org/licenses/by-sa/4.0/)

# USBSID-Pico v1.0 PCB Hardware License ~ CC BY-SA 4.0

USBSID-Pico v1.0 PCB (https://github.com/LouDnl/USBSID-Pico/tree/master/hardware/USBSID-Pico-v1.0) © 2024-2026 by LouD (https://github.com/LouDnl) is licensed under

# USBSID-Volume-daughterboard v1.0 PCB Hardware License ~ CC BY-SA 4.0


Creative Commons Attribution-ShareAlike 4.0 International (https://creativecommons.org/licenses/by-sa/4.0/)

Volume-daughterboard v1.0 PCB © 2026 by LouD (https://github.com/LouDnl) is licensed under

Author: LouD - generated on 2026-09-03

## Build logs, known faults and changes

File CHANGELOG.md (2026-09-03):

# Changelog
Please refer to the [releases page](https://github.com/LouDnl/USBSID-Pico/releases) for more information on version changes

#### Version: 0.8.0
* Add full MIDI implementation overhaul: dedicated flash-backed MIDI config storage, MIDI engine/handler/queue/voice/patch/arp table modules, MIDI clock control, sid bus spinlock
* Add FMOpl (OPL2/3) MIDI control, fixes and new config item support
* Add MIDI patch and arpeggiator table examples, MIDI example tools (CC controller, patch editor), VMPK/Strudel/TidalCycles MIDI examples
* Migrate embedded Cynthcart to run through the onboard USBSID-Player instead of the old emudore-based path, new `_cc` firmware variant
* Add embedded USBSID-Player support for Pico and Pico W (rp2040) builds, previously Pico 2 / Pico 2 W only
* Deprecate and remove "Adorable" onboard C64 emulator (emudore) support
* Fix SIDs getting disabled on USB dismount
* Fix `last_preset` config setting for all PCB versions
* Guard ASID writes during reset and while ASID is disabled
* Fix stale DMA functions
* Add overclock warning (250MHz) to README and manuals for firmwares using the embedded USBSID-Player or Cynthcart
* Fix compilation error caused by octal-looking version numbers
* Update GitHub and GitLab CI build workflows
* Update firmware, Cynthcart, PCB v1.0/v1.3/v1.5, Configtool and Player manuals
* Add docstrings across source, add extra compiler attributes

#### Version: 0.7.7
* Fix board -> host WebUSB writes to be 64 bytes
* Add mute/clear so OPL audio won't linger
* Fix WebUSB config read
* Remove deprecated item

#### Version: 0.7.6
* Add and implement new onboard SID player features
* Add default support for song lengths to `send_sid`
* Update web config tool
* Update buildtools workflow

#### Version: 0.7.5
* Optimize Vu handling, fix Vu on embedded play without USB
* Fix ASID regression
* FMOpl fixes and added support for new config items
* Fix timing issue in `detect_all`, fix issue in `update_probe_config_from_detection`
* Fix FPGASID detection leaving it in config state
* Guard buffer overrun in buffer tick
* Fix SKPico firmware type detection
* Force RP2350 to 250MHz with onboard SID Player
* Add CDC interface guard, remove unused RAM pointers for SID Player
* Fix claim/detach/release/unclaim kernel driver issues in CLI config tool
* Update CLI config tool for new features
* Update config-tool-web with USBSID-Player only handlers
* Add Cartridge Case by spotUp, v1.5 remix by LouD

#### Version: 0.7.4
* Add new USBSID-Player for Web, add player supporting code
* Fix v1.5 regression in SID play after socket change detection
* Update Vendor class (WebUSB) for new web player

#### Version: 0.7.3
* Fix voltage apply when saving config without reboot
* Return `last_preset` in config buffer
* Set current preset based on current config (v1.5+ boards)
* Add web player URL loading

#### Version: 0.7.2
* Fix FPGASID config address display error
* Fix disable-autodetect feature so the config-tool GUI works correctly
* Add additional SID player commands
* Add USB command to read compiled USBSID features
* Add v1.3 KiCad files, update v1.3 gerbers/schematic/BOM, add v1.3 OSHWA certification
* Add Volume-daughterboard files (v1.5 hardware), add v1.5 BOM and schematic
* Consolidate build pipelines into a single GitLab CI runner
  - Fix race conditions and toolchain errors in build pipeline
  - Enable Windows and MacOS ARM builds on gitlab.com

#### Version: 0.7.1
* Add init READ/WRITE CHIPCONFIG commands
* Add init READ/WRITE CLONECHIP commands
* Add GET_AUDIO config command
* Enforce stdio_flush after each UART log write
* Add required config commands to header

#### Version: 0.7.0
* Add initial v1.5 PCB support
  - Fix voltage set order so clone SIDs don't misbehave
  - Fix incorrect packet length on reads (must be 64 bytes for WebUSB)
* [BREAKING CHANGE] Rewrite configuration logic, improve and clear up logging
  and SID/chip detection
  - Add limited ARMSID, PDSID and BACKSID support
* Add SIDEmu detection and support
* Add FPGASID preset support
* Change midi->SID control to a user defined channel, save settings per
  channel (like an instrument)
* Enable direct Midi access even when onboard emulator is present
* Rename `midi_cc` to `midi_defs`
* Deprecate `usbsid_doubletap`
* Add Cynthcart VST (by Raros)
* Add first iteration of new webconfig tool
* Header cleanup: internalize externs
* Add stdio_flush during PIO bus setup/sync, fixes memory corruption
* Add workaround for lingering data in the vendor fifo
* Fixes for new SKPico firmware versions
* Stall Core1 until completely finished booting, add Firmware compilation
  log type

#### Version: 0.6.4-BETA
* Fix onboard SID player playback issues

#### Version: 0.6.3-BETA
* Log USBSID version at end of boot, reset SIDs at end of boot
* Add PDSID detect and SID type config, rework auto detection
* Start rebuilding native Midi
* Fix assertion panic on invalid `raster_pio` value
* Add webconfig tool source
* Add VirtualMidiPianoKeyboard instrument file for embedded Cynthcart

#### Version: 0.6.2-BETA
* Add socket flip command to config-tool
* Reset SID registers after socket flip/change
* Fix lockups when using register `r10` without verification
* Add GitLab CI config
* Add warning/error logging for ASID buffer rate and overflow

#### Version: 0.6.1-BETA
* Add config option to flip sockets at runtime (1 <--> 2)
* Add single SID socket 2 config option
* Re-introduce ASID (ring)buffer for `write_ordered` messages (e.g.
  SIDFactoryII), add `set_asid_env`
* ASID handling overhaul
* Fix hardfault/lockup on RP2350 when toggling the mono/stereo pin
* Fix regression in boot sequence where RP2350 could freeze forever waiting
  on a semaphore; replaced with native ARM functions, boot sequence
  rearranged
* Fix `clockcycle_delay` for RP2040 by chaining two DMA channels together,
  move functions into bus.c
* Logging overhaul
* Also reset the writeorder when midi/asid is no longer mounted
* Add shortcuts to command line arguments
* Add custom naming parameter to build scripts, add MacOS support

#### Version: 0.6.0-BETA
* Add first iteration of onboard SID player (PRG support, next/previous
  tune, buffer)
* Add first iteration of onboard C64 emulator (emudore based Cynthcart)
  - Add shared memory support between core0/core1
  - Increase midi->cynthcart queue size
* Overclock RP2350 for onboard SID player, optimize build to -O3
* Add Pico2 RGB support
* Fix muting so all volume ($18) registers are masked/muted correctly
* Add PDSID type switch command, clone SID config commands, config error
  check + fallback
* Add non-cycled direct PIO write operation
* Add optional cycled_delayed_write_operation and
  cycled_write_operation_nondma functions
* Split gpio.c into separate files, add clock counter
* Rework branch prediction, remove endless loop workaround
* Fix SID register reset
* Fix `sid_memory` not cleared by `clear_sid_registers`
* Move bus bit related settings into `set_bus_bits`
* Disable unsupported DMA type on RP2040
* Start re-implementation of Midi handling
* Add first iteration of UART SID writes
* Add build script for CLI config tool
* Update GUI config tool (credits @ISL/Samar)
* Add v1.3 gerbers, update v1.0 BOM, OSHWA certification for v1.0 PCB
* Add Dual USBSID-Pico C64 Case (by OlefinMakes)

#### Version: 0.5.0-BETA
* Add autodetection routine to first boot on new firmware and
  default firmware settings
* Double tap the reset button to start autodetection routine
  - This only works on Pico1 (rp2040) boards!
* Improve SID and Clone detection
* Add custom Sysex command for Stereo/Mono switch (v1.3 PCB only)
* Add PCB version to USB ProductId
* Disable fifo buffer for USB Vendor class (WebUSB) for
  faster writes
* Add support for ordered ASID writes
* Start rework ASID handling for sidfactory2 (thanks @thomasj)
* Rework config handling at runtime
* Add initial FPGASID support
* Fix SID reads for FPGASID
* Lots of minor changes and fixes
* Code splicing into separate files for readability

#### Version: 0.4.0-BETA
* Fix SID reads
* Fix bug causing mirrored SID config from working
* Fix ASID/Midi cutoff during play
* Fix ASID play on Pico2 not working
* Fix reset reason not working on Pico2
* Fix Pico2 default config error withing same fw version
* Improve buffer handling
  - migrate for loops into state machines
* Improve SID test runs
  - add option to stop tests
  - run tests from Core 1
* Improve and compress Vu (RGB) LED handling
  - migrate Vu LED PWM into PIO PWM
  - remove use of large RGB lookup table
* Improvemets in SID bus handling
* Improve bootup sequence
* Update TinyUSB API use
* Update NTSC clockspeeds
* Update SDK dependency to 2.1
* Add support for PCB v1.3 audio switch
* Add reserverd flash partition for persistent storage
* Add optional clockrate locking
  - this locks the clockrate in config so it can no
    longer be changed
* Add workaround fix for SID3 not always working
* Add FMOpl support (Clone SID only)
* Add Pico2W support
* Add auto config website opening on default config

#### Version: 0.3.0-BETA
* USB buffer handling overhaul
  - Add support for incoming packets of variable sizes
  - Add more command types
  - Add commands for WebUSB
* GPIO init overhaul
  - Fix DMA panic on Pico_w
  - Add syncing of PIO's
  - Add stream buffer support
  - Add check for Clone type sid to reset_set
    SKPico does not handle resets very well
  - Move SID clock functions to GPIO
* PIO bus overhaul
  - Add support for clock cycle writes
* Add 4x SID support to ASID handler
* Rework config handling
  - Add optional command for retrieving socket config only
  - Split apply_config into separate functions
  - Update/Fix SID type detection
    - Add delays between detection commands
    - Add retry to try 3 times if detection fails
* General code rework
  - Move util functions into separate util file
* Update web config tool
* Update examples
  - Add cli config-tool
  - Add USBSID-Pico-driver repo
  - Add SidplayFp repo
  - Add libSidplayFp repo

#### Version: 0.2.3-BETA
* Add workflow for auto version release build
* Fix issue in SID tests not stopping
* Add Support for Pico2 (rp2350) green board
* Add Support for PicoW (rp2040) green board
  - NOTE: Due to the LED being used by the WiFi chip there is no VU support
* Rename Vue to Vu 🤦‍♀️
* Remove `__builtin_` function calls

#### Version: 0.2.2-BETA
* Add direct SID functions
  - Detect SID type
  - Test SID voices
* Add config commands for SID testing functions
* Add function to clear SID registers without SID reboot
* Add some debug logging
* Update config handling
  - Add direct SID functions
  - Add version retrieval support
  - Check if set clockspeed is correct or se default
  - Fix write functions
  - Fix some values on SID count change
* Update USB descriptors
  - Add version in manufacturer string
* Enable CC's for bank 9 (temporary workaround)
* Refactor some whitespace
* Start work on support for PicoW and Pico2 boards

#### Version: 0.2.1-BETA
* Start on update for Midi handling
  * Details will follow at a later time when finished
* Fix ASID play
* Fix config save error

#### Version: 0.2.0-BETA
* Basic Midi support
  * Fixed to 6 voices polyfonic with 2 SID's up to 12 voices with 2x SKPico.
* WebUSB support
  * Proof of concept available in examples folder
  * Currently uses an adapted version of Hermit's emulator
* Improved GPIO handling
  * Bus control via DMA and PIO for cycle exact writes and reads
* Customizable config (config tool in development) 

#### Version: 0.0.1-ALPHA
* Basic working functions
  * Multiple firmware binaries per config type
  * SID control via GPIO
  * USB support
    - see examples
  * Midi support
    - messy and unfinished
  * ASID support
    - basic functionality
  * Onboard LED works as VU
    - RGB LED support for clone Pico boards

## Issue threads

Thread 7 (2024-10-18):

How to buy PCB & PCBA

Ivy-Mo, 2024-10-18:
It’s Ivy from WellerPCB,we help you turn your designs into real objects PCB&PCBA, and we want to work with you over the long term, starting with samples.We sincerely looking for solution that bring you potential benefits.

I'll let you know the ordering process and hopefully help some of you who want to order.

If you want to buy first you have to know the price:
1. For PCB, you need to provide Gerber file. For PCBA, you need to provide Gerber file and BOM list.
2. Send these files to ivy@wellerpcb.com and wait for the offer to be completed., this will take about 1-2 days, if the  specifications needed for the quotation are missing such as the information of the stacked structure and the impedance information, we will contact you as soon as possible, please don't worry.

Price difference:
If you feel that there is a certain difference with other supplier's quotation may be due to the following factors.
1. Machine bonding and hand soldering: the former will be more expensive, but ensure the stability of the soldering, which is important for high quality requirements of the project.
2. No replacement components: some suppliers will replace your components with other brands of poorer quality components, or the use of fake components, high risk.
3. Different processing standards and quality: Each supplier has different production standards, if it is a case of distrust, the best way is to visit the factory and understand the production process.

Place an order:
Make sure you have the following documents before officially produce.
1. Gerber document
2. BOM list
3. Stencil file
4. Coordinate file
5. Silk-screen bitmap

Shipment Confirmation:
Declare the amount and shipping address

Waiting for logistics delivery:
Receive PCB & PCBA ;)

Hope this helps, all the best with the design!

LouDnl, 2024-10-18:
Thanks for the tip, but PCBWay is just fine for now.

Closed 2024-10-18.

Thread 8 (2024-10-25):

Digiplay support

LouDnl, 2024-10-25:
I had this working with v0.2.0-BETA firmware in Vice by using libusb async and their (libusb) example but for some reason I can't find that piece of code anymore and cannot get it to work again.

Seeking some assistance in writing a working driver for digiplay.
This will probably need some buffering for sending filled up 64 byte packets and firmware side handling.

Player/emulator status:
* [x] Vice/Vsid ~ **fixed**
* [ ] Retrodebugger
* [x] sidplayfp/libsidplayfp ~ partially, needs some work
* [ ] jsidplay2 c64jukebox ~ working, webusb needs tweaking

LouDnl, 2024-11-11:
As of yet I am still unable to recreate a working Vice version driver, work in progress.

LouDnl, 2024-11-26:
@thomasj I thought digiplay did not work through ASID?

thomasj, 2024-11-26:
There is nothing in the ASID protocol itself that prevents digis from playing (as it is only updating SID registers) - but as the original design of it was using standard MIDI, that is too slow for digis. But when running ASID over USB with a receiving device that could handle thousands of updates per second, digis probably should work fine!

LouDnl, 2024-12-14:
Digiplay issues mostly solved with a [new driver (first version)](https://github.com/LouDnl/USBSID-Pico-driver) and tested with added support to [libsidplayfp](https://github.com/LouDnl/libsidplayfp-usbsid) and played with [sidplayfp](https://github.com/LouDnl/sidplayfp-usbsid).
Not _all_ digitunes are fixed yet, but that shouldn't be a huge issue.

LouDnl, 2024-12-27:
New driver got me steps closer to solving the issue in Vice too. Not finished yet, but getting there!

LouDnl, 2024-12-30:
While still not completely in cycle sync, playing Commodore 64 digitunes with Vice (and others) using USBSID-Pico are almost fixed! Here's an example using Quantum Tracker's No Limit demo!
https://github.com/user-attachments/assets/886f4fac-4fde-43db-aa9e-e3e5bd456849

LouDnl, 2025-01-25:
Current status with Vsid: https://usbsid.loudai.nl/examples/Jammer%20-%20Make%20Some%20Noise.mp3

LouDnl, 2025-01-25:
Vice/Vsid marked fixed

Closed 2025-02-05.

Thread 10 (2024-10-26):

Improve buffer handling

LouDnl, 2024-10-26:

LouDnl, 2024-11-11:
ASID issues fixed in 0c2e536fd369c57f36c98a3c2be2531609dcac5e
Release: https://github.com/LouDnl/USBSID-Pico/releases/tag/v0.2.1-BETA

LouDnl, 2024-11-20:
This is already fixed in 0c2e536fd369c57f36c98a3c2be2531609dcac5e

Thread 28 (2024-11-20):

Add short tutorials (example code) for using USBSID-Pico with strudel.cc and TidalCycles

LouDnl, 2024-11-20:

LouDnl, 2024-11-22:
https://github.com/LouDnl/USBSID-Pico/wiki/TidalCycles

LouDnl, 2024-11-22:
https://github.com/LouDnl/USBSID-Pico/wiki/Strudel

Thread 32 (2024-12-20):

Room for ZIF sockets for SIDs on PCB ?

UffeJakobsen, 2024-12-20:
From the photo it does not seem that there is enough room for mounting ZIF sockets on the PCB for the SIDs ?

The above is is correct - it would be nice if you would consider this "feature" in a future PCB revision

LouDnl, 2024-12-20:
This is indeed correct, adding ZIF sockets would require some more room around the sockets. Will note your request!

LouDnl, 2025-02-19:
That's going to need a lot of space!
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

UffeJakobsen, 2025-02-20:
> That's going to need a lot of space! !

Well - yes - but I guess that saving the remaining SID-chips makes it worth it - every time you switch SID's you risk damaging the pins.

PS: it seems from the photo that there is PCB real estate southbound of the SID's

UffeJakobsen, 2025-02-20:
> What do you mean by real estate?

It was just a way of saying (writing) that there seems to me some empty room (space) south of (below) the SID's on the PCB

LouDnl, 2025-02-20:
> > What do you mean by real estate?
>
> It was just a way of saying (writing) that there seems to me some empty room (space) south of (below) the SID's on the PCB

Ah yes, intended, to split ground planes and a header for futuredaughter boards

LouDnl, 2025-03-03:
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

This is something I cannot move anywhere else due to traces already being outside the socket area unfortunately

LouDnl, 2025-03-03:
But well see, I am receiving the new boards and some zifs this week

LouDnl, 2025-03-04:
So close 🤏🏻 the holes for the sockets aren't large enough for the zif sockets I have. How big are your socket pins? Do they fit normal socket holes?
They do fit when inserted into a socket.

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

UffeJakobsen, 2025-03-04:
> So close 🤏🏻 the holes for the sockets aren't large enough for the zif sockets I have. How big are your socket pins? Do they fit normal socket holes? They do fit when inserted into a socket.
>

I just checked those I have in my stash have more solid pins - just like yours

LouDnl, 2025-03-04:
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
Mine are chonky, so chonky that they are more fat then regular 2.57mm header pins. A light squeeze with thongs might fix it

UffeJakobsen, 2025-03-04:
>
> Mine are chonky, so chonky that they are more fat then regular 2.57mm header pins. A light squeeze with thongs might fix it

I believe that mine are the same as yours - when squeezed into a PCB (with force) there would be no need for soldering...  :-/

tobozo, 2025-03-04:
@UffeJakobsen no need for soldering, but since it can damage the holes, better solder it to make sure it only happens once 😉

LouDnl, 2025-03-04:
Just measured, it seems the socket holes are more tight then the pico socket holes. Will have a look at this when I've these the other things of v1.2 for the v1.3 release version.
I tried forcing it in dry on an old v0.1 board but there's not enough girth between the two rows.

Sry bout the puns... lol holes, girth, pins, push etc

LouDnl, 2025-03-05:
The ziffs fit in the sockets though

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

tobozo, 2025-03-05:
layer cake 😍 🍰

LouDnl, 2025-03-07:
It fits, with 3 sockets underneath to save the board socket from becoming too wide.

LouDnl, 2025-03-07:
Posting the pic might be handy here.
Ps. Oh and it works too 🤣
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

LouDnl, 2025-03-16:
I enlarged the socket holes so it can fit a zif socket. You can have it a bit above the center parts, the legs are long enough.
You can move the capacitor jumpers to the bottom for this too.
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

UffeJakobsen, 2025-05-30:
It looks much better !!! thanks 👍

> If you solder the jumpers on v1.3 like I did in the photo's above, you can also solder zif sockets directly to the pcb. Only thing you wouldnt be able to reach is the solder jumper for 8580 digiboost. You could close it before hand, leave it open or handle digiboost another way.

Looking at the v1.3 bottom photo it looks as the digiboost solder (jumper) pads are actually available on the bottom ? or am I wrong ?

LouDnl, 2025-05-30:
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

Those are for connecting EXT IN to the IN pin near the audio jack if you want to use EXT IN. You could indeed also use that for digiboost if you connect it to the ground pin

LouDnl, 2025-08-03:
With PCB v1.3 I regard this as implemented.

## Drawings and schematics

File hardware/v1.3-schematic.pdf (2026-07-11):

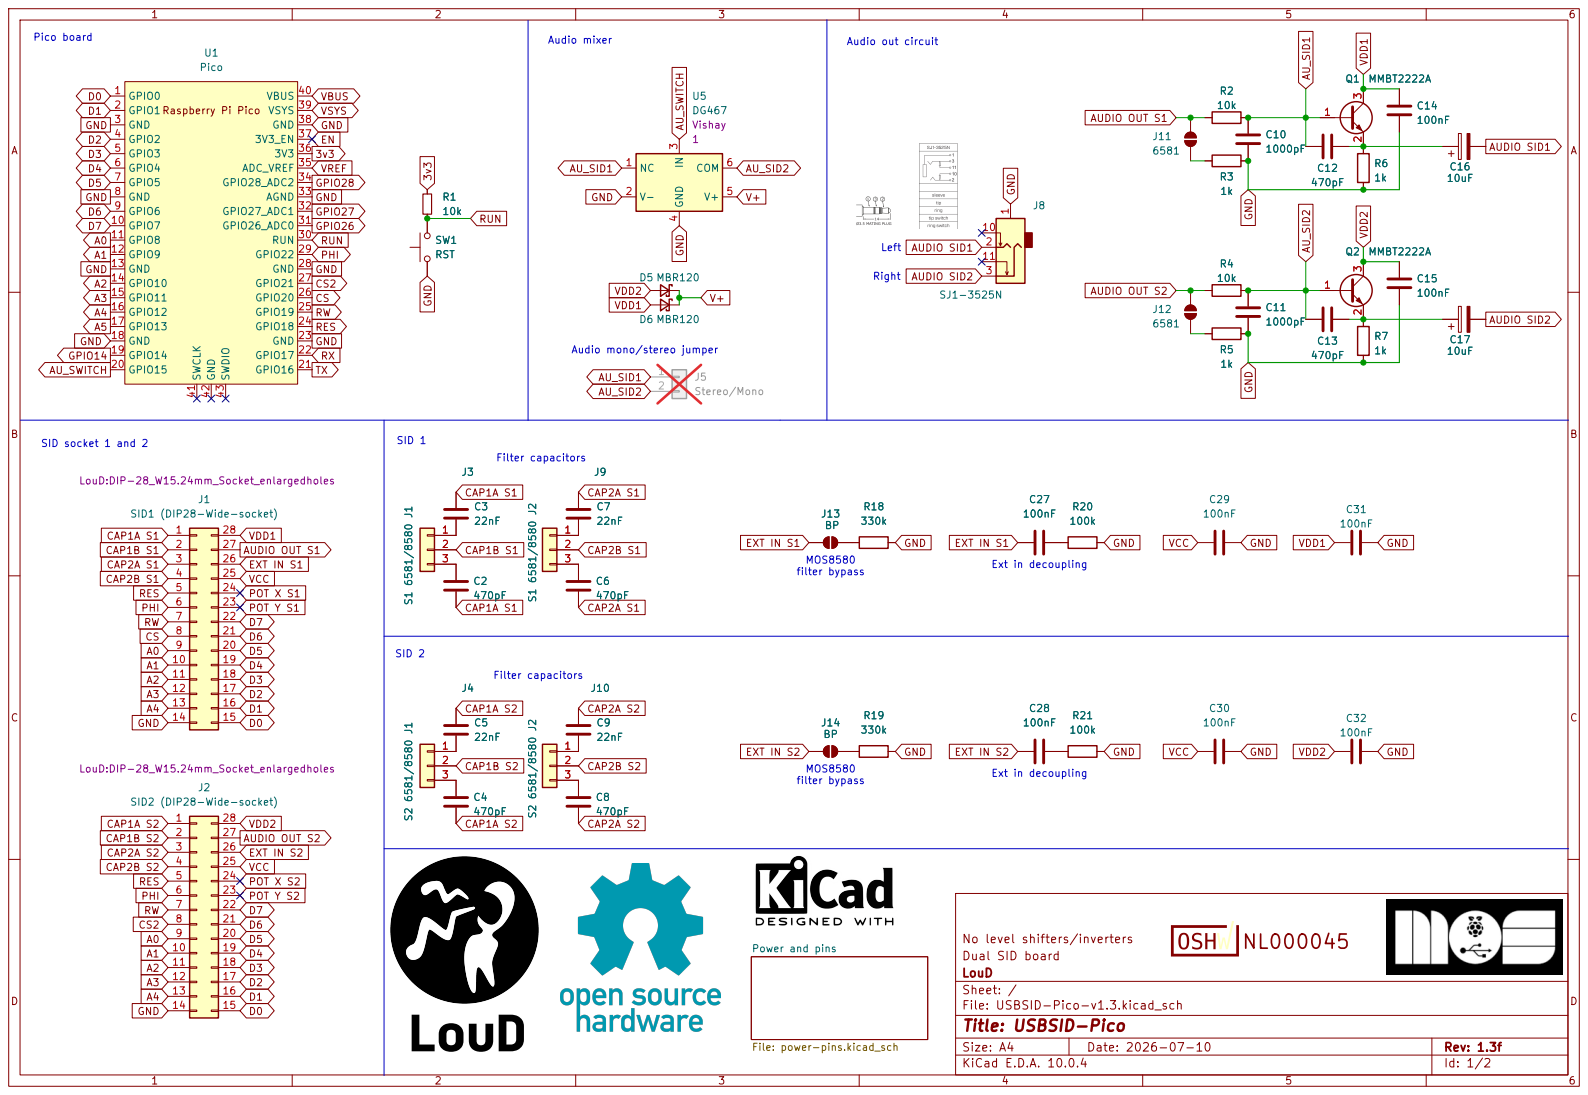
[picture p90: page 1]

SID 1 Pico board SID socket 1 and 2

Audio out circuit Right J14 BP

No level shifters/inverters Power and pins File: power-pins.kicad_sch

Size: A4 | Rev: 1.3f
KiCad E.D.A. 10.0.4 | Id: 1/2

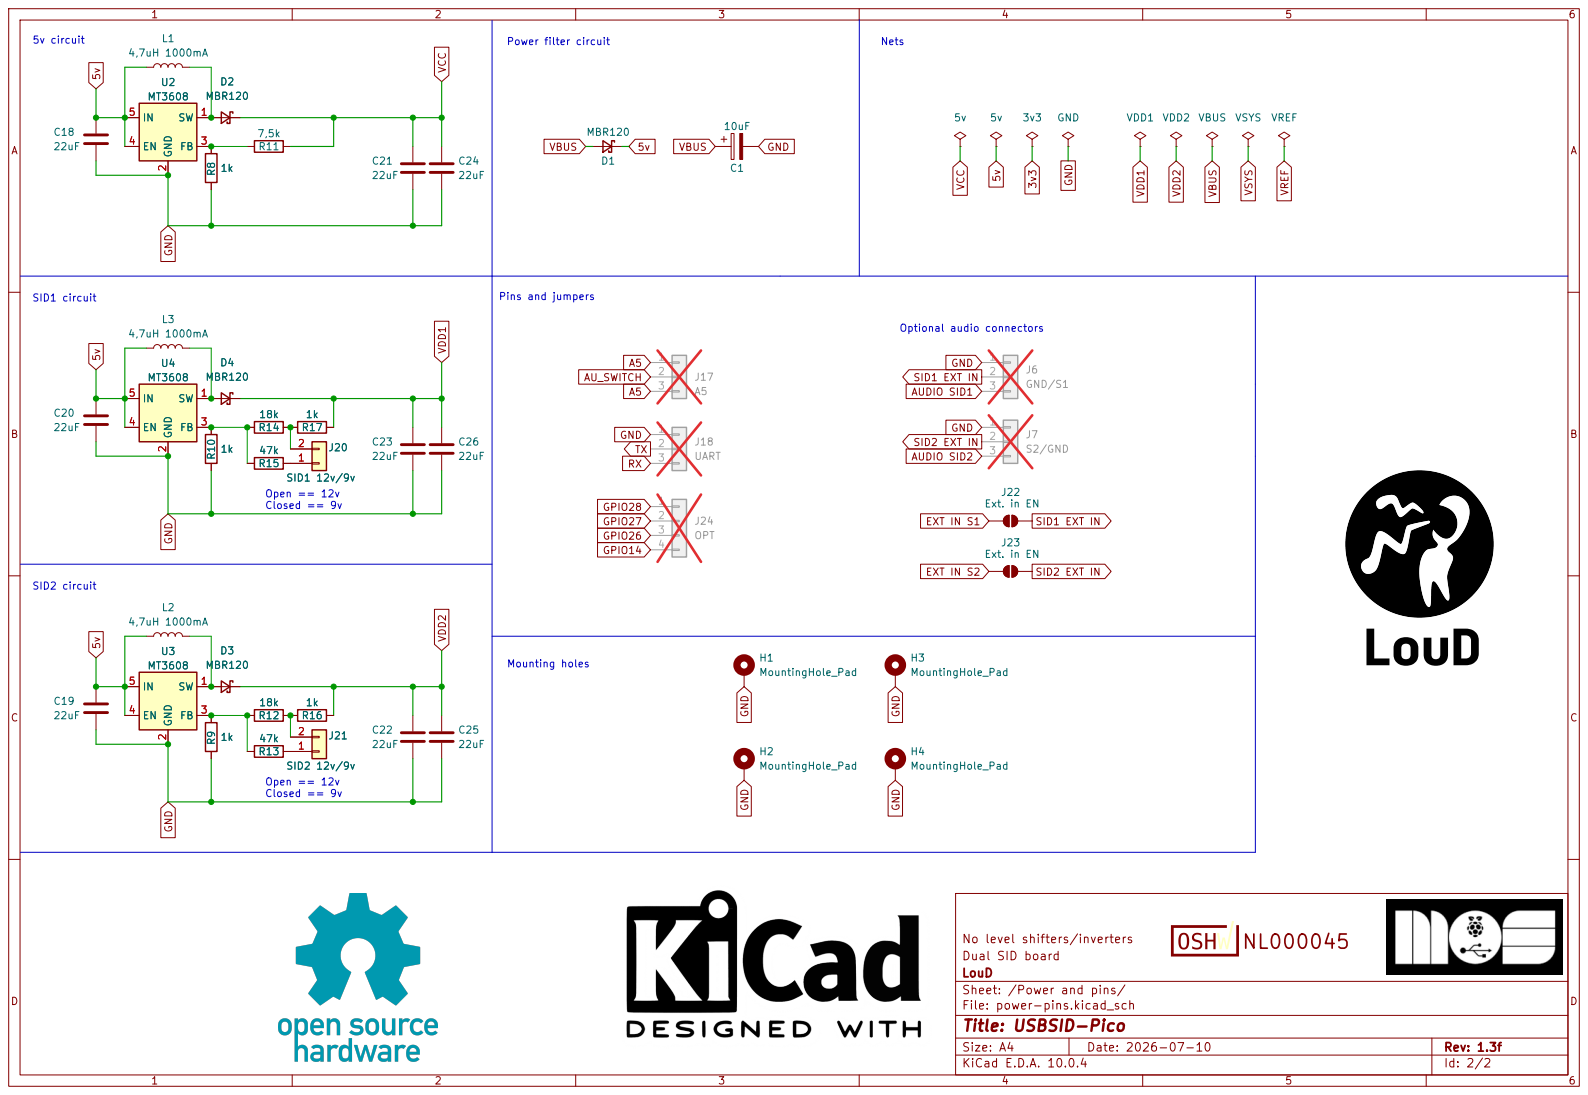
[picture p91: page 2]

No level shifters/inverters C19

Dual SID board
LouD
Sheet: /Power and pins/
File: power-pins.kicad_sch
Title: USBSID-Pico

Size: A4 | Rev: 1.3f
KiCad E.D.A. 10.0.4 | Id: 2/2

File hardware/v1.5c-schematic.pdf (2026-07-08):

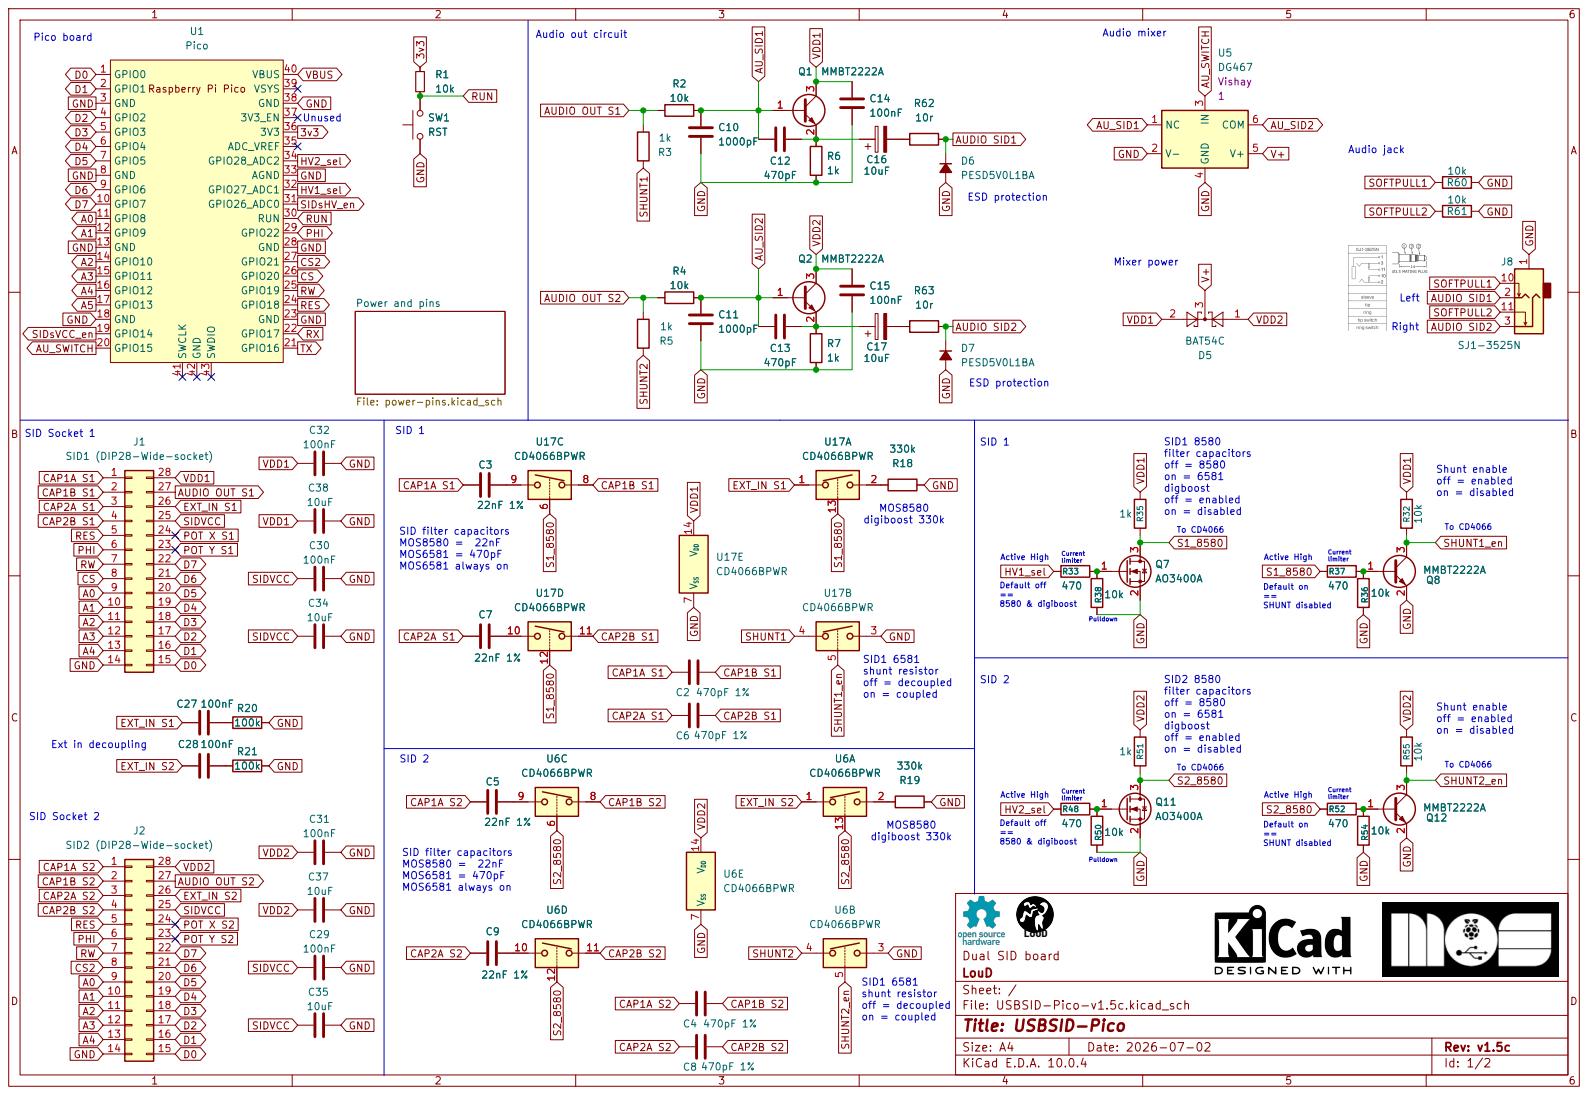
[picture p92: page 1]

Left Right Audio out circuit

SHUNT disabled Mixer power

SID filter capacitors MOS8580 = 22nF MOS6581 = 470pF MOS6581 always on SID Socket 1

To CD4066 SID filter capacitors MOS8580 = 22nF MOS6581 = 470pF MOS6581 always on SID Socket 2

SHUNT disabled SID1 6581
shunt resistor off = decoupled

To CD4066 Shunt enable off = enabled

Active High Default off == 8580 & digiboost

SID1 6581

Size: A4 | Rev: v1.5c
KiCad E.D.A. 10.0.4 | Id: 1/2

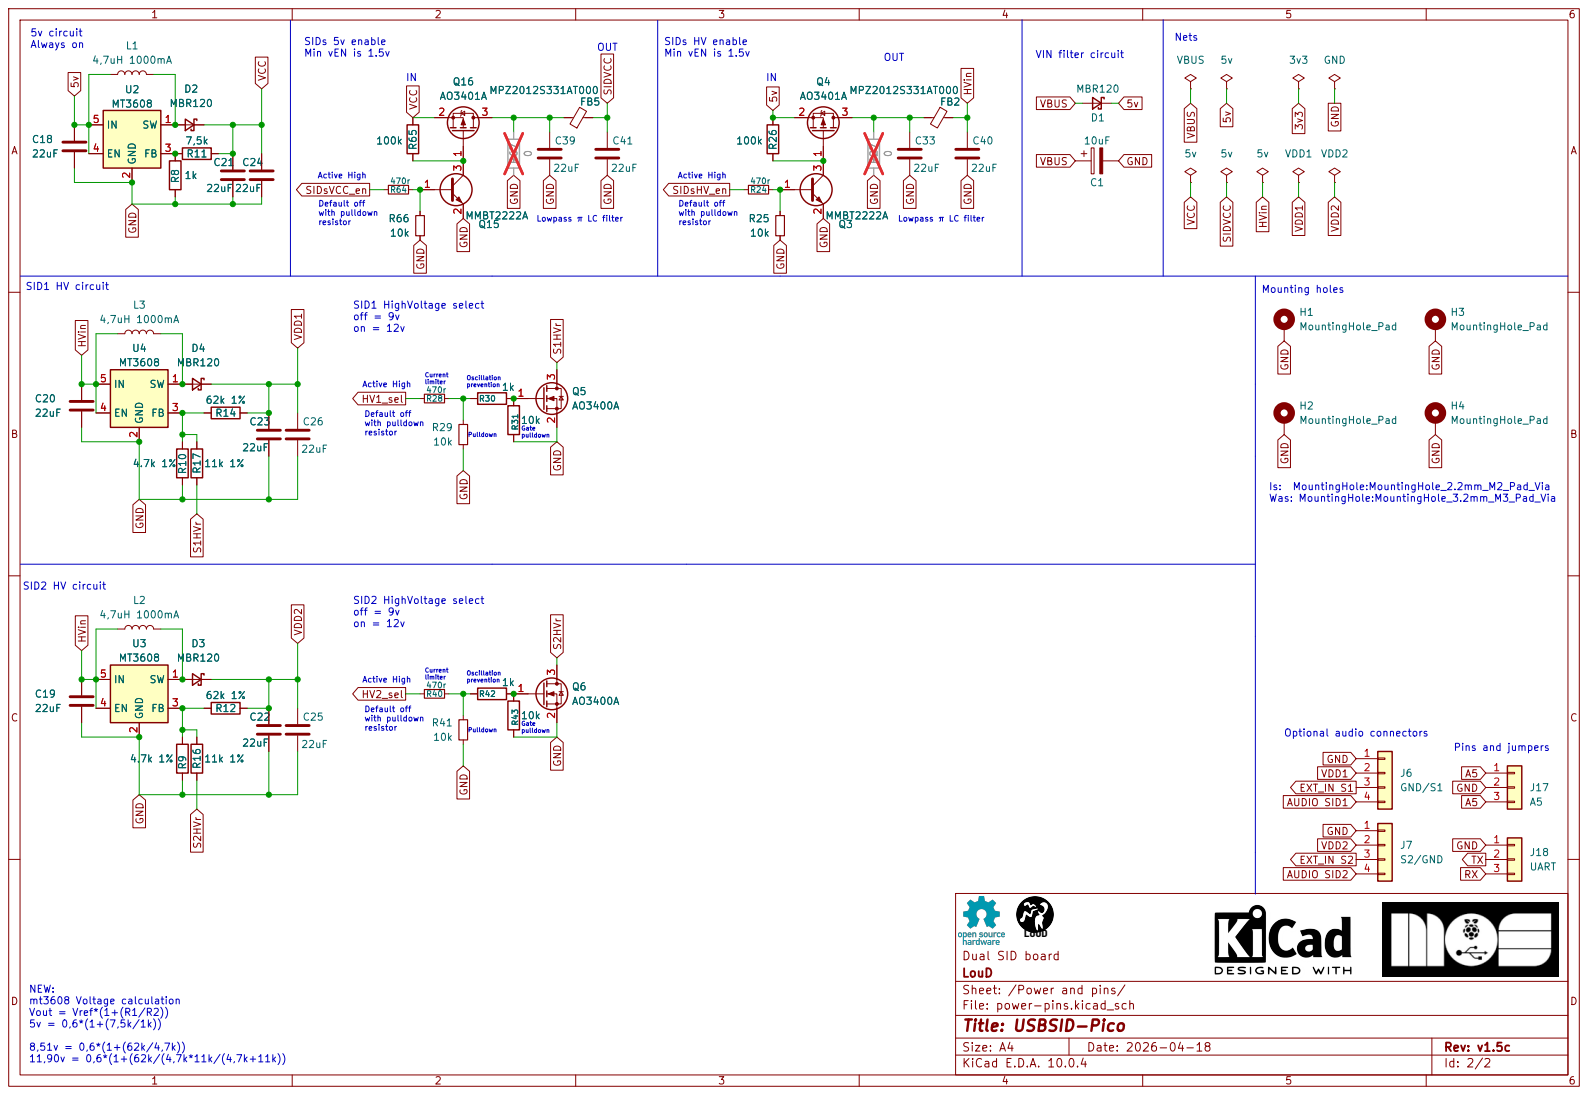
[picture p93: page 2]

SIDs HV enable Min vEN is 1.5v SID1 HighVoltage select off = 9v on = 12v NEW: mt3608 Voltage calculation

Default off with pulldown

limiter Active High Default off with pulldown
resistor Active High

Is: MountingHole:MountingHole_2.2mm_M2_Pad_Via Was: MountingHole:MountingHole_3.2mm_M3_Pad_Via Pins and jumpers

SID2 HighVoltage select off = 9v on = 12v

Dual SID board
LouD
Sheet: /Power and pins/
File: power-pins.kicad_sch
Title: USBSID-Pico

Size: A4 | Rev: v1.5c
KiCad E.D.A. 10.0.4 | Id: 2/2

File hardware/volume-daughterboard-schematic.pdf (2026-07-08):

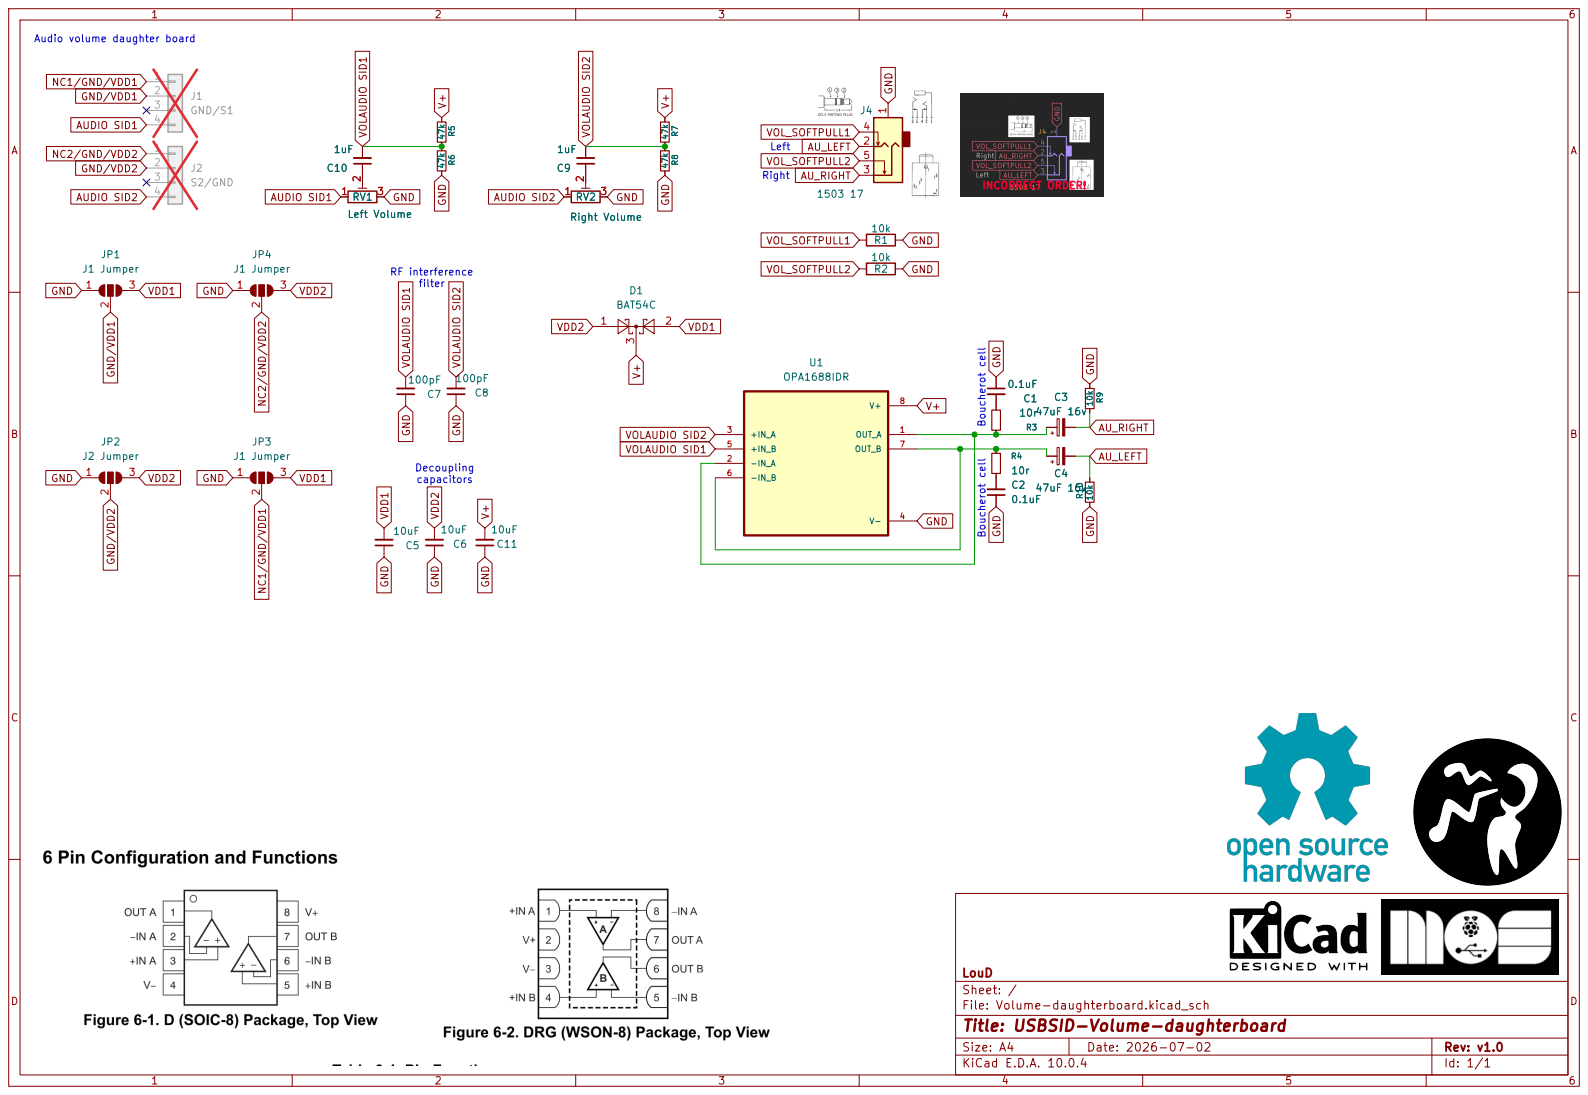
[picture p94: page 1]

filter Audio volume daughter board

LouD
Sheet: /
File: Volume-daughterboard.kicad_sch
Title: USBSID-Volume-daughterboard

Size: A4 | Rev: v1.0
KiCad E.D.A. 10.0.4 | Id: 1/1

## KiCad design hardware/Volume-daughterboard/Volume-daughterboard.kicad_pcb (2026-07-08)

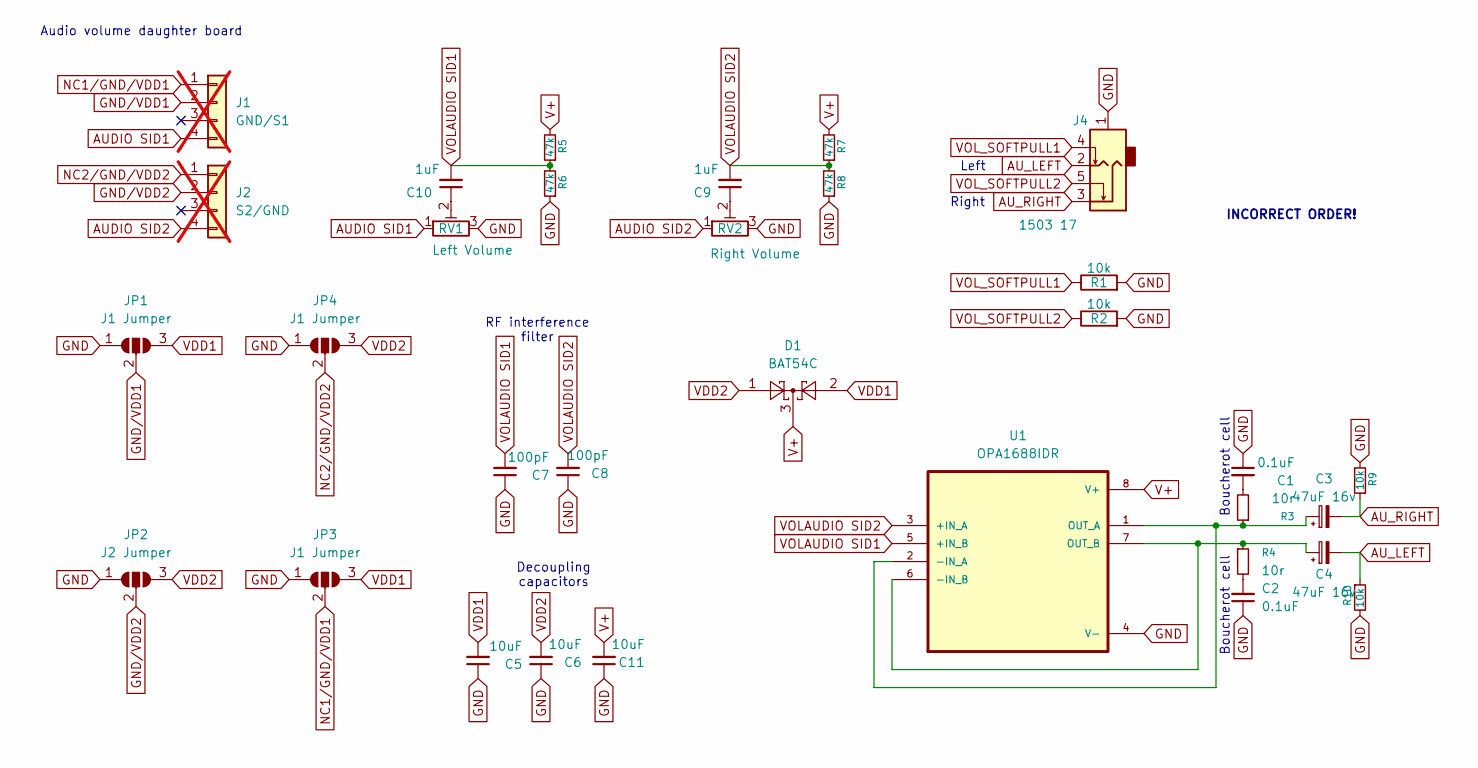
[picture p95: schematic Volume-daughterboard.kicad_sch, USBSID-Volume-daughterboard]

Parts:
C1, C2: 0.1uF; C_0805_2012Metric_Pad1.18x1.45mm_HandSolder; Mfg Part # FCC0805B104K500DT
C3, C4: 47uF 16v; CP_Elec_5x5.4; Mfg Part # FVH016ADA470M0554
C5, C6, C11: 10uF; C_0805_2012Metric_Pad1.18x1.45mm_HandSolder; Mfg Part # FCC0805X106K500FT
C7, C8: 100pF; C_0805_2012Metric_Pad1.18x1.45mm_HandSolder; Mfg Part # FCC0805N101J500BT
C9, C10: 1uF; C_0805_2012Metric_Pad1.18x1.45mm_HandSolder; Mfg Part # FCC0805B105K500FT
D1: BAT54C; SOT-23; Mfg Part # BAT54C-7-F
J1: GND/S1; PinSocket_1x04_P2.54mm_Vertical; Mfg Part # PH2.54-01-04PZD; not fitted
J2: S2/GND; PinSocket_1x04_P2.54mm_Vertical; Mfg Part # PH2.54-01-04PZD; not fitted
J4: 1503 17; Lumberg 1503 17; Mfg Part # 134382 1503-17 / SJ1-3525N
JP1, JP3, JP4: J1 Jumper; SolderJumper-3_P1.3mm_Open_RoundedPad1.0x1.5mm
JP2: J2 Jumper; SolderJumper-3_P1.3mm_Open_RoundedPad1.0x1.5mm
R1, R2, R9, R10: 10k; R_0805_2012Metric; Mfg Part # 0805W8F1002T5E
R3, R4: 10r; R_0805_2012Metric; Mfg Part # 0805W8F100JT5E
R5, R6, R7, R8: 47k; R_0805_2012Metric; Mfg Part # 0805W8F4702T5E
RV1: Left Volume; PotentioMeter; Mfg Part # RK09K1130AAU
RV2: Right Volume; PotentioMeter; Mfg Part # RK09K1130AAU
U1: OPA1688IDR; SOIC127P599X175-8N; Mfg Part # OPA1688IDR

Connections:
AUDIO SID1: J1.4, RV1.1
AUDIO SID2: J2.4, RV2.1
AU_LEFT: C4.2, J4.2, R10.1
AU_RIGHT: C3.2, J4.3, R9.1
GND: C1.1, C2.1, C5.1, C6.1, C7.1, C8.1, C11.1, J4.1, JP1.1 (A), JP2.1 (A), JP3.1 (A), JP4.1 (A), R1.2, R2.2, R6.1, R8.1, R9.2, R10.2, RV1.3, RV2.3, U1.4 (V-)
GND/VDD1: J1.2, JP1.2 (C)
GND/VDD2: J2.2, JP2.2 (C)
NC1/GND/VDD1: J1.1, JP3.2 (C)
NC2/GND/VDD2: J2.1, JP4.2 (C)
unnamed: C1.2, R3.2
unnamed: C2.2, R4.2
unnamed: C9.1, RV2.2
unnamed: C10.1, RV1.2
unnamed: C3.1, R3.1, U1.1 (OUT_A), U1.2 (-IN_A)
unnamed: C4.1, R4.1, U1.6 (-IN_B), U1.7 (OUT_B)
V+: C11.2, D1.3, R5.2, R7.2, U1.8 (V+)
VDD1: C5.2, D1.2, JP1.3 (B), JP3.3 (B)
VDD2: C6.2, D1.1, JP2.3 (B), JP4.3 (B)
VOLAUDIO SID1: C7.2, C10.2, R5.1, R6.2, U1.5 (+IN_B)
VOLAUDIO SID2: C8.2, C9.2, R7.1, R8.2, U1.3 (+IN_A)
VOL_SOFTPULL1: J4.4, R1.1
VOL_SOFTPULL2: J4.5, R2.1

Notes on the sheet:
Boucherot cell
Audio volume daughter board
RF interference filter
INCORRECT ORDER!
Left
Decoupling capacitors
Right

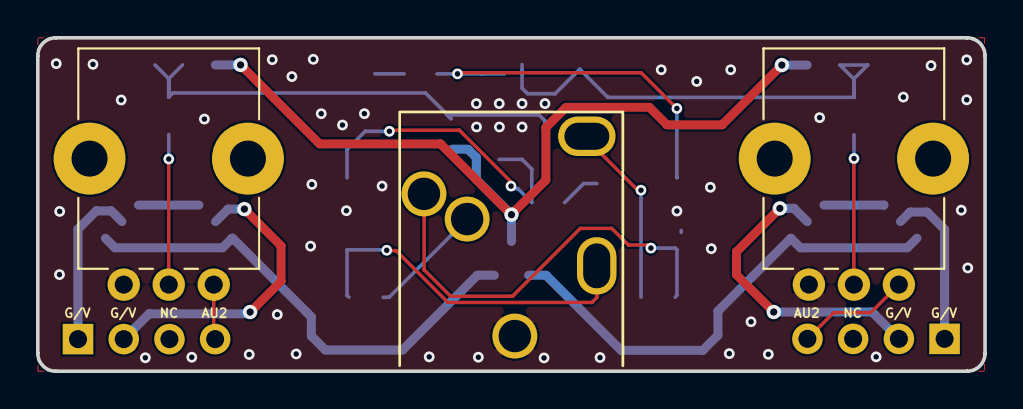
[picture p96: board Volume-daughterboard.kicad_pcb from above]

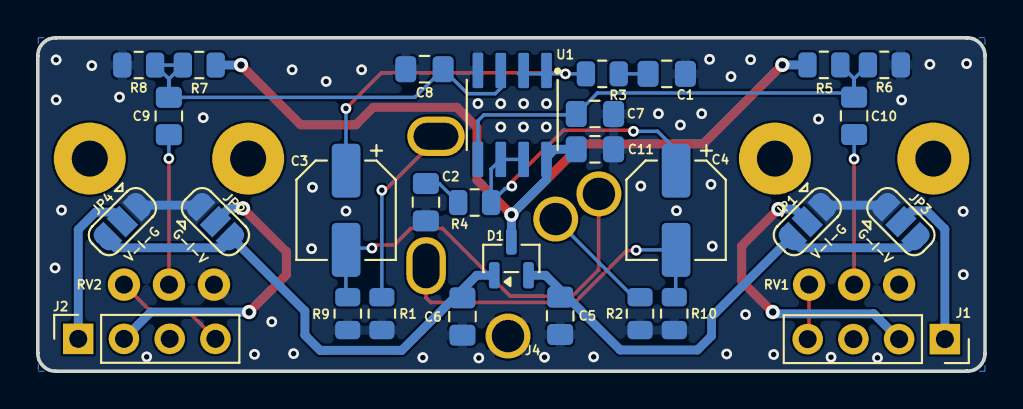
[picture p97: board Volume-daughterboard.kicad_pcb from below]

Board: 2 copper layers, 52.6 x 18.5 mm, 32 parts (29 on the bottom side), 22 nets.

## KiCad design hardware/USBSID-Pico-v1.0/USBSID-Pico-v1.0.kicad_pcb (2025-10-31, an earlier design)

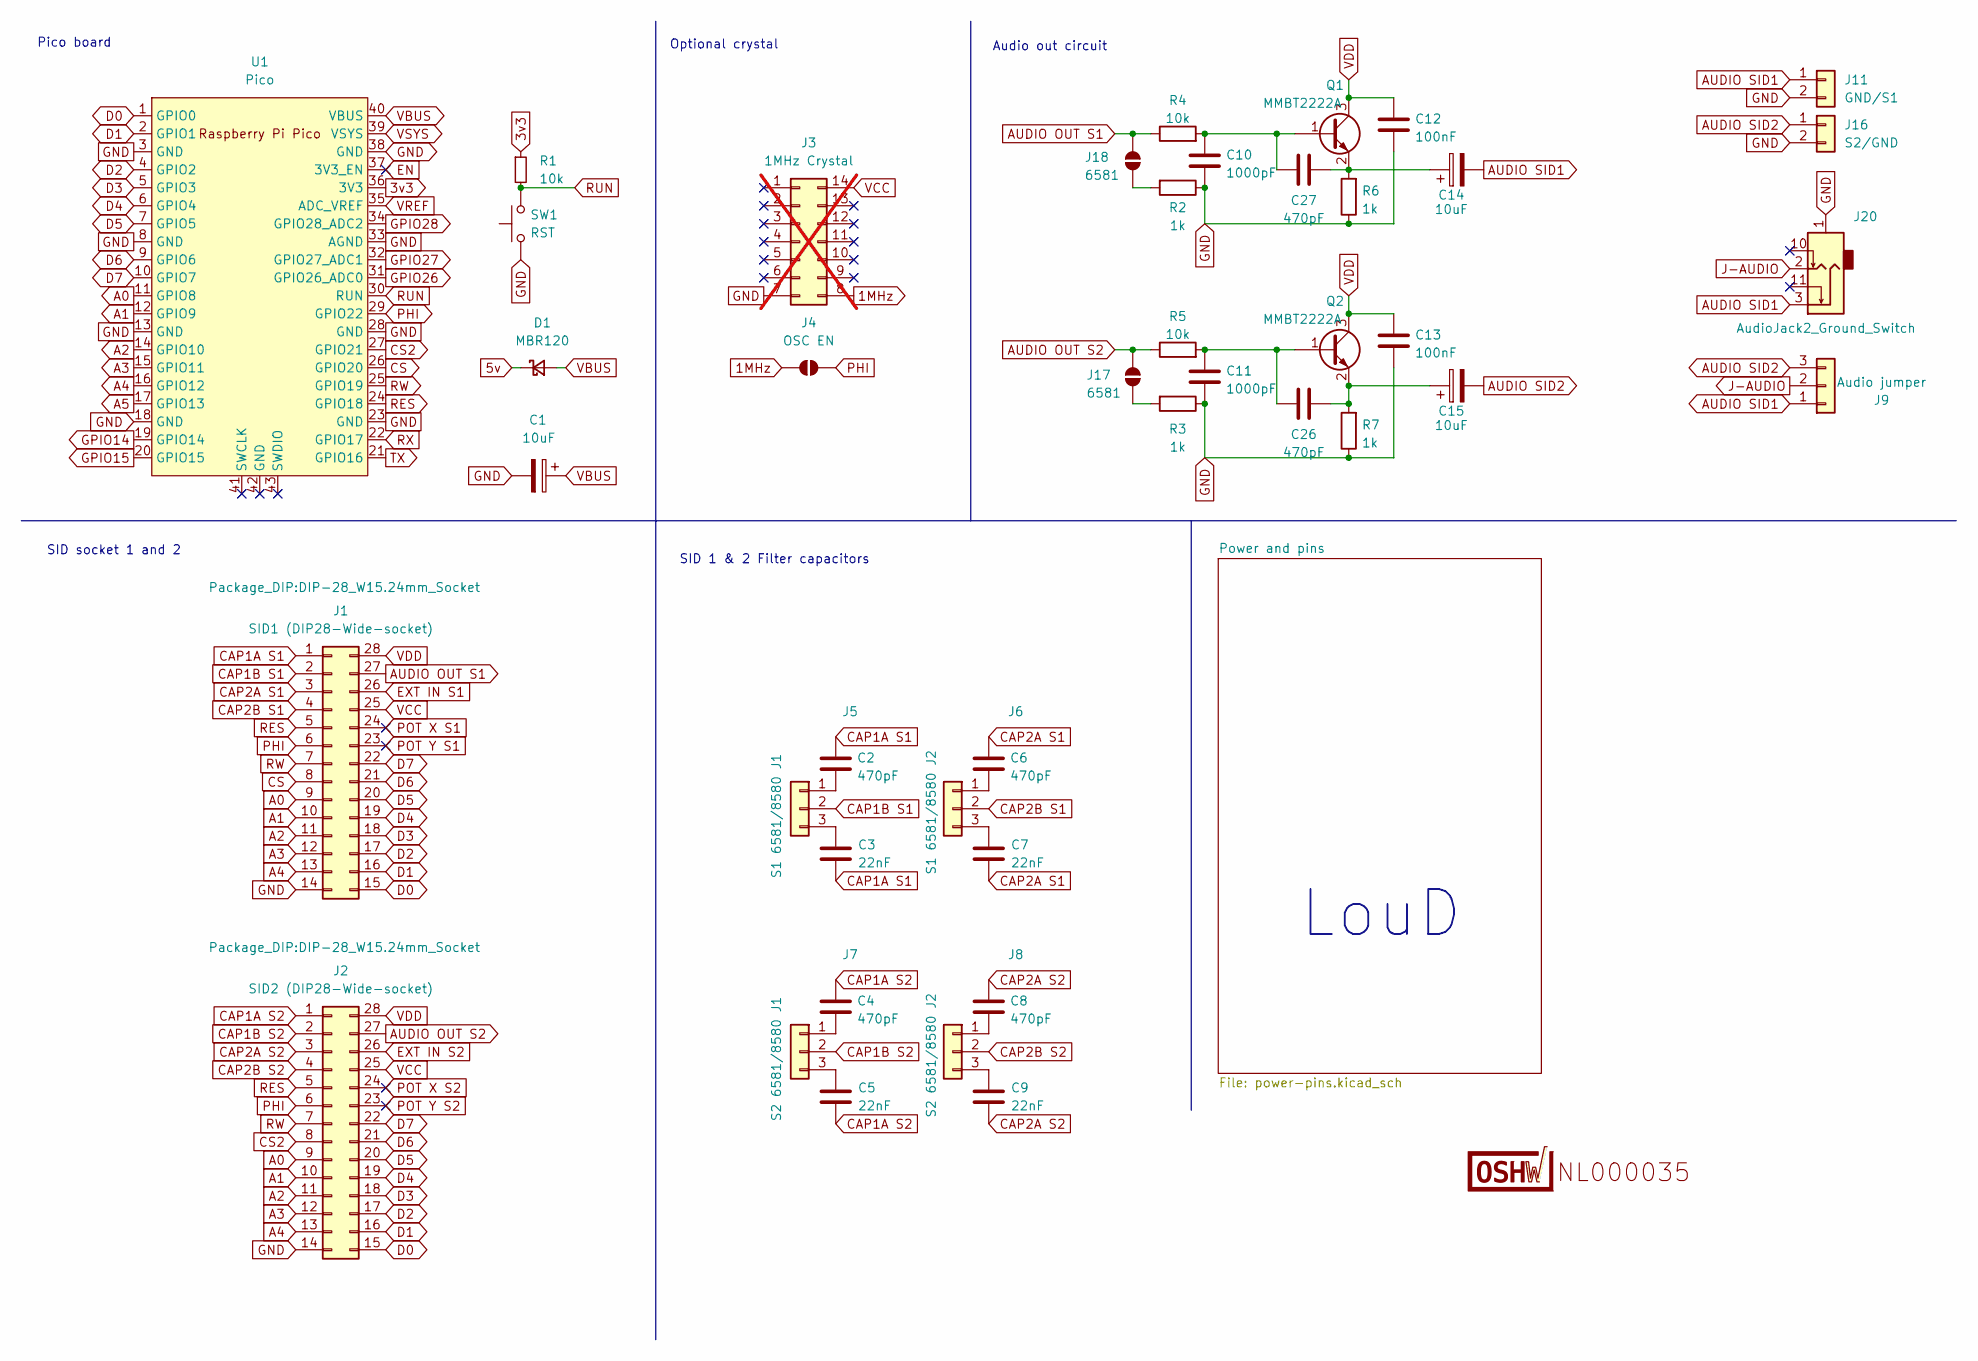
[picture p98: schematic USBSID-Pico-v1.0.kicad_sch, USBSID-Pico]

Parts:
C1: 10uF; CP_EIA-3216-10_Kemet-I_Pad1.58x1.35mm_HandSolder; Mfg Part # T491A106K016AT
C2, C4, C6, C8, C26, C27: 470pF; C_0805_2012Metric; Mfg Part # 0805B471K500NT
C3, C5, C7, C9: 22nF; C_0805_2012Metric; Mfg Part # CL21B223KBANNNC
C10, C11: 1000pF; C_0805_2012Metric; Mfg Part # CL21B102KBANNNC
C12, C13: 100nF; C_0805_2012Metric; Mfg Part # CL21B104KBCNNNC
C14, C15: 10uF; CP_Elec_4x5.3; Mfg Part # RVT1E100M0405
D1: MBR120; SOD-123FL_diode; Mfg Part # MBR120VLSFT1G
J1: SID1 (DIP28-Wide-socket); DIP-28_W15.24mm_Socket; Mfg Part # IC254V-12-28-0743-P1524
J2: SID2 (DIP28-Wide-socket); DIP-28_W15.24mm_Socket; Mfg Part # IC254V-12-28-0743-P1524
J3: 1MHz Crystal; DIP-14_W7.62mm; Mfg Part # MCO-1510A; not fitted
J4: OSC EN; SolderJumper-2_P1.3mm_Open_RoundedPad1.0x1.5mm
J5: S1 6581/8580 J1; PinHeader_1x03_P2.54mm_Vertical; Mfg Part # PH2.54-01-03PZD
J6: S1 6581/8580 J2; PinHeader_1x03_P2.54mm_Vertical; Mfg Part # PH2.54-01-03PZD
J7: S2 6581/8580 J1; PinHeader_1x03_P2.54mm_Vertical; Mfg Part # PH2.54-01-03PZD
J8: S2 6581/8580 J2; PinHeader_1x03_P2.54mm_Vertical; Mfg Part # PH2.54-01-03PZD
J9: Audio jumper; PinHeader_1x03_P2.54mm_Horizontal; Mfg Part # PH2.54-07-03PWD
J11: GND/S1; PinHeader_1x02_P2.54mm_Vertical; Mfg Part # PH2.54-01-02PZD
J16: S2/GND; PinHeader_1x02_P2.54mm_Vertical; Mfg Part # PH2.54-01-02PZD
J17, J18: 6581; SolderJumper-2_P1.3mm_Open_RoundedPad1.0x1.5mm
J20: AudioJack2_Ground_Switch; 3.5MM_SWITCHCRAFT_35RAPC4BHN2; Mfg Part # SJ1-3525N
LOGO1: (no value)
Q1, Q2: MMBT2222A; SOT-23; Mfg Part # MMBT2222ALT1G
R1, R4, R5: 10k; R_0805_2012Metric; Mfg Part # 0805W8F1002T5E
R2, R3, R6, R7: 1k; R_0805_2012Metric; Mfg Part # 0805W8F1001T5E
SW1: RST; SW_SPST_B3U-1000P_larger_pads; Mfg Part # B3U-1000P
U1: Pico; RPi_Pico_TH_PinRows_Only; Mfg Part # PM254-1-20-Z-8.5

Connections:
1MHz: J3.8, J4.2 (B)
3v3: R1.1, U1.36 (3V3)
5v: D1.1 (K); also elsewhere on the board
A0: J1.9, J2.9, U1.11 (GPIO8)
A1: J1.10, J2.10, U1.12 (GPIO9)
A2: J1.11, J2.11, U1.14 (GPIO10)
A3: J1.12, J2.12, U1.15 (GPIO11)
A4: J1.13, J2.13, U1.16 (GPIO12)
A5: U1.17 (GPIO13); also elsewhere on the board
AUDIO OUT S1: J1.27, J18.1 (A), R4.1
AUDIO OUT S2: J2.27, J17.1 (A), R5.1
AUDIO SID1: C14.2, J9.1, J11.1, J20.3
AUDIO SID2: C15.2, J9.3, J16.1
CAP1A S1: C2.2, C3.1, J1.1
CAP1A S2: C4.2, C5.1, J2.1
CAP1B S1: J1.2, J5.2
CAP1B S2: J2.2, J7.2
CAP2A S1: C6.2, C7.1, J1.3
CAP2A S2: C8.2, C9.1, J2.3
CAP2B S1: J1.4, J6.2
CAP2B S2: J2.4, J8.2
CS: J1.8, U1.26 (GPIO20)
CS2: J2.8, U1.27 (GPIO21)
D0: J1.15, J2.15, U1.1 (GPIO0)
D1: J1.16, J2.16, U1.2 (GPIO1)
D2: J1.17, J2.17, U1.4 (GPIO2)
D3: J1.18, J2.18, U1.5 (GPIO3)
D4: J1.19, J2.19, U1.6 (GPIO4)
D5: J1.20, J2.20, U1.7 (GPIO5)
D6: J1.21, J2.21, U1.9 (GPIO6)
D7: J1.22, J2.22, U1.10 (GPIO7)
EN: U1.37 (3V3_EN)
EXT IN S1: J1.26; also elsewhere on the board
EXT IN S2: J2.26; also elsewhere on the board
GND: C1.2, C10.2, C11.2, C12.2, C13.2, J1.14, J2.14, J3.7, J11.2, J16.2, J20.1, R2.1, R3.1, R6.1, R7.1, SW1.1, U1.3 (GND), U1.8 (GND), U1.13 (GND), U1.18 (GND), U1.23 (GND), U1.28 (GND), U1.33 (AGND), U1.38 (GND); also elsewhere on the board
GPIO14: U1.19 (GPIO14); also elsewhere on the board
GPIO15: U1.20 (GPIO15); also elsewhere on the board
GPIO26: U1.31 (GPIO26_ADC0); also elsewhere on the board
GPIO27: U1.32 (GPIO27_ADC1); also elsewhere on the board
GPIO28: U1.34 (GPIO28_ADC2); also elsewhere on the board
J-AUDIO: J9.2, J20.2
unnamed: C2.1, J5.1
unnamed: C3.2, J5.3
unnamed: C6.1, J6.1
unnamed: C7.2, J6.3
unnamed: C4.1, J7.1
unnamed: C5.2, J7.3
unnamed: C8.1, J8.1
unnamed: C9.2, J8.3
unnamed: J17.2 (B), R3.2
unnamed: J18.2 (B), R2.2
unnamed: C10.1, C27.2, Q1.1 (B), R4.2
unnamed: C14.1, C27.1, Q1.2 (E), R6.2
unnamed: C11.1, C26.2, Q2.1 (B), R5.2
unnamed: C15.1, C26.1, Q2.2 (E), R7.2
PHI: J1.6, J2.6, J4.1 (A), U1.29 (GPIO22)
POT X S1: J1.24
POT X S2: J2.24
POT Y S1: J1.23
POT Y S2: J2.23
RES: J1.5, J2.5, U1.24 (GPIO18)
RUN: R1.2, SW1.2, U1.30 (RUN)
RW: J1.7, J2.7, U1.25 (GPIO19)
RX: U1.22 (GPIO17); also elsewhere on the board
TX: U1.21 (GPIO16); also elsewhere on the board
VBUS: C1.1, D1.2 (A), U1.40 (VBUS)
VCC: J1.25, J2.25, J3.14; also elsewhere on the board
VDD: C12.1, C13.1, J1.28, J2.28, Q1.3 (C), Q2.3 (C); also elsewhere on the board
VREF: U1.35 (ADC_VREF)
VSYS: U1.39 (VSYS)

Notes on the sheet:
SID socket 1 and 2
SID 1 & 2 Filter capacitors
Pico board
Audio out circuit
LouD
Optional crystal

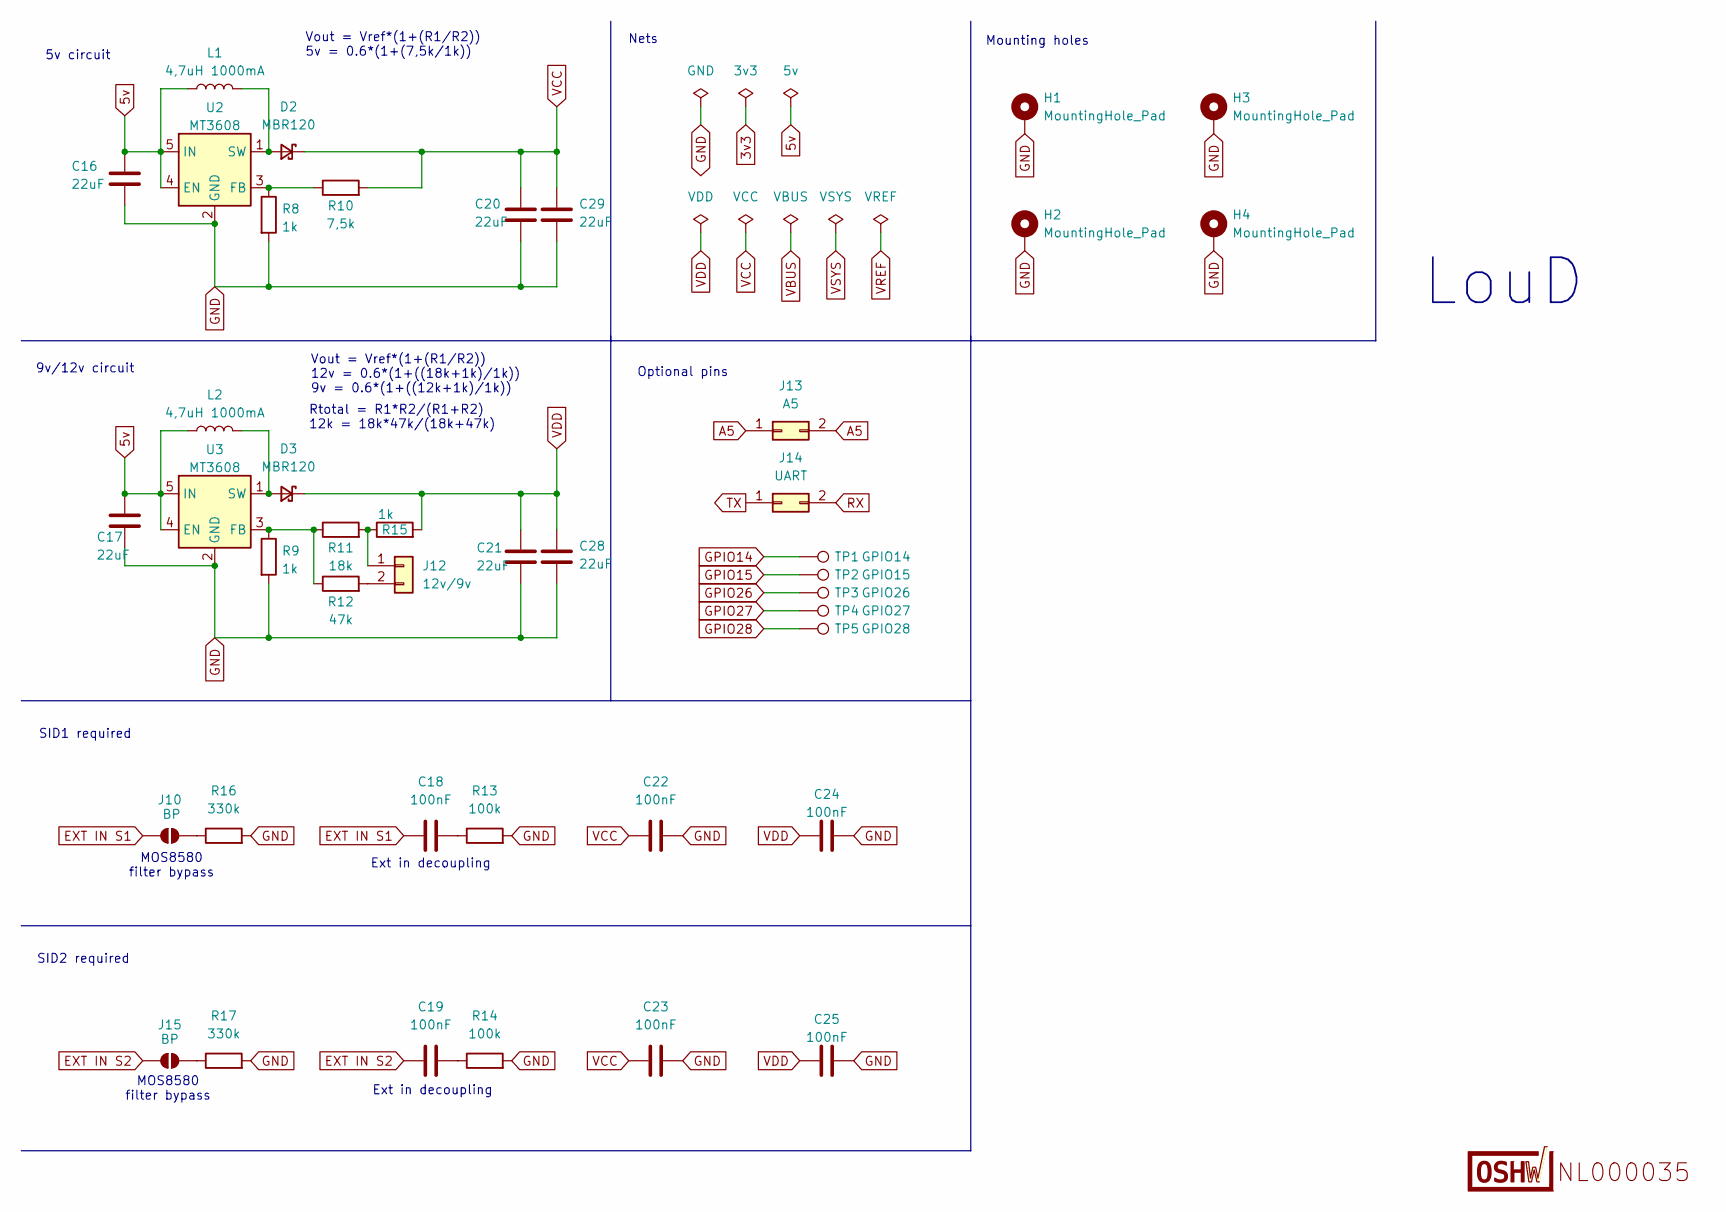
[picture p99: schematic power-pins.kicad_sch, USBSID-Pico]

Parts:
C16, C17, C20, C21, C28, C29: 22uF; C_0805_2012Metric; Mfg Part # CL21A226MAQNNNE
C18, C19, C22, C23, C24, C25: 100nF; C_0805_2012Metric; Mfg Part # CL21B104KBCNNNC
D2, D3: MBR120; SOD-123FL_diode; Mfg Part # MBR120VLSFT1G
H1, H2, H3, H4: MountingHole_Pad; MountingHole_3.2mm_M3_Pad_Via
J10, J15: BP; SolderJumper-2_P1.3mm_Open_RoundedPad1.0x1.5mm
J12: 12v/9v; PinHeader_1x02_P2.54mm_Vertical; Mfg Part # PH2.54-01-02PZD
J13: A5; PinHeader_2x01_P2.54mm_Vertical; Mfg Part # PH2.54-01-02PZD
J14: UART; PinHeader_1x02_P2.54mm_Vertical; Mfg Part # PH2.54-01-02PZD
L1, L2: 4,7uH 1000mA; L_1008_2520Metric_Pad1.43x2.20mm_HandSolder; Mfg Part # SPH252012H4R7MT
LOGO2: (no value)
R8, R9, R15: 1k; R_0805_2012Metric; Mfg Part # 0805W8F1001T5E
R10: 7,5k; R_0805_2012Metric; Mfg Part # 0805W8F7501T5E
R11: 18k; R_0805_2012Metric; Mfg Part # 0805W8F1802T5E
R12: 47k; R_0805_2012Metric; Mfg Part # 0805W8F4702T5E
R13, R14: 100k; R_0805_2012Metric; Mfg Part # 0805W8F1003T5E
R16, R17: 330k; R_0805_2012Metric; Mfg Part # 0805W8F3303T5E
TP1: GPIO14; TestPoint_Pad_D1.0mm
TP2: GPIO15; TestPoint_Pad_D1.0mm
TP3: GPIO26; TestPoint_Pad_D1.0mm
TP4: GPIO27; TestPoint_Pad_D1.0mm
TP5: GPIO28; TestPoint_Pad_D1.0mm
U2, U3: MT3608; SOT-23-6; Mfg Part # MT3608

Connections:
5v: C16.1, C17.1, L1.1, L2.1, U2.4 (EN), U2.5 (IN), U3.4 (EN), U3.5 (IN); also elsewhere on the board
A5: J13.1, J13.2; also elsewhere on the board
EXT IN S1: C18.1, J10.2 (B); also elsewhere on the board
EXT IN S2: C19.1, J15.2 (B); also elsewhere on the board
GND: C16.2, C17.2, C20.2, C21.2, C22.2, C23.2, C24.1, C25.1, C28.2, C29.2, H1.1, H2.1, H3.1, H4.1, R8.2, R9.2, R13.2, R14.2, R16.2, R17.2, U2.2 (GND), U3.2 (GND); also elsewhere on the board
GPIO14: TP1.1; also elsewhere on the board
GPIO15: TP2.1; also elsewhere on the board
GPIO26: TP3.1; also elsewhere on the board
GPIO27: TP4.1; also elsewhere on the board
GPIO28: TP5.1; also elsewhere on the board
unnamed: C18.2, R13.1
unnamed: C19.2, R14.1
unnamed: D2.2 (A), L1.2, U2.1 (SW)
unnamed: D3.2 (A), L2.2, U3.1 (SW)
unnamed: J10.1 (A), R16.1
unnamed: J12.1, R11.2, R15.1
unnamed: J12.2, R12.2
unnamed: J15.1 (A), R17.1
unnamed: R8.1, R10.1, U2.3 (FB)
unnamed: R9.1, R11.1, R12.1, U3.3 (FB)
RX: J14.2; also elsewhere on the board
TX: J14.1; also elsewhere on the board
VCC: C20.1, C22.1, C23.1, C29.1, D2.1 (K), R10.2; also elsewhere on the board
VDD: C21.1, C24.2, C25.2, C28.1, D3.1 (K), R15.2; also elsewhere on the board

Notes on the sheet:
5v circuit
MOS8580 filter bypass
Optional pins
Nets
Rtotal = R1*R2/(R1+R2) 12k = 18k*47k/(18k+47k)
Mounting holes
9v/12v circuit
LouD
Ext in decoupling
Vout = Vref*(1+(R1/R2)) 5v = 0.6*(1+(7,5k/1k))
Vout = Vref*(1+(R1/R2)) 12v = 0.6*(1+((18k+1k)/1k)) 9v = 0.6*(1+((12k+1k)/1k))
SID2 required
SID1 required

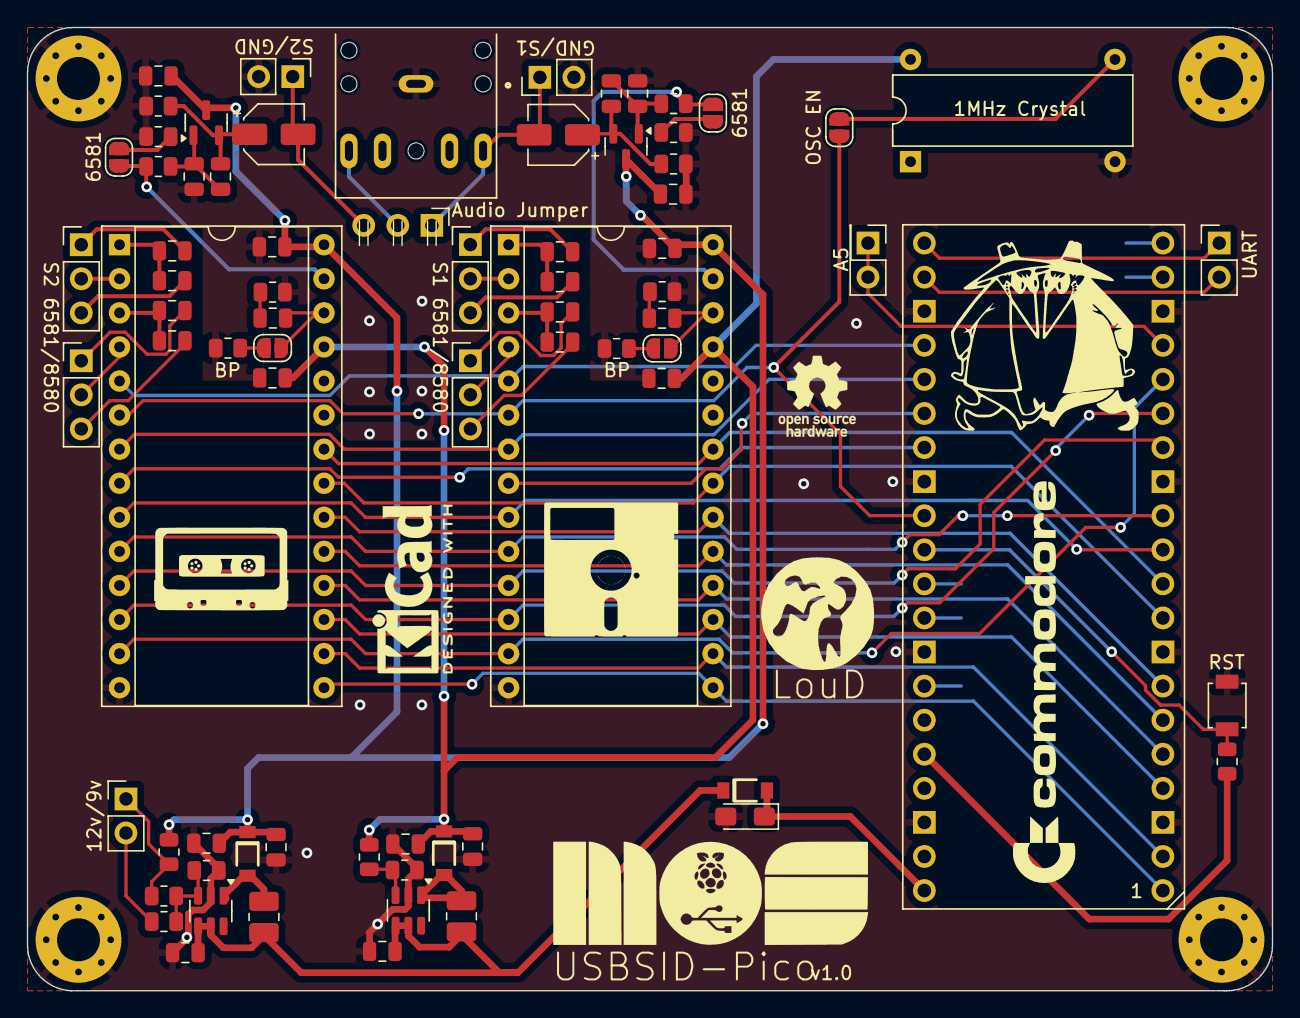
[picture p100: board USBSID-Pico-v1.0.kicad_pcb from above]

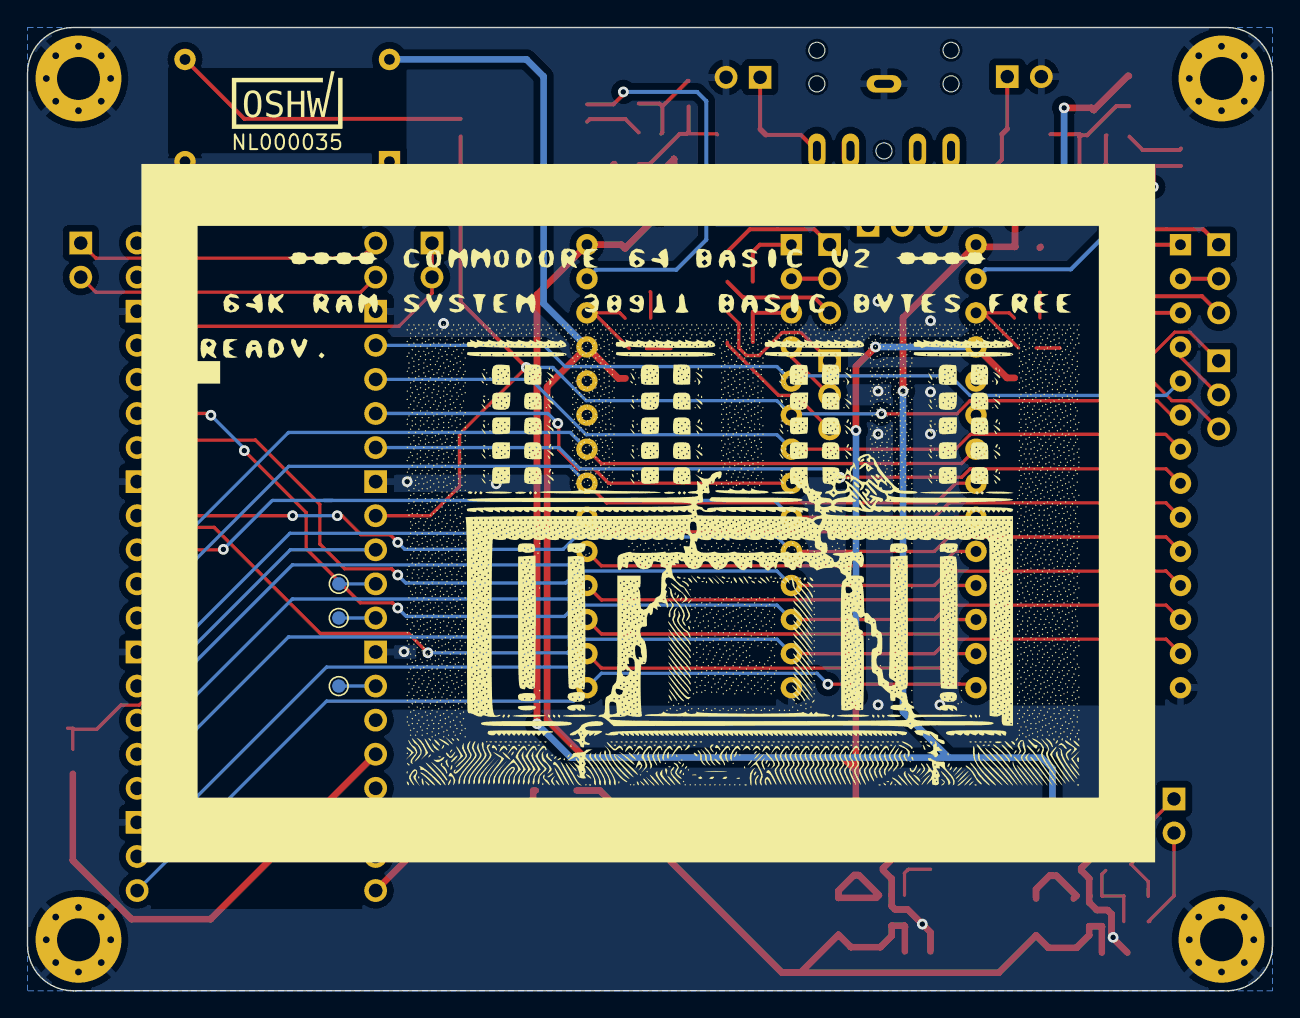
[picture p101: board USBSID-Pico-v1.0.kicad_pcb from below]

Board: 2 copper layers, 92.8 x 71.8 mm, 85 parts (5 on the bottom side), 73 nets.

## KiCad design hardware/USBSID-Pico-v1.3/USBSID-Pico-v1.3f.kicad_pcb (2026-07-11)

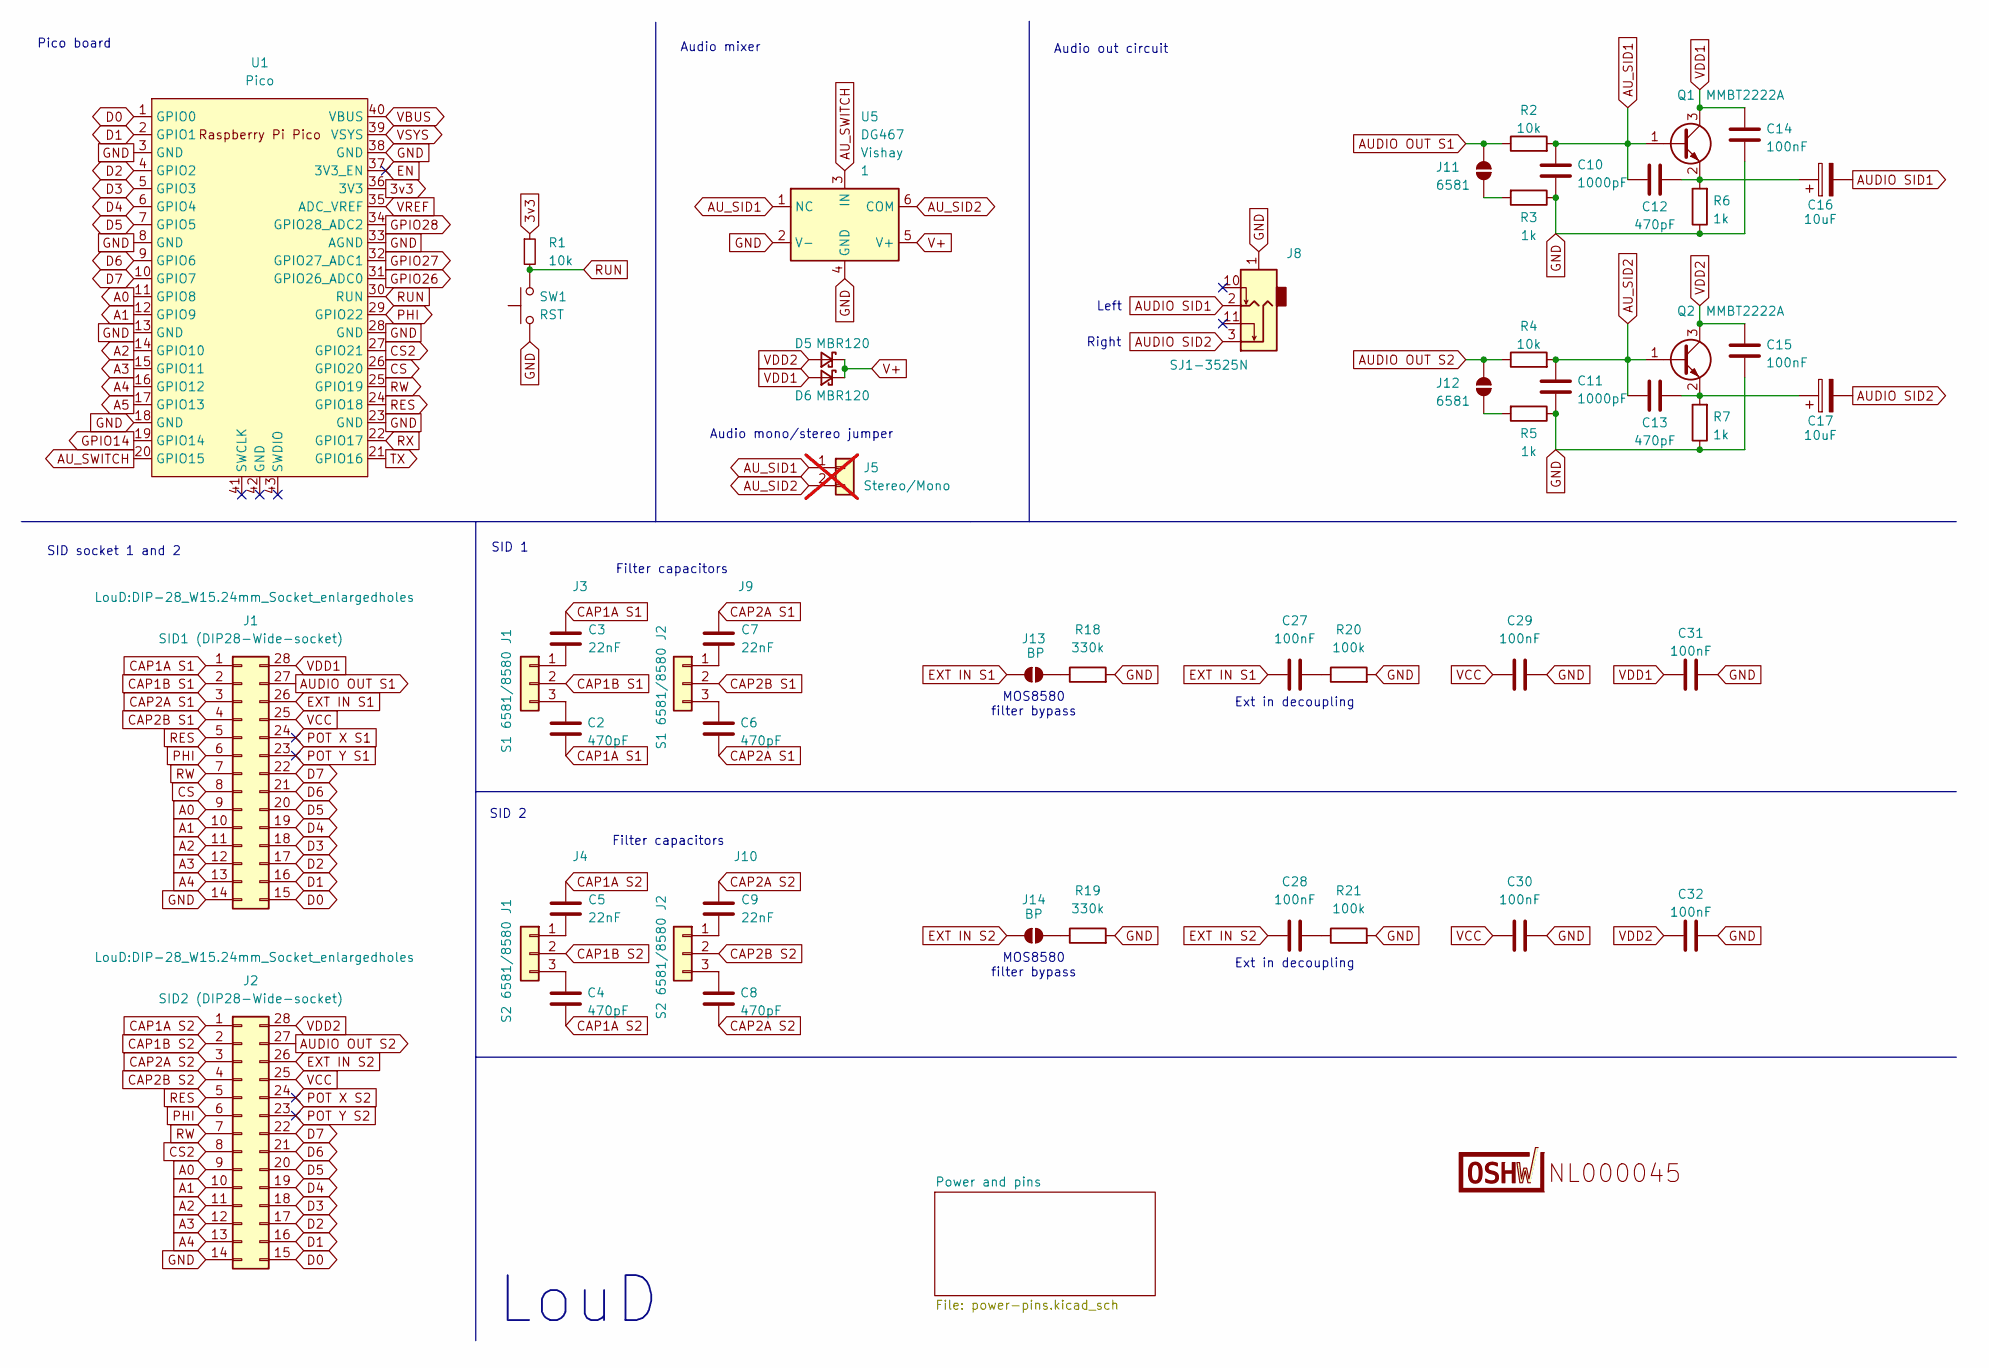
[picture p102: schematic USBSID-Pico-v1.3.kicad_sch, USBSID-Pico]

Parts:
C2, C4, C6, C8, C12, C13: 470pF; C_0805_2012Metric; Mfg Part # 0805B471K500NT
C3, C5, C7, C9: 22nF; C_0805_2012Metric; Mfg Part # CL21B223KBANNNC
C10, C11: 1000pF; C_0805_2012Metric; Mfg Part # CL21B102KBANNNC
C14, C15, C27, C28, C29, C30, C31, C32: 100nF; C_0805_2012Metric; Mfg Part # CL21B104KBCNNNC
C16, C17: 10uF; CP_Elec_4x5.3; Mfg Part # RVT1E100M0405
D5, D6: MBR120; SOD-123FL_diode; Mfg Part # MBR120VLSFT1G
J1: SID1 (DIP28-Wide-socket); DIP-28_W15.24mm_Socket_enlargedholes; Mfg Part # DS1009-28AT1WX-0A2
J2: SID2 (DIP28-Wide-socket); DIP-28_W15.24mm_Socket_enlargedholes; Mfg Part # DS1009-28AT1WX-0A2
J3: S1 6581/8580 J1; PinHeader_1x03_P2.54mm_Horizontal; Mfg Part # HX PZ2.54-1x3P WZ
J4: S2 6581/8580 J1; PinHeader_1x03_P2.54mm_Horizontal; Mfg Part # HX PZ2.54-1x3P WZ
J5: Stereo/Mono; PinHeader_1x02_P2.54mm_Horizontal; Mfg Part # PH2.54-01-02PZD; not fitted
J8: SJ1-3525N; 3.5MM_SWITCHCRAFT_35RAPC4BHN2; Mfg Part # SJ1-3525N
J9: S1 6581/8580 J2; PinHeader_1x03_P2.54mm_Horizontal; Mfg Part # HX PZ2.54-1x3P WZ
J10: S2 6581/8580 J2; PinHeader_1x03_P2.54mm_Horizontal; Mfg Part # HX PZ2.54-1x3P WZ
J11, J12: 6581; SolderJumper-2_P1.3mm_Open_RoundedPad1.0x1.5mm
J13, J14: BP; SolderJumper-2_P1.3mm_Open_RoundedPad1.0x1.5mm
LOGO1: (no value)
Q1, Q2: MMBT2222A; SOT-23; Mfg Part # MMBT2222ALT1G
R1, R2, R4: 10k; R_0805_2012Metric; Mfg Part # 0805W8F1002T5E
R3, R5, R6, R7: 1k; R_0805_2012Metric; Mfg Part # 0805W8F1001T5E
R18, R19: 330k; R_0805_2012Metric; Mfg Part # 0805W8F3303T5E
R20, R21: 100k; R_0805_2012Metric; Mfg Part # 0805W8F1003T5E
SW1: RST; SW_SPST_B3U-1000P_larger_pads; Mfg Part # B3U-1000P
U1: Pico; RPi_Pico_SMD_TH_noholes; Mfg Part # PM254-1-20-Z-8.5
U5: DG467; SOT-23-6; Mfg Part Desc Low Power, High Voltage SPST Analog Swi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

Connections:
3v3: R1.1, U1.36 (3V3)
A0: J1.9, J2.9, U1.11 (GPIO8)
A1: J1.10, J2.10, U1.12 (GPIO9)
A2: J1.11, J2.11, U1.14 (GPIO10)
A3: J1.12, J2.12, U1.15 (GPIO11)
A4: J1.13, J2.13, U1.16 (GPIO12)
A5: U1.17 (GPIO13); also elsewhere on the board
AUDIO OUT S1: J1.27, J11.1 (A), R2.1
AUDIO OUT S2: J2.27, J12.1 (A), R4.1
AUDIO SID1: C16.2, J8.2; also elsewhere on the board
AUDIO SID2: C17.2, J8.3; also elsewhere on the board
AU_SID1: C10.1, C12.2, J5.1, Q1.1 (B), R2.2, U5.1 (NC)
AU_SID2: C11.1, C13.2, J5.2, Q2.1 (B), R4.2, U5.6 (COM)
AU_SWITCH: U1.20 (GPIO15), U5.3 (IN); also elsewhere on the board
CAP1A S1: C2.1, C3.2, J1.1
CAP1A S2: C4.1, C5.2, J2.1
CAP1B S1: J1.2, J3.2
CAP1B S2: J2.2, J4.2
CAP2A S1: C6.1, C7.2, J1.3
CAP2A S2: C8.1, C9.2, J2.3
CAP2B S1: J1.4, J9.2
CAP2B S2: J2.4, J10.2
CS: J1.8, U1.26 (GPIO20)
CS2: J2.8, U1.27 (GPIO21)
D0: J1.15, J2.15, U1.1 (GPIO0)
D1: J1.16, J2.16, U1.2 (GPIO1)
D2: J1.17, J2.17, U1.4 (GPIO2)
D3: J1.18, J2.18, U1.5 (GPIO3)
D4: J1.19, J2.19, U1.6 (GPIO4)
D5: J1.20, J2.20, U1.7 (GPIO5)
D6: J1.21, J2.21, U1.9 (GPIO6)
D7: J1.22, J2.22, U1.10 (GPIO7)
EN: U1.37 (3V3_EN)
EN_1: U1.37 (3V3_EN)
EXT IN S1: C27.1, J1.26, J13.2 (B); also elsewhere on the board
EXT IN S2: C28.1, J2.26, J14.2 (B); also elsewhere on the board
GND: C10.2, C11.2, C14.2, C15.2, C29.2, C30.2, C31.1, C32.1, J1.14, J2.14, J8.1, R3.1, R5.1, R6.1, R7.1, R18.2, R19.2, R20.2, R21.2, SW1.1, U1.3 (GND), U1.8 (GND), U1.13 (GND), U1.18 (GND), U1.23 (GND), U1.28 (GND), U1.33 (AGND), U1.38 (GND), U5.2 (V-), U5.4 (GND); also elsewhere on the board
GPIO14: U1.19 (GPIO14); also elsewhere on the board
GPIO26: U1.31 (GPIO26_ADC0); also elsewhere on the board
GPIO27: U1.32 (GPIO27_ADC1); also elsewhere on the board
GPIO28: U1.34 (GPIO28_ADC2); also elsewhere on the board
unnamed: C27.2, R20.1
unnamed: C28.2, R21.1
unnamed: C3.1, J3.1
unnamed: C2.2, J3.3
unnamed: C5.1, J4.1
unnamed: C4.2, J4.3
unnamed: C7.1, J9.1
unnamed: C6.2, J9.3
unnamed: C9.1, J10.1
unnamed: C8.2, J10.3
unnamed: J11.2 (B), R3.2
unnamed: J12.2 (B), R5.2
unnamed: J13.1 (A), R18.1
unnamed: J14.1 (A), R19.1
unnamed: C12.1, C16.1, Q1.2 (E), R6.2
unnamed: C13.1, C17.1, Q2.2 (E), R7.2
PHI: J1.6, J2.6, U1.29 (GPIO22)
POT X S1: J1.24
POT X S2: J2.24
POT Y S1: J1.23
POT Y S2: J2.23
RES: J1.5, J2.5, U1.24 (GPIO18)
RUN: R1.2, SW1.2, U1.30 (RUN)
RW: J1.7, J2.7, U1.25 (GPIO19)
RX: U1.22 (GPIO17); also elsewhere on the board
TX: U1.21 (GPIO16); also elsewhere on the board
V+: D5.1 (K), D6.1 (K), U5.5 (V+)
VBUS: U1.40 (VBUS); also elsewhere on the board
VCC: C29.1, C30.1, J1.25, J2.25; also elsewhere on the board
VDD1: C14.1, C31.2, D6.2 (A), J1.28, Q1.3 (C); also elsewhere on the board
VDD2: C15.1, C32.2, D5.2 (A), J2.28, Q2.3 (C); also elsewhere on the board
VREF: U1.35 (ADC_VREF)
VSYS: U1.39 (VSYS)

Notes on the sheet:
Left
SID socket 1 and 2
SID 1
Filter capacitors
Pico board
Right
Audio mixer
LouD
Ext in decoupling
SID 2
Audio out circuit
Audio mono/stereo jumper
MOS8580 filter bypass

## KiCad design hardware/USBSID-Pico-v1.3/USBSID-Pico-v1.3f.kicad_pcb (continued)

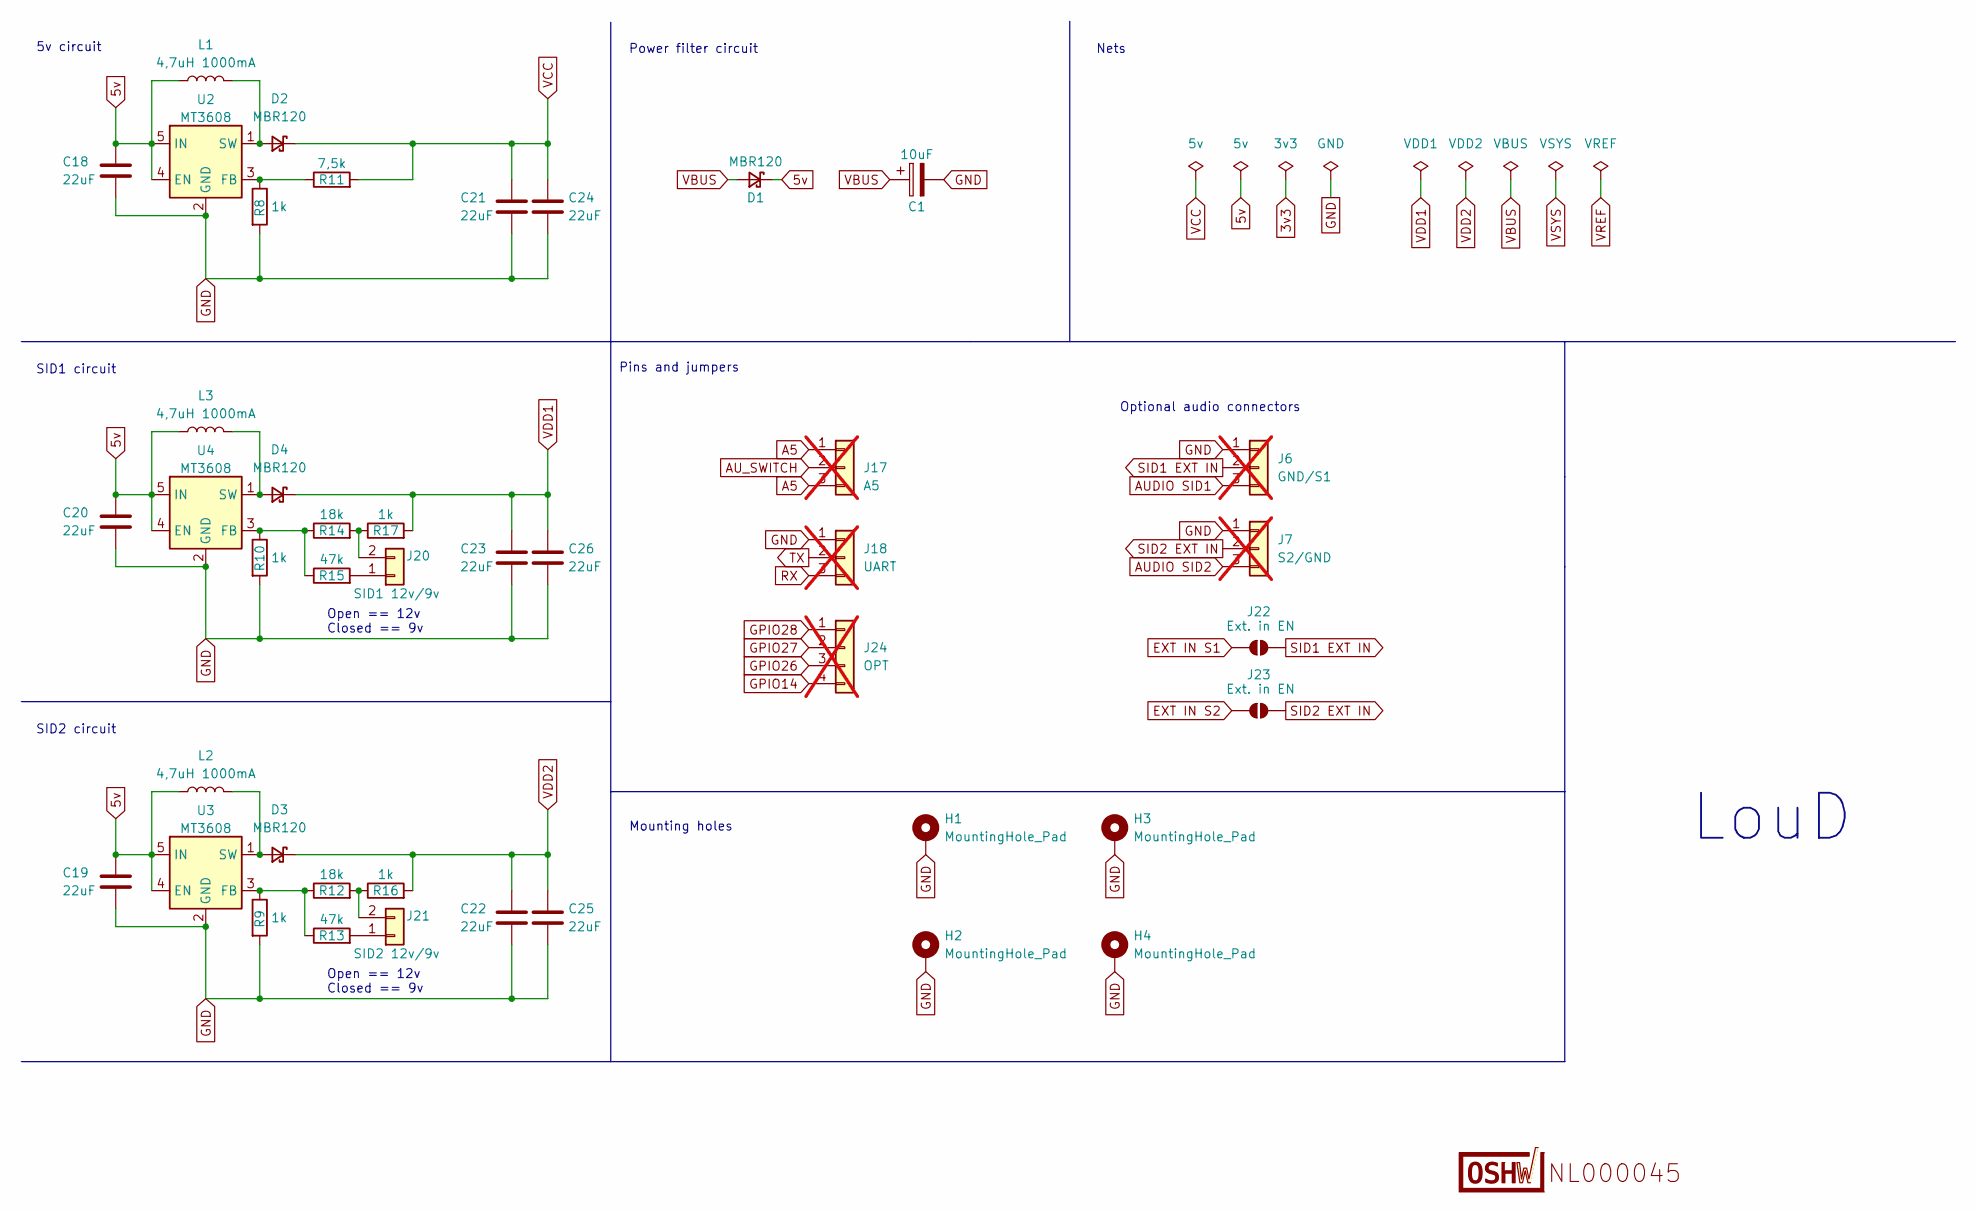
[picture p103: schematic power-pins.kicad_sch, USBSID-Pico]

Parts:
C1: 10uF; CP_EIA-3216-10_Kemet-I_Pad1.58x1.35mm_HandSolder; Mfg Part # T491A106K016AT
C18, C19, C20, C21, C22, C23, C24, C25, C26: 22uF; C_0805_2012Metric; Mfg Part # CL21A226MAQNNNE
D1, D2, D3, D4: MBR120; SOD-123FL_diode; Mfg Part # MBR120VLSFT1G
H1, H2, H3, H4: MountingHole_Pad; MountingHole_3.2mm_M3_Pad_Via
J6: GND/S1; PinHeader_1x03_P2.54mm_Vertical; Mfg Part # PH2.54-01-03PZD; not fitted
J7: S2/GND; PinHeader_1x03_P2.54mm_Vertical; Mfg Part # PH2.54-01-03PZD; not fitted
J17: A5; PinHeader_1x03_P2.54mm_Horizontal; Mfg Part # HX PZ2.54-1x3P WZ; not fitted
J18: UART; PinHeader_1x03_P2.54mm_Vertical; Mfg Part # PH2.54-01-03PZD; not fitted
J20: SID1 12v/9v; PinHeader_1x02_P2.54mm_Vertical; Mfg Part # PH2.54-01-02PZD
J21: SID2 12v/9v; PinHeader_1x02_P2.54mm_Vertical; Mfg Part # PH2.54-01-02PZD
J22, J23: Ext. in EN; SolderJumper-2_P1.3mm_Open_RoundedPad1.0x1.5mm
J24: OPT; PinHeader_1x04_P2.54mm_Vertical; Mfg Part # PH2.54-01-02PZD; not fitted
L1, L2, L3: 4,7uH 1000mA; L_1008_2520Metric_Pad1.43x2.20mm_HandSolder; Mfg Part # SPH252012H4R7MT
LOGO2: (no value)
R8, R9, R10, R16, R17: 1k; R_0805_2012Metric; Mfg Part # 0805W8F1001T5E
R11: 7,5k; R_0805_2012Metric; Mfg Part # 0805W8F7501T5E
R12, R14: 18k; R_0805_2012Metric; Mfg Part # 0805W8F1802T5E
R13, R15: 47k; R_0805_2012Metric; Mfg Part # 0805W8F4702T5E
U2, U3, U4: MT3608; SOT-23-6; Mfg Part # MT3608

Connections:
5v: C18.1, C19.1, C20.1, D1.1 (K), L1.1, L2.1, L3.1, U2.4 (EN), U2.5 (IN), U3.4 (EN), U3.5 (IN), U4.4 (EN), U4.5 (IN)
A5: J17.1, J17.3; also elsewhere on the board
AUDIO SID1: J6.3; also elsewhere on the board
AUDIO SID2: J7.3; also elsewhere on the board
AU_SWITCH: J17.2; also elsewhere on the board
EXT IN S1: J22.2 (B); also elsewhere on the board
EXT IN S2: J23.2 (B); also elsewhere on the board
GND: C1.2, C18.2, C19.2, C20.2, C21.2, C22.2, C23.2, C24.2, C25.2, C26.2, H1.1, H2.1, H3.1, H4.1, J6.1, J7.1, J18.1, R8.2, R9.2, R10.2, U2.2 (GND), U3.2 (GND), U4.2 (GND); also elsewhere on the board
GPIO14: J24.4; also elsewhere on the board
GPIO26: J24.3; also elsewhere on the board
GPIO27: J24.2; also elsewhere on the board
GPIO28: J24.1; also elsewhere on the board
unnamed: D2.2 (A), L1.2, U2.1 (SW)
unnamed: D3.2 (A), L2.2, U3.1 (SW)
unnamed: D4.2 (A), L3.2, U4.1 (SW)
unnamed: J20.1, R15.2
unnamed: J20.2, R14.2, R17.1
unnamed: J21.1, R13.2
unnamed: J21.2, R12.2, R16.1
unnamed: R8.1, R11.1, U2.3 (FB)
unnamed: R9.1, R12.1, R13.1, U3.3 (FB)
unnamed: R10.1, R14.1, R15.1, U4.3 (FB)
RX: J18.3; also elsewhere on the board
SID1 EXT IN: J6.2, J22.1 (A)
SID2 EXT IN: J7.2, J23.1 (A)
TX: J18.2; also elsewhere on the board
VBUS: C1.1, D1.2 (A); also elsewhere on the board
VCC: C21.1, C24.1, D2.1 (K), R11.2; also elsewhere on the board
VDD1: C23.1, C26.1, D4.1 (K), R17.2; also elsewhere on the board
VDD2: C22.1, C25.1, D3.1 (K), R16.2; also elsewhere on the board

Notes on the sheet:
5v circuit
LouD
Pins and jumpers
Power filter circuit
Nets
Open == 12v Closed == 9v
Mounting holes
SID2 circuit
SID1 circuit
Optional audio connectors

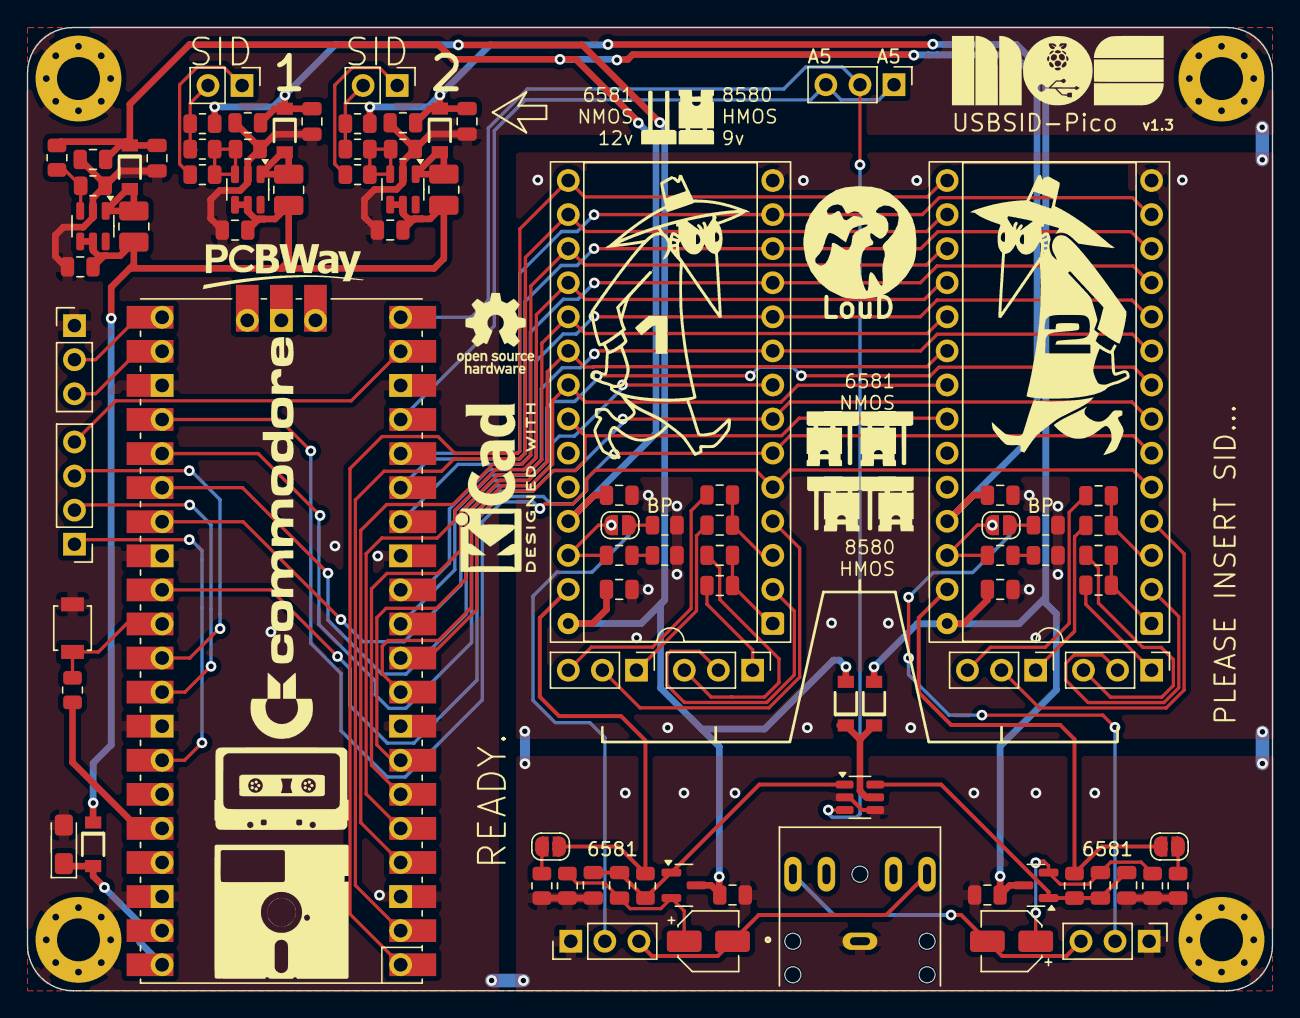
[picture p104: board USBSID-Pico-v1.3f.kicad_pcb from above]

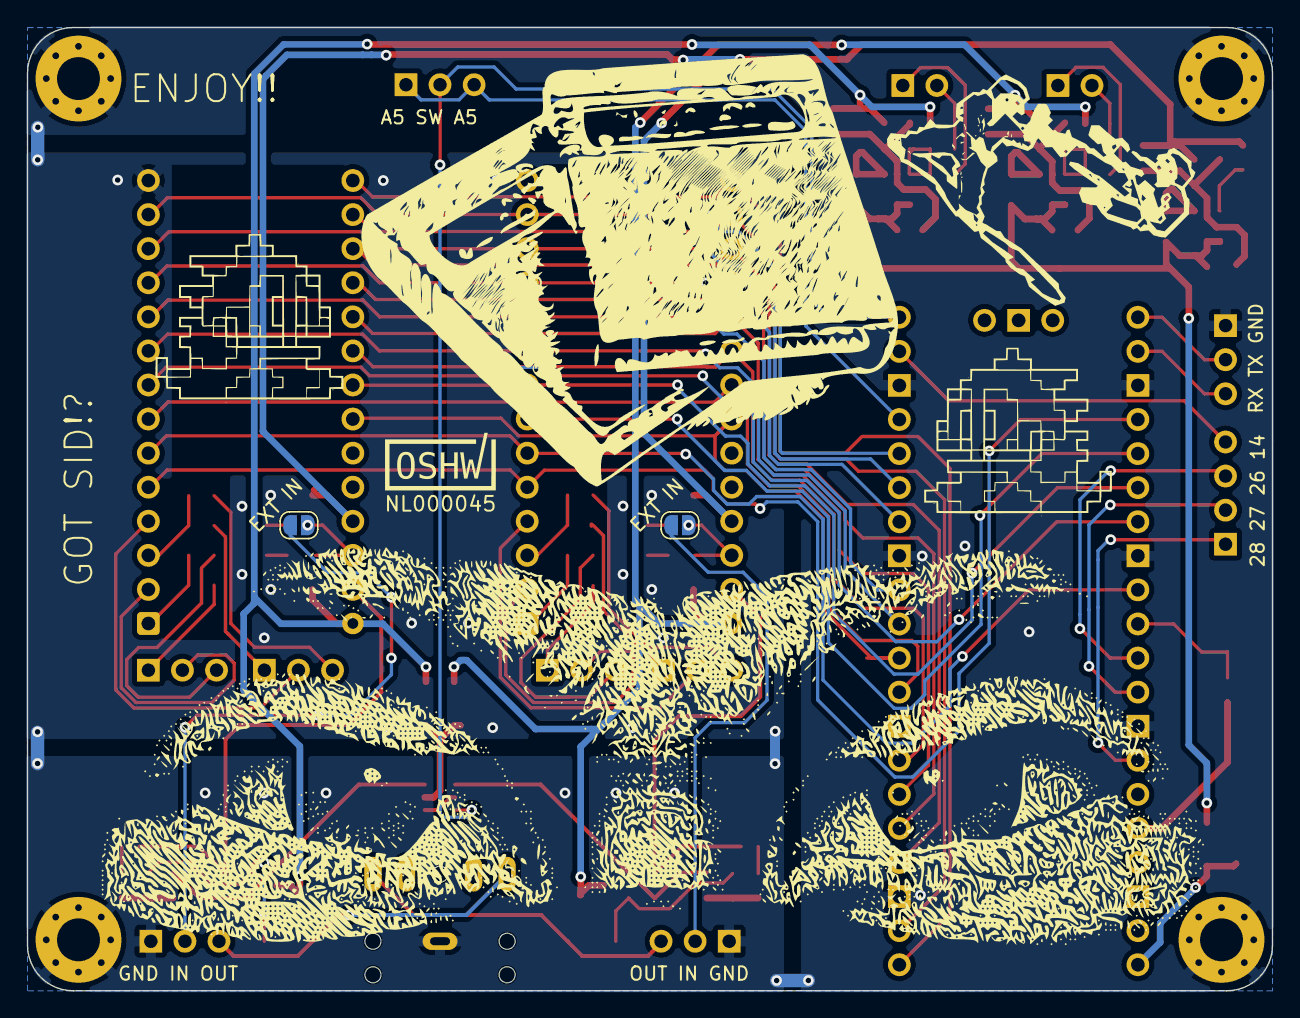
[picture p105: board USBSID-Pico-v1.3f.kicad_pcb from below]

Board: 2 copper layers, 92.8 x 71.8 mm, 95 parts (3 on the bottom side), 79 nets.

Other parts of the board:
NL000045: OSHW_US1.0_-Certification-Mark-Stacked_8x7mm_Silk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; OSHW_US1.0_-Certification-Mark-Stacked_8x7mm_SilkScreen

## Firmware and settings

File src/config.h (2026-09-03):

/*
 * USBSID-Pico is a RPi Pico/PicoW (RP2040) & Pico2/Pico2W (RP2350) based board
 * for interfacing one or two MOS SID chips and/or hardware SID emulators over
 * (WEB)USB with your computer, phone or ASID supporting player
 *
 * config.h
 * This file is part of USBSID-Pico (https://github.com/LouDnl/USBSID-Pico)
 * File author: LouD
 *
 * Copyright (c) 2024-2026 LouD
 *
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
 */

#ifndef _USBSID_CONFIG_H_
#define _USBSID_CONFIG_H_
#pragma once

#ifdef __cplusplus
  extern "C" {
#endif

/* Project includes required for this header */
#include <usbsid_constants.h>


#ifdef PICO_DEFAULT_LED_PIN
#define LED_PWM true
#else
#define LED_PWM false
#endif
#ifdef USE_RGB
#define RGB_ENABLED true
#else
#define RGB_ENABLED false
#endif

/* Flash information
 *
 * USBSID-Pico flash layout:
 * - 1024KB FW (rp2040)
 * - 3072KB FW (rp2350)
 * - 1024KB Persistent storage
 *
 * On rp2350 the flash is cleared completely every time a new uf2 is loaded,
 * this results in a default config on each fw flash.
 * This can be solved by reserving a larger part of the flash for persistent
 * storage e.g. 1024KB instead of only 4 KB
 *
 * Non working solutions
 * - adding a partitiontable had no effect
 * - adding a 4KB persistent part to the flash had no effect
 *
 * Ram and flash defaults on official pico boards:
 * XIP_BASE ~ Flash base address 0x10000000
 *
 * rp2040 PICO_FLASH_SIZE_BYTES ~ (1 * 1024 * 1024) = 0x200000 == 2MB(2097152)
 * rp2350 PICO_FLASH_SIZE_BYTES ~ (2 * 1024 * 1024) = 0x400000 == 4MB(4194304)
 * rp2040 RAM_SIZE ~ 0x40000 == 256KB(262144)
 * rp2350 RAM_SIZE ~ 0x80000 == 512KB(524288)
 *
 * FLASH_PAGE_SIZE   ~ (1u << 8)  = 0x100   == 256B
 * FLASH_SECTOR_SIZE ~ (1u << 12) = 0x1000  == 4096B
 * FLASH_BLOCK_SIZE  ~ (1u << 16) = 0x10000 == 65536B
 */

/* Init config vars
 * Based on: https://community.element14.com/products/raspberry-pi/b/blog/posts/raspberry-pico-c-sdk-reserve-a-flash-memory-block-for-persistent-storage
 */

 /* .section_persistent from the linker script, 4 bytes aligned */
extern uint32_t ADDR_PERSISTENT[];
/* Base address */
#define ADDR_PERSISTENT_BASE_ADDR (ADDR_PERSISTENT)
/* rp2040: 0x0x1FF000, rp2350: 0x3FF000 */
#define FLASH_PERSISTENT_OFFSET ((uint32_t)ADDR_PERSISTENT_BASE_ADDR - XIP_BASE)
/* Storage size in flash memory */
#define FLASH_PERSISTENT_SIZE (PICO_FLASH_SIZE_BYTES - FLASH_PERSISTENT_OFFSET)
/* Default config offset in flash memory */
#define FLASH_CONFIG_OFFSET (FLASH_PERSISTENT_OFFSET + ((FLASH_PERSISTENT_SIZE / 4) * 3))

/* MIDI expansion: its own partition, directly after Config's, added by the
 * linker script rather than derived a second independent way in C. Both
 * ADDR_CONFIG (linker) and FLASH_CONFIG_OFFSET (the macro above, computed
 * from PICO_FLASH_SIZE_BYTES at compile time) describe the same address by
 * construction; verify_midiconfig_offset() in config.c checks that at boot
 * so the two never quietly drift apart. */
extern uint32_t ADDR_CONFIG[];
extern uint32_t ADDR_MIDICONFIG[];
/* Set by verify_midiconfig_offset() at boot; midi_config_save()/load() must
 * refuse to touch flash while this is false. */
extern bool midiconfig_offset_ok;
#define FLASH_MIDICONFIG_OFFSET ((uint32_t)ADDR_MIDICONFIG - XIP_BASE)
/* One save = one whole sector (the blob does not fit in a 256B page like
 * Config's does), 16 sectors round-robin = 64KB, matches __MIDI_STORAGE_LEN
 * in the linker scripts. */
#define MIDICONFIG_SAVE_SLOTS 16
#define MIDICONFIG_SLOT_SIZE  FLASH_SECTOR_SIZE

/* Max config size = 256 Bytes == FLASH_PAGE_SIZE (FLASH_SECTOR_SIZE / 16 config saves) */
#define CONFIG_SIZE (FLASH_SECTOR_SIZE / 16)


/* USBSID-Pico config struct */
typedef struct SIDChip {
  uint8_t id;    /* ID for this SID 0 ~ 4, 255 = disabled */
  uint8_t addr;  /* Starting address to use for this SID, 255 = disabled */
  uint8_t type;  /* 0 = unknown, 1 = N/A, 2 = MOS8580, 3 = MOS6581, 4 = FMopl */
} SIDChip;

typedef struct Socket {
  uint8_t chiptype;     /* 0 = real, 1 = unknown, 2...etc see config_logging.c */
  SIDChip sid1;
  SIDChip sid2;
  bool    enabled : 1;  /* enable / disable this socket */
  bool    dualsid : 1;  /* enable / disable dual SID support for this socket (requires clone) */
} Socket;
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

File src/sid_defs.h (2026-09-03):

/*
 * USBSID-Pico is a RPi Pico/PicoW (RP2040) & Pico2/Pico2W (RP2350) based board
 * for interfacing one or two MOS SID chips and/or hardware SID emulators over
 * (WEB)USB with your computer, phone or ASID supporting player
 *
 * sid_defs.h
 * This file is part of USBSID-Pico (https://github.com/LouDnl/USBSID-Pico)
 * File author: LouD
 *
 * Copyright (c) 2024-2026 LouD
 *
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
 */

#ifndef _USBSID_SID_DEFS_H_
#define _USBSID_SID_DEFS_H_
#pragma once

#ifdef __cplusplus
  extern "C" {
#endif

/* Default includes */
#include <stdint.h>


/* Rasterrates (cycles) in microseconds
 * Source: https://www.c64-wiki.com/wiki/raster_time
 *
 * PAL: 1 horizontal raster line takes 63 cycles
 * or 504 pixels including side borders
 * whole screen consists of 312 horizontal lines
 * for a frame including upper and lower borders
 * 63 * 312 CPU cycles is 19656 for a complete
 * frame update @ 985248 Hertz
 * 985248 / 19656 = approx 50.12 Hz frame rate
 *
 * NTSC: 1 horizontal raster line takes 65 cycles
 * whole screen consists of 263 rasters per frame
 * 65 * 263 CPU cycles is 17096 for a complete
 * frame update @ 985248 Hertz
 * 1022727 / 17096 = approx 59.83 Hz frame rate
 *
 */

/* Clock cycles per second
 * Clock speed: 0.985 MHz (PAL) or 1.023 MHz (NTSC)
 *
 * For some reason both 1022727 and 1022730 are
 * mentioned as NTSC clock cycles per second
 * Going for the rates specified by Vice it should
 * be 1022730, except in the link about raster time
 * on c64 wiki it's 1022727.
 * I chose to implement both, let's see how this
 * works out
 *
 * https://sourceforge.net/p/vice-emu/code/HEAD/tree/trunk/vice/src/c64/c64.h
 */

/* Clock cycles per second */
typedef enum {
  CLOCK_DEFAULT  = 1000000,  /* @125MHz clock ~ 125000000 / 62,5f = 2000000 / 2 = 1000000 == 1.00MHz @ 125MHz and 1.06MHz @ 133MHz */
  CLOCK_PAL      = 985248,   /* @125MHz clock ~ 125000000 / 63,435804995f = 1970496,000009025 / 2 = 985248,000004513 */
  CLOCK_NTSC     = 1022727,  /* @125MHz clock ~ 125000000 / 61,111127407f = 2045454,000013782 / 2 = 1022727,000006891 */
  CLOCK_DREAN    = 1023440,  /* @125MHz clock ~ 125000000 / 61,068553115f = 2046879,999999489 / 2 = 1023439,999999745 */
  CLOCK_NTSC2    = 1022730,  /* @125MHz clock ~ 125000000 / 61,111127407f = 2045454,000013782 / 2 = 1022727,000006891 */
} clock_rates;

/* Clock speed translation */
enum config_clockrates
{
  DEFAULT = CLOCK_DEFAULT,  /* 0 */
  PAL     = CLOCK_PAL,      /* 1 */
  NTSC    = CLOCK_NTSC,     /* 2 */
  DREAN   = CLOCK_DREAN,    /* 3 */
  NTSC2   = CLOCK_NTSC2,    /* 4 */
};

/* Clock speed array */
static const enum config_clockrates clockrates[] = { DEFAULT, PAL, NTSC, DREAN, NTSC2 };

/* Hertz ~ refresh rates */
typedef enum {
  HZ_DEFAULT = 20000,  /* 50Hz ~ 20000 == 20us */
  HZ_50      = 19950,  /* 50Hz ~ 20000 == 20us / 50.125Hz ~ 19.950124688279us exact */
  HZ_60      = 16715,  /* 60Hz ~ 16667 == 16.67us / 59.826Hz ~ 16.715140574332 exact */
} hertz_values;

enum refresh_rates
{
  HZDFLT = HZ_DEFAULT,
  HZ50   = HZ_50,
  HZ60   = HZ_60,
};

static const enum refresh_rates refreshrates[]  = { HZDFLT, HZ50, HZ60, HZ60, HZ60 };

/* Rasterrates (cycles) in microseconds */
enum raster_rates
{
  R_DEFAULT = 20000,  /* 20us  ~ fallback */
  R_PAL     = 19656,  /* PAL:  63 cycles * 312 lines = 19656 cycles per frame update @  985248 Hz = 50.12 Hz frame rate */
  R_NTSC    = 17096,  /* NTSC: 65 cycles * 263 lines = 17096 cycles per frame update @ 1022727 Hz = 59.83 Hz Hz frame rate */
};

static const enum raster_rates rasterrates[]  = { R_DEFAULT, R_PAL, R_NTSC, R_NTSC, R_NTSC };
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

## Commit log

2024-09-19 Add HardSID USB / SidBlaster USB driver example
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2024-12-08 Update version for release - small fix in board detect for manual build
    [config.h]
2024-12-20 Rework config array & applying, update detect sidtypes,
    [config.h]
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2025-01-08 Fix SID type detection
    [sid.c]
2025-01-16 Fix DMA channels for Pico_w
    [gpio.c]
2025-01-16 Fix reset, add mute and unmute
    [gpio.c]
2025-01-17 Attempt at fixing nothingness
    [gpio.c]
2025-01-22 Buffer handling overhaul, remove fixed packet length in favour if variable length
    [gpio.c, tusb_config.h]
2025-01-24 Alas, another attempt at fixing unbroken things. Arrrr!
    [gpio.c]
2025-01-30 Add BUG to clear sid registers and add return statements
    [gpio.c]
2025-02-05 Small fixes and version update
    [config.h, gpio.c, sid.c]
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2025-02-09 Fixes and improvements in bus handling
    [gpio.c]
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2025-02-12 Add workaround for 0x40~0x5F address range mask not working
    [gpio.c]
2025-02-12 Add clockrate locking, numsids reading and rework stupid array calls
    [config.h]
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2025-02-14 Unpack case archives into their folder ~ I hear you schorsch3000
    [USBSID-Case-Top.stl, USBSID-Pico_Case.3mf, USBSID-Pico_Case_Bottom.stl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]
2025-02-23 Remove tinyusb repo checkout from release workflow, update py script to use pico platform
2025-02-26 Move everything LED related into new source file
2025-02-26 Migrate PWM LED to Pio & rename ws2812 stuff
2025-02-27 Rework Vu ~ remove LUT and simplify code, Vu update rate depends on internal raster rate, switch from ms to us delays, increase RGB Vu precision
    [config.h, gpio.c]
2025-03-09 Add queue to run SID tests from Core 1, add config command to interrupt running tests
2025-03-09 Add support for PCB v1.3 audio switch, update build types for PCB version
2025-03-09 Do you need some G**D*MN new glasses buddy?? 🥸
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2025-03-09 Get that fucking grease of your goddamn fingers
2025-03-09 Fix PCB info documents
2025-03-26 Fix PCB version builds
2025-03-26 Rework ASID handling for sidfactory2, thanks @thomasj - Add optional SID write logging, logs from core2 so is not blocking - Add vu check to (cycled_)bus_operation - Add ASID write order reset to led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
    [gpio.c]
2025-04-06 Add PCB version to USB product during compile time
2025-04-06 Attempt at ASID write order fix
    [gpio.c]
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2025-04-12 Fix CDC fifo at 64 bytes (max)
    [tusb_config.h]
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2025-04-12 Add v1.3 case by LouD (spotUP case revisited)
    [USBSID-Case-Top.stl, USBSID-Pico v1.3 bottom case notched.stl, USBSID-Pico v1.3 bottom case.stl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]
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2025-04-16 Update v1.3 cartridge case
    [USBSID-Pico v1.3 bottom case notched.stl]
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2025-04-18 Fix tabs not being spaces
    [mcu.c]
2025-04-28 Move Vu PIO write into DMA, remove debugging prints
2025-04-28 PIO and DMA rework, much notes of fuckshit that doesn't work.
    [gpio.c]
2025-04-28 Deprecate `bus_operation`, add cycled reading and cycled delay routine. Fix SID detection, add FMopl and clone type detection routine.
    [config.h, gpio.c, midi.c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]
2025-04-28 Add workaround so 1.3 PCB's do not try to detect external clock signal.
    [gpio.c]
2025-04-28 Add v1.0 notched bottom and open top case
    [USBSID-Pico v1.0 case bottom notched.stl, USBSID-Pico v1.0 case top open.stl]
2025-05-11 Fix socket read buffer size
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2025-05-11 Add undocumented `-command` for sending arbitrary commands to USBSID-Pico
2025-05-15 Update v1.3 case
    [USBSID-Pico v1.3 bottom case jumper openings.stl, USBSID-Pico v1.3 prusaslicer.3mf, USBSID-Pico v1.3 top case open with reset and rgb led opening.stl]
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2025-05-29 Add bottom case with UART opening
    [USBSID-Pico v1.3 bottom case jumper gpio openings.stl]
2025-05-30 Taking back my 🤬 sanity and starting over 🙄 f.u. ASID buffer 😘
2025-05-30 Set 2nd sid in same socket to N/A default
2025-05-30 What is this, day of the tentacle? Get a grip man, control your fingers!
2025-06-03 Add config slots for saving to preserve flash memory
2025-06-10 Split config.c into multiple files for general, bus, socket and logging
2025-06-10 Clean up sid.c in preparation of midi rework. Move sid detection and test routines into separate source files
    [sid.c]
2025-06-10 (rp2050 only!!) Add double tap reset button for autoconfig first iteration
2025-06-10 Fix build issues with midi.c (old version)
    [midi.c]
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2025-06-11 Add settings and commands to lock the audio switch from being changed
2025-06-28 - Add mirrored dualsid for dual clone - Lock audio switch to stereo in mirrored mode (v1.3 PCB only!) - Fix SID detection type - Only log config settings once at end of bootup - Move logging of confi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
    [config.h, gpio.c]
2025-07-01 Fix missing verification of sid addresses that prevented single socket two from working correct
2025-07-28 add Dual USBSID-Pico Commodore 64 Case by OlefinMakes
    [C64-Case-Bottom.3mf, C64-Case-Top.3mf, C64-KB.3mf]
2025-07-28 Per request
    [C64-Case-Bottom.3mf, C64-Case-Top.3mf, C64-KB.3mf]
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2025-10-24 Opensource v1.0 PCB
    [USBSID-Pico-v1.0.kicad_pcb, USBSID-Pico-v1.0.kicad_sch, bom.csv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]
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2025-10-24 Update v1.0 bom
    [bom.csv]
2025-10-24 Add v1.3 gerbers
    [bom.csv, designators.csv, positions.csv]
2025-10-31 Update v1.0 pcb with OSHWA certification
    [USBSID-Pico-v1.0.kicad_pcb, USBSID-Pico-v1.0.kicad_sch, designators.csv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]
2025-11-07 Disable non-functional midi until fixed
    [midi.c]
2025-11-12 Fix `sid_memory` not being cleared by `clear_sid_registers`
    [gpio.c]
2025-11-12 Let's burn these pico's yeah!? MAX SPEED ARR!
2025-11-13 Try fix sidplayer part 1 million
2025-11-29 Fix muting, now actually mutes all volume ($18) registers and masks all writes to these registers correctly
    [gpio.c]
2025-12-14 Add PDSID type switch command, config error check and fallback, clone sid config commands for future use, improve some docstrings, direct access to sid detection routines
    [config.h, gpio.c, sid_cloneconfig.c]
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2025-12-19 Add top case part with wider hole 🕳️
    [USBSID-Pico v1.3 top case open with reset wide hole.stl]
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2026-01-14 Rework branch prediction and remove endless loop as solution for #73
    [bus.c, dma.c, pio.c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]
2026-01-25 Fix potential flash/memory collisions
    [config_logging.c, sid_cloneconfig.c]
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2026-01-25 Fix SID register reset, thanks @WilfredC64 !
    [sid.c]
2026-01-25 Fix clockcycle delays for both platforms
    [dma.c, sid.c]
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2026-01-29 Add PRG file support to SID player and fix next/previous tune
    [config.h]
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2026-02-04 Fix `clockcycle_delay` for rp2040 by chaining two DMA channels together, move functions into bus.c
    [bus.c, dma.c]
2026-02-04 Update reset registers with simulated real world delay cycles
    [sid.c]
2026-02-04 Add config option for single SID in socket two
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2026-02-05 Fix possible overflow issue
    [bus.c]
2026-02-08 Fix regression in boot sequence where an rp2350 would freeze forever waiting for a semaphore to come available. Replace semaphore with arm native functions. Rearrange boot sequence and add more loggi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
2026-02-11 Fix hardfault/lockup on rp2350 when toggling the mono/stereo pin
    [gpio.c]
2026-02-11 Also reset the writeorder when midi/asid is no longer mounted
2026-02-11 Fix logging issue in cfg buffer printing
    [config_logging.c]
2026-02-11 Add config option to flip sockets at runtime 1 <--> 2
    [config.h]
2026-02-12 Fix lockups when using register `r10` without verification. Update docstrings
    [gpio.c]
2026-02-12 Reset SID registers after socket change command
2026-02-12 Reset SID registers after socket flipping
2026-02-12 Add socket flip command to config-tool
2026-02-19 😈 Protect against the big bad optimization demon!
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2026-02-21 Control the buggers! 👻
2026-02-21 Moar optimizebeast 😈 protection and some cleanup! :)
2026-02-21 Add PDSID detect and SID type config, rework auto detection
    [sid_cloneconfig.c]
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2026-02-21 Fix onboard sidplayer issues... dammit 🤌
2026-02-28 Stall Core1 untill completely finished booting. Add Firmware compilation log type.
2026-02-28 Fix storage size, move around some boxes
    [sid.c]
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2026-03-04 Spring cleaning! No more externs, let's internalise in our head(ers) 👾
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2026-03-04 Add optional play on on socket two for embedded player
2026-03-04 Update `send_sid` for optional play on on socket two
2026-03-08 Save copy of current webconfig tool in new directory
2026-03-08 Switch out vendor writes for vendor N writes as test
2026-04-28 Just encase it!
    [USBSID-Pico v1.3 top case open with reset narrow hole.stl]
2026-04-28 missing dtypes.. 🍆
2026-04-28 Add missing `CHIP_SIDEMU` thingy and prepare for socket change detection
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2026-06-13 Fix fat fingers
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2026-06-13 Fix voltage set order for v1.5 boards so clone sids don't phreak out!
    [gpio.c]
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2026-06-28 Enable Windows and MacOS ARM in gitlab CI on gitlab.com only
2026-07-02 Do the shuffle!
    [bom.csv, designators.csv, positions.csv]
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2026-07-02 Add Volume-daughterboard files
    [Volume-daughterboard.kicad_pcb, Volume-daughterboard.kicad_sch]
2026-07-08 Volume daughterboard
    [Volume-daughterboard.csv, Volume-daughterboard.kicad_pcb_positions.csv, Volume-daughterboard.kicad_sch]
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2026-07-10 Update v1.3 gerbers
    [designators.csv]
2026-07-10 Add v1.3 kicad files
    [USBSID-Pico-v1.3.kicad_sch, USBSID-Pico-v1.3f.kicad_pcb, power-pins.kicad_sch]
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2026-07-25 Fix disable autodetect feature so the configtool gui actually works :)
    [config.h]
2026-07-25 fix fpgasid configf address display error
    [sid_cloneconfig.c]
2026-07-27 Set current preset based on current config (v1.5+)
2026-08-01 Fix voltage apply when saving config without reboot
2026-08-04 Fix v1.5 regression in SID play after socket change detection
    [bus.c, dma.c, gpio.c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]
2026-08-10 Add Cartridge Case by spotUp, LouD v1.5 remix
    [USBSID-Pico v1.5 case bottom.stl, USBSID-Pico v1.5 case top.stl, USBSID-Pico v1.5 case.3mf]
2026-08-11 Fix claim/detach/release/unclaim kernel driver issues
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2026-08-11 Fix FMOpl and add support for new config items
    [config.h]
2026-08-11 Fix Vu on Embedded play without USB
    [bus.c, sid.c]
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2026-08-18 Fix board -> host via webusb writes to 64 bytes
2026-08-19 Fix last_preset config setting for all PCB versions
2026-08-22 Midi implementation overhaul (part 1 of unknown) - add sid bus spinlock - add dedicated flash for midi config - add midi clock control - add midi engine - add midi handler - add midi queue - add midi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
    [bus.c, config.h, midi.c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]
2026-09-02 Fix stale DMA functions
    [bus.c, dma.c]
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2026-09-03 Update the PrusaSlicer project
    [USBSID-Pico v1.5 case.3mf]
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2026-09-11 Rework net config + add net config struct as buffer reading
    [config.h]
2026-09-11 Fix shadowing issue with rpi sdk `bluetooth.h`
    [pio.c]
2026-09-13 Add missing drivers section to all docs that require it
2026-10-03 Migrate CLI tools to official driver + add multiboard support
2026-10-03 Fix write_debug queue size per pico type
2026-10-03 Add Multiboard experimental clock link with other boards as optional configuration. This is _not_ required for using the new multiboard driver. When enabled on all the boards you use, they will use t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
2026-10-04 ASID: fix write order lookup and unused slot handling
    - Look up the write order (0x30 or default) by ASID register ID
    (mask * 7 + bit) instead of the count of registers in the message.
    Partial messages got the position and wait of another register,
    e.g. volume alone got those of voice 1 freq lo. Matches TeensyROM.
    - Mark write order slots with a used flag instead of wait 0xff. The
    static slots started zeroed, the first message per chip after boot
    wrote $00 to register 0 for every slot it did not fill. A configured
    wait of 255 cycles also read as unused and dropped that register.
    - Validate the write order packet before applying it: a position of
    28 or higher wrote past the end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
2026-10-04 Fix WebUSB reads on FastReads firmware
    - usbsid-driver.js: claim the first vendor interface, skip zero length
    packets on every read, drop selectAlternateInterface() on open
    - usplayer/: update the player from USBSID-Player (reSIDfp speed and
    memory view, WebUSB transport fixes)
2026-10-21 CLI configtool 👻 - move all var declarations into headers - split humongous help menu into parts - add extra help arguments - small skpico config read print change - add wifi/bluetooth/nsd configurat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
2026-10-21 Shoo! Into your own space you go 🌬️
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2026-10-31 Add command to get the state of the audio switch (v1.3+ only)
2026-11-06 Add build flag gated CDC-NCM firmware feature for testing NSD over USB on non WiFi capable Pico boards
2026-11-07 Add config panels over Web Serial to the web config tool - Config and debug panels work over Web Serial, also in browsers without WebUSB - Config, SendSID and the Web Serial player share one port - S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
2026-11-07 Fix case fallthrough in embedded player config commands and remove misplaced boolean
2026-11-07 Fix PSIDdrv value, play button state and refetch in the web player - Update tune info and badges from the load callback, not a fixed timer, PSIDdrv no longer shows the previous tune - Update the play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
2026-11-08 Add USB RX ringbuffer for incoming USB CDC and Vendor (WebUSB) packets - Incoming CDC and WebUSB packets go into an 8 slot ringbuffer and play from the main loop, TinyUSB keeps receiving between SID 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
2026-11-08 Add USB RX ringbuffer setting to cfg_usbsid - New option -rxring N / --rx-ring N, also usable in a -w write chain (SET_CONFIG item 17) - Config overview prints the setting in the feature list, same a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
2026-11-08 Add USB RX ringbuffer setting to the web config - On/off select in a new USB box, reads READ_CONFIG byte 59 - Change sends SET_RX_RING, the board saves and reboots, the page reconnects - Disabled wit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
2026-11-08 Fix cfg_usbsid preset detect and clock list, add clock link option - -pad sends PRESET_DETECT (0xFE) instead of SOCKET_DETECT (0xFD), value in both argument bytes - Clock rate help and ini export lis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
2026-11-08 Add preset auto detect and two preset buttons to the web config - Preset Auto Detect select, sends PRESET_DETECT (0xFE), saved without reboot - SINGLE (S2) preset button, SINGLE_SID with argument 1 (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
2026-11-08 Document clock link, preset detect, clock rates and FMOpl SID number - New firmware manual section Clock link, plus its default in the defaults list - FMOpl SID number: set automatically, can also be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
2026-11-10 Update the web player build - RSID driver placement and post-init interrupt fix (2_Canal_Diggi, Amiga_Works_II)
2026-11-11 Fix IRQ badges of the web player blinking on tunes that toggle timers
2026-11-12 Fix buttons in mobile view

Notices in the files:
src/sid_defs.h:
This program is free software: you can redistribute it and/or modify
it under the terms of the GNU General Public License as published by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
